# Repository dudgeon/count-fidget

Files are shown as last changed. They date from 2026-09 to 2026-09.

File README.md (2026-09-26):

# Count Fidget

A lightweight, rechargeable two-key fidget that counts clicks, resets with a second key, and remembers its count while asleep or unpowered. Designed for a home-printed enclosure and professionally assembled electronics.

**Q5 is the active engineering candidate:** the Q4 STM32L072CBT6 / USB-C home programming / SPI OLED / SPI FRAM design, plus:
- a soft power key (COUNT turns it on; it switches itself off after 30 s, drawing ~8 µA);
- a vendor-soldered LIR2032 coin-cell holder in place of a custom battery pack;
- a battery gauge with LO warning and storage cut-off, and charge status;
- a reset pinhole;
- hold-to-reset key logic;
- a smaller 47.2 × 59.2 × 16.8 mm printed enclosure with printed keycaps;
- solder-free keys (clicky switches pressed into vendor-placed hot-swap sockets).

JLC performs all SMT from standard inventory parts. Two JLCPCB variants are prepared:
- **A:** the user solders the display header (14 joints);
- **B:** JLC also fits the display.

Q1–Q4 remain historical, unchanged packages.

**The design is locked. JLCPCB quoting only is authorized** (see [JLC-QUOTE-Q5](procurement/q5/JLC-QUOTE-Q5.md)): no order, payment or manufacture. The design files, firmware, emulation and CAD checks pass. Nothing has been built or measured. The first units follow the [first-article test plan](docs/q5-first-article-test-plan.md).

Start with [the Q5 engineering review](docs/REVIEW-Q5-2026-09-25.md), [PROJECT.md](PROJECT.md) for status, and [HANDOFF.md](HANDOFF.md) for continuation.

| Area | Current Q5 files |
|---|---|
| PCB | [KiCad project](electronics/q5/click-counter-Q5.kicad_pro), [board](electronics/q5/click-counter-Q5.kicad_pcb), [schematic PDF](electronics/q5/schematic-Q5.pdf), [power design](docs/q5-power-design.md) |
| Firmware and programming | [Q5 source/build](firmware/q5-stm32/README.md), [keys, power and USB procedure](docs/q5-firmware.md), [macOS flashing tool](tools/clicker-flash/README.md) (Claude skill `flash-clickers`) |
| Inventory, assembly and quote | [Stock evidence](procurement/q5/stock.json), [exports](procurement/q5/REVIEW-EXPORTS-Q5.md), [JLCPCB quote and estimate](procurement/q5/JLC-QUOTE-Q5.md) |
| Enclosure | [Assembly and parts](mechanical/q5/README.md), [rendering](mechanical/q5/assembled-Q5.png), [STEP assembly](mechanical/q5/enclosure-Q5.step) |
| Verification | [Build workflow](docs/build-and-verify.md), Q5 reports in `verification/`, [firmware emulation](simulation/q5-firmware-emulation/README.md), [bounded power checks](simulation/q5-power/result.json) |
| Product history | [Specification](docs/product-spec.md), [user context](docs/user-research.md), [decisions](docs/decisions.md), [Q4 review](docs/REVIEW-Q4-2026-09-24.md), [Q4 simulation review](docs/REVIEW-Q4-simulation-2026-09-25.md) |
| Vendor history | [Vendor status](procurement/vendor-status.md); retained RFQ packages in `dist/` do not authorize new submissions |

Quick checks, with Python 3 and a C compiler:

```sh
python3 scripts/verify_project.py
python3 scripts/run_host_tests.py
```

These verify files, package consistency and portable firmware logic, not physical electronics. Toolchains, credentials, private mailbox content and customer account sessions are not stored in this public repository.

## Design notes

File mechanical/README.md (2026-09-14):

# Rev0 fit study — not final Q1 print files

**These STEP/STLs do not match Q1.** Preserve them as editable CAD and form-factor work, not a finished electronics assembly. Purchased parts in renders are simplified envelopes; pins/wiring/small parts are missing.

`enclosure.py` generates the STEP, base/lid STLs, CAD renders and geometry report using CadQuery. Recorded checks show one solid per shell part, zero base/lid intersection and solid-PLA masses 7.221 g + 2.680 g. They do not establish component clearance.

## Q1 revision requirements

- Use actual 42 × 40 × 1.0 mm board with 2 mm outline corner radii. Two rear M2 holes are **(2.5, 37.5), (39.5, 37.5) mm**; old model assumes four corner holes/supports.
- J1 opens right at **y=13.3 mm**. Use exact GCT drawing, stakes and real USB cable clearance.
- Switch stem centers: **(11.475, 28.000), (30.525, 28.000) mm**. Footprint placement origin is contact pin 1, not stem. Check clips, travel, plate height and click-load support.
- LCD center: **(21, 8.75) mm**; glass rear 4 mm above PCB top. Model actual glass/pins/standoff, compliant support, MCU/connectors beneath and viewing angle.
- Include bottom components, solder, ≤1 mm LCD lead tails, battery tab/NTC exit, 40 ±5 mm flexible leads, pack diameter ≤21 mm excluding lead exit and ≤0.8 mm added face thickness.
- Keep cell behind screws with strain relief and clearance from conductors. Final screws/retention/drop behavior need validation.

All quoted coordinates are board top view, top-left origin, Y down. Use Q1 files for truth. Render final visuals from corrected CAD after reviewing geometry.

Old body: 46 × 44 mm, 1.2 mm wall/floor, 18 mm with bezel, 28.8 mm keycap height. Old base prints flat; lid puts bezel on bed and needs support under surrounding face. Notes considered two 0.6 mm extrusion lines and transparent PETG, subject to slicer/fit/thermal checks.

CAD dependencies: CadQuery, NumPy, Pillow. Historical renderer uses Linux DejaVu font paths; select available local fonts on macOS. Run changes in a branch; all geometry is mm. Final print files remain owed.

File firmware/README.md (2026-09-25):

# Firmware: frozen Q1 and Q2 LCD verification candidate

`main_msp430.c` now contains the **unreleased Q2 LCD verification candidate** for MSP430FR4133IG48R, 48-pin package. The existing Q1 ELF/HEX/map, `SHA256.json`, factory HEX and submitted RFQ ZIP remain unchanged. The ZIP retains its matching Q1 source. All boards remain on hardware hold: Q1 lacks three required LCD bias reservoir capacitors.

The allegation that Q1 source omitted segment enable is **refuted**. TI support 1.212 defines `LCD4MUX` to include `LCDSON`. Rebuilding the original source with TI GCC 9.3.1.11 produces the exact archived Q1 application HEX; no loaded-byte source/binary drift was found. Complete ELF metadata differs across builds. See `../docs/review-lcd-firmware-Q2.md` for evidence and the inferred build recipe.

Q2 changes the divider from 4 to 8 for **32 Hz nominal**, giving margin for REFO tolerance. Explicit `LCDSON` is added for readability and makes no additional binary change. Outputs and source/header/toolchain provenance are separate in `q2-lcd-check/`; build them with `../scripts/build_firmware.py` as described in `../docs/build-and-verify.md`. This image has not been flashed or qualified and is not authorized for manufacture.

Behavior: 8 ms stable-state debounce; one count per press; single-press reset with priority; eight digits with saturation at 99,999,999; first wake click counts; display blanks after 30 seconds; LPM4 wake on either edge; 16-bit aligned, CRC-protected dual-record journal at information FRAM 0x1800–0x181F. An interrupted newest commit can lose that newest click; the previous committed record remains the recovery target. Display updates follow successful commits.

LCD commons use L0–3; segment lines use L8–19 and L24–27. Mode 2 uses the 3.0 V rail, 1/3 bias and 1/4 mux: Q1 is nominally 64 Hz, Q2 is 32 Hz. The pump capacitor and three R13/R23/R33 reservoir capacitors are required; firmware cannot replace missing hardware. All common and segment pins are held at the same GPIO low level during sleep. REFO clocks the debounce timer and LCD; no crystal is fitted. The watchdog is disabled and additional firmware robustness review remains a production gate.

factory-display-info.hex is a factory-only information-FRAM record that starts at 88,888,888 for display inspection. Load it once during factory test, then reset to zero and execute the RFQ tests. Do not use it for field firmware updates: application-only HEX intentionally preserves the saved count.

No target hardware validation has occurred. Host tests validate counter behavior and interruption boundaries between complete journal words, not analog brownout behavior, MCU pin multiplexing or LCD contrast. Programming and test procedure: procurement/RFQ-Q1.md. USB is charging only; use MSP-FET Spy-Bi-Wire and the ten labeled pogo lands.

Compiler: https://www.ti.com/tool/download/MSP430-GCC-OPENSOURCE

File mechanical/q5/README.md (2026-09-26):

# Q5 enclosure and home completion

The Q5 body is **47.2 × 59.2 mm with a 16.8 mm display-cover height** and a 26.7 mm keycap envelope height. Q4 was 50 × 60 × 19.6 mm with a 30.4 mm keycap envelope. It fits the unchanged 42 × 54 mm board outline, now 1.6 mm thick for the hot-swap sockets. The STEP assembly and PNGs use the native Q5 board positions and simplified component envelopes. They are not exact vendor assembly CAD.

Changes from Q4 and why:

| Change | Reason |
|---|---|
| **USB opening 13.4 × 7.2 mm**, centred on the receptacle axis and cut through to the receptacle face | Issue #4. The Q4 opening was 4.8 mm tall and 3.4 mm in front of the receptacle, so standard overmolded plugs could not seat. The fit check reserves a USB-IF maximum 12.35 × 6.5 mm overmold plus 0.1 mm per side, from the outer wall to the receptacle face. |
| **No pack bay, keeper or harness corridor** | Issue #13. The LIR2032 cell sits in the vendor-soldered BT1 holder under the PCB, and the NTC is on the board. The Q4 battery keeper and its two M2 × 5 screws are gone. |
| **PCB 3.4 mm lower, side clearance 1.0 mm** | The holder (5.52 mm) plus 0.58 mm floor gap sets the stack height. This saves 2.8 mm in width, 0.8 mm in depth and 3.4 mm in height. |
| **Printed MX keycaps** with a cross socket and engraved legends (+ on COUNT, ○ on RESET) | Issue #13. Keycaps are no longer an unsourced item. |
| **Solder-free keys:** vendor-placed CPG151101S11-16 hot-swap sockets (SW1 rotated 90°, SW2 270°, pads outward) | The clicky CPG151101D13 switches clip into the rear key plate and press into the sockets, so no key soldering is needed and variant B needs no home soldering at all. Keycaps are datumed on the switch stem (15.0 mm above the PCB, 3.5 mm socket, 4.4 mm travel checked). |
| **Pinhole tube** and a debossed "LIR2032 ONLY" warning in the base | Guides a paper clip to SW3 and warns against primary cells. |
| **Bottom reset pinhole** (2.4 mm) under SW3 | Provides the hardware reset (NRST) the user asked for. On battery it is a full power cycle; with USB it is the DFU entry reset. |
| **Two load supports** under the key area (board 5.5, 42.8 and 34.0, 44.0) | Carry key-press force past the holder into the floor. |

## Parts and hardware

| Item | Qty | Specification / status |
|---|---:|---|
| Base, front display cover, rear key plate, COUNT keycap, RESET keycap | 1 each | Five STL files, already in print orientation |
| Board/cover screws | 4 | M2 × 6 cross pan-head self-tapping (LCSC C357360). They pass through the lid-boss floor and PCB into 1.7 mm base pilots, 4.2 mm deep, with 3.4 mm thread engagement |
| Rear display supports | 2 | Compliant 2.5 mm annuli, as in Q4 |
| OLED module and header | 1 + 1 | HS96L01W4S03 + PZ254V-11-07P. Variant A: the user solders them (14 joints). Variant B: JLC fits them |
| Key switches | 2 | CPG151101D13 clicky (LCSC C49234235), pressed into the hot-swap sockets; no soldering |
| Cell | 1 | **User-supplied LIR2032 (rechargeable Li-ion, 4.2 V) only.** Never fit a CR2032 or ML2032 primary cell: the charger would try to charge it. |

## Assembly sequence

1. Print and inspect the five parts. Check the keycap cross sockets on one switch before fitting.
2. Print `tolerance-coupon-Q5.stl` first (`scripts/build_q5_coupon.py`: plate holes 13.95/14.05/14.15 mm, cross sockets −0.05/0/+0.05 mm; first-article test G0). Clip both switches into the **rear key plate**.
3. Variant A only: with the front cover off, solder the seven-pin header between the host PCB and the module (14 joints) and trim the pins to ≤ 1 mm. Variant B arrives with DS1 fitted.
4. Fit the two display supports.
5. **Insert the cell with USB connected** (BQ2970 first-connection behaviour and the retained cold-insertion counterexample; see [the Q5 power design](../../docs/q5-power-design.md)). Observe + up in the holder. The board powers up from USB, shows the count and the CHG label.
6. Lower the PCB assembly vertically into the base. Press the key plate, with its switches, straight down into SW1/SW2 until the housings sit flush, then fit the two rear screws. Program/verify firmware now if needed (see [Q5 firmware](../../docs/q5-firmware.md)).
7. Lower the front cover and fit its two screws. Press on the keycaps. Check travel, the USB plug (both orientations) and the reset pinhole.

To replace the cell, remove the four screws and lift the PCB assembly out. The holder is on the underside.

## What the geometry checks establish

`fit-report.json` and `build-manifest.json` bind the native Q5 board and model, the generator and the firmware pixel renderer. The final build found:
- five valid single solids with manifold STL meshes;
- zero static intersections;
- zero collisions in 162 sampled vertical assembly/removal poses (18,387 tests).

The minimum modelled distances are in the report:
- holder to bottom components: 0.05 mm, a bounding-box gap and not an overlap;
- pressed keycap to plate top: 0.6 mm; pressed keycap roof to switch housing: 0.65 mm;
- pressed keycap to rear screw: 3.0 mm;
- screw thread engagement: 3.4 mm;
- USB mouth to outer wall: 2.0 mm.

Not established: print tolerances, thread strength, cell retention and insertion force, keycap fit/travel, real USB plug fit, drops, or display support material. Inspect a physical first article.

Build: `python3 -B scripts/build_q5_enclosure.py --kicad-python "$(which python3)"` (CadQuery 2.8, NumPy, Pillow, KiCad Python bindings).

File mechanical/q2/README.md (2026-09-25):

# Q2 enclosure fit candidate

These are real, editable/exported Q2 CAD files for a **50 × 45 × 19.8 mm** enclosure around the current 42 × 40 × 1 mm PCB. Estimated overall height with the provisional keycaps is 29.8 mm. They replace the obsolete fit assumptions for this candidate only; all files in the parent `mechanical/` directory remain historical Rev0 evidence.

**Engineering fit candidate, not released print files.** The shell/keeper are generated solids. Purchased components, pins, screws and keycaps are simplified envelopes. No printed sample, finished battery pack, actual keycap or cable has been fitted. The current electronics retain their documented qualification gates.

## Files

| File | Contents |
|---|---|
| `enclosure-Q2.step` | Assembled base, lid, keeper and named component envelopes, in assembly coordinates |
| `base-Q2.stl` | Printable base, upright with floor at Z=0 |
| `lid-Q2.stl` | Lid inverted, bezel face at Z=0; supports needed under the surrounding face |
| `battery-keeper-Q2.stl` | Separate screw-retained keeper, flat at Z=0 |
| `assembled-Q2.png`, `exploded-Q2.png` | Rendered CAD views |
| `interior-Q2.png`, `battery-bay-Q2.png` | Internal layout and battery access views |
| `board-geometry.json` | Native KiCad footprint bounding boxes, pads/drills and board/model hashes used for this build |
| `fit-report.json` | Solid validity, intersection checks, model distances and explicit limitations |
| `build-manifest.json` | Generator, board/model and generated-output SHA-256 identities |

No enclosure printing charge is included in the vendor electronics quote: Geoff prints and fits the case. The STEP/STLs support quotation review and the later physical fit prototype; they do not authorize manufacture of the electronics.

## Geometry and design choices

Coordinates in the source are millimetres, with `CAD X = board X −21`, `CAD Y = board Y −20`; Y follows the board's top-view convention. Z starts at the base bottom. The script reads the native Q2 board without modifying it, compares all placed parts with `electronics/q2/netlist-Q2.json`, and rejects changed dimensions or component anchors.

| Feature | Candidate geometry |
|---|---|
| PCB | Bottom Z=10.5; top Z=11.5; nominal 2 mm outline corner radius |
| Base | 1.6 mm floor/walls; nominal board-side clearance 2.4 mm along X and 0.9 mm along Y |
| Mounts | Existing board holes at (2.5,37.5), (39.5,37.5); two base bosses and corresponding lid spacers/screws |
| Switches | Stem centers (11.475,28), (30.525,28); 16.4 mm square lid clearances; PCB-load support posts at (6,30.5), (36,30.5) |
| LCD | Center (21,8.75); rear glass 4.0 mm above PCB top; nominal 34.9 ×13 ×2.2 mm; 13.0 mm lead rows |
| LCD pocket | 36.2 ×14.8 mm; roof above pocket at Z=18.8; viewing aperture 32.7 ×7.2 mm; raised bezel top Z=19.8 |
| USB | Right-side opening centered at board Y=13.3, 13.2 mm wide ×5.0 mm high, bottom Z=11.1 |
| Pack | Finished insulated cylindrical body up to Ø21 ×4.2 mm; bottom Z=1.9 on a 0.3 mm seating layer; tray bore Ø21.8 mm |
| Keeper | Plate underside Z=6.4, 0.3 mm nominal above maximum pack; independent screws retain it before the PCB is fitted |
| Harness | 2.0 mm-wide side corridor around the left PCB edge, plus under-board and flexible tab/NTC exit reservations |

The width and PCB height increases provide a route around the intact PCB edge for the four-wire harness and room for the keeper below the switch tails. They are explicit enclosure choices, not changes to the electrical layout. The specified 40 ±5 mm, 30 AWG pack leads still require a finished-pack drawing and a trial route; the reservation boxes are not a qualified cable model. The mating JST plug and its insertion/bend sweep remain to be confirmed.

The LCD's manufacturer drawing includes a **2.85 mm maximum thickness** and ±0.2 mm body-length/general tolerances. The clearance check therefore uses 35.1 ×13.2 ×2.85 mm, not just the 2.2 mm nominal render. At the specified 4 mm standoff this leaves 0.45 mm nominal below the pocket roof. The enlarged pocket also allows space around the bent lead rows. It does not resolve hole/lead tolerances, solder exposure or LCD qualification. [Display Elektronik DE188 Rev4 drawing](https://display-elektronik.de/filter/DE188-RU-30_75_3V.pdf).

Two **nonconductive compliant pads**, nominal 4 mm assembled thickness, support the glass rear near board coordinates (5.5,8.5) and (36.5,5). Their material, final compressed thickness, adhesive and contact pressure require approval with the actual LCD. They are separate envelope parts in STEP; do not replace them with an unqualified hard clamp. The lid intentionally clears the glass.

The USB body envelope uses 7.35 ×8.94 ×3.31 mm and the native right-facing anchor. A 12 ×4.6 mm cable-entry reservation passes through the wall opening. This is an explicit candidate plug limit, not a claim that every USB-C cable overmold fits the recessed receptacle. [GCT USB4105 dimensions](https://gct.co/connector/usb4105).

The switch envelope distinguishes a 14 mm lower region through the first 5 mm above the board from the 15.6 mm upper envelope. Keycap bodies are provisional 18.2 mm square envelopes with a checked 4 mm downward travel. Actual clips, stem fit, keycap skirt, bottom-out height and board loading still need a sample. The lid clearance is not a qualified MX mounting plate. [Cherry MX series drawing](https://media.digikey.com/PDF/Data%20Sheets/Cherry%20PDFs/MX%20Series.pdf).

## Retention and assembly sequence

The following is a prototype assembly procedure for unpowered parts. It does not approve installing or charging an unqualified cell.

1. Print and deburr all three parts. Inspect the pilot/clearance holes and remove support material completely. Check the base/lid fit with an empty board before installing the battery assembly.
2. Fit the insulated approved pack on its 0.3 mm seating layer. Orient the flexible tab/NTC exit toward the left-front tray notch. Fit the keeper with **two M2 ×5 screws**. It limits upward travel while leaving 0.3 mm nominal pack clearance; do not tighten a changed geometry onto the cell or its sensor.
3. Route the insulated leads through the left-side corridor, protecting them from PCB edges and keeper screws. Complete connector engagement and strain relief using the approved pack drawing. The current reservation requires a routed bundle no thicker than 2.0 mm at the side passage.
4. Seat the PCB on its two mounting bosses and two load-support posts, without trapping wiring or touching solder tails. Programming and electrical tests occur before final enclosure closure; the keeper can obstruct access to underside fixture lands.
5. Confirm the installed LCD standoff and compliant supports. With keycaps removed, engage the two front lid hooks, lower the lid and fit **two M2 ×12 rear screws** through the real board holes into the base bosses. Fit the keycaps afterward and check their full travel.

Fastener models assume **head diameter ≤4.0 mm and head height ≤1.7 mm**. Rear screw heads seat at Z=16.5; nominal tips end at Z=4.5. Keeper screw heads seat at Z=7.6; nominal tips end at Z=2.6. These limits avoid the model's cell and base floor. Obtain actual screws meeting this envelope; a longer screw is not automatically acceptable.

Base pilot holes are provisionally Ø1.7 mm and lid/keeper clearance holes Ø2.4 mm. Qualify thread formation, material strength and torque on a spare printed boss before assembly; the pilot dimension is not a validated universal thread specification. The rear lid spacers are Ø3.6/2.4 mm and need careful print inspection. Front hooks provide nominal 0.3 mm engagement clearance. Screw and hook durability, pack capture and board bending remain physical tests.

## What was checked

`fit-report.json` records checks on the actual generated solids:

- Each printed part is one valid solid; base, lid and keeper have zero mutual overlap.
- Printed parts do not intersect the checked PCB/component envelopes or the specified wire/USB reservation volumes.
- The pack/keeper and fastener envelopes do not intersect the modeled bottom components or switch/LCD tails.
- Quantified nominal distances include pack-to-board, pack-to-switch-tails, keeper screws to bottom components, and maximum LCD glass to MCU/USB/JST.

Bottom-component X/Y envelopes come from native KiCad footprint bounding boxes, including courtyard/pad graphics. Height allowances are 1.1 mm for resistors/0603 parts and 1.6 mm for other bottom parts, including mounting/solder allowance; they are conservative family assumptions, not independently approved maximum drawings for every line item. Pin/post solids primarily preserve position and protrusion assumptions, and do not qualify the actual molded-post/hole diameters. The entire solder fillet and flexible-harness geometry is not modeled.

The intersection list is intentionally narrow and reproducible. It does not represent complete component-to-component mechanical DRC, toleranced motion simulation, strength analysis, electrical insulation approval or a physical fit test. In particular, nominal zero overlap does not establish tolerance clearance.

## Printing and remaining gates

For a first fit prototype, use a dimensionally calibrated printer and inspect walls/bosses before use. The base prints upright; the keeper prints flat; the lid's exported STL rests on its bezel face and needs support under the surrounding lid face, with the underside spacers/hooks facing upward. The nominal wall is 1.6 mm. Material, layer settings, shrink compensation and thread method remain to be qualified; these files do not prescribe an untested heat-resistant or child-ready assembly.

Before final print release, measure: finished pack and wire bends; USB plug reach and strain; real switch/keycap travel; mounting and click-load deflection; LCD glass/lead/support fit; all screw clearances/engagement; and retention after handling/drop tests. Keep the existing battery, charger, thermal, protection, programming and display electrical release gates. No purchasing or electronics manufacturing release follows from these CAD outputs.

## Rebuild and provenance

Run from the repository with a Python environment containing CadQuery 2.8.0, NumPy and Pillow. Pass the installed KiCad Python interpreter explicitly:

```sh
python scripts/build_q2_enclosure.py --kicad-python /path/to/KiCad/Python.framework/Versions/3.9/bin/python3
```

The local build used the temporary `/private/tmp/count-fidget-cadquery` environment and the mounted KiCad 10.0.6 runtime. No global Python environment, Rev0 file or electronics source is modified. Input changes during generation cause failure; rebuild after the final native board/model are stable. The manifest identifies geometry inputs and outputs; STEP headers may contain export timestamps, so byte-identical STEP reproduction is not claimed across runs or runtime versions.

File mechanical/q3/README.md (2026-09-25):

# Q3 enclosure engineering candidate

Four print parts: base-Q3.stl, lid-front-Q3.stl, lid-rear-Q3.stl and battery-keeper-Q3.stl. The STEP assembly and renderings are assembled views; the STLs use proposed print orientations. No enclosure has been printed or physically qualified.

## Customer assembly sequence

1. Inspect the completed vendor PCBA, with OLED and both switches already soldered. Leave the battery disconnected and the keycaps off.
2. Slide the front cover toward the lower switch bodies from the display end, then slide the rear cover from the opposite end. Engage the three cover-joint tongues; do not push a cover over the upper switch housings. Printed tolerances and clip engagement need a sample check.
3. Install the insulated, finished battery pack in the base and fit its keeper with two proposed M2×5 screws. Do not trap or puncture the pack or leads. The harness path and actual screw heads require a fit check.
4. Mate the keyed battery connector and lower the PCBA/cover assembly onto the base supports. Engage the front retention features, route the harness in its reserved corridor and fit the two proposed M2×12 rear screws. Do not tighten against the OLED glass or crush the board/pack.
5. Install the loose keycaps. Verify both keys return freely through full travel and the USB cable fits without loading the display or switches.

## Dimensions and evidence

Body50×45mm; switch plate top17.1mm; provisional keycap envelope30.4mm. PCB42×40×1mm, bottomZ11.1mm. Plate1.5mm thick with14.05mm openings and top5mm above the PCB. OLED roof15.6mm and proposed support0.2mm.

The build manifest binds the native board/model, generator and exact current STEP/STL/render outputs. The fit report requires four valid single solids, manifold STLs and zero reported modeled intersections. Independent review found and corrected initial shell collisions, the one-piece cover assembly trap and inadequate battery-keeper screw clearance. The reviewed split-cover approach was sampled at0.25mm increments without collisions; this is not a real assembly or tolerance test.

Simplified body/screw/keycap envelopes are not vendor 3D models. OLED FPC solder-face height/bend/support, clip/lap strength, print tolerances, actual keycaps, harness/JST insertion, fasteners, USB overmold/strain, battery retention, drop behavior and mass remain open. Preserve all engineering gates in the RFQ. Customer enclosure assembly requires no soldering.

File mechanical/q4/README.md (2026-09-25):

# Q4 enclosure and home completion

The enclosure is a **50 × 60 mm** body with a **19.6 mm display-cover height** and a provisional **30.4 mm keycap envelope height**. It fits the separate 42 × 54 × 1 mm Q4 PCB. The STEP assembly and PNGs use the actual board positions and simplified component envelopes; they are not exact vendor assembly CAD.

## Parts and hardware

| Item | Quantity | Specification / status |
|---|---:|---|
| Printed base, front display cover, rear key plate, battery keeper | 1 each | Four supplied STL files; print orientation is already applied |
| Board/cover screws | 4 | M2 × 12, nominal 4 mm head diameter / 1.7 mm height envelope |
| Battery-keeper screws | 2 | M2 × 5, same head envelope |
| Rear display supports | 2 | Compliant 2.5 mm-high annuli, 3.8 mm outside / 2.5 mm inside diameter; sample-fit material and component-free contact lands before use |
| OLED module | 1 | HS96L01W4S03 / C5139758, separately sourced loose |
| Header | 1 | PZ254V-11-07P / C492406; 2.5 mm body separates host and module PCBs |
| Key switches | 2 | CPG151101D13 / C49234235, separately sourced loose |
| Keycaps | 2 | Provisional MX-compatible 18.2 mm square envelopes; exact sourcing and travel fit unqualified |
| Prepared cell and NTC harness | 1 | Unqualified four-wire pack, maximum modeled 21 mm diameter × 4.2 mm height; see power/pack release gates |

The printed screw pilots are 1.7 mm. Thread formation, fastener head fit and repeated service strength must be established on a print sample; the model does not establish a reliable printed thread. Supports, screws and the prepared pack are separate from the PCB assembly BOM. Do not infer that JLC includes them or that public stock has been allocated.

## Assembly sequence

1. Print and inspect the four parts. Fit the keeper and screws around an inert pack-sized gauge first. Confirm screw engagement without protruding into the cell space. Qualify the actual pack and sensor before connecting it.
2. Seat both key switches in the **rear key plate before soldering** their four electrical leads to the host PCB. The plate is intentionally captured by the fitted switches. Check full switch travel and plate clips on the print sample.
3. With the front cover removed, solder the seven-pin header between the host PCB and display module. This is fourteen solder joints. Keep the 2.5 mm header body between the PCBs; trim exposed pin ends to **at most 1 mm** on both sides. Check all joints and orientation before power.
4. Fit the two compliant supports under the module's rear mounting lands after confirming those lands are free of components. Do not press on the glass or force the module into a warped position. The manufacturer's drawing, not its contradictory summary dimensions, controls the CAD.
5. Lower the PCB/key-plate assembly vertically into the base, route the qualified harness through the reserved side corridor, and secure the rear mounts. Leave the front cover off for inspection and USB programming. Use the **USB-first commissioning sequence** in the power document; cold battery insertion is not a validated workflow.
6. Lower the front display cover vertically and fit its two screws. Fit the keycaps and check full travel, USB cable access, the bottom reset pinhole and display visibility.

Home soldering totals **18 joints per device**. The two SMT-side USB shell joints are part of factory assembly; their stake projection and wetting still need first-article inspection.

## What the geometry checks establish

`fit-report.json` and `build-manifest.json` bind the actual native PCB/model, generator and firmware pixel renderer to the outputs. Checks require four valid single solids, manifold STL edges, bed-aligned print orientation, zero modeled static intersections and zero intersections in sampled straight vertical insertion/removal paths. The displayed sample count is generated by the actual production OLED pixel routine.

These checks do not establish print tolerances, screw/thread strength, display support material, solder quality, cable strain, battery retention, drops, keycap fit or wiring flexibility. The actual mating battery plug and flexible harness are represented by reserved corridors; their full insertion/bend behavior is not simulated. Component heights are conservative family envelopes. Inspect a physical first article before approving a production order.

Build with CadQuery 2.8, NumPy, Pillow and the KiCad Python bindings through `scripts/build_q4_enclosure.py`. A failed build removes its success manifest. Snapshot arguments are for private experiments; final review artifacts must use the repository's actual final routed board/model.

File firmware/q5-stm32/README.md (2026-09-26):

# Q5 STM32 target

Separate STM32L072CBT6 firmware for the Q5 hardware candidate. It adds the COUNT-key soft power latch (PB2), the SYS_LOAD/2 battery gauge (PA4), charger status (PA5/PA6), hold-to-reset keys, option-byte self-provisioning and the boot, latency and display-power fixes described in [the Q5 firmware guide](../../docs/q5-firmware.md). It targets the FM25V02A-GTR FRAM and HS96L01W4S03 SPI OLED module like Q4, and reads Q4 journals unchanged. Q4 files are unchanged.

Build using the pinned Arm GNU 14.3.Rel1 compiler:

```sh
python3 -B scripts/build_firmware_q5.py --toolchain /path/to/arm-gnu-toolchain-14.3.rel1-<host>-arm-none-eabi
python3 -B scripts/build_firmware_q5.py --verify-only
python3 -B scripts/test_firmware_q5.py
python3 -B scripts/test_firmware_q5.py --sanitize   # add --cc gcc where clang lacks the UBSan runtime
python3 -B scripts/test_firmware_q5.py --image-only
```

`source-records.json` pins the upstream ST and Arm header sources and licenses. The build manifest binds sources, compiler binaries, included headers, libgcc, commands and every output. ELF, HEX and BIN are equivalent program images restricted to Flash Bank1. None of them initialises internal EEPROM, option bytes or external FRAM. The application may program the option-byte USER half-word once at run time (BOR_LEV only; never RDP); see the guide.

The first use of new or unrecognised FRAM shows `0 ERR`; hold RESET COUNT for 2 s and release it to establish a verified zero. A queue overflow or storage failure shows ERR and freezes increments until such a reset has been committed and read back. Option bytes the firmware cannot safely provision show OPT with the digits hidden, and the FRAM is never accessed.

These binaries have not executed on a physical MCU. Host tests, instruction-level emulation and ELF inspection are not hardware qualification or manufacturing release.

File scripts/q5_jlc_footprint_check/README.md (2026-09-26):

# Q5 footprint check against JLC's own (EasyEDA/LCSC) footprints

This check was added on 26 Sep 2026 to de-risk the first order. It works in four steps:
1. It fits each vendor-assembled KiCad footprint against the footprint JLC uses for that LCSC part. The fit is by pad number, over rotations 0/90/180/270, with and without a mirror.
2. It checks pin 1 and polarity through the LCSC pin names.
3. It predicts the rotation and offset corrections JLC's placement preview will need for our raw KiCad CPL.

The last run matched all 42 unique parts, with no pad-order or mirror error. The full report is `REPORT.md`.

The bottom-side convention used, rotation = 180 − KiCad θ with a mirrored X, is **community-documented, not JLC-documented**: KiKit, the Bouni kicad-jlcpcb-tools plugin and KiBot use it. Always confirm BT1 +, D4's cathode and U3's pin 1 in JLC's preview before accepting.

Run from this directory, with KiCad's Python for `kicad_dump.py`:

```sh
python3 fetch_easyeda.py      # downloads ./easyeda/ (gitignored)
python3 kicad_dump.py kicad.json   # our pads -> kicad.json, kicad_lib.json
python3 analyze.py            # fit -> results.json/csv
python3 corrections.py        # predicted JLC preview corrections -> corrections.json/csv
```

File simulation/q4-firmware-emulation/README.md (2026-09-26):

# Q4 firmware emulation (instruction-level)

Runs the **actual Q4 firmware image** (`firmware/q4-stm32/build/count-fidget-Q4-stm32.elf`) on an emulated Cortex-M0+ with models of the board it drives. It exists to catch behaviour that the portable host tests cannot see: vector/startup/linker effects, pin and peripheral configuration, SPI framing to the real device protocols, interrupt timing against the foreground loop, Stop entry/exit and multi-second product scenarios.

**This is a model, not hardware.** Results are "reproduced in emulation". They do not replace the physical gates in `docs/REVIEW-Q4-2026-09-24.md`.

## What is modelled

| Block | Model |
|---|---|
| CPU | Unicorn 2 (QEMU Thumb, Cortex-M0 model). Exceptions, NVIC priority/pending/masking, PRIMASK, WFI and SLEEPDEEP are handled by the harness. Instruction time uses Cortex-M0+ TRM cycle costs per executed instruction plus a flash wait-state penalty (`flash_ws_penalty`, default +0.5 cycle per flash-resident instruction for `LATENCY=1` without prefetch; `0.0` gives the optimistic zero-wait bound). |
| MCU peripherals | RCC (clock enables, peripheral resets, HSI/SWS), PWR (PVD level vs. modelled VLOGIC, Stop/Standby selection), FLASH (`ACR`, `RUN_PD` with the RM0376 §3.6.4 `PDKEYR` lock, `OPTR`), GPIO A/B/C (modes, open-drain, AF numbers, BSRR/BRR, IDR from board nets), EXTI lines 0/1, SYSCFG EXTICR, SysTick, SCB (ICSR, SCR, AIRCR), SPI1/SPI2 (TXE/RXNE/BSY/OVR, BIDIMODE, prescaler timing), ADC (ADVREGEN, ADCAL, ADEN/ADRDY, conversion time from SMPR, VREFINT from `VREFINT_CAL`). |
| Board | SW1/SW2 with configurable bounce; NRST pulse or hold; BOOT0 sampling on reset release (enters "ROM bootloader" and stops); VLOGIC value; FRAM and OLED nets exactly as in `electronics/q4/netlist-Q4.json` (pull-ups/downs R17, R18, R24, R25, R29, R33). |
| FM25V02A | Opcodes WREN/WRDI/RDSR/WRSR/READ/FSTRD/WRITE/SLEEP/RDID, 2-byte addressing, WEL, device ID `7F×6 C2 22 08`, sleep with wake on CS fall and `tREC` 400 µs, `tPU` check. |
| HS96L01W4S03 / SSD1315 | TPS22917 switch (typical tON 84 ms at 22 nF CT), RES#, D/C, command decoder with parameters, page-mode GDDRAM, charge pump/display state, power-off order check (AEh, 8Dh 10h, ≥100 ms before supply removal), back-power check on the five signal lines, pixel decode of the rendered digits and ERR/MAX label. |

Not modelled: analog rails and droop, currents (the energy model multiplies emulated state durations by datasheet currents), charger/protector state machines, oscillator tolerance, silicon errata beyond the Stop sequence check, USB.

## Running

Requires Python 3.10+ with `unicorn==2.1.4`, `capstone==5.0.7` and `pyelftools`.

```sh
python3 simulation/q4-firmware-emulation/scenarios.py --output simulation/q4-firmware-emulation/results/committed-firmware-scenarios.json
python3 simulation/q4-firmware-emulation/scenarios.py --elf /path/to/new/count-fidget-Q4-stm32.elf --check
python3 simulation/q4-firmware-emulation/energy.py --output simulation/q4-firmware-emulation/results/energy-model.json
python3 simulation/q4-firmware-emulation/q4emu.py firmware/q4-stm32/build/count-fidget-Q4-stm32.elf --seconds 1.5
```

`--check` asserts the documented product behaviour (first-use ERR, counting, sleep/wake, NRST restore, fast presses, low rail, held key, key priority, no input-queue overflow at boot). Scenarios marked informational (DFU-entry variants, unprovisioned option bytes) are reported but do not fail the run. A full suite takes about 2–3 minutes.

## Results for the committed image (SHA-256 `9a982e43…`)

`results/committed-firmware-scenarios.json` — 9 expectation failures, all caused by one defect: the boot-time FRAM journal scan keeps the foreground loop from draining the 255-sample button queue for 245–409 ms, so the queue overflows and the application latches ERR and persists `fault=1` after a reset. A candidate patch (capture enabled only after `oled_init()`) passes every expectation. The report is `docs/REVIEW-Q4-simulation-2026-09-25.md`.

`results/energy-model.json` — per-session charge from emulated state timelines and the daily-use battery model.

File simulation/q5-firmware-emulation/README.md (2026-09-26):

# Q5 firmware emulation (instruction-level)

Runs the **actual Q5 firmware image** (`firmware/q5-stm32/build/count-fidget-Q5-stm32.elf`) on an emulated Cortex-M0+ with models of the Q5 board. `q5emu.py` is derived from the [Q4 emulator](../q4-firmware-emulation/README.md) and adds the board changes below. **This is a model, not hardware**: results are "reproduced in emulation" and do not replace the physical gates in `docs/REVIEW-Q5-2026-09-25.md`.

## Added to the Q4 model

| Block | Model |
|---|---|
| U7 soft power latch | U7 ON = USB (D4) OR COUNT key (D3 A1) OR PB2 driven high (D3 A2). From off, a COUNT press or USB starts the board after tON 17.9 ms (4.7 nF CT) plus 2 ms. A release with no source collapses the supply after 5 ms while running, or 80 ms in Stop. A source returning before that cancels the collapse. Power loss clears SRAM, resets the OLED and wakes FRAM from sleep. A violation is recorded if the display or pump is on, or an FRAM transaction is open, at collapse. |
| USB and charger | USB presence sets SYS to 4.5 V (BQ25185 VSYS_REG). STAT1/STAT2 are open-drain outputs for charging/done/fault (Table 6-2). A read without pull-up is noted. |
| Battery divider | ADC_IN4 = SYS/2 against the modelled VLOGIC, with ±1.5 LSB noise. A violation is recorded if PA4 is not analog. |
| RCC reset flags | POR+PIN on power-up, PIN on NRST, SFTRST, OBLRST; RMVF clears them. |
| FLASH option bytes | PECR locks, PEKEYR/OPTKEYR sequences, the USER word at 0x1FF80004 with its complement check, BSY for 3.2 ms, and OBL_LAUNCH reload and reset. |
| OLED switch | tON 17.9 ms (C28 4.7 nF). QOD is unconnected: supply released by an MCU reset while RES# is low is noted, not flagged as a sequencing violation. |
| Timing | Default flash wait-state penalty 0 (Q5 sets LATENCY = 0); pass 0.5 for the pessimistic Q4 assumption. |

Not modelled:
- analog rail droop and the real U7/LDO/FRAM ramps;
- contact bounce on the ON node;
- currents (the energy model multiplies emulated state durations by datasheet currents);
- charger or protector state machines;
- oscillator tolerance;
- USB enumeration.

## Running

Requires Python 3.10+ with `unicorn==2.1.4`, `capstone==5.0.7` and `pyelftools`.

```sh
python3 simulation/q5-firmware-emulation/scenarios.py --check --output simulation/q5-firmware-emulation/results/scenarios.json
python3 simulation/q5-firmware-emulation/energy.py --output simulation/q5-firmware-emulation/results/energy-model.json
python3 simulation/q5-firmware-emulation/q5emu.py firmware/q5-stm32/build/count-fidget-Q5-stm32.elf --seconds 1.5
```

`--check` asserts every expectation (a full run takes about six minutes):

- first use shows `0 ERR`; a short reset tap does nothing; a hold-and-release zeroes; the RST prompt appears at 2.0–2.1 s;
- COUNT during a reset hold, and both keys together, increment; an 11 s hold is abandoned;
- press-to-display is under 100 ms;
- on USB: sleep with PB2 released; wake-to-lit under 400 ms; NRST keeps the count without ERR;
- USB removal keeps the latch; the battery timeout powers the board off;
- a wrapped-journal boot drops no samples under both timing models; the power-on press counts once; off-to-lit is under 500 ms;
- a 10 ms tap is too short to power on; a key held 45 s counts once and still powers off; NRST on an off board does nothing;
- three DFU entry orders keep the count; NRST on battery powers off and keeps the count;
- factory option bytes are self-provisioned, then the device counts; an unexpected option set shows OPT with no FRAM access;
- 100 bouncy presses at 12 Hz;
- LO at 3.52 V; cut-off at 3.30 V after LO, with the count saved; USB during the LO notice cancels the cut-off;
- CHG, the full gauge and BAT;
- unplugging USB in Stop powers off;
- a held key on USB counts once.

Every scenario must also record zero contract violations.

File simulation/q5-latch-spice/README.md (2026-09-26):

# Q5 soft-power latch — behavioural ngspice transient

`python3 simulation/q5-latch-spice/latch.py` (ngspice 42) writes `result.json`.

The circuit is the real Q5 latch netlist: cell/protector path, a bouncing SW1 contact, BAT54C D3, C40/R35, and the D4/R38 VBUS path. U7 (TPS22917), the TLV767 and the STM32's reset and PB2 hold are modelled behaviourally. The corners are:
- cell voltage: 3.4, 3.7 and 4.2 V;
- U7 ON threshold: 0.4, 0.7 and 1.0 V;
- slew: ±25 %;
- reset temporisation: 1.0 and 3.3 ms.

Results (see `result.json` for every case):
- **Clean press:** the minimum press that latches ranges from 4.4 ms at the best corner to **20.0 ms at the worst corner**, against a ~50 ms deliberate press.
- **Bouncing contact:** 3–8 make chatters and 2–6 break chatters latched **60/60** at 50 ms and **60/60** at the worst minimum + 5 ms.
- **Very short taps:** 2–15 ms taps either latch or abort. Three aborted after the MCU was briefly powered (a "start abort"). The firmware writes nothing during boot, and the emulator covers this case.
- **USB alone:** 4.40–5.25 V turns the board on at every threshold corner.

Limits: this is a behavioural simulation, not a measurement. TI's TPS22917 model is an encrypted PSpice model that ngspice cannot run, so the switch's timing comes from typical datasheet figures widened by the corners. First-article test B2 measures the real minimum press.

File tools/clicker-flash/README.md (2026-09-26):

# clicker-flash — program Count Fidget Q5 clickers from a Mac

`clicker_flash.py` programs the Q5 firmware over the clicker's own USB-C port. It uses the STM32's built-in ROM bootloader (USB DFU), so there is no programmer hardware, driver, or application bootloader to install. It needs only Python 3 (built into macOS) and `dfu-util`.

> Status: tested against a simulated DfuSe device, and the real `dfu-util` 0.11 accepts its exact arguments. **It has not yet programmed a physical clicker.** The first real flash is part of the first-article test plan.

## One-time setup (macOS)

```sh
xcode-select --install          # if python3 is missing
brew install dfu-util           # https://brew.sh
cd count-fidget                 # this repository
python3 tools/clicker-flash/clicker_flash.py doctor
```

`doctor` checks the dfu-util version (≥ 0.9), verifies the firmware image against `firmware/q5-stm32/build/build-manifest.json`, and lists connected DFU devices.

Use a **USB-C data cable**; charge-only cables never enumerate. Connect directly or through a powered hub.

## Put a clicker into DFU mode

1. Connect the clicker to the Mac by USB. USB powers it; a cell may or may not be fitted.
2. **Hold RESET** (the ○ key).
3. Press and release the **pinhole** in the base with a paper clip.
4. **Release RESET.** The display stays dark, because the ROM bootloader is running.

This never changes the saved count: a count reset needs a 2 s hold *and* a release while the application is running. `dfu-util -l` (or `clicker_flash.py list`) should now show `[0483:df11] … name="@Internal Flash …"`.

## Flash

```sh
python3 tools/clicker-flash/clicker_flash.py flash                   # one unit
python3 tools/clicker-flash/clicker_flash.py flash --batch --check   # production: unit after unit
```

For each unit the tool:
1. writes the image to 0x08000000;
2. reads the same range back and compares every byte;
3. starts the application;
4. appends a line to `~/count-fidget-flash-log.csv`: UTC time, the chip's unique DFU serial, result, image and read-back SHA-256, and dfu-util version.

`--check` then asks four on-device questions and records the answers. These double as the functional commissioning test:

| Step | Expected |
|---|---|
| After flashing | `0` with **ERR** (new FRAM) or the previous count |
| Hold RESET 2 s, release | **RST** appears, then `0` without ERR |
| Press COUNT three times | `3`; battery bars or **CHG** visible |
| Hold RESET 2 s, release | `0` |

In `--batch` mode, unplug the finished unit, connect the next one in DFU mode, and the tool continues. Ctrl-C stops.

## What it refuses to do

- Flash an image whose size or SHA-256 differs from the build manifest, whose vector table is invalid, or that exceeds Flash Bank 1.
- Flash when more than one STM32 DFU device is connected.
- Flash a device without an `@Internal Flash` DfuSe interface at 0x08000000, or whose flash pages are not writable (e.g. read protection).
- Report success unless the read-back matches. After a verified read-back, a dfu-util error on the final *leave* request is logged as a note, because the ROM may drop off USB before answering.

It never writes option bytes, never mass-erases and never touches the external FRAM, so the count survives every update. The firmware provisions its own brown-out option byte on first boot (see `docs/q5-firmware.md`). A flash that the tool reports as **PASS** proves the bytes are in flash. It does not prove the board works: that is what the `--check` questions and the first-article test plan are for.

## Troubleshooting

| Symptom | Cause / fix |
|---|---|
| `No STM32 DFU device found` | Data cable? RESET must be held while the pinhole is released. Try another port/hub. |
| `More than one STM32 DFU device` | Connect one clicker at a time. |
| `VERIFY FAILED` | Re-run `flash` on the same unit. A repeat failure means a hardware fault: set the unit aside. |
| `WARNING: device reports … KiB flash` | Not an STM32L072CB. Check it is a Count Fidget Q5 board. |
| A flash FAILED or you stopped mid-flash | The clicker is still in DFU mode. **Press the pinhole before unplugging it.** A clicker unplugged while in DFU stays powered (its USB pull-up back-feeds the power latch) and drains its cell until the pinhole is pressed. |
| Display blank after PASS | Press the pinhole once (normal restart). If still blank, record it as a commissioning failure. |

## Tests

```sh
python3 tools/clicker-flash/test_clicker_flash.py --output verification/q5-flasher-tests.json
```

The tests run the tool end to end against `mock_dfu_util.py`, which emulates dfu-util 0.11's command line and an STM32 DfuSe device (O_EXCL uploads, `:leave`, page erase). They cover:
- corrupted writes, download and leave errors;
- multiple devices, read-protected and non-ROM layouts;
- tampered or unrecorded images and bad vector tables;
- commissioning logging and batch operation.

If a real `dfu-util` is installed, the tests also confirm it accepts the tool's exact arguments.

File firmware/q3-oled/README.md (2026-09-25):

# Q3 OLED firmware candidate

**For the separate Q3 hardware only. Do not flash onto Q1 or Q2.** Exact intended display: Wisevision **X087-2832TSWIG02-H14**, JLC/LCSC **C18723015**, SSD1312, 128 × 32 pixels. No physical board or display has been tested; this is neither a manufacturing release nor a current/runtime guarantee.

## Hardware contract

| Signal | MSP430FR4133IG48R | Meaning |
|---|---|---|
| Increment / reset button | P1.0 / P1.1 | Existing active-low inputs and external pullups |
| OLED_ENABLE | **P1.2, pin 24** | High enables the regulated **4.0 V** pump supply and its VBAT isolation switch; external pulldown holds it disabled during reset |
| OLED_RESET_N | **P1.3, pin 23** | Low asserts display reset; external pulldown |
| OLED_SDA / OLED_SCL | **P5.2, pin 28 / P5.3, pin 27** | eUSCI_B0 I²C, external pullups to the permanently supplied 3.0 V logic rail |

OLED VDD stays at 3.0 V during sleep. OLED VBAT must float when disconnected; do not add active discharge to that pin. The 4.0 V pump rail replaces the initially considered 3.7 V: the controller's 9 V pump guarantee requires VBAT ≥3.8 V, while this module limits VBAT to 4.2 V. The hardware review must cover regulation tolerance/transients. The intended external IREF resistor is **750 kΩ, 1%**. The firmware uses external IREF (`AD 40`), 9 V pump selection (`8D 72`) and initial contrast `10h`. Contrast is not a hardware current limiter.

The source assumes the bonded module's address is **0x3C** (7-bit, SA0 low). The controller supports 0x3C/0x3D; the module has no exposed SA0 pin. Verify its actual bond/address, acknowledged writes, segment remap, 16-row offset and orientation on hardware. A wrong address causes bounded retry while count saving continues.

## Behavior and scheduling

- Eight right-aligned digits, 0–99,999,999, no leading zeroes. `MAX` remains visible at the limit, including after restoring that count. No wraparound. Existing reset priority, held-key behavior and 30-second inactivity rule are unchanged.
- `counter.c`, `counter.h` and their existing host test are byte-for-byte copies of the shared Q2 counter/journal implementation. Information FRAM at **0x1800–0x181F** keeps the same two-slot version-1 journal. The application image excludes the entire **0x1800–0x19FF** information region. Factory initialization is separate; normal firmware updates must preserve it.
- Timer and port-edge interrupts capture raw button levels with timestamps into a 64-slot ring (63 usable samples). Foreground consumes up to eight samples per iteration using their original timestamps, then retries journal saving before display work. This preserves a complete press that occurs during a slow journal/render step. Interrupts never write FRAM or run display rendering. Queue reads and the final empty/overflow check before sleep are atomic.
- If captured history overflows, the device displays `ERR` with the retained count and suppresses further increments. A fully debounced reset commits zero before clearing the error. Actual held-button debounce state continues through recovery, so releasing reset while holding increment does not create a new press. The gap marker at **0x1820–0x1821** is written and read back in the foreground; any value other than `FFFF` restores the error after reboot. Failed marker writes retain the in-memory error and retry; failed clears retain the error. Abrupt power loss before a new gap marker can be written remains a physical persistence limitation.
- Only successfully committed counts enter the display. The existing two-slot journal layout/format remains unchanged; its new adjacent error marker is separate. Journal failures do not freeze interrupt sampling or display power management.
- I²C runs through interrupt-driven transfers, nominal **65.536 kHz**, at most **27 bytes** for initialization or **16 display bytes + control byte** per data packet. There is no framebuffer or 512-byte busy wait. A frame has a stable count snapshot; changes arriving mid-frame are coalesced into the next frame. One decimal digit conversion occurs per state-machine step. Unchanged counts send no repeated frame.
- No startup/transfer/retry/shutdown wait blocks the foreground. A bus failure or stuck SCL/SDA uses a nominal **20 ms** timeout threshold checked by foreground polling, holds reset, observes a **105 nominal ms** guard, switches off VBAT, and retries after one second while awake. Polling latency can extend the timeout; the input queue continues to capture samples. No open-ended oscillator-lock loop is used.
- Startup holds reset through a **23 nominal ms** stabilization interval plus 2 ms, releases reset and waits another 2 ms, initializes the controller, clears all eight controller RAM pages, enables the internal 9 V pump, then issues display-on. The visible-start guard is **105 nominal ms after acknowledged completion**; actual visibility/startup latency remains to be measured.
- Normal sleep sends `AE`, then `8D 10`, then waits **105 nominal ms from observing acknowledged completion** before cutting VBAT. Guard timestamps use a fresh HAL clock read after the action/completion, so a delayed foreground poll cannot shorten the interval. At the specified +3.5% fast REFO corner, allowing 1.01 nominal ms for tick phase, `(105−1.01)/1.035 > 100 ms`; the 23 ms startup guard likewise exceeds 20 real ms. These timing margins assume the specified clock behavior and do not replace rail measurements. VDD remains powered. Reset is held low after shutdown. A new press during shutdown is counted immediately and restarts the display after shutdown finishes.
- The MCU enters LPM0 during I²C transfers, LPM3 between foreground steps, and LPM4 only after the display is fully off, debounce is settled and the journal is clean. Port edges wake it on both press and release, including a held-key release.

The portable tests establish logic behavior, not target scheduling latency. The ring can retain 63 timer samples, fewer elapsed milliseconds during repeated edge interrupts; sustained overload is explicitly reported rather than silently accepted. ISR execution time, minimum accepted physical pulse width, I²C rise/hold timing, DCO/FLL behavior and worst-case journal/render execution must be measured on the target. The panel may show a partially transferred frame; FR synchronization is not exposed by this module and tear-free updates are not claimed.

## Sources and unresolved display details

- [Wisevision module listing and manufacturer datasheet](https://www.lcsc.com/product-detail/C18723015.html): Ver A drawing dated 2022-09-13; pages 6, 8–15 provide pins, module limits, application circuits and scan settings.
- [Solomon SSD1312 Rev 1.2, March 2021, hosted by Osptek](https://admin.osptek.com/uploads/SSD_1312_1_2_6a7ea26d1f.pdf): §6.1.5 I²C framing/address; §6.9.2 printed p25 reset/power sequencing; DC table printed p28; command table and §2.1.22 pump settings. The complete manufacturer-hosted PDF was downloaded and inspected; its hash and the exact module PDF's hash are in `source-records.json`.
- [TI MSP430FR4133 datasheet](https://www.ti.com/lit/ds/symlink/msp430fr4133.pdf) and [family guide](https://www.ti.com/lit/ug/slau445i/slau445i.pdf): GPIO multiplexing, eUSCI byte-counter automatic STOP, FRAM protection and clock/timer architecture. Build uses exact TI GCC **9.3.1.11**, support **1.212** headers/linker files.

The module's sample labeled “external” nevertheless uses `8D 12`, which the controller explicitly defines as **7.5 V internal pump**. Its example also has a 1/28 comment beside `A8 1F` (32 multiplex). Q3 follows the exact controller command meaning and the module's actual 128 × 32 geometry, not those contradictory comments. The controller command table has an inconsistent enable-bit label; its explicit supported byte sequences and shutdown `8D 10` are used. Obtain vendor clarification and qualify actual panel voltage/current, startup, brightness, orientation, waveform and sleep leakage before release. The separate cell/protection, charger/thermal, assembly/fit, brownout and other engineering gates remain open.

## Build and verification

Run `python3 scripts/run_host_tests_q3.py` for portable tests. Run `python3 scripts/build_firmware_q3.py --toolchain <TI-GCC-root> --support <TI-support-root>` for target compilation. Output lives only in `firmware/q3-oled/build/`. `--verify-only` checks the stored input/output hashes, ELF/HEX byte equality, actual interrupt/reset vector targets, program memory range, information-FRAM exclusion and preservation of Q1/Q2 images.

The build manifest binds source/header/test/build-recipe bytes, compiler/toolchain/support identities, transitive compiler dependencies, generated image/listing/map bytes and test output. Compiler stack-usage output is included; it is not a measured maximum runtime stack. The host suite covers existing debounce/journal/power-cut cases plus startup/clear/pump command ordering, dirty/coalesced rendering, saturation/error labels, 150 committed presses during repeated simulated bus timeouts, the missed-reset regression during a nine-millisecond foreground stall, 1,000 queued press batches across ring wraps, overflow, marker-write/clear failures and reset recovery, held increment through recovery, time wrap and early-startup sleep.

### Factory initialization versus ordinary updates

`build/factory-blank-info-Q3.hex` is a **factory-only** initializer: it writes `FF` to exactly **0x1800–0x1821**, clearing both the 32-byte journal and the new two-byte error marker. It intentionally resets the saved count. For a fresh Q3 device, load and verify this initializer separately, then load the Q3 application. Do not use an older 32-byte initializer alone, and do not flash this initializer during an ordinary firmware update. Ordinary updates load only the application HEX and preserve all information FRAM, including the error marker. The build verifies the initializer's exact range/bytes and hashes it independently of the application. Programming/test release remains subject to the coordinated Q3 hardware qualification and approved order.

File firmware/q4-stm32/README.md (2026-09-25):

# Q4 STM32 target

Separate STM32L072CBT6 firmware for the Q4 hardware candidate. The product target uses FM25V02A-GTR SPI FRAM and the HS96L01W4S03 SPI OLED module. Q3 files are unchanged.

Build using the pinned Arm GNU 14.3.Rel1 compiler:

```sh
python3 -B scripts/build_firmware_q4.py --toolchain /path/to/arm-gnu-toolchain-14.3.rel1-darwin-arm64-arm-none-eabi
python3 -B scripts/build_firmware_q4.py --verify-only
python3 -B scripts/test_firmware_q4.py
python3 -B scripts/test_firmware_q4.py --sanitize
```

The compiler is a free, unpacked toolchain; installation into system directories is unnecessary. `source-records.json` pins the upstream ST and Arm header sources and their licenses. The build manifest binds sources, compiler binaries, included headers, libgcc, commands and every output. ELF, HEX and BIN are equivalent program images, restricted to Flash Bank1. None initializes internal EEPROM, option bytes or external FRAM.

The first successful use of a new/unrecognized FRAM requires a normal count-reset press to establish zero. A queue overflow or storage failure shows ERR and freezes increments until an explicit reset has been committed and read back. A missing/unresponsive FRAM or invalid MCU option bytes requires recovery; no count is claimed saved. After inactivity a quiescent storage fault still permits MCU Stop, with ERR retained. The next increment wakes ERR; a new reset press grants one bounded recovery attempt. Failed FRAM sleep releases CS and isolates SPI; its standby current may remain. The Stop workaround runs entirely from startup-copied SRAM and is checked in the actual ELF for every silicon revision.

An optional `--eeprom-alternate --output /private/tmp/q4-eeprom-alternate` build exercises the same journal using internal EEPROM Bank2. It is an engineering alternative, not an interchangeable update for the product FRAM image. The two storage domains do not migrate counts automatically.

See [the firmware and home-programming guide](../../docs/q4-firmware.md) for pin contracts, timing, power monitoring, exact limitations and USB recovery. These binaries have not executed on a physical MCU. Host tests and ELF inspection are not hardware qualification or manufacturing release.

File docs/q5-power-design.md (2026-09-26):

# Q5 power design — soft power latch, coin-cell holder, battery gauge

Status: implemented engineering candidate, 25 September 2026. Every number below comes from a stated datasheet value, a bounded calculation in [`simulation/q5-power/check.py`](../simulation/q5-power/result.json), or the instruction-level emulator. **None of it is a measurement.** Q4's [power design](q4-power-design.md) remains the reference for the unchanged charger, protector, regulator, FRAM and OLED-rail circuits.

## What changed from Q4 and why

| Change | Parts | Issue | Reason |
|---|---|---|---|
| **Soft power latch** on the existing U7 load switch | U7 ON now on SYS_ON; D3 BAT54C, D4 1N4148WS, Q5 2N7002, R34 100k, R35 1M, TP13 | #12, #5 | Q4 slept at ~80 µA, most of it the TLV767 IQ plus its feedback divider, giving 2–3 weeks of battery. Switching everything below SYS off removes that drain without replacing the reviewed regulator. |
| **Faster U7 slew** | C28, C29 22 nF → 4.7 nF (C0G) | #12 | A short, deliberate press must be able to latch power. |
| **ON-node protection and hold** (design lock) | R38 100k in series from D4, C40 **10 nF** on SYS_ON (4.7 nF at the 25 Sep lock, raised 26 Sep) | review | VBUS hot-plug ringing is filtered below U7 ON's 6 V absolute maximum (τ 0.9 ms). C40 bridges contact bounce up to about 9.9 ms and turns U7 off about 21 ms after the last source releases. |
| **Basic-part values** (26 Sep) | R4 18k (charge 16.7 mA), temperature window 56k/82k/18k/12k (7.3–35.8 °C nominal), R32 75 Ω, Q1/Q2 AO3400A, 50 V 0805 capacitors | cost review | See the REVIEW-Q5 Basic-part review. Each Extended type was a $3.07 feeder fee per order. |
| **U5 supply filter** (26 Sep) | R39 1k from VBUS to U5_VCC, with C9 100 nF | first-order review | The TLV7012 has a 6 V absolute maximum and sat on raw VBUS, where cable hot-plug ringing can overshoot. The 0.1 ms RC filter removes it; U5's ~1.3 µA supply current drops about 1 mV. |
| **Cell holder and onboard NTC** replace the J2 pack harness | BT1 CR2032-BS-6-1 (C70377), TH1 NCP18XH103F03RB; J2 removed | #13 | The Q4 pack/NTC harness was not a JLC inventory part and was unqualified. The holder is vendor-soldered SMT. The cell is a user-supplied LIR2032. |
| **Battery sense** | R36/R37 150k 0.1 %, C37 100 nF, PA4 | #9.4, #12 | Low-battery warning, a gauge and a storage cut-off. |
| **Charger status** | BQ25185 STAT1 → PA5, STAT2 → PA6 | new | CHG, done and fault indication. It also detects USB independently of the ADC. |
| **OLED supply not grounded on hard reset** | U6 QOD pin now NC | #8 | Q4 discharged the module supply through QOD on every NRST. That is outside SSD1315 §6.9.2 power-down sequencing. |
| **Comparator package** | U5 TLV7012DGKR → TLV7012DDFR (same die and pinout, SOT-23-8) | #13 | The DGKR had 21 units of JLC stock, below the ten-board screen with spares. The DDFR had 881. |

The regulator (TLV767), its divider and the rail monitor are unchanged. They now run only while the board is on, so issue #5's recommended nano-IQ LDO swap is unnecessary. Keeping the reviewed rail avoids re-opening the USB-PHY and OLED-logic rail corners (E26).

## Soft power latch

```
SYS ──SW1(COUNT)──► PWR_KEY ──D3.A1─┐
                     │  R34 100k    ├─► SYS_ON ──► U7 ON   (R35 1M to GND)
PB2 PWR_HOLD ──────────────D3.A2────┤   C40 10n to GND
VBUS ──────D4──R38 100k─────────────┘
PWR_KEY ──► Q5 gate: Q5 pulls COUNT_N (PA0) low while COUNT is pressed
```

- **Off:** U7 is off, and the TLV767, MCU, FRAM, OLED, dividers and pull-ups are unpowered. Off current is the BQ29700 (4 µA) plus the BQ25185 battery quiescent current (4 µA): **8.0 µA typical, 11.1 µA maximum**.
- **Power-on by COUNT:** the key puts SYS on U7 ON through D3. tON is 17.9 ms typical. `Reset_Handler` drives PB2 before RAM initialisation, and C40 keeps ON high for about 9.9 ms after the key opens. The press must last about **10.5 ms typical, 16.3 ms with a 25 % slew allowance**; a deliberate press is ≥ 50 ms. The behavioural ngspice transient ([q5-latch-spice](../simulation/q5-latch-spice/README.md)) gives a worst-corner minimum of 14.5 ms and latched 120/120 bouncing presses. A shorter tap simply does not latch. The ON node stays ≥ 2.7 V on a 3.0 V cell, above VIH 1.0 V. The power-on press is counted once (firmware sees the POR flag and COUNT still low).
- **USB:** VBUS through D4 and R38 always holds U7 on, so the ROM DFU and charging work with the application unloaded. The ON node sits at 3.36–4.41 V (R38/R35 divider), above VIH and inside the check's 5.5 V limit.
- **Power-off:** firmware releases PB2 after 30 s of inactivity on battery, following display power-down and FRAM sleep. If the board is still powered after 200 ms (USB present, or the COUNT key held), firmware falls back to Q4-style Stop with PB2 low. Then unplugging USB or releasing the key turns the board off.
- **Inrush at switch-on:** 25.3 µF downstream (with +10 %) over the 7.5 ms tR gives **12.6 mA** (23.7 mA if the slew were twice as fast).
  - The BQ29700 overcurrent threshold over temperature is at least **24.8 mA**: VOCD 100 ±15 mV into R9 3.3 Ω +1 % plus two AO3400A RDS(on) (≤ 48 mΩ at VGS 2.5 V). This corrects the review's finding that the earlier 27.3 mA figure was optimistic.
  - More importantly, OCD cannot trip on inrush at all: the pulse (7.5 ms) is shorter than the minimum OCD delay tOCDD (20 ms −20 % = 16 ms), and the short-circuit threshold needs ≥ 117 mA.
  - DC-bias derating lowers the real value. Measure it on a first article.
- **NRST pinhole on battery** releases PB2, so it acts as a full power cycle. The count is safe because a reset commits only on a completed hold-and-release (issue #3).

## Display supply (issue #8)

- **QOD policy:** U6 QOD (pin 5) is unconnected. On any hard reset (NRST, BOR, DFU entry), PB1 goes Hi-Z, R24 turns U6 off, and the module supply now floats and decays through the module's own load. SSD1315 Rev 1.1 §6.9.2 forbids pulling VBAT to ground. The firmware's normal shutdown order is unchanged (AEh, 8Dh 10h, 120 ms guard, then off), and the emulator checks it on every power-off.
- **Supply voltage:** the module still runs from VLOGIC through U6, 3.151–3.259 V regulated. The module drawing gives an external supply range of 3–5 V (§2). The 3.5–4.2 V figure (§3.2) is the SSD1315 internal DC/DC VBAT specification. Which one governs depends on the module's undocumented internal power tree.
  - Q5 improves the margin: the 3.35 V storage cut-off shuts the board down before the TLV767 leaves regulation. The display therefore no longer runs down to the Q4 3.01 V corner.
  - The firmware's 3.07 V display-off threshold is kept as a fault guard.
  - Feeding the module from SYS_LOAD instead was rejected for now. Its 4.5 V USB level is inside the module's VCC range but above the SSD1315's recommended VBAT maximum of 4.5 V if there is no internal regulator; the absolute maximum is 6 V. That cannot be decided without a sample.
- **First-article gates** (added to the Q5 review):
  - identify the module power tree;
  - measure VBAT/VDD, pump regulation, readability and current at 3.15 and 3.26 V input;
  - 200 NRST pulses with the display on: no latch-up, and the display recovers each time.

## Cell, holder and temperature

- BT1 accepts a 20 mm coin cell. **Use a LIR2032 only** (4.2 V Li-ion, 40–45 mAh). The BQ25185 is set to its existing 4.2 V/ISET values; see the Q4 power document for the current setting. Never fit a primary CR2032/ML2032.
- TH1 is on the board next to BT1, not on the cell. It follows board and ambient temperature, not cell core temperature. For a 40 mAh cell at ≤ 1C that is a reasonable proxy, but it is a qualification item.
- **Insert the cell with USB connected.** The BQ2970 family may not enable discharge on first connection until a charger is present (SLUSBU9I §8.4.1). The upstream C2 + C3 cold-insertion counterexample from Q4 remains: 198.7 µs above 0.4 V against the 125 µs minimum SCC delay. USB-first insertion loads only C3: 35.8 µs. The latch helps because U7 is off at insertion, so SYS_LOAD capacitance never loads the cell.

## Battery gauge, low warning and storage cut-off

The firmware reads SYS_LOAD/2 at PA4 with VDDA derived from factory VREFINT. The divider is downstream of U7, so it draws 12.3 µA only while on and nothing while off.

| Condition (4-sample average, on battery) | Display |
|---|---|
| ≥ 3.95 V | 4 bars |
| ≥ 3.80 / 3.70 / 3.55 V | 3 / 2 / 1 bars (30 mV hysteresis on the way down) |
| < 3.55 V | empty gauge + **LO** |
| 6 consecutive raw samples < 3.35 V | LO for 2 s, count saved, power-off |

- The worst-case estimate error is 2.062 % (the Q4 VREFINT budget plus the 0.1 % divider). The 3.35 V cut-off therefore acts somewhere between 3.28 and 3.42 V. PA4 leakage into the 75 kΩ source adds ≤ 3.75 mV.
- The 3.35 V cut-off keeps the TLV767 out of dropout and the display off a collapsing rail. From cut-off, a few percent of capacity remains before the BQ25185 disconnects the battery from SYS at its ~3.0 V battery UVLO. That happens before the BQ29700's 2.8 V disconnect, so the time to disconnect at the 8 µA off current is shorter than the earlier 9.5-day figure. After a protector disconnect, the cell recovers by charging from USB.
- **USB detection** does not depend on the ADC alone. The BQ25185 regulates SYS to 4.5 V ±2 % with USB. A full cell (≤ 4.221 V) reads at most 4.308 V, and USB SYS reads at least 4.319 V. So ≥ 4.313 V means USB, and STAT1 or STAT2 low independently proves USB. With USB: no LO and no cut-off; CHG while charging; a full gauge when done or disabled (including the temperature window); BAT on a charger fault.

## Battery life (emulated firmware + datasheet currents)

From `simulation/q5-firmware-emulation/results/energy-model.json`, for 40 mAh minimum / 45 mAh nominal capacity at 90 % usable:

| Use | mAh/day | Days |
|---|---:|---:|
| On a shelf (off) | 0.194 | 150 – 169 |
| Light: 10 sessions × 10 presses | 0.398 | 81 – 91 |
| Moderate: 30 × 10 | 0.805 | 42 – 48 |
| Heavy: 20 × 30 + 1 h continuous | 2.479 | 14 – 16 |

Q4 with the same pack model lasted 2–3 weeks regardless of use. Self-discharge (~3 %/month) is included in the shelf figure. **Storage advice:** charge to about 50–60 %, and top up every three months.

## Physical gates specific to Q5 power

1. Latch timing with a real bouncing MX contact at the minimum press. Measure how short a tap turns the board on. The 2N7002 threshold spread at the COUNT_N mirror.
2. Rail behaviour on PB2 release: that U7 falls cleanly without MCU brown-out chatter, and that USB unplug during Stop turns the board off.
3. ADC accuracy through the 75 kΩ source and 100 nF C37 at the firmware's sampling time. Gauge thresholds against a real LIR2032 discharge curve under display load.
4. STAT1/STAT2 timing and levels across charge, done, temperature-hold and fault.
5. Holder contact resistance and retention, cell insertion with USB present, and the NTC's thermal coupling to the cell.
6. Off current (expected ~8 µA) and the protector's recovery after deep discharge.

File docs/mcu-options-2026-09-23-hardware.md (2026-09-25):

# MCU options: hardware and simulation review — 23 September 2026

**Recommended migration candidate: STM32L072CBT6, with a separate 3.3V MCU rail and the existing 3.0V OLED rail retained.** Retaining MSP430 remains the lowest engineering-risk option. ESP32-C3 does not fit the present battery/protection budget well. No processor is a pin-compatible replacement, and none removes the OLED, startup or pack qualification gaps. This document proposes a future revision; frozen Q3 is unchanged. Quotes, vendor contact, purchases and manufacture remain paused.

## Processor comparison

Figures below are chip-level data-sheet conditions, not measured whole-device battery current. They exclude OLED, pull-ups, regulator losses, memory writes and boot transients.

| Option | Electrical/power consequence | Hardware/system tradeoff |
| --- | --- | --- |
| **Existing MSP430FR4133IG48R** | 1.8–3.6V operation;126µA/MHz advertised active consumption, under1µA standby with RTC/LCD. Current3.0V rail remains appropriate. | Existing tested software and FRAM journal; SBW fixture needed. USB remains charge-only. No migration cost or extra memory chip. [TI product/data sheet](https://www.ti.com/product/MSP430FR4133) |
| **STM32L072CBT6 / CZT6, LQFP48** | VDD can operate below3V, but USB domain needs3.0–3.6V. Flash execution at4MHz is650µA typical/670µA characterized maximum under the table conditions;32MHz is6.65/7.2mA. Stop mode at≤25°C is0.43µA typical/1µA maximum, excluding added clocks/peripherals. | CB128KB versus CZ192KB Flash; larger CZ memory alone offers no present functional advantage. Native USB can avoid a routine external programmer; retain SWD recovery pads. Both expose separate VDD_USB. [ST DS10689, Tables2/26/30/37](https://www.st.com/resource/en/datasheet/stm32l072cb.pdf) |
| **STM32L072KZ, 32-pin** | Same family; USB power is internally tied to VDD because the separate pin is absent. | Common3.3V MCU rail below works, but smaller pin budget and a distinct pin map. LQFP32 is still7×7mm body; do not infer a large area saving from pin count alone. Exact package suffix and routing matter. [ST package/power definitions](https://www.st.com/resource/en/datasheet/stm32l072cb.pdf) |
| **ESP32-C3** | 3.0–3.6V supply. Radio-off80MHz running is17mA typical before OLED; Wi-Fi RX84mA and TX up to335mA listed peaks. Deep sleep5µA is not the active or boot current. | Radio-off MCU plus nominal10mA OLED-converter input already approaches/exceeds the lower corner of the existing roughly30mA protection threshold. Radio operation is incompatible without a substantially different energy source/power design. [Espressif v2.4 electrical/current tables](https://documentation.espressif.com/esp32-c3_datasheet_en.html) |
| **ATtiny3226 with UPDI** | 1.8–5.5V, limited to10MHz at3V;5MHz active1.6mA typical, power-down0.1µA typical/1.5µA maximum at25°C with peripherals off. | A credible inexpensive MCU/programming alternative, but no native USB and no retained FRAM journal. Requires a software port and EEPROM wear/power-loss design. It does not deliver the plug-in USB experience motivating STM32. [Operating limits](https://onlinedocs.microchip.com/oxy/GUID-ACE76F82-8072-410B-AFA7-16B2BF7B4CBA-en-US-8/GUID-7F86BCC6-B62F-49BA-B774-3C93C9197DDE.html), [current table](https://onlinedocs.microchip.com/oxy/GUID-ACE76F82-8072-410B-AFA7-16B2BF7B4CBA-en-US-8/GUID-6BF6C784-3E2F-4690-ABC2-73A384F3711F.html) |

ESP32-C3's vendor recommends a≥500mA source and a40MHz crystal for the bare chip. A module incorporates RF/clock/flash circuitry but adds area, keepout and expense; native Serial/JTAG is not a general-purpose user-configurable USB device controller. Underclocking and short awake bursts could improve average consumption, but do not supply a guaranteed boot/flash-current envelope under the present protector. A battery/radio redesign would exceed the scope of a cheaper programming interface. [Espressif hardware checklist](https://docs.espressif.com/projects/esp-hardware-design-guidelines/en/latest/esp32c3/schematic-checklist.html).

## Concrete STM32L072CBT6 power architecture

Keep every return on protected **GND**, not raw cell negative. Continue using charger **SYS**, not the4.2V cell directly, as regulator input. The proposed distribution is:

```text
protected charger SYS ── existing TPS7A0230P ── OLED_VDD3V / I²C pull-ups
                     └─ new TPS7A0233P      ── MCU_VDD3V3 / VDDA / VDD_USB
                     └─ existing TPS63900   ── switched OLED pump input
```

**Added regulator candidate:** TPS7A0233PDBVR, SOT23-5, a real ordering-table variant of the existing family. Candidate pin schedule:1IN=SYS,2GND,3EN=SYS,4NC as explicitly permitted by TI,5OUT=MCU_VDD3V3. It needs local input/output capacitance and the MCU decoupling below. Typical no-load ground current is25nA; it is not a fixed25nA at every load. The family has ±1.5% temperature accuracy under its specified conditions, additional line/load effects, and active output discharge. [TI electrical/pin/ordering data](https://www.ti.com/lit/gpn/TPS7A02). JLC's [C2887324 listing](https://jlcpcb.com/partdetail/TexasInstruments-TPS7A0233PDBVR/C2887324) establishes catalog identity only here; the separate procurement review controls current stock.

For the exact48-pin part, VDD pins1/24/48, VDDA9 and VDD_USB36 join the same MCU rail; grounds8/23/35/47 join GND. USB uses PA11/32 and PA12/33. These are a proposed connection schedule requiring native symbol/pad and alternate-function review, not a generated design. The32-pin version needs its own schedule. [ST package definitions](https://www.st.com/resource/en/datasheet/stm32l072cb.pdf).

**Why not simply reuse3.0V?** Its negative tolerance and dropout fail USB's3.0V minimum. **Why retain OLED3.0V?** X087's DC table permits3.5V, but its AC table/application states1.65–3.3V and requests matching interface voltage. A shared3.3V nominal rail exceeds the stricter3.3V limit at positive tolerance. A precision shared≈3.15V supply could reduce parts, but requires an exact regulator/tolerance/transient design rather than silently changing the limit. [Exact X087 specification](https://atta.szlcsc.com/upload/public/pdf/source/20231103/222F0746A2795BBD5263EDDBD3E1B824.pdf).

**Battery versus USB:** when valid USB supplies the charger, SYS has useful headroom for3.3V regulation; programming must wait for that supply to settle. On battery, the new LDO may enter dropout as SYS falls. Lower MCU voltage is allowed with USB detached and a suitable clock/BOR policy; it is not proof of a particular low-battery runtime. Dropout recovery can overshoot, and added capacitance/load changes the unresolved insertion transient. Test cold battery, USB attach/detach and brownout. Do not promise3.3V regulation down to the charger's≈3V battery cutoff.

**Separate USB-only supply rejected as the default:** although the48-pin device allows an independent USB domain, ST constrains its relationship to VDD during below-minimum startup/shutdown. A bareVBUS-to3.3V LDO could violate that order. The common MCU rail avoids needing an extra sequencer for this purpose. It still needs USB presence detection so battery power does not advertise an attached device to an unpowered port. [ST power constraints, Table26 note2](https://www.st.com/resource/en/datasheet/stm32l072cb.pdf).

### Interface and boot details that must accompany the rail split

- Use I²C pins as open drain with the pull-ups remaining on OLED3.0V. Review exact pin thresholds and off-state injection in both power orders. The lower OLED ACK rating remains a problem with4.7k; a different MCU does not strengthen the OLED sink.
- Drive OLED RESET_N open drain and provide a pull-up to OLED3.0V. **Existing Q3 R25 is a pulldown: changing only firmware would leave reset stuck low.** Replace/review that resistor connection/value in the future design. With a pull-up, reset's initial state changes; retain the ENABLE pulldown, assert reset before powering the pump, and execute the full VDD/reset sequence. ROM bootloader mode must keep the pump disabled.
- OLED_ENABLE can drive the existing converter/Q6 controls at3.3V subject to their pin/gate ratings. All unpowered-interface and discharge paths still need checking.
- Connect both USB-C orientation pairs correctly, retain the two CC resistors, route D+/D− as a differential pair, add a suitable low-capacitance ESD device and provide reviewed VBUS sensing. Reserve series-resistor footprints only where the exact USB PHY/reference design calls for them; do not blindly copy another STM32 family.
- Provide BOOT0 selection, NRST access and SWDIO/SWCLK/GND/Vref pads. USB bootloader availability is not a reason to remove recovery access. Use the separate firmware analysis for exact boot option bytes, DFU behavior and nonvolatile-storage design.

The mixed-rail interface is an engineering proposal, not blanket compliance with the panel's matching-voltage wording. Its open-drain levels must be checked against both devices and supplier clarification or physical characterization before release.

## BOM consequences to include in cost comparison

The migration replaces the MCU footprint and its power network; it does not save the charger, protector, thermal window, OLED converter or specialized FPC work. Allow for:

1. One added3.3V regulator and local input/output capacitors; all effective-capacitance and reverse-current requirements remain.
2. Three100nF VDD decouplers, a100nF USB-domain decoupler, VDDA decoupling and a package bulk capacitor; some existing Q3 capacitance can be reassigned only after layout review. ST's reference uses local decoupling plus bulk and analog capacitors. [AN4467 supply/decoupling guidance](https://www.st.com/resource/en/application_note/an4467-getting-started-with-stm32l0xx-hardware-development-stmicroelectronics.pdf).
3. USB ESD, VBUS-sense components and boot/reset access; SWD pads add no fitted connector if a pogo fixture is used. Crystal-less USB can avoid a USB crystal, subject to the exact ROM/application clock setup.
4. A validated persistence solution. Internal EEPROM may avoid an external chip, but per-click durability, torn writes, write time and data preservation across DFU differ from FRAM. External FRAM, if selected, adds its device, bypass and bus connections. Do not price that decision as already resolved.

Do not convert typical MCU current into45mAh runtime: OLED demand and awake duty cycle dominate uncertainty, and new boot/current/decoupling transients must remain below the actual protection envelope. A cheap USB-capable chip whose supply needs redesign can cost more than retaining the SBW fixture.

## Manufacturer model coverage

[The model inventory](../simulation/mcu-review-2026-09-23/vendor-models.json) records official URLs, downloaded ZIP hashes and scope. Vendor files remain temporary; no proprietary model was copied into the repository.

| Device | Verified model situation | What it cannot establish here |
| --- | --- | --- |
| BQ25185 | No public SPICE model found in the current [TI catalog](https://www.ti.com/product/BQ25185) or bounded search. Its EVM is physical hardware. | Actual SYS/BATFET slew, startup state machine, charging/thermal interactions require measurement or a later verified model. |
| BQ29700 | No current public model located; a [historical TI answer](https://e2e.ti.com/support/tools/simulation-hardware-system-design-tools-group/sim-hw-system-design/f/simulation-hardware-system-design-tools-forum/828079/webench-to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) explicitly reported none. This is not a claim that no private model exists. | Threshold/delay/state-machine behavior must be modeled from documented corners and labeled behavioral, then validated. |
| TPS7A02 | Official [SBVM950](https://www.ti.com/lit/zip/sbvm950) generic plain-text PSpice core downloaded and inspected. | Header excludes input/quiescent current, temperature and noise. ExactP-variant discharge/reverse behavior was not established; generic dropout is not the exact low-load curve. No vendor-model execution claimed. |
| TPS63900 | Official [SLVMDC0A](https://www.ti.com/lit/zip/slvmdc0a) encrypted PSpice transient model inspected. Models soft start/input limit/DVS via parameters. | Physical CFG resistor decoding and temperature are explicitly excluded. Encryption prevents direct use in available ngspice; no decryption attempted. Nominal simulation does not create absent min/max guarantees. |
| Candidate MCU I/O | ST lists [STM32L0 IBIS3.0](https://www.st.com/en/microcontrollers-microprocessors/stm32l072cb.html); this study did not validate its internal package/pin coverage. No executable I/O model obtained for the other candidates or exact OLED FPC. | IBIS concerns electrical buffers and interconnect, not CPU execution, USB protocol, boot current, EEPROM or OLED pump behavior. The missing OLED sink/capacitance data remains missing. |

### Executed bounded ngspice study

The official temporary KiCad installation includes **ngspice45.2** as a shared library. [Original deck](../simulation/mcu-review-2026-09-23/interface-and-inrush.cir), [runner](../simulation/mcu-review-2026-09-23/run.py) and [result](../simulation/mcu-review-2026-09-23/result.json) reproduce three separate idealized circuits:

| Hypothesis, not a fitted device model | ngspice result |
| --- | ---: |
|3V/4.7k pull-up against hypothetical6k OLED sink | ACK1.682243V |
|Ideal released4.7k/100pF bus |30–70% rise398.217ns |
|4.2V insertion,3.3Ω shunt+**hypothetical1Ω** extra resistance, empty20µF |179.454712µs above0.4V |

They independently reproduce the earlier [analytical concerns](review-Q3-2026-09-22-hardware.md). The RC example excludes the charger's turn-on slew and protector state machine; the1Ω is not an approved cell impedance. All semiconductor behavior is absent. The report binds deck/runner/engine hashes, reruns byte-identically and matches independent equations; deliberately changing each of sink resistance, bus capacitance and SYS capacitance makes its analytical check fail.

Run `python3 simulation/mcu-review-2026-09-23/run.py --library /absolute/path/to/libngspice.dylib`. The engine reported a missing optional `spinit`; the deck uses only built-in linear elements and explicitly sets its numeric tolerances. The report retains that warning. No whole-board simulation or hardware PASS is asserted.

**Next simulation work:** (1) bounded, explicitly behavioral charger/protector state machines with documented corner sweeps; (2) exact cell impedance/MLCC bias and measured gate-slew inputs; (3) compatible manufacturer regulator runs cross-checked against their examples; (4) MCU/OLED I/O electrical models plus extracted bus capacitance; and (5) hardware USB/rail/persistence tests. Every reported result must state which of those layers it actually includes. This comparison supports choosing a feasible candidate, not manufacturing it.

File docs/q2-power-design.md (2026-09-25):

# Q2 power correction proposal

Engineering candidate, 2026-09-15. This document specifies changes for a separate Q2 design. It does not alter the submitted Q1 package, approve a cell, establish measured performance, or release manufacture.

## Decisions

1. Select **TPS7A0230PDBVR** for U3. Its active output discharge is an intentional functional choice, not a spelling correction to the unmatched Q1 ordering code.
2. Replace U5 with **TLV7032DGKR**, split its two push-pull outputs, and require both outputs HIGH through two series MOSFETs before CE_N can be pulled LOW. Each gate has its own ground pulldown. This removes the external powered pullup that created the E18 monitor-supply-loss mechanism.
3. Retain the real, battery-contact NTC and the narrower external temperature monitor. Keep R5 = 10 kΩ on the charger's TS input and R6 = 100 kΩ from VBUS to CE_N. Reduce sensor excitation and recalculate the window using the parts below.
4. Retain the intended charger settings: **4.2 V**, **100 mA input-limit option**, and **18.18 mA nominal charging current**. The earlier pin/resistor allegation was refuted in [the charger audit](review-charger-Q2.md). Cell approval, protection, low-current charging, thermal contact and power-loss tests remain open.

The existing circuit and physical pin assignments are recorded in `electronics/build_pcb.py:77`–90 and 96–124. The implementation should live in the separate Q2 model/board/BOM; do not run the Q1 builder over its routed historical output.

## Exact candidate components and connections

All resistor changes below use 0603, 1%, 0.1 W parts with ±100 ppm/°C temperature coefficient. Manufacturer one-page specifications are linked individually.

| Ref | Q2 value / exact MPN | Terminal 1 | Terminal 2 |
|---|---|---|---|
| R10 | 57.6 kΩ / [RC0603FR-0757K6L](https://www.yageogroup.com/component-documentation/download/specsheet/RC0603FR-0757K6L) | VBUS | TEMP_SENSE |
| R11 | 115 kΩ / [RC0603FR-07115KL](https://www.yageogroup.com/component-documentation/download/specsheet/RC0603FR-07115KL) | VBUS | TEMP_COLD |
| R12 | 24.3 kΩ / [RC0603FR-0724K3L](https://yageogroup.com/component-documentation/download/specsheet/RC0603FR-0724K3L) | TEMP_COLD | TEMP_HOT |
| R13 | 16.2 kΩ / [RC0603FR-0716K2L](https://yageogroup.com/component-documentation/download/specsheet/RC0603FR-0716K2L) | TEMP_HOT | GND |
| R14 | 100 kΩ / RC0603FR-07100KL, existing value repurposed | TEMP_COLD_OK | GND |
| R15 | 100 kΩ / RC0603FR-07100KL, replaces 1 MΩ | TEMP_HOT_OK | GND |
| R6 | 100 kΩ / RC0603FR-07100KL, retained | VBUS | CE_N |
| R5 | 10 kΩ / RC0603FR-0710KL, retained | TS_FIXED | GND |

Retain C9 = 100 nF directly between U5 supply and ground. Retain R3 = 24 kΩ, R4 = 16.5 kΩ, and the R19 = 2 kΩ / C13 = 4.7 nF compensation branch. Retain the four-wire harness: J2.1 CELL_P, J2.2 CELL_N_RAW, J2.3 TEMP_SENSE, J2.4 GND. The NTC spans J2.3–J2.4 and remains insulated from both cell terminals. Its physical contact with the cell is essential.

### U5 comparator polarity

Use **TLV7032DGKR**, DGK VSSOP-8. Physical pin functions follow [TI Table 4-2](https://www.ti.com/lit/gpn/TLV7042).

| Pin | Function | Q2 net |
|---|---|---|
| 1 | OUTA | TEMP_COLD_OK |
| 2 | INA− | TEMP_SENSE |
| 3 | INA+ | TEMP_COLD |
| 4 | VEE | GND |
| 5 | INB+ | TEMP_SENSE |
| 6 | INB− | TEMP_HOT |
| 7 | OUTB | TEMP_HOT_OK |
| 8 | VCC | VBUS |

Channel A is HIGH when the sensor voltage is below the cold threshold: the cell is warm enough. Channel B is HIGH when it is above the hot threshold: the cell is cool enough. Both must be HIGH. **Do not join pins 1 and 7.** Remove the old TEMP_OK net and its VBUS pullup relationship; repurposed R14 goes to ground.

With an intact passive divider, each input stays between GND and VBUS, including the open/short-sensor endpoints. This fits the powered common-mode range. A monitor-supply disconnection leaves inputs potentially above U5 VCC, so its explicitly fault-tolerant input behavior matters; do not assume the same behavior for a replacement comparator.

### Q3/Q4 series charge-enable path

Use **Nexperia 2N7002,215** for both devices, SOT-23. This is the Nexperia 2N7002 type with the identified ordering/packing suffix; do not substitute the importer's similarly named part from another manufacturer. The [Nexperia datasheet](https://assets.nexperia.com/documents/data-sheet/2N7002.pdf) assigns pin 1 gate, pin 2 source, pin 3 drain.

| Device | Pin 1: gate | Pin 2: source | Pin 3: drain |
|---|---|---|---|
| Q3, upper FET | TEMP_COLD_OK | CE_MID | CE_N |
| Q4, lower FET, new | TEMP_HOT_OK | GND | CE_MID |

```text
VBUS -- R6 100k -- CE_N -- D Q3 S -- CE_MID -- D Q4 S -- GND
                           G                   G
                      TEMP_COLD_OK         TEMP_HOT_OK
                           |                   |
                       R14 100k            R15 100k
                           |                   |
                          GND                 GND
```

The body diodes point from source toward drain. With the orientation above, an OFF device blocks the positive CE_N voltage. Reversing either source/drain connection defeats the intended isolation. In normal operation both FETs conduct and their source voltages are near ground; either LOW output interrupts the sink path.

## Temperature setting and excitation calculations

The retained sensor is **Murata NCP18XH103F03RB**: 10 kΩ at 25°C, resistance tolerance ±1%, B25/50 = 3380 K ±1%. Murata's current list marks it NRND and specifies 0.1 mA maximum operating current at 25°C. NRND sourcing and the complete installed resistance/temperature curve remain open, as already documented under E12. [Murata component list, NCP18 table](https://www.murata.com/-/media/webrenewal/tool/library/common-pdf/static-model/component-list-ntc-2508.ashx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).

For the proposed ladder, define:

```text
S = R11 + R12 + R13 = 155.5 kΩ
a_cold = (R12 + R13) / S = 0.260450161
a_hot  = R13 / S = 0.104180064
Vsense / VBUS = Rntc / (R10 + Rntc)
Rtrip = R10 × a / (1 − a)
T(°C) = 1 / [1/298.15 + ln(Rtrip/R25)/B] − 273.15
```

Calculated nominal cold/hot resistances are **20.2852 kΩ / 6.69864 kΩ**. The constant-beta model gives **7.49°C / 35.92°C**, preserving the earlier conservative nominal window. At 25°C and 5 V, excitation is 73.96 µA and NTC dissipation is 0.0547 mW; Q1's 10 kΩ excitation produced 250 µA and 0.625 mW. With intact R10, 5.5 V maximum and R10 at −2.01%, even a nonnegative arbitrarily small NTC resistance cannot draw more than **97.45 µA**. Installed self-heating and thermal lag still need measurement.

### Conditional corner envelope

The following is an engineering model, not a guaranteed cell-temperature limit. Independently vary all four divider resistors, R25 and beta; evaluate both signs of comparator threshold error and the VBUS endpoints. Use `a_effective = a + error/VBUS` in the resistance equation.

| Assumptions | Cold trip model | Hot trip model |
|---|---:|---:|
| Nominal components, zero comparator error | 7.49°C | 35.92°C |
| R10–R13 ±1%; R25 and B each ±1%; VBUS 2.95–5.5 V; threshold error ±21.5 mV | 5.52–9.48°C | 32.64–39.56°C |
| Same, with each divider resistor widened to ±2.01% | 4.83–10.20°C | 31.85–40.50°C |

The ±2.01% model conservatively covers 1% initial tolerance combined with 100 ppm/°C over a 100°C excursion. The error allocation is 8 mV offset + 12.5 mV half-hysteresis + 1 mV allowance for common-mode/supply effects. TI's dual-device electrical table specifies offset ±8 mV and hysteresis up to 25 mV at stated test conditions; the 1 mV addition is our allowance, not a new TI guarantee. [TI section 5.9 and hysteresis diagram 6-1](https://www.ti.com/lit/gpn/TLV7042).

The widened resistance limits are 18.3645–22.3497 kΩ cold and 5.8010–7.65625 kΩ hot. The constant-beta fit extrapolates B25/50 below 25°C; the manufacturer specifies different reference beta values across other intervals. A complete guaranteed R/T tolerance table and cell-contact measurements must replace this model before claiming an actual 0–45°C envelope. The apparent minimum margins of 4.83°C cold and 4.50°C hot are model margins only. Comparator bias/leakage, board contamination and the full voltage/temperature range also require qualification.

The 0–45°C target is retained from `procurement/RFQ-Q1.md:62`. Obtain the cell manufacturer's current approved charging envelope for the custom pack. The [currently linked EEMB specification](https://eemb.oss-accelerate.aliyuncs.com//uploads/20230323/ba65f4e593715c5dedf377f550c58f6b.pdf) documents its 25°C charging characterization; that alone does not approve this complete circuit across temperature.

### Why the existing NTC is not moved directly to TS

The BQ25185's typical 38 µA TS excitation and 0.115/1.0075 V hot/cold thresholds correspond to about 3.026/26.513 kΩ. A nominal 10 kΩ, B3435 sensor reaches those values near 59.5/1.7°C. Direct connection therefore permits charging substantially above the retained 45°C target. [TI BQ25185 electrical table and section 6.3.9](https://www.ti.com/lit/ds/symlink/bq25185.pdf).

The native resistance-threshold ratio is about 8.76; the retained B3380 model changes by only a factor of 5.76 between 0°C and 45°C. Ordinary positive series/shunt resistance compresses that sensor ratio further. This bounded revision therefore retains the external window instead of treating a simple TS rewiring as an adequate correction. R5 is deliberately fixed; it supplies no independent backup temperature protection.

## Supply loss, gate margin and fault reasoning

TI section 6.4 specifies TLV703x POR output LOW while supply is below its minimum on either rising or falling ramps; its operating range starts at 1.6 V. Section 6.4.1 permits inputs driven while VCC is zero without feeding VCC. However, it provides no zero-supply output-sink resistance or maximum power-down response time. Treat a fully unpowered output as potentially floating for passive-bias design. [TI functional modes](https://www.ti.com/lit/gpn/TLV7042).

R14/R15 discharge the gates without any externally powered gate pullup. Thus loss of U5's supply no longer leaves a resistor divider actively commanding charge. This corrects the identified E18 connectivity mechanism, subject to the transient and leakage tests below. It does not establish that every possible component failure disables charging.

- At 5 V, TI specifies output HIGH ≥4.65 V and LOW ≤0.35 V at 3 mA. Our 100 kΩ gate pulldown loads each output by about 50 µA. Nexperia specifies RDS(on) ≤5.3 Ω at VGS = 4.5 V, 25°C. The illustrative two-FET drop at 50 µA is about **0.53 mV**; CE_N is expected comfortably below the charger's 0.4 V LOW limit. Full gate-drive margins near a USB brownout require measurement because the cited output-voltage guarantee is at 5 V.
- The FET threshold range is not an ON-resistance guarantee or a guarantee of zero subthreshold current. In particular, its VGS = 0 leakage rating does not certify leakage at the comparator's maximum 0.35 V LOW bound. At a 2.95 V input and R6 = 102.01 kΩ, combined off-state leakage must stay below **16.17 µA** to keep CE_N above 1.3 V. Measure this with each gate commanded LOW, each monitor-power fault, temperature extremes and board leakage included.
- Nexperia's 25°C gate-leakage maximum of 100 nA corresponds to only 10.2 mV across a 102.01 kΩ pulldown. It does not include unspecified unpowered U5 output leakage. The 50 pF input-capacitance maximum suggests a roughly 5 µs RC scale; capacitance is nonlinear and parasitics add to it, so this is not a guaranteed disable time. [Nexperia electrical characteristics](https://assets.nexperia.com/documents/data-sheet/2N7002.pdf).

| Applied condition | Inferred candidate response / limitation |
|---|---|
| Normal 10 kΩ sensor, monitor powered | A and B HIGH; both FETs ON; charge permitted. |
| Cold or NTC open | TEMP_SENSE rises above TEMP_COLD; A LOW; Q3 interrupts charge enable. |
| Hot or NTC short | TEMP_SENSE falls below TEMP_HOT; B LOW; Q4 interrupts charge enable. |
| U5 VCC connection open with VBUS and ground intact | POR/passive gate pulldowns request both FETs OFF; R6 requests charge disable. Verify the complete ramp/floating-supply response. |
| Comparator output/interconnect open upstream of an intact gate-to-ground pulldown | That gate's pulldown requests OFF. Place the pulldown close to the MOSFET gate. |
| R10 open or short | Sense goes toward GND or VBUS respectively; one channel requests disable. |
| R11 open or R13 open | Reference tends toward GND or VBUS respectively; one channel requests disable. |
| R12 open | Thresholds spread toward opposite rails; the temperature window can fail enabled. Not covered. |
| Comparator stuck HIGH, FET short, gate/pulldown connection open, monitor ground open, CE_N short, harness cross-wiring | Not established safe by this change; include in remaining fault analysis. An open between the gate and its pulldown can leave the gate floating. |
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

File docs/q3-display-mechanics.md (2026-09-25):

# Q3 X087 display footprint and mechanical proposal

15 September 2026. Engineering candidate only. This file and the new Q3 footprint do not modify Q1/Q2 or establish vendor process acceptance, a complete quote, physical qualification, or manufacturing release.

## Decision and evidence

Use a nominal **unfolded, viewing-face-up** arrangement of exact **Wisevision X087-2832TSWIG02-H14**, with the glass to the left and the 14-contact FPC tail to the right. The proposed footprint is `electronics/q3/CountFidgetQ3.pretty/X087-2832TSWIG02-H14.kicad_mod`. Its origin is the nominal glass center; this is not the solder-row center or full-module center. Rotation zero uses KiCad +X right, +Y down when viewed from the PCB front.

Controlling dimensional evidence is the [Wisevision preliminary specification, revision A](https://atta.szlcsc.com/upload/public/pdf/source/20231103/222F0746A2795BBD5263EDDBD3E1B824.pdf), PDF pages 4–6, especially the dimensioned drawing on page 5, dated 2022-09-13. The locally inspected PDF SHA-256 is `bf88a9e033ddb6656bc9ddc5f20d3de9188983bb2cdd4278199555ee6e7989ce`. Page 10 supplies the application circuit, not a PCB land pattern or solder profile. Pages 22–24 warn against pressure on the glass/driver, excessive flex bending, and ESD. The manufacturer drawing is preliminary and needs confirmation against the supplied lot.

The [manufacturer product page](https://www.jx-wisevision.com/0-87-micro-128x32-dots-oled-display-module-screen-product/) contains conflicting outline and unrelated table entries. Its 28.54 × 8.58 mm outline must not silently replace the PDF's 29 × 8.8 mm drawing. The [JLCPCB exact-part catalog](https://jlcpcb.com/partdetail/Newvisio-OEL/C18723015) labels this part Wave Soldering / High assembly difficulty. That catalog label does **not** approve exposing this glass to a wave or reflow, our land geometry, its final height, or an assembly fixture. Root is obtaining exact process confirmation from both vendors.
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

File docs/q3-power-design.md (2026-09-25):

# Q3 OLED power circuit — implementation candidate

2026-09-15. This defines the new circuit for **X087-2832TSWIG02-H14 / C18723015**, with the existing protected battery path, charger, MCU and 3.0 V logic regulator retained. It does not change or qualify Q1/Q2. The initial pin/net schedule is [power-candidates.json](../procurement/q3/power-candidates.json). Final selected identities are controlled by the explicit overrides in [build_q3_model.py](../scripts/build_q3_model.py), including the stocked replacements below; the frozen initial schedule is not the final procurement BOM.
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

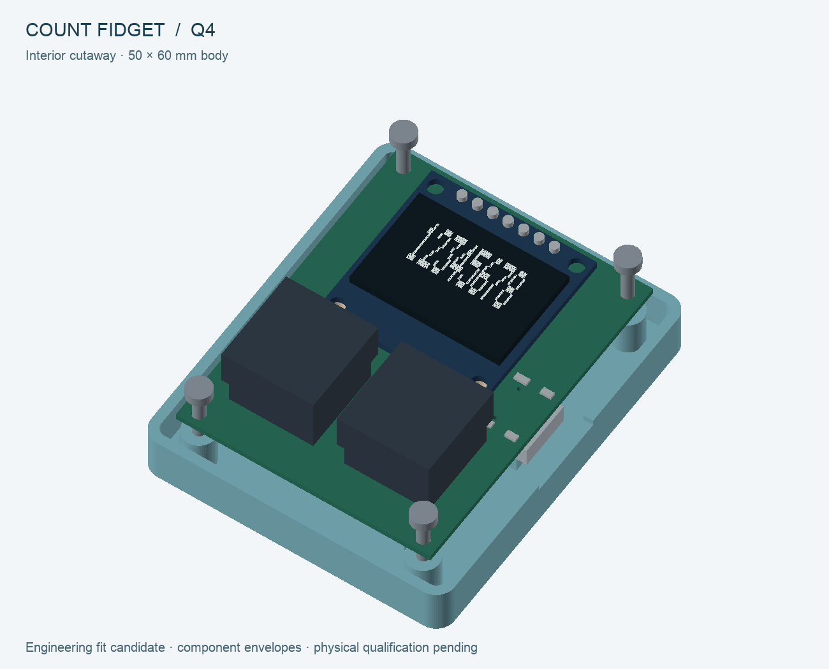
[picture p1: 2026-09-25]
mechanical/q4/interior-Q4.png

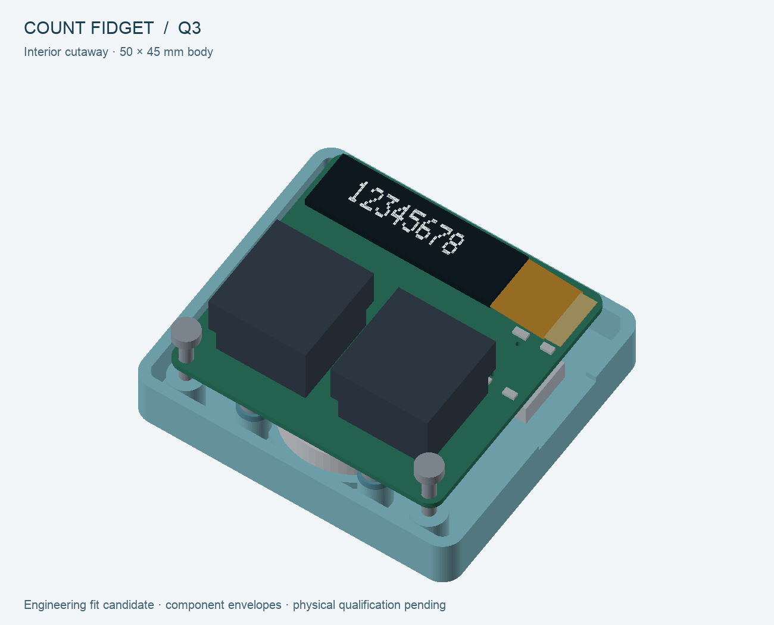
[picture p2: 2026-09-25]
mechanical/q3/interior-Q3.png

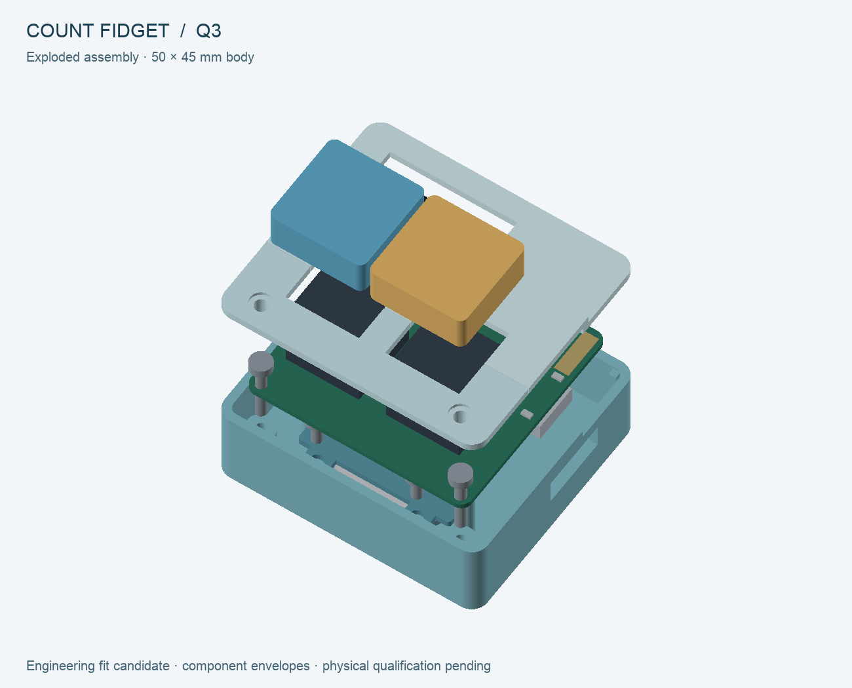
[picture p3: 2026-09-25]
mechanical/q3/exploded-Q3.png

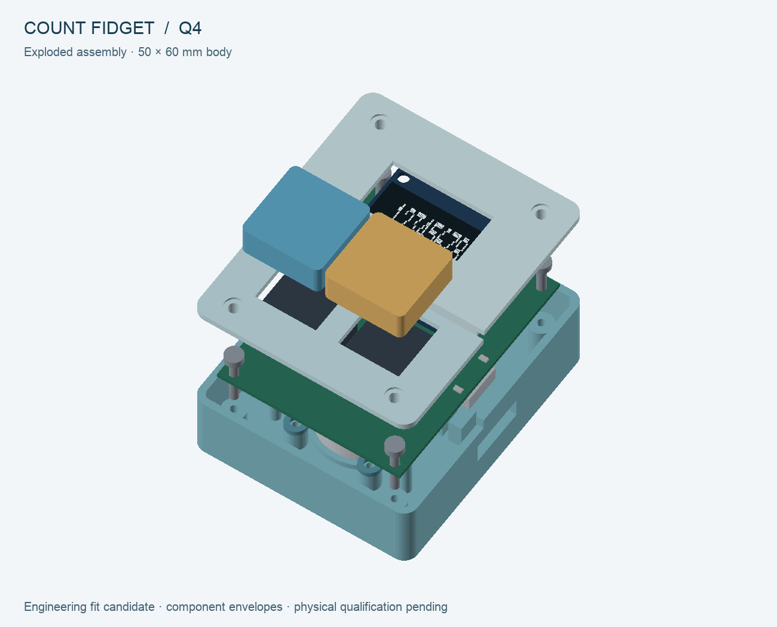
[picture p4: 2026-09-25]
mechanical/q4/exploded-Q4.png

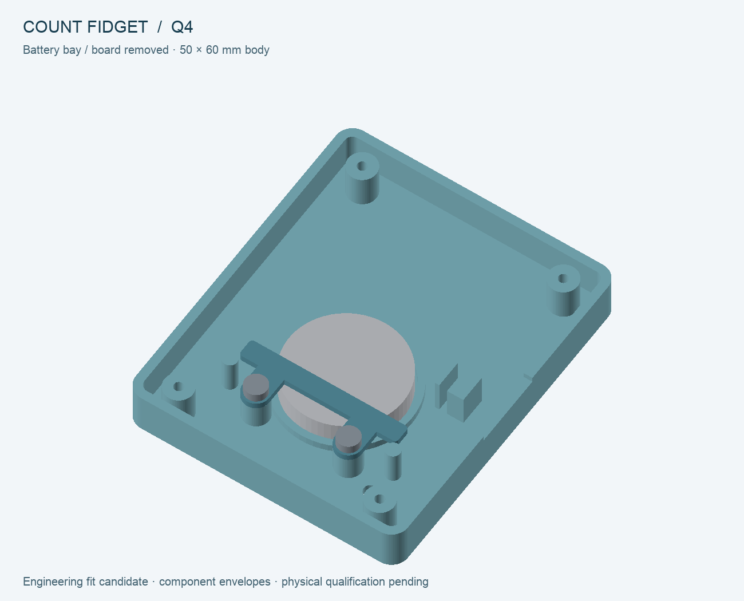
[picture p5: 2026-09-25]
mechanical/q4/battery-bay-Q4.png

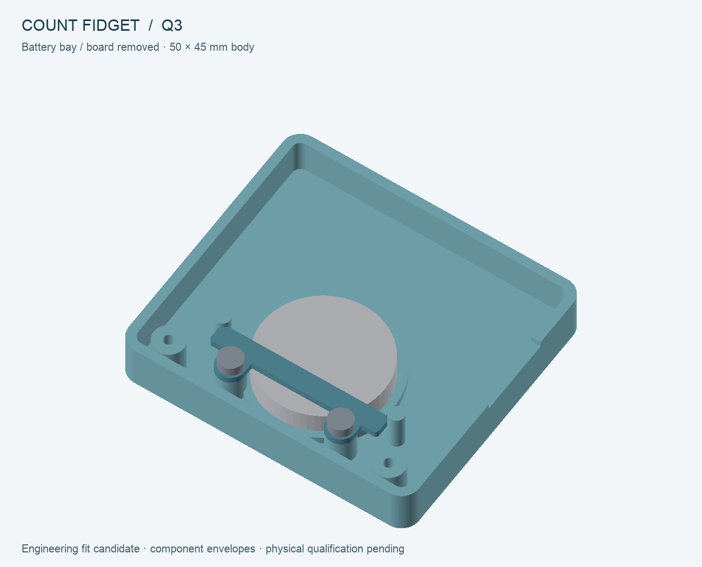
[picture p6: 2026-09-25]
mechanical/q3/battery-bay-Q3.png

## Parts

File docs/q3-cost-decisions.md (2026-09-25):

# Q3 cost and design-intent review

The user asks to expose avoidable cost, starting with the unexplained four-layer PCB. This is a small low-speed counter, not a high-speed data board. Four layers were a compact-layout choice, not a functional requirement. The OLED replaces twenty LCD signal connections with I²C and control signals, making two layers practical. The Q3 native board is now routed on **two copper layers**, with all SMT on the bottom. Fresh checks and independent power-layout review control the final package; routing success does not qualify analog behavior.

| Choice | Why it exists | Q3 action / cost decision |
|---|---|---|
| Four layers | Q1 compact routing and internal ground planes | Two-layer routing implemented. Quote this construction. Do not compare different assembly scopes as a layer saving. |
| Mixed-side SMT | Q1 fit beneath the raised glass and keys | MCU and connectors moved to the bottom, so all SMT can use one reflow pass. OLED/key manual soldering remains vendor scope. Portal assembly-side labels may not map directly to reflow passes; obtain actual pricing. |
| Custom passive LCD sourcing | Arbitrary original display selection, low-power aim | Replace with exact stocked JLC OLED. Compare the complete display circuit and FPC assembly cost, not just the cheaper display price. Runtime must be re-budgeted. |
| External temperature window | Limits charging to the cell's temperature range | Retain. Directly connecting the existing 10k/B3380 sensor to the charger gives about 1.4–60.1°C nominal and may permit charging to about 65°C with tolerances. That does not meet the intended cell range. See the Q3 power review. |
| 48-pin LCD-capable MCU | FRAM persistence plus direct passive-LCD drive | OLED no longer uses the LCD peripheral. A smaller FRAM MCU could reduce area/part cost but needs exact stock, pin mapping and firmware review. Do not silently substitute based on package price alone. |
| ENIG finish and high-Tg FR4 | Fine-pitch assembly assumptions | Ask whether standard material/lead-free HASL are accepted for the actual fine-pitch parts; show any cheaper quote as an explicit process alternative. Do not assume an unqualified finish is interchangeable. |
| Clicky MX switches | Familiar clicky behavior and standard removable caps | Select HanElectricity CPG151101D13 at live JLC $0.107 each (1+), with 14,501 in stock. The old Cherry part is unavailable. Exact lands/plate retention and 220k pull-ups are revised with it. This is a manufacturer change; physical feel and fit remain first-article checks. |
| 1 mm PCB | Low mass | Retain a mechanically supported board; thicker standard stock might cost less but adds mass and changes clip fit. Price only if material to the quote. |
| Custom cell/NTC harness | Rechargeable coin cell, insulation and temperature sensing with no customer soldering | Pack preparation, genuine cell, sensor attachment and keyed plug remain full assembly scope. Compare an existing approved pack only with chemistry, fit and thermal evidence. |
| First-article test/fixture charges | Verify power, charging, protection, retention and assembly | Separate one-time engineering/fixture costs from recurring unit tests. At five/ten units these can dominate the bare-board price. Preserve essential safety/functional tests. |

## Cost consequence of the display replacement

The supported-stock OLED simplifies signal routing, but it **adds power-circuit parts**. Q2 had50fitted PCB references; Q3 has70. The OLED needs its own regulated4V input, power isolation and pump capacitors. Its low module price therefore does not prove a cheaper complete device. Compare the actual component and assembly totals against the layer/reflow savings. A future smaller MCU or display with integrated power support is a separate cost reduction, requiring confirmed supply, electrical review and firmware changes; neither is claimed here.

## Pricing evidence already available

Historical **Q2** portal estimates were incomplete: PCBWay PCB-only $55.93/5 and $81.36/10, plus assembly $88/$102.95 before components and advanced services. JLCPCB PCB-only $32.41/5 and $39.81/10, assembly/components unquoted; its ten-board subtotal included $17.60 ENIG. These are not Q3 prices or a reliable layer-saving comparison.

The concrete Q3 quote must itemize PCB, components, FPC and key soldering, one/two SMT passes, tooling, firmware, test setup versus per-unit work, battery/harness, packaging and delivered costs. Cost options are design decisions to examine, not new user requirements or permission to weaken qualification.

## Implemented stock-driven choices

All 43 distinct fitted PCB MPNs have positive native JLC stock evidence in [the live record](../procurement/q3/live-stock-2026-09-15.json). Several resistors now use equivalent stocked UNI-ROYAL parts; the 2.2 µF capacitors share one stocked Murata identity. The 22 µF OLED power capacitors use Samsung's current CL21A226MAYNNNE, avoiding its NRND predecessor and the original 43-piece minimum. Selected parts still require final PCBA matching and attrition checks. These observations are not stock reservations or complete quotes.

C13 changes from KEMET X7R to Murata GRM1885C1H472JA01D / C85980, retaining 4.7 nF, 50 V, ±5%, 0603 and improving temperature/bias stability with C0G. Live stock was 7,690, available3,183, MOQ1. The [Murata manufacturer list](https://www.murata.com/-/media/webrenewal/tool/library/common-pdf/static-model/component-list-s-mlcc-2506.ashx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) confirms the family specification. The nominal charger compensation is unchanged; low-current charge-loop stability still needs measurement.

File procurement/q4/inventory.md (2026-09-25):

# Q4 inventory research — 24 September 2026

**All 70 fitted positions / 38 exact types in the bound Q4 model pass the ten-board inventory screen.** The machine-readable [stock record](stock.json) contains 64 JLC exact-code observations from fresh, read-only Chrome views of JLCPCB's public catalog, between 24 September 23:36 and 25 September 00:17 UTC, plus a separate fresh LCSC retail check at 00:20 UTC. These are displayed orderable quantities, not reserved stock or vendor acceptance of a board, footprint or assembly process.

The user has paused all vendor contact and quotation activity. No quote form, cart, private parts library, paid sourcing, order or vendor message was changed during this research. No money or manufacture is authorized. Previous Q1–Q3 records remain historical.

## Main candidates and retained critical parts

Parts-only USD prices exclude board fabrication, assembly, feeder charges, attrition, shipping, tax, testing and programming. “At 10” reports the applicable displayed price tier; it does not override the available quantity. Each timestamp and source is in the JSON.

| Exact MPN / catalog source | Available / minimum | USD each at 1 / 10 | Engineering and sourcing status |
|---|---:|---:|---|
| [STM32L072CBT6 / C465977](https://jlcpcb.com/partdetail/C465977) | 2,160 / 1 | 3.3218 / 2.7874 | Selected MCU; LQFP-48, factory USB bootloader facts are separately reviewed. |
| [HS96L01W4S03 / C5139758](https://jlcpcb.com/partdetail/C5139758) | 524 / 1 | 2.2968 / 1.8274 | Selected seven-pin SPI OLED module, currently home-fitted. Catalog says Wave Soldering and High Assembly Difficulty. |
| [TLV76701DRVR / C2863998](https://jlcpcb.com/partdetail/C2863998) | 12,740 / 1 | 0.2676 / 0.2676 | Selected precision adjustable LDO with 150k/49.9k divider; board transient qualification remains open. |
| [TPS7A2401DBVR / C2693328](https://jlcpcb.com/partdetail/C2693328) | 4,915 / 1 | 0.2687 / 0.2687 | Earlier 3.15 V candidate, superseded by TLV76701DRVR after the rail corner review. |
| [TPS7A0331PDBVR / C3748940](https://jlcpcb.com/partdetail/C3748940) | 159 / 1 | 0.4614 / 0.3688 | Exact TI part is 3.1 V despite JLC's incorrect 3.3 V attribute. Fixed-rail USB margin and module capacitance make this a reviewed alternative, not an automatic selection. |
| [TPS22917DBVR / C2681320](https://jlcpcb.com/partdetail/C2681320) | 15,133 / 1 | 0.3538 / 0.3538 | Selected controlled-slew load switch. Its reverse blocking specification is not an ideal-diode guarantee. |
| [FM25CL64B-GTR / C9830](https://jlcpcb.com/partdetail/C9830) | 2,888 / 1 | 3.6174 / 3.2308 | Unselected 8 KiB SPI FRAM alternative. Power rise/fall conditions still require an engineering solution. |
| [FM25V02A-GTR / C66029](https://jlcpcb.com/partdetail/C66029) | 19,137 / 1 | 3.8773 / 3.4907 | Selected 32 KiB SPI FRAM with controlled power ramps and sleep mode; physical ramp limits remain open. |
| [USB4105-GF-A-120 / C5184243](https://jlcpcb.com/partdetail/C5184243) | 4,360 / 1 | 0.9129 / 0.7180 | Selected 1.20 mm stake option. Planar drawing comparison passed; actual board thickness, protrusion, fillets and retention remain first-article checks. High Assembly Difficulty. |
| [DMN2056U-13 / C5208862](https://jlcpcb.com/partdetail/C5208862) | 189 / 1 | 0.1487 / 0.1487 | Selected alternate reel ordering of the same Diodes transistor family; circuit qualification remains governed by the hardware review. |
| [0603WAF1622T5E / C22885](https://jlcpcb.com/partdetail/C22885) | 89,774 / 1 | 0.0014 / 0.0014 | 16.2 kΩ, 1%, 0603, 100 mW, ±100 ppm/°C selected for R13. Preserve thermal error budget. |
| [TLV7012DGKR / C2859969](https://jlcpcb.com/partdetail/C2859969) | 21 / 1 | 1.1712 / 0.9730 | Retained comparator has the narrowest stock cushion. Ten plus two screening spares fits; allocation is unreserved. |
| [BQ25185DLHR / C19725033](https://jlcpcb.com/partdetail/C19725033) | 4,043 / 1 | 1.7283 / 1.4652 | Retained charger. |
| [BQ29700DSER / C183096](https://jlcpcb.com/partdetail/C183096) | 2,499 / 1 | 0.6595 / 0.5166 | Retained protector. |
| [CPG151101D13 / C49234235](https://jlcpcb.com/partdetail/C49234235) | 13,808 / 1 | 0.1068 / 0.1068 | Retained exact key switch; two per board. |

Every fitted identity, reference group and assembly role is bound by the canonical `fitted_identity_sha256` in the JSON. The removed R34/R35/C37 are excluded; H3/H4 are non-purchased PCB features. The full-model binding was refreshed after final placement/routing freeze; its current SHA is recorded in `screening_plan.final_model_sha256`. Refresh it after any model change. These are the same saved catalog observations, not a new live stock check. Researched alternatives remain separately marked and are not silently included in the selected BOM. The separate display header is screened as stacked hardware, not a second native component footprint.

## Source details and qualification boundaries

- **OLED:** The [manufacturer document linked by LCSC](https://datasheet.lcsc.com/datasheet/pdf/c5dd235441558974950f13e140069537.pdf?productCode=C5139758) is internally inconsistent: prose says 26 × 26 × 2.62 mm and SSD1306, but its page-6 HS96L01xxx03 mechanical drawing (revision A1, 6 July 2019) says **27.30 × 27.80 mm PCB and SSD1315**. Use the drawing for the engineering envelope and retain the source conflict as a qualification gate. It gives 23.30 × 23.80 mm mounting-hole spacing, Ø2.50 mm holes, PCB thickness 1.20 mm, approximately 1.40 mm above and 1.00 mm below (approximately 3.60 mm total), and a 7 × 2.54 mm terminal row 1.50 mm from the top edge (the 1.32 mm dimension is a horizontal LCD inset). Horizontal centering of this row is a nominal inference, not an explicitly dimensioned first-pin offset. The 128 × 64 active area is 21.74 × 10.86 mm, with its lower edge 10.57 mm above the module PCB bottom: its center is 2.10 mm above the module center. These dimensions were corrected after reviewing the drawing upright. Its seven terminals are GND, VCC, SCL, SDA, RES, DC, CS. The freshly viewed JLC rear photograph is explicitly labelled HS96L01W4S03 and shows seven bare plated holes and four corner mounts, consistent with the broad drawing layout. The photograph cannot establish exact dimensions or whether a loose header is included; no fitted header is shown. SCL/SDA are the module's SPI clock/data naming here. Page 8 provides connection/strap information rather than a complete internal schematic. The document's module supply, panel supply and logic tables must be reconciled by the circuit review; do not infer that a catalog “3–5 V” entry proves low-end supply operation or that the maximum all-on current predicts sparse-counter consumption.
- **LDO and switch:** Primary TI datasheets are [TPS7A24](https://www.ti.com/lit/ds/symlink/tps7a24.pdf), [TPS7A03](https://www.ti.com/lit/ds/symlink/tps7a03.pdf), and [TPS22917](https://www.ti.com/lit/ds/symlink/tps22917.pdf). The [exact TPS7A0331 ordering page](https://www.ti.com/product/TPS7A03/part-details/TPS7A0331PDBVR) controls the output identity, not the catalog's inconsistent parameter. No exact stocked TPS7A0332 or TPS7A03315 variant was established.
- **FRAM:** [FM25CL64B primary datasheet](https://www.infineon.com/assets/row/public/documents/10/49/infineon-fm25cl64b-64-kbit-8-k-8-serial-spi-f-ram-datasheet-en.pdf) requires at least 30 µs/V rise and fall time at any point. [FM25V02A primary datasheet](https://www.infineon.com/assets/row/public/documents/10/49/infineon-fm25v02a-256-kbit-32k-8-serial-spi-f-ram-datasheet-en.pdf) requires 50 µs/V rise and 100 µs/V fall. These conditions, brownout write inhibition, startup access guards and board-level faults matter more than headline endurance. Catalog inventory alone does not qualify either memory.
- **USB:** [GCT's USB4105 drawing](https://gct.co/files/drawings/usb4105.pdf) and [family page](https://gct.co/connector/usb4105) control pin/stake geometry. The stocked [USB4105-GF-A-060 / C3025063](https://jlcpcb.com/partdetail/C3025063) alternative has 716 orderable, but its shorter stake is not an automatically equivalent assembly choice.
- **FET:** [Diodes' DMN2056U datasheet](https://www.diodes.com/assets/Datasheets/DMN2056U.pdf) controls SOT-23 pin 1 gate / 2 source / 3 drain, low-gate-voltage on-resistance and reel ordering. Preserve the opposing protection body diodes and battery/protection gates when implementing an exact ordering suffix change.

## Negative and insufficient candidates

- NCP170BXV310T2G / C894979: zero stock; preorder minimum 67. Not a current-stock solution.
- FM25CL64B-GTR / C2061806: zero stock / consignment option. This is a separate catalog entry from stocked **C9830**; neither entry's state should be generalized to the other.
- CY15B064Q-SXET / C22442778: one orderable. Its advertised ten-piece price does not make ten available.

## Final screening method

The bound screen groups fitted positions by exact MPN and compares ten boards' requirement plus **max(2, ceiling(10% of fitted quantity))** extra against the catalog's available quantity and minimum order. This is a conservative research allowance, not a vendor-confirmed attrition quantity or a purchase request. All 38 exact fitted types pass this allowance. Refresh shortages, changed identities or quantities and the model hash; all assembly, electrical, battery, USB and mechanical qualification gates remain open as documented by the engineering review.

## Separate header and recovery switch

The exact **XFCN PZ254V-11-07P / C492406** header has 51,053 orderable, minimum one, USD 0.0455 at one or ten. The [manufacturer drawing](https://datasheet.lcsc.com/datasheet/pdf/3b85a1cdf6ed945f2e278f00c1e42442.pdf?productCode=C492406) specifies seven 0.64 mm square pins, 2.54 ±0.05 mm pitch, 15.24 mm terminal span, 17.78 ×2.50 ×2.50 mm insulator, 6.1 ±0.2 mm long ends and 3.0 ±0.2 mm solder ends. It recommends Ø1.02 mm PCB holes. Its function is the physical interposer for DS1's terminal row; account for its height, clipping/fillet process and offboard assembly exactly once. A loose header supplied with the OLED has not been established. Catalog assembly is Wave Soldering; the specific stacked assembly remains unaccepted by either vendor while contact is paused.

The selected **XUNPU TS-1088-AR02016 / C720477** recovery switch has 902,842 orderable, minimum one, USD 0.0537 at one or ten. The [manufacturer drawing](https://datasheet.lcsc.com/datasheet/pdf/0475ac02febf455ca9ddcfb380b0df0d.pdf?productCode=C720477) gives a 3.90 ×3.00 mm body, 5.00 mm lead span, Ø1.80 mm actuator, 2.00 mm height for the 020 suffix, and 0.20 ±0.10 mm travel. It is a two-terminal normally-open SPST: pin 1 left, pin 2 right in top view. Recommended lands are 1.05 ×2.00 mm centered at x=±2.225 mm, y=0. The pinhole and switch actuation fit still need a first-article check.

## Additional regulator screen, 25 September UTC

The bound model now selects [TLV76701DRVR / C2863998](https://jlcpcb.com/partdetail/C2863998), which has **12,740 available**, minimum one, USD 0.2676 at one or ten (fresh 00:12:08 UTC). The [TI datasheet](https://www.ti.com/lit/ds/symlink/tlv767.pdf) controls its adjustable output, accuracy, output capacitance and startup requirements. The selected 150k/49.9k divider and calculated voltage corners are controlled by the power review. Physical transients and sleep consumption remain to be measured. Refresh the fitted-BOM binding after any further selection changes.

[LP5907MFX-3.2/NOPB / C2832238](https://jlcpcb.com/partdetail/C2832238) has 58 available, minimum one, USD 0.5020/one and 0.3996/ten. Its [TI specification](https://www.ti.com/lit/ds/symlink/lp5907.pdf) gives ±2% DC tolerance at the stated input/load conditions; this is not an automatic startup-overshoot guarantee below the OLED logic maximum. [XC6220B321MR-G / C7393027](https://jlcpcb.com/partdetail/C7393027) has 50 available, minimum one, USD 0.9227/one and 0.9015/ten, but the [Torex table](https://product.torexsemi.com/system/files/series/xc6220.pdf) gives its accuracy at 25°C, wider power-save accuracy and only a typical temperature coefficient. Neither was accepted as a fully bounded replacement. Exact TPS7A2032PDBVR / C2877862 has only one available, despite quantity price breaks; it fails the ten-board stock screen.

The selected precision divider also has sufficient fresh stock: [RT0603BRD07150KL / C326734](https://jlcpcb.com/partdetail/C326734) has 14,908 available, minimum one, USD 0.0433 at one or ten; [RT0603BRD0749K9L / C705780](https://jlcpcb.com/partdetail/C705780) has 102,599 available, minimum one, USD 0.0381 at one or ten. Exact [150k Yageo specification](https://yageogroup.com/component-documentation/download/specsheet/RT0603BRD07150KL) and [49.9k Yageo specification](https://yageogroup.com/component-documentation/download/specsheet/RT0603BRD0749K9L) confirm 0603, 0.1%, ±25ppm/°C and 0.1W at 70°C. Their circuit selection is controlled by the Q4 model and power review, not stock alone.

## Current bound assembly split

The updated model contains **86 references: 70 fitted positions and 16 PCB features**, using 38 exact fitted MPNs. Every fitted MPN passes the ten-board plus screening-spares comparison. The model classifies 67 positions for JLC assembly and DS1/SW1/SW2 as three home-fitted through-hole parts. The separate seven-pin interposer is additional hardware. **JLC parts-library inventory is reserved for PCBA and cannot be shipped as loose components**; the separate LCSC retail check below establishes an available loose-parts sourcing path. Availability remains unreserved and shipping/tax totals are unquoted. No paid sourcing, vendor contact, quote update or order has occurred.

The final selected changes in this binding are TLV76701DRVR / C2863998, 150k RT0603BRD07150KL / C326734, 49.9k RT0603BRD0749K9L / C705780, and USB4105-GF-A-120 / C5184243. The USB-120's earlier fresh detail observation gives 4,360 orderable. The -060 alternative remains historical research, rather than the selected assembly. See `docs/review-native-footprints-Q4.md` for its distinct stake-height implication.

## Loose home-assembly parts — fresh LCSC retail check

Read-only public retail pages checked 25 September 2026, 00:20:25–00:20:59 UTC. All three exact identities display **“In stock, ships now”**. No cart, quotation, account, vendor-contact or purchase action was taken. This is separate evidence from JLC's PCBA-only library.

| Exact part | Retail stock | Minimum / multiple | Displayed promotional unit price at 10 | Ten-board screening quantity including spares, rounded to pack |
|---|---:|---:|---:|---:|
| [HS96L01W4S03 / C5139758](https://www.lcsc.com/product-detail/C5139758.html), one display each |526|1 /1|USD 1.6962|12|
| [CPG151101D13 / C49234235](https://www.lcsc.com/product-detail/C49234235.html), two key switches each |13,620|5 /5|USD 0.1021|25 (20 fitted plus five spares after rounding)|
| [PZ254V-11-07P / C492406](https://www.lcsc.com/product-detail/C492406.html), one interposer each |50,550|10 /10|USD 0.0438|20 (10 fitted plus ten after pack rounding)|

The display one-piece promotional price is USD 2.1320. Switches cannot be ordered singly at this listing (minimum five); headers require a ten-pack. The displayed original, pre-discount ten-piece prices are respectively USD 1.8437, 0.1074 and 0.0461. Promotions may change; these are parts-only observations, not fixed totals. The site also displays a 25 September–7 October holiday service-adjustment notice, so “ships now” stock is not a verified dispatch or arrival date.

This resolves the previously unverified **retail availability** of these three home-assembly identities. It does not resolve module source inconsistencies, header/plate fit, solder sequence, user workmanship, battery/harness sourcing or complete delivered-order cost. If a later authorized assembler instead fits DS1 and its header, the same hardware must be counted once and that process must be explicitly agreed; no such change or outreach occurred here.

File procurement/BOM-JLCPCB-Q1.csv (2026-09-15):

Comment | Designator | Footprint | Quantity | Manufacturer | Manufacturer Part Number | Assembly | Notes | Source Label | LCSC Part #
DE188-RU-30/7,5/V(3V) | DS1 | ClickCounter:DE188_20P_34.9x13mm | 1 | Display Elektronik | DE188-RU-30/7,5/V(3V) | top | THT hand solder; glass rear 4.0 mm above PCB top; 260 C / 5 s maximum; quote-only display, sample qualification required | DE188-RU-30/7,5/V(3V)
MX1A-E1NW | SW1 | Button_Switch_Keyboard:SW_Cherry_MX_1.00u_PCB | 1 | Cherry | MX1A-E1NW | top | Clicky blue; PCB-mount 5-pin solder version; full hand solder | COUNT | C5120587
MX1A-E1NW | SW2 | Button_Switch_Keyboard:SW_Cherry_MX_1.00u_PCB | 1 | Cherry | MX1A-E1NW | top | Same switch as SW1 | RESET | C5120587
USB4105-GF-A | J1 | Connector_USB:USB_C_Receptacle_GCT_USB4105-xx-A_16P_TopMnt_Horizontal | 1 | GCT | USB4105-GF-A | top | 0.95 mm standard stakes; D+/D-/SBU unconnected; shell grounded | USB-C charge | C3020560
SM04B-SRSS-TB(LF)(SN) | J2 | Connector_JST:JST_SH_SM04B-SRSS-TB_1x04-1MP_P1.00mm_Horizontal | 1 | JST | SM04B-SRSS-TB(LF)(SN) | top | Mating keyed custom pack CC-BAT-001; no bare coin-cell holder | Battery + NTC | C160404
MSP430FR4133IG48R | U1 | Package_SO:TSSOP-48_6.1x12.5mm_P0.5mm | 1 | Texas Instruments | MSP430FR4133IG48R | top | 48-pin TSSOP, not the earlier 64-pin draft; SBW program and verify | MSP430FR4133 | C2053877
BQ25185DLHR | U2 | Package_DFN_QFN:Texas_DLH0010A_WSON-10-1EP_2.2x2mm_P0.4mm_EP0.9x1.5mm | 1 | Texas Instruments | BQ25185DLHR | bottom | 4.2 V; 100 mA input limit; 18.2 mA nominal battery charge | Li-ion charger | C19725033
TPS7A0230DBVR | U3 | Package_TO_SOT_SMD:SOT-23-5 | 1 | Texas Instruments | TPS7A0230DBVR | bottom |  | 3.0 V LDO
BQ29700DSER | U4 | Package_SON:WSON-6_1.5x1.5mm_P0.5mm | 1 | Texas Instruments | BQ29700DSER | bottom |  | Cell protector | C183096
DMN2056U-7 | Q1 | Package_TO_SOT_SMD:SOT-23 | 1 | Diodes Incorporated | DMN2056U-7 | bottom |  | Discharge FET | C332302
DMN2056U-7 | Q2 | Package_TO_SOT_SMD:SOT-23 | 1 | Diodes Incorporated | DMN2056U-7 | bottom |  | Charge FET | C332302
TLV7042DGKR | U5 | Package_SO:VSSOP-8_3x3mm_P0.65mm | 1 | Texas Instruments | TLV7042DGKR | bottom | USB-powered independent conservative charge-temperature window | Charge temperature window | C2760466
2N7002 | Q3 | Package_TO_SOT_SMD:SOT-23 | 1 | Nexperia | 2N7002 | bottom |  | Charge enable
USBLC6-2SC6 | D1 | Package_TO_SOT_SMD:SOT-23-6 | 1 | STMicroelectronics | USBLC6-2SC6 | bottom |  | USB ESD | C7519
RC0603FR-075K1L | R1 | Resistor_SMD:R_0603_1608Metric | 1 | Yageo | RC0603FR-075K1L | bottom | 1%, 0603, 0.1 W | 5.1k
RC0603FR-075K1L | R2 | Resistor_SMD:R_0603_1608Metric | 1 | Yageo | RC0603FR-075K1L | bottom | 1%, 0603, 0.1 W | 5.1k
RC0603FR-0724KL | R3 | Resistor_SMD:R_0603_1608Metric | 1 | Yageo | RC0603FR-0724KL | bottom | 1%, 0603, 0.1 W | 24k
RC0603FR-0716K5L | R4 | Resistor_SMD:R_0603_1608Metric | 1 | Yageo | RC0603FR-0716K5L | bottom | 1%, 0603, 0.1 W | 16.5k
RC0603FR-0710KL | R5 | Resistor_SMD:R_0603_1608Metric | 1 | Yageo | RC0603FR-0710KL | bottom | 1%, 0603, 0.1 W | 10k
RC0603FR-07100KL | R6 | Resistor_SMD:R_0603_1608Metric | 1 | Yageo | RC0603FR-07100KL | bottom | 1%, 0603, 0.1 W | 100k
RC0603FR-07330RL | R7 | Resistor_SMD:R_0603_1608Metric | 1 | Yageo | RC0603FR-07330RL | bottom | 1%, 0603, 0.1 W | 330
RC0603FR-072K2L | R8 | Resistor_SMD:R_0603_1608Metric | 1 | Yageo | RC0603FR-072K2L | bottom | 1%, 0603, 0.1 W | 2.2k
RC0603FR-073R3L | R9 | Resistor_SMD:R_0603_1608Metric | 1 | Yageo | RC0603FR-073R3L | bottom | 1%, 0603, 0.1 W | 3.3
RC0603FR-0710KL | R10 | Resistor_SMD:R_0603_1608Metric | 1 | Yageo | RC0603FR-0710KL | bottom | 1%, 0603, 0.1 W | 10k
RC0603FR-0749K9L | R11 | Resistor_SMD:R_0603_1608Metric | 1 | Yageo | RC0603FR-0749K9L | bottom | 1%, 0603, 0.1 W | 49.9k
RC0603FR-0740K2L | R12 | Resistor_SMD:R_0603_1608Metric | 1 | Yageo | RC0603FR-0740K2L | bottom | 1%, 0603, 0.1 W | 40.2k
RC0603FR-0760K4L | R13 | Resistor_SMD:R_0603_1608Metric | 1 | Yageo | RC0603FR-0760K4L | bottom | 1%, 0603, 0.1 W | 60.4k
RC0603FR-07100KL | R14 | Resistor_SMD:R_0603_1608Metric | 1 | Yageo | RC0603FR-07100KL | bottom | 1%, 0603, 0.1 W | 100k
RC0603FR-071ML | R15 | Resistor_SMD:R_0603_1608Metric | 1 | Yageo | RC0603FR-071ML | bottom | 1%, 0603, 0.1 W | 1M
RC0603FR-0747KL | R16 | Resistor_SMD:R_0603_1608Metric | 1 | Yageo | RC0603FR-0747KL | bottom | 1%, 0603, 0.1 W | 47k
RC0603FR-07470KL | R17 | Resistor_SMD:R_0603_1608Metric | 1 | Yageo | RC0603FR-07470KL | bottom | 1%, 0603, 0.1 W | 470k
RC0603FR-07470KL | R18 | Resistor_SMD:R_0603_1608Metric | 1 | Yageo | RC0603FR-07470KL | bottom | 1%, 0603, 0.1 W | 470k
RC0603FR-072KL | R19 | Resistor_SMD:R_0603_1608Metric | 1 | Yageo | RC0603FR-072KL | bottom | 1%, 0603, 0.1 W | 2k
GRM188R71H104KA93D | C4 | Capacitor_SMD:C_0603_1608Metric | 1 | Murata | GRM188R71H104KA93D | bottom | 100 nF, 50 V, X7R | 100n
GRM188R71H104KA93D | C7 | Capacitor_SMD:C_0603_1608Metric | 1 | Murata | GRM188R71H104KA93D | bottom | 100 nF, 50 V, X7R | 100n
GRM188R71H104KA93D | C8 | Capacitor_SMD:C_0603_1608Metric | 1 | Murata | GRM188R71H104KA93D | bottom | 100 nF, 50 V, X7R | 100n
GRM188R71H104KA93D | C9 | Capacitor_SMD:C_0603_1608Metric | 1 | Murata | GRM188R71H104KA93D | bottom | 100 nF, 50 V, X7R | 100n
GRM21BR71E225KA73L | C1 | Capacitor_SMD:C_0805_2012Metric | 1 | Murata | GRM21BR71E225KA73L | bottom | 2.2 uF, 25 V, X7R; effective >=1 uF at 5 V | 2.2u
GRM21BR61E106KA73L | C2 | Capacitor_SMD:C_0805_2012Metric | 1 | Murata | GRM21BR61E106KA73L | bottom | 10 uF, 25 V, X5R; effective >=1 uF at 4.5 V | 10u
GRM21BR71E225KA73L | C3 | Capacitor_SMD:C_0805_2012Metric | 1 | Murata | GRM21BR71E225KA73L | bottom | 2.2 uF, 25 V, X7R | 2.2u
GRM21BR71E225KA73L | C5 | Capacitor_SMD:C_0805_2012Metric | 1 | Murata | GRM21BR71E225KA73L | bottom |  | 2.2u
GRM21BR71E225KA73L | C6 | Capacitor_SMD:C_0805_2012Metric | 1 | Murata | GRM21BR71E225KA73L | bottom |  | 2.2u
GRM1885C1H102JA01D | C10 | Capacitor_SMD:C_0603_1608Metric | 1 | Murata | GRM1885C1H102JA01D | bottom | 1 nF, 50 V, C0G | 1n
GRM1885C1H102JA01D | C11 | Capacitor_SMD:C_0603_1608Metric | 1 | Murata | GRM1885C1H102JA01D | bottom | 1 nF, 50 V, C0G | 1n
GRM1885C1H102JA01D | C12 | Capacitor_SMD:C_0603_1608Metric | 1 | Murata | GRM1885C1H102JA01D | bottom | 1 nF, 50 V, C0G | 1n
C0603C472J5RACTU | C13 | Capacitor_SMD:C_0603_1608Metric | 1 | KEMET | C0603C472J5RACTU | bottom | TI EVM low-current series compensation: ISET -> 2k -> 4.7n -> GND | 4.7n

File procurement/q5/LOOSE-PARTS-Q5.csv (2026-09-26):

Comment | Designator | Footprint | Quantity | Manufacturer | Manufacturer Part Number | LCSC Part # | Assembly Role | Side | Qualification | Notes
Clicky MX switch, plate mount (COUNT / POWER) | K1 | LOOSE_PART | 1 | HanElectricity | CPG151101D13 | C49234235 | user_presses_into_plate_and_SW1_socket | top | Catalog screened; retention in the printed plate/socket unqualified | Clip into the rear key plate, then press the plate and switches into the hot-swap sockets. No soldering.
Clicky MX switch, plate mount (RESET COUNT) | K2 | LOOSE_PART | 1 | HanElectricity | CPG151101D13 | C49234235 | user_presses_into_plate_and_SW2_socket | top | Catalog screened; retention in the printed plate/socket unqualified | Clip into the rear key plate, then press the plate and switches into the hot-swap sockets. No soldering.
M2 x 6 cross pan-head self-tapping screw (nickel) | SCREW1-SCREW4 | LOOSE_PART | 4 | Shuntian | PA2X6nie | C357360 | user_fits_enclosure |  | Catalog screened; thread strength in printed bosses unqualified | Through the lid-boss floor and PCB mounting holes into 1.7 mm base pilots. LCSC retail (not a JLC placement).

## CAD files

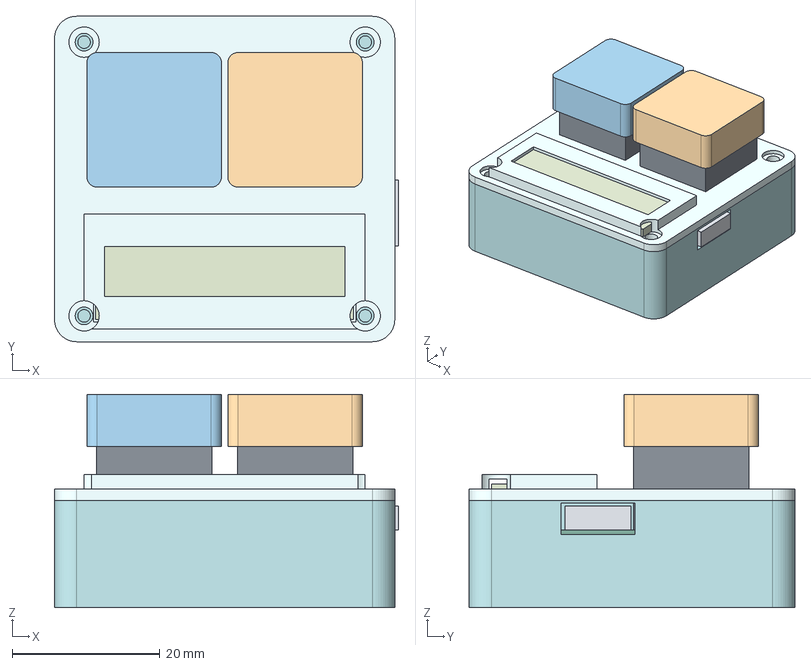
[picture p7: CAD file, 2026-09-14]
mechanical/fit-study.step
46.5 x 44.0 x 28.8 mm
base
lid
PCB-envelope
battery-envelope
LCD-envelope
USB-envelope
MCU-envelope
switch-1-envelope
switch-2-envelope
keycap-1-envelope
keycap-2-envelope

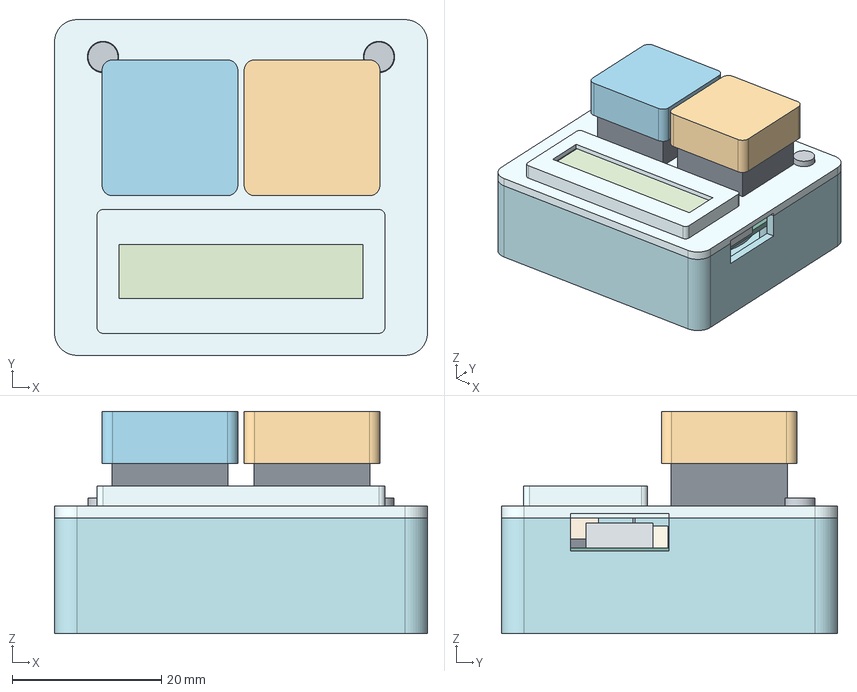
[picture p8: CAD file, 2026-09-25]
mechanical/q2/enclosure-Q2.step
50.0 x 45.0 x 29.8 mm
base
lid
battery-keeper
PCB
pack-envelope
LCD-glass
USB
MCU
JST
SW1-post-0
SW1-post-1
SW1-post-2
SW1-post-3
SW1-post-4
LCD-lead-1
LCD-lead-2
LCD-lead-3
LCD-lead-4
LCD-lead-5
LCD-lead-6
LCD-lead-7
LCD-lead-8
LCD-lead-9
LCD-lead-10
LCD-lead-11
LCD-lead-12
LCD-lead-13
LCD-lead-14
LCD-lead-15
LCD-lead-16
LCD-lead-17
LCD-lead-18
LCD-lead-19
LCD-lead-20
SW2-post-25
SW2-post-26
SW2-post-27
SW2-post-28
SW2-post-29
U3-envelope
C8-envelope
U4-envelope
U5-envelope
R7-envelope
C7-envelope
C11-envelope
R17-envelope
C14-envelope
Q4-envelope
C10-envelope
R13-envelope
R1-envelope
D1-envelope
C15-envelope
Q2-envelope
R3-envelope
C9-envelope
Q3-envelope
R15-envelope
C5-envelope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

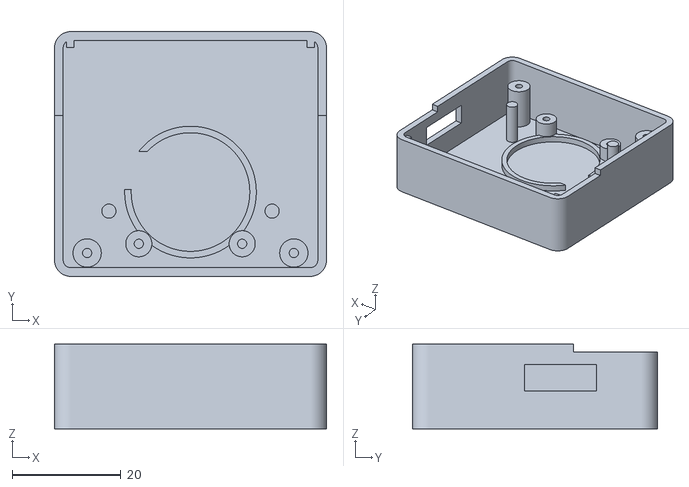
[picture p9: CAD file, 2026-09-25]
mechanical/q3/base-Q3.stl
50.0 x 45.0 x 15.6

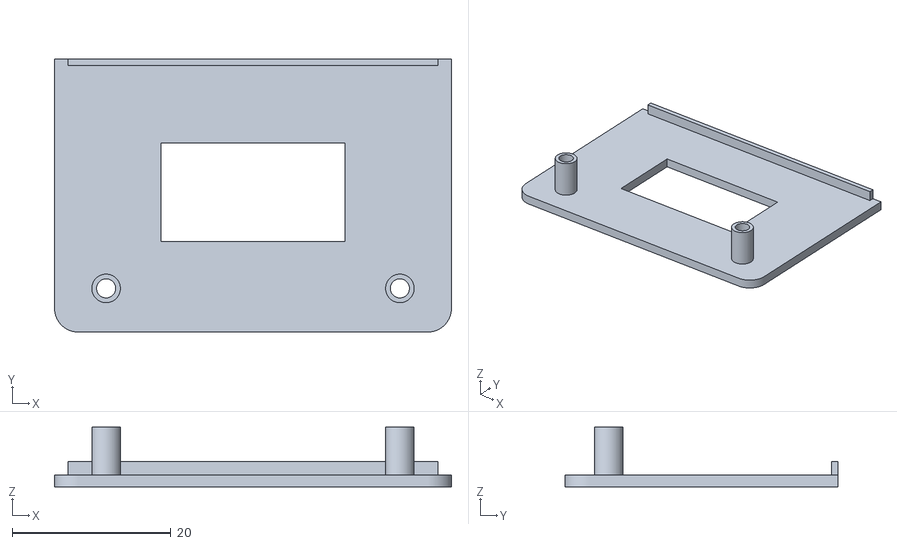
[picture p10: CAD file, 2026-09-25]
mechanical/q4/lid-front-Q4.stl
50.0 x 34.4 x 7.50

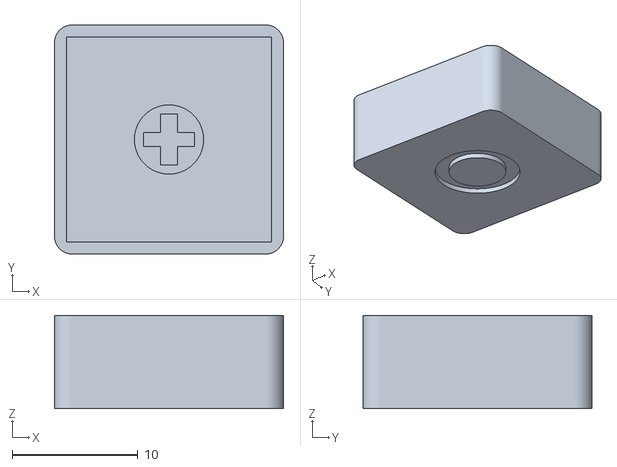
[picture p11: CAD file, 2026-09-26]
mechanical/q5/keycap-reset-Q5.stl
18.2 x 18.2 x 7.40

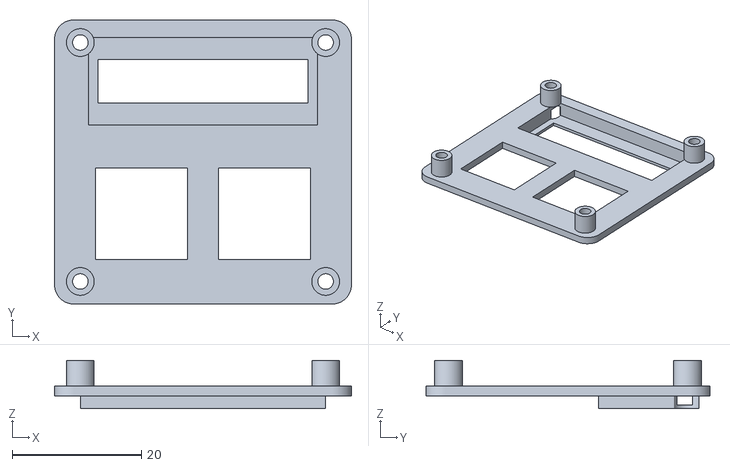
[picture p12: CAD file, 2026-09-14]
mechanical/lid-fit-study.stl
46.0 x 44.0 x 7.50

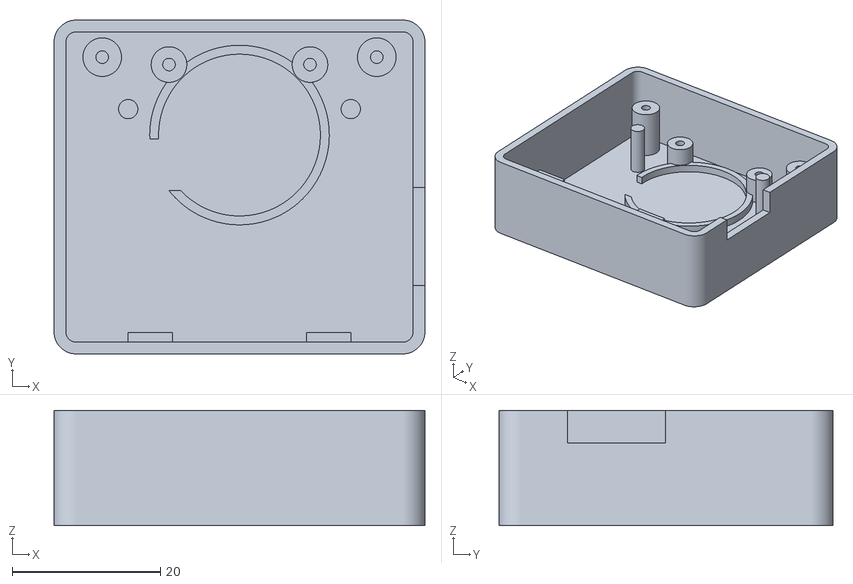
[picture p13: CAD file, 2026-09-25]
mechanical/q2/base-Q2.stl
50.0 x 45.0 x 15.5

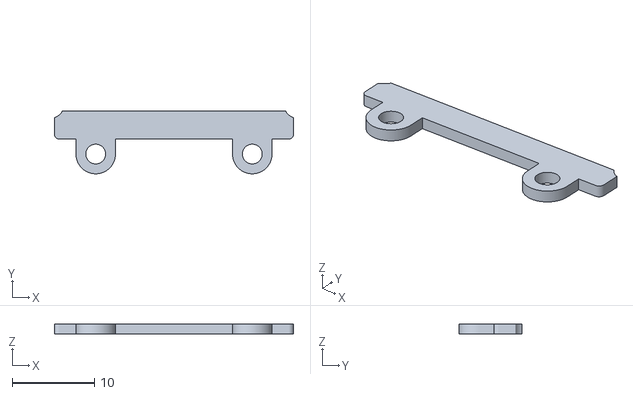
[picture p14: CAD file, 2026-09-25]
mechanical/q3/battery-keeper-Q3.stl
29.0 x 7.60 x 1.20

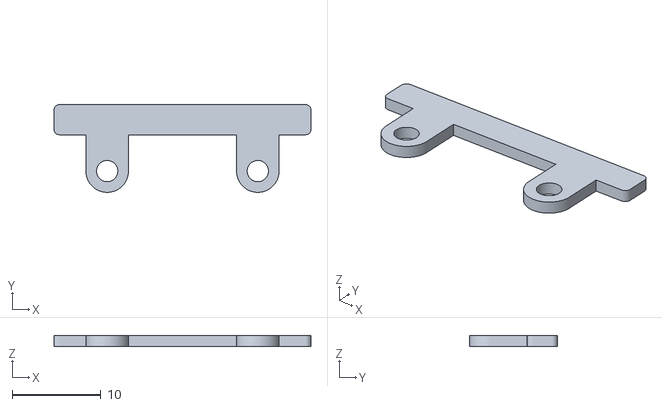
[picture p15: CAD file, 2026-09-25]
mechanical/q4/battery-keeper-Q4.stl
29.0 x 9.90 x 1.20

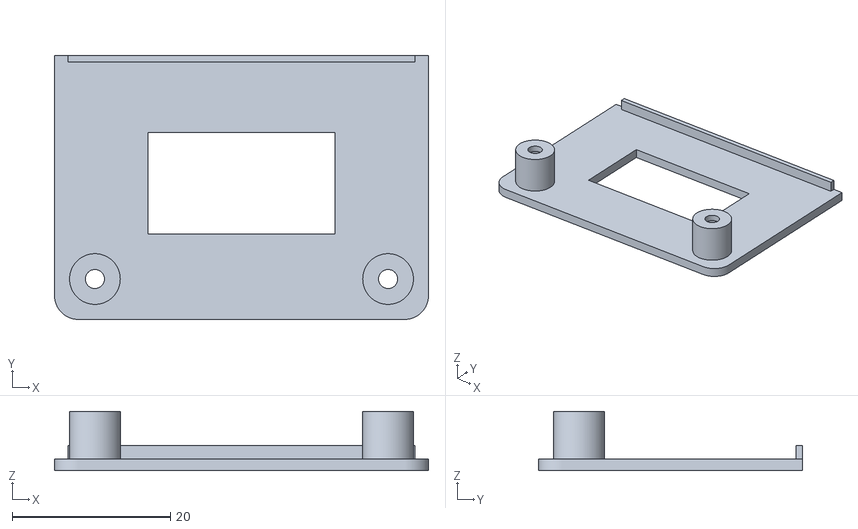
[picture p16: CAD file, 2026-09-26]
mechanical/q5/lid-front-Q5.stl
47.2 x 33.3 x 7.50

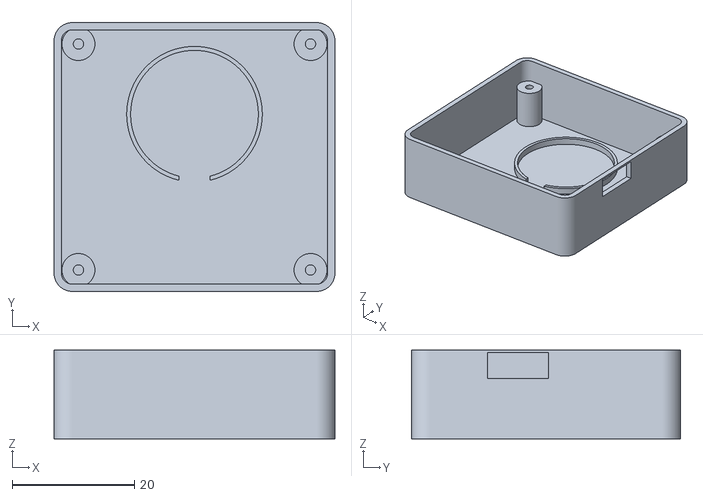
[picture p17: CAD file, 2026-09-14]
mechanical/base-fit-study.stl
46.0 x 44.0 x 14.5

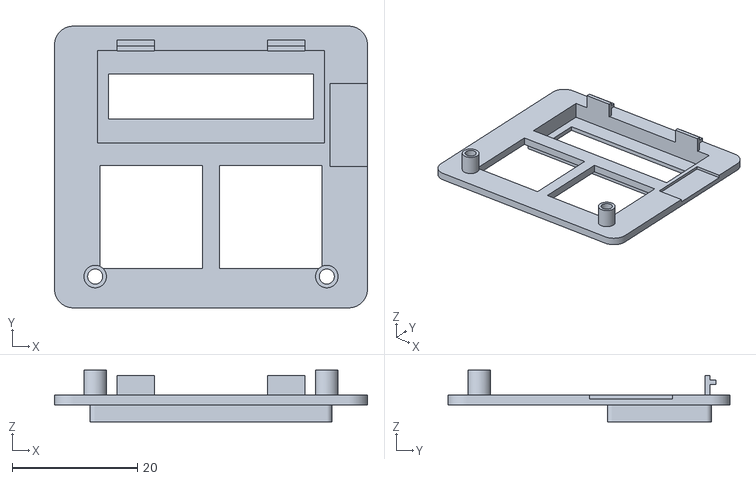
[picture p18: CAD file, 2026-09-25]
mechanical/q2/lid-Q2.stl
50.0 x 45.0 x 8.30

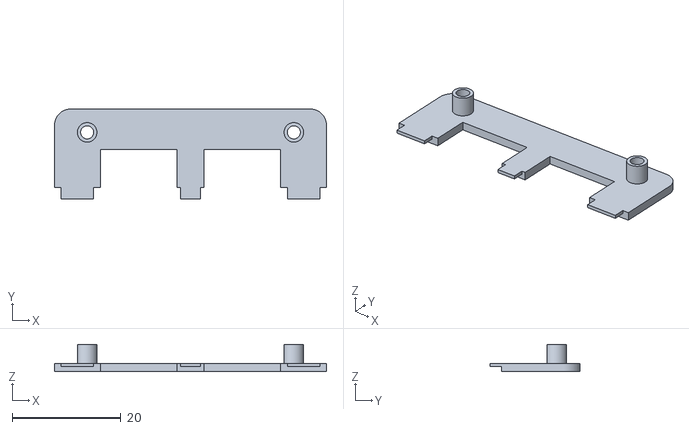
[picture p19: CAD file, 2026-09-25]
mechanical/q3/lid-rear-Q3.stl
50.0 x 16.6 x 5.00

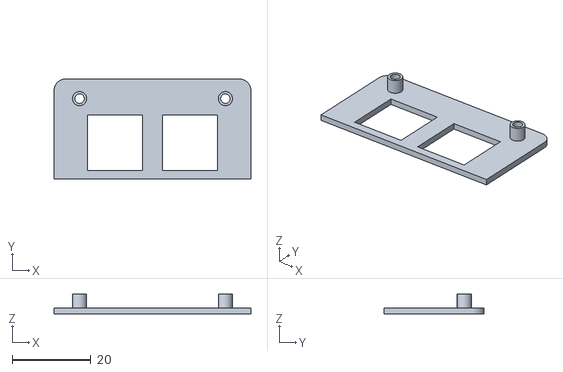
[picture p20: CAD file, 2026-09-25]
mechanical/q4/lid-rear-Q4.stl
50.0 x 25.4 x 5.00

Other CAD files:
mechanical/q5/base-Q5.stl
mechanical/q2/battery-keeper-Q2.stl
mechanical/q3/lid-front-Q3.stl
mechanical/q4/base-Q4.stl
mechanical/q3/enclosure-Q3.step
mechanical/q5/keycap-count-Q5.stl
mechanical/q5/lid-rear-Q5.stl
mechanical/q5/tolerance-coupon-Q5.stl

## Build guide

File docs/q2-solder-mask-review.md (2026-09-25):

# PCBWay solder-mask question: Q1 evidence and Q2 correction

Reviewed **2026-09-15**. PCBWay's incoming DFM question reports that green solder mask requires **at least 0.19 mm IC-pad spacing** to retain a mask bridge; its stated threshold for black/white, including matte variants, is **0.22 mm**. It asks whether the bridges can be omitted with a combined opening, or the spacing increased. **No permission, modified drawing acceptance or manufacturing release was sent during this review.**

The attached PNG was read through the authenticated email's raw MIME content, without browser access. It highlights the two middle pads on U5's right-hand row; its ruler reports **DX=0, DY=0.15, D=0.15 mm**. Component position and pad geometry identify these as bottom-side **U5 pins 6 (TEMP_HOT) and 7 (TEMP_OK)**. The image is one measured example; neither the image nor prose enumerates all affected components or bounds a proposed combined opening. It does not establish that PCBWay has already changed the files.

## Submitted Q1 geometry

In `electronics/click-counter-Q1.kicad_pcb`, U5 is the VSSOP-8 at **(17,7)**. Its pad row centers are **±2.1125 mm**, with **1.625 ×0.500 mm** lands at **0.650 mm pitch**. Pads 6 and 7 centers are respectively **(19.1125,6.675)** and **(19.1125,7.325)**. The nominal copper-edge gap is therefore **0.150 mm**, agreeing with the vendor image. Other adjacent lands in the same U5 row have the same gap.

The emitted `electronics/gerbers/click-counter-Q1-B_Mask.gbs` defines aperture **D20** at line 42, then uses it for U5 at lines 143–151. Its rounded-rectangle corner Y values ±0.125 and radius 0.125 produce a **0.500 mm** aperture height. At 0.650 mm pitch, the actual exported mask also retains **0.150 mm nominal webs**, using eight separate openings. Thus the vendor's proposal would change retained mask features, not merely acknowledge an existing combined opening. Actual fabricated registration/tolerances are not established by this nominal calculation.

## Manufacturer-supported Q2 option

The [TI TLV7032/42 RevJ datasheet](https://www.ti.com/lit/ds/symlink/tlv7032.pdf), **PDF page 63**, DGK0008A drawing **4214862/A (04/2023)**, gives an example of **eight 1.4 ×0.45 mm lands**, **0.65 mm pitch**, **4.4 mm row-center span** and **R0.05** corners. That yields **0.20 mm copper spacing**, above PCBWay's stated green-mask threshold. The matching stencil example is on PDF page 64. TI's preferred non-solder-mask-defined detail calls for **0.05 mm minimum mask clearance around a land** and notes that mask tolerances vary with fabrication site.

A Q2 footprint following that complete TI example would be better grounded than an arbitrary pad shrink. A width-only change to 0.45 mm would improve the nominal gap but retain Q1's different land length/row positions. **0.40 mm width is not the cited TI example.** Review routing, fillets, courtyard, mask and paste after any footprint change.

With 0.45 mm lands and 0.05 mm opening clearance on each side, nominal mask web is **0.10 mm**, not 0.20 mm. Obtain PCBWay's acceptance of the precise copper/mask/stencil geometry and its fabrication tolerance. If it instead proposes combined openings, require their exact scope and assembly review. This report does not approve blanket removal of IC mask bridges.

Q1 Gerbers and board remain unchanged and on engineering hold. The same DGK geometry review applies if the Q2 thermal circuit changes from TLV7042DGKR to TLV7032DGKR. All other electrical, thermal, cell, fit and first-article release gates remain open.

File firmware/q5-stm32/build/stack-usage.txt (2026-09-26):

app.c:9:6:app_input	8	static
app.c:18:6:app_fault	0	static
app.c:14:6:app_wake_press	16	static
app.c:19:6:app_settled	0	static
app.c:24:6:app_can_idle	8	static
app.c:27:6:app_storage_error	0	static
app.c:3:6:app_init	32	static
app.c:33:6:app_service	24	static
battery.c:3:6:battery_reset	8	static
battery.c:15:6:battery_sample	16	static
counter.c:12:6:counter_init	32	static
counter.c:27:10:counter_wake_press	0	static
counter.c:31:10:counter_sample	16	static
fram.c:3:13:exchange	16	static
fram.c:4:13:status	24	static
fram.c:14:13:read_word	104	static
fram.c:26:13:start_word	56	static
fram.c:34:17:complete	16	static
fram.c:5:6:fram_init	56	static
fram.c:35:7:fram_storage	0	static
fram.c:37:6:fram_available	0	static
fram.c:38:6:fram_sleep	32	static
fram.c:45:6:fram_wake	32	static
input.c:2:6:input_push	16	static
input.c:11:13:input_take	16	static
input.c:20:6:input_apply	32	static
journal.c:9:10:journal_crc	20	static
journal.c:18:6:journal_record_valid	16	static
journal.c:22:6:journal_load	80	static
journal.c:42:6:journal_begin	16	static
journal.c:51:6:journal_service	40	static
main_stm32.c:48:17:now	0	static
main_stm32.c:49:16:raw_buttons	0	static
main_stm32.c:54:13:power	0	static
main_stm32.c:58:13:reset	0	static
main_stm32.c:70:13:power_good	0	static
main_stm32.c:71:13:spi1_wait	16	static
main_stm32.c:185:13:bus_abort	0	static
main_stm32.c:215:22:bus_poll	8	static
main_stm32.c:78:13:fram_exchange	32	static
main_stm32.c:191:13:bus_start	24	static
main_stm32.c:100:13:storage_init	48	static
main_stm32.c:114:13:charger_inputs	8	static
main_stm32.c:59:6:panic	16	static
main_stm32.c:208:6:SPI2_IRQHandler	0	static
main_stm32.c:223:6:SysTick_Handler	16	static
main_stm32.c:231:6:EXTI0_1_IRQHandler	8	static
main_stm32.c:312:6:stop_from_ram	0	static
main_stm32.c:328:5:main	96	static
oled.c:68:13:glyphs_for	24	static
oled.c:89:13:fail	16	static
oled.c:96:13:send	24	static
oled.c:49:16:glyph_byte	40	static
oled.c:106:13:next_region	8	static
oled.c:72:9:oled_frame_byte	32	static
oled.c:76:9:oled_pixel_byte	16	static
oled.c:101:6:oled_init	16	static
oled.c:105:6:oled_is_off	0	static
oled.c:132:6:oled_service	80	static
rail.c:2:6:rail_invalid	0	static
rail.c:3:6:rail_sample	16	static
rail.c:14:6:rail_display_allowed	0	static
runtime.c:2:7:memset	0	static
runtime.c:3:7:memcpy	8	static
runtime.c:4:7:memmove	8	static
runtime.c:5:6:__aeabi_memcpy	8	static
runtime.c:6:6:__aeabi_memcpy4	8	static
runtime.c:7:6:__aeabi_memclr	8	static
runtime.c:8:6:__aeabi_memclr4	8	static
startup.c:12:12:rom_leftovers	0	static
startup.c:15:6:Reset_Handler	8	static
startup.c:35:6:Default_Handler	8	static

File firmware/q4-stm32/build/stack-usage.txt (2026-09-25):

app.c:9:6:app_input	8	static
app.c:14:6:app_fault	0	static
app.c:15:6:app_settled	0	static
app.c:20:6:app_can_idle	8	static
app.c:23:6:app_storage_error	0	static
app.c:3:6:app_init	16	static
app.c:29:6:app_service	24	static
counter.c:11:6:counter_init	16	static
counter.c:17:6:counter_sample	8	static
fram.c:3:13:exchange	16	static
fram.c:4:13:status	24	static
fram.c:14:13:read_word	104	static
fram.c:26:13:start_word	56	static
fram.c:34:17:complete	16	static
fram.c:5:6:fram_init	56	static
fram.c:35:7:fram_storage	0	static
fram.c:37:6:fram_available	0	static
fram.c:38:6:fram_sleep	32	static
fram.c:45:6:fram_wake	32	static
input.c:2:6:input_push	16	static
input.c:11:13:input_take	16	static
input.c:20:6:input_apply	40	static
journal.c:4:10:journal_crc	32	static
journal.c:12:6:journal_record_valid	16	static
journal.c:16:6:journal_load	80	static
journal.c:36:6:journal_begin	16	static
journal.c:45:6:journal_service	40	static
main_stm32.c:31:17:now	0	static
main_stm32.c:35:13:power	0	static
main_stm32.c:39:13:reset	0	static
main_stm32.c:50:13:power_good	0	static
main_stm32.c:85:13:spi1_wait	16	static
main_stm32.c:169:13:bus_abort	0	static
main_stm32.c:218:22:bus_poll	8	static
main_stm32.c:92:13:fram_exchange	32	static
main_stm32.c:175:13:bus_start	24	static
main_stm32.c:114:13:storage_init	48	static
main_stm32.c:40:6:panic	24	static
main_stm32.c:200:6:I2C1_IRQHandler	0	static
main_stm32.c:211:6:SPI2_IRQHandler	0	static
main_stm32.c:228:6:SysTick_Handler	8	static
main_stm32.c:229:6:EXTI0_1_IRQHandler	8	static
main_stm32.c:272:6:stop_from_ram	0	static
main_stm32.c:279:5:main	72	static
oled.c:56:13:fail	16	static
oled.c:26:16:glyph_byte	48	static
oled.c:63:13:send.isra	24	static
oled.c:45:9:oled_status_byte	56	static
oled.c:50:9:oled_pixel_byte	8	static
oled.c:68:6:oled_init	16	static
oled.c:72:6:oled_is_off	0	static
oled.c:73:6:oled_service	80	static
rail.c:2:6:rail_invalid	0	static
rail.c:3:6:rail_sample	16	static
rail.c:14:6:rail_display_allowed	0	static
runtime.c:2:7:memset	0	static
runtime.c:3:7:memcpy	8	static
runtime.c:4:7:memmove	8	static
runtime.c:5:6:__aeabi_memcpy	8	static
runtime.c:6:6:__aeabi_memcpy4	8	static
runtime.c:7:6:__aeabi_memclr	8	static
runtime.c:8:6:__aeabi_memclr4	8	static
startup.c:9:6:Reset_Handler	8	static
startup.c:15:6:Default_Handler	8	static

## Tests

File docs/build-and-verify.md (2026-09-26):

# Build and verify Count Fidget

## Active Q5 engineering workflow

Q5 is derived from the frozen Q4 sources and changes only what the [Q5 review](REVIEW-Q5-2026-09-25.md) lists. Q1–Q4 remain frozen; never run a Q4 builder against Q5. **JLCPCB quoting of the locked design is authorized; purchases and manufacture are not.** Tools used for the recorded evidence: KiCad 10.0.6, Freerouting 2.4.1 (same jar SHA-256 as Q4) on a Temurin JRE with telemetry off, Arm GNU 14.3.Rel1 (x86_64 Linux build), CadQuery 2.8.

1. `build_q5_model.py` derives the Q5 model from `electronics/q4/netlist-Q4.json` plus the recorded Q5 deltas and `electronics/q5/placement.json`. `build_q5_schematic.py --kicad-cli ...` regenerates the sheets and deletes stale sheets. It must report ERC zero.
2. `build_q5_board.py` **discards routing**. After it: `sync_q5_board.py`, `preroute_q5.py` (locked SYS seed), `prepare_q5_route.py`, Freerouting on the DSN, `finish_q5_board.py --import-route` (SES import, collision-checked via nudge, the recorded `gnd-stitch.json` vias from `plan_q5_stitching.py`, two GND pours). DSN/SES are local exchange files and gitignored.
3. `verify_q5.py --kicad-cli ...` runs fresh native XML/ERC/DRC with parity and binds the reports to every input and builder script. `test_verify_q5.py --output verification/q5-negative-tests.json` requires that clean baseline, then checks 42 corruptions are rejected.
4. `build_firmware_q5.py --toolchain ...`, then `--verify-only`. `test_firmware_q5.py` runs the portable suites (`--sanitize` for UBSan; `--cc gcc` where clang's UBSan runtime is missing; `--image-only` for 13 image corruptions).
5. `simulation/q5-firmware-emulation/scenarios.py --check` runs the actual ELF on the instruction-level board model; `energy.py` produces the battery-life table. `simulation/q5-power/check.py` records the bounded latch/inrush/ADC/insertion/storage calculations.
6. `build_q5_enclosure.py --kicad-python ...` requires five valid solids, manifold STLs, zero static intersections and zero sampled assembly-path collisions.
7. `screen_stock_q5.py` (read-only public JLC/LCSC catalogue lookups) binds the final model hash. Then `export_q5.py --kicad-cli ...` writes the variant A (SMT) and variant B (`-FULL-ASSEMBLY`) BOM/CPL, loose-part, home and offboard lists and Gerbers to `procurement/q5/`. No Q5 exporter negative test exists yet. The exporter checks its inputs itself.
8. `estimate_q5_jlc_cost.py` (KiCad Python) prices both variants from JLC's published fee schedule, `stock.json` and the observed PCB quote, and writes `procurement/q5/jlc-cost-estimate.json`. `build_q5_coupon.py` writes the print-tolerance coupon STL.
9. `tools/clicker-flash/test_clicker_flash.py --output verification/q5-flasher-tests.json` tests the macOS flasher against the dfu-util emulator.

Routing notes from the design lock:
- `preroute_q5.py --no-seed` routes without the locked SYS seed, which the re-placed board no longer uses.
- Freerouting 2.4.1 is deterministic. A knot that stays unrouted is fixed by nudging placement (for example R10 at 270°, C39 at x −0.3), not by editing the SES.
- After any re-placement, re-plan `gnd-stitch.json` with `plan_q5_stitching.py` before `finish_q5_board.py`.

## Historical Q4 engineering workflow

Q4 uses STM32L072CBT6, a complete SPI OLED module and external SPI FRAM. Q1/Q2/Q3 remain frozen. **All vendor quote activity, purchases and manufacture are paused.** These are local engineering operations.

1. Read `Q4-implementation.md`, `q4-power-design.md`, `q4-firmware.md` and the current review entry point before editing.
2. `build_q4_model.py` combines exact circuit identities with `electronics/q4/placement.json`. `build_q4_schematic.py` generates the native sheets, symbols, XML, PDF and local provenance using KiCad10. `build_q4_board.py` **discards existing routing**; use it only for an intentional new layout. `sync_q4_board.py` synchronizes native fields, paths and explicit NCs.
3. The routing pipeline is `preroute_q4.py`, `prepare_q4_route.py`, local Freerouting2.4.1 with analytics disabled, then `finish_q4_board.py`. Preserve the USB and supply seed routes. DSN/SES are private exchange files and excluded from Git; a saved session must match its exact source DSN. Review footprint geometry and mechanical solder envelopes as well as electrical clearances.
4. Run `python3 scripts/verify_q4.py --kicad-cli /path/to/kicad-cli` against stable final sources. It runs fresh native XML export, ERC and DRC with schematic parity and binds reports to the inputs. No electrical or courtyard exception is accepted. Running without `--kicad-cli` validates a saved binding; it is **not a fresh native check**. Some macOS hosts require permission for KiCad's local GUI-service initialization even for command-line DRC.
5. Run `python3 scripts/test_verify_q4.py --output verification/q4-negative-tests.json`. It first requires a clean real baseline, then corrupts temporary copies to test rejection. `test_export_q4.py` separately checks the exporter; synthetic exporter tests do not validate the routed board.
6. Firmware uses official Arm GNU14.3 and pinned ST/CMSIS headers. `build_firmware_q4.py --toolchain /path/to/toolchain` builds the default FRAM product. `--verify-only` checks committed source, compiler provenance and actual loaded image bytes. `test_firmware_q4.py` runs bounded portable behavior/fault cases; `--image-only` checks image corruption. The optional EEPROM backend is a separate test build. Follow `q4-firmware.md` for home USB programming and preservation rules.
7. Run `python3 simulation/q4-power/check.py` and the documented `run_spice.py --library /path/to/libngspice` command. They bind conditional equations and ideal subcircuit results, including the retained cold-insertion counterexample. They do not simulate every semiconductor or prove physical operation.
8. Run `build_q4_enclosure.py` with CadQuery2.8 and `--kicad-python /path/to/KiCad/Python`. Final outputs must use the actual final board/model, exit successfully, have four valid single solids and manifold bed-aligned STL meshes, and pass modeled static and sampled assembly-path intersections. Private snapshot overrides are for experiments, not final evidence. Inspect the rendered images and complete the separate physical fit checks.
9. Refresh the final stock/model binding, then run `export_q4.py --kicad-cli /path/to/kicad-cli`. It requires current native evidence and exports the factory SMT split separately from home completion and unqualified offboard items. This generates local engineering files and does not submit anything to a vendor.
10. Preserve historical package hashes with `verify_project.py`; commit a coherent final Q4 review candidate to the existing branch/draft PR. Hardware validation, actual battery/harness qualification and explicit order approval remain separate.

## Historical Q1/Q2 workflow

The following records the older revisions. It does not authorize quoting or rebuilding their frozen packages.

## Quick integrity and portable firmware checks

```sh
python3 scripts/verify_project.py
python3 scripts/run_host_tests.py
```

The first checks stored Q1 firmware hashes, Intel HEX integrity/journal separation, exact 46-ref BOM/CPL match, Gerber ZIP versus loose files, recorded DRC status and every frozen RFQ member against its manifest. It also validates Q2 source/header/build inputs and actual compiled outputs against the separate build manifest, compiled LCD register values, and application information-FRAM exclusion. Only the explicitly recorded `firmware/main_msp430.c` Q1/Q2 divergence is allowed; every other RFQ member must still match the working tree. The second compiles/runs the existing counter/journal and LCD host tests using `CC` or an available `cc`, in a temporary directory. It requires a C compiler; it does not flash hardware.

Host tests exercise bounce, no repeat, wake click, reset priority, saturation, timer wrap, blank memory, CRC fallback, ten interrupted-journal word boundaries and 100,000 commits, plus LCD digit mapping. They do not cover analog brownout, pin mux, LCD optical/bias behavior, charging, protection or enclosure fit.

## RFQ packaging

**Do not run `scripts/package_rfq.py` while shared source is the Q2 candidate.** The submitted Q1 ZIP and its manifest are frozen; this branch intentionally has newer source. That legacy packager copies working sources and could combine Q2 source with Q1 HEX. A future coordinated Q2 engineering release needs its own package revision after hardware/firmware qualification. The current archive still includes its matching Q1 source, PCB-only/full/offboard BOMs, import notes, HEX/checksums and drawings. Contact details come from the authenticated vendor account.

## Target firmware

Retained image target: MSP430FR4133IG48R. Original build used TI MSP430 GCC **9.3.1.11**, support files **1.212**, warnings as errors; size is 2238 text / 98 data / 68 BSS bytes. The original command history was not retained, but the controlled recipe documented in `review-lcd-firmware-Q2.md` reproduced the complete Q1 application HEX byte-for-byte on macOS. The full ELF file differs in non-load metadata. `LCD4MUX` includes `LCDSON` in the actual header: the alleged missing segment-enable/source drift was refuted.

The current shared source is a **Q2 LCD verification candidate**, changing only the LCD clock divider to 8 (32 Hz nominal) and making the already implied `LCDSON` explicit. Q1 hardware is missing R13/R23/R33 reservoir capacitors; no software build clears that hold. Existing charger/protection, schematic/ERC, fit and first-article gates also remain open.

Obtain the [official TI compiler](https://www.ti.com/tool/download/MSP430-GCC-OPENSOURCE), host-compatible **9.3.1.11**, and support **1.212**. Set paths to their installation roots, not their `bin`/`include` subdirectories:

```sh
python3 scripts/build_firmware.py --toolchain /path/to/msp430-gcc-9.3.1.11_macos --support /path/to/msp430-gcc-support-files
python3 scripts/verify_project.py
python3 scripts/run_host_tests.py
```

Default output is the separate `firmware/q2-lcd-check/` directory; use `--output /path/to/separate-directory` for a comparison build. The script compiles fixed source order with explicit `-mmcu=msp430fr4133 -std=c11 -Os -Wall -Wextra -Werror -ffunction-sections -fdata-sections` and links with `--gc-sections`. It records command argument arrays, hashes all source/header/build/verification inputs, resolved compiler dependencies, compiler tools and full toolchain/support trees. Temporary paths are normalized in the map/listing and recorded commands. The manifest records actual output hashes and the exact historical/new source hashes; no timestamps enter the build products.

Validation is intentionally restricted to this exact candidate: it binds the frozen Q1 application HEX hash, requires the same loaded addresses and exactly `0xc53d: 0x18 -> 0x38`, and checks the compiled `lcd_start` instructions for `LCDCTL0=0x385d` and `LCDVCTL=0xf0a0`. It checks ELF/HEX load-byte equality using ELF program-header load addresses, and excludes information FRAM `0x1800–0x19FF`. A disassembly listing is retained for review. A later register override or any other loaded-byte change is rejected; future firmware changes require a separately reviewed recipe. Repeating this recipe produced identical Q2 ELF/HEX/map/listing/manifest files locally. That does not establish byte reproducibility across hosts, different toolchain builds or uncontrolled environments. These are build checks, not MCU execution, waveform, current or brownout tests. Do not flash or promote this candidate without a controlled hardware validation plan; never overwrite Q1 outputs or the factory initializer to perform a rebuild.

`factory-display-info.hex` initializes a valid 88,888,888 journal only for factory display inspection. It is not a field update image. Program via an MSP-FET-compatible Spy-Bi-Wire fixture per the RFQ; leave security unlocked for prototype debugging and never backfeed target V3. Reset count to zero after factory tests. USB is charge-only.

## KiCad and routing

Open `electronics/click-counter-Q1.kicad_pro` / `.kicad_pcb` in KiCad 10. Existing board geometry is embedded; the project-local LCD footprint library is in `ClickCounter.pretty` with `${KIPRJMOD}` mapping. Use matching standard libraries to avoid accidental substitutions.

`electronics/build_pcb.py` needs KiCad 10's `pcbnew` Python binding and `KICAD_FP_ROOT` pointing to the standard footprint directory. Its fallback path references the old cloud tool folder; set the environment variable explicitly on another machine. **It overwrites the board and generates an unrouted DSN.** Do not run it merely to view/upload Q1. The original router log identifies Freerouting 2.4.1; DSN/SES are retained. Regenerated DSN identifiers can invalidate old SES correspondence, so route the new DSN rather than blindly reusing an old session. `finish_pcb.py` imports a matching session if needed, normalizes tracks, fills copper and stores the custom footprint. It does not replace all export/validation steps.

The retained DRC identifies KiCad **10.0.6** and includes errors/warnings under the saved configuration. It ignores `missing_courtyard`, `track_not_centered_on_via`, `tuning_profile_track_geometries`, `footprint_filters_mismatch`, and `footprint_type_mismatch`. Its schematic parity list is empty because no matching native schematic/ERC exists. The zero-result claim is limited to that configuration; review excluded checks and physical courtyards as part of engineering qualification.

For an intentional electronics change: first preserve a branch/checkpoint, make the schematic/netlist/generator changes consistently, regenerate/route, run fresh DRC, export all Gerbers/drills and both placement conventions, update BOM/importer splits and assembly drawings, then revalidate/refreeze the package. A native schematic/ERC still must be created. Do not treat packaging assertions as fresh KiCad validation.

## CAD

See `mechanical/README.md`. CadQuery source, STEP/STLs and rendered PNGs are supplied. Need CadQuery, NumPy and Pillow for the historical renderer; font paths are Linux-specific and must be adapted. Q1 mount/USB/component changes must be modeled before final printing. Solid-validity checks alone are insufficient.

## Separate Q3 OLED candidate

Q1/Q2 artifacts remain frozen. Q3 sources, board, schematic, mechanics, procurement exports and firmware live in their own q3 directories.

1. The controlled model generator selects exact MPNs from the recorded live-stock evidence. Any position/circuit change requires regenerating the Q3 schematic provenance and synchronizing native fields/NC nets without discarding routes.
2. Run verify_q3.py --prepare-native with the local KiCad CLI. Execute its exact native DRC (including schematic parity), ERC and netlist-export commands; use --bind-native only after all three finish and the sources remain unchanged. One exact disclosed J1/SW2 courtyard projection is permitted; no electrical violation or unconnected item is permitted.
3. Run test_verify_q3.py --full --bound for deliberate corruption rejection against final evidence. It works on temporary copies.
4. build_q3_enclosure.py requires CadQuery and --kicad-python. Its default input is the final native Q3 board/model. Require exit0 and a matching manifest, four valid/manifold print parts and zero modeled intersections; a file's existence is insufficient. Private snapshot arguments support experiments, but are not final package evidence.
5. export_q3.py requires the current native validation and explicit local KiCad tools. package_q3.py then verifies historical integrity, Q3 evidence, firmware, mechanical and export hashes before producing dist/q3/click-counter-Q3-RFQ.zip.
6. Q3 target firmware uses TI GCC9.3.1.11/support1.212. build_firmware_q3.py --verify-only checks sources, outputs and information-FRAM separation. Factory initialization now covers34bytes,0x1800–0x1821; ordinary updates preserve the entire information region.

These checks establish file consistency and bounded software/geometry review. They do not establish physical power, protection, OLED process, runtime, battery or fit qualification, and do not authorize manufacture or payment.

## Additional September22 adversarial review

Run `python3 scripts/test_q3_behavior_model.py` to compile the unchanged production counter, input and OLED modules against a separate bounded deterministic harness. The saved result is `verification/q3-behavior-model-2026-09-22.json`. It checks arbitrary destination-word tears, recovery cuts, scheduling and display faults; it does not emulate analog rails or the MSP430 peripherals.

Run `python3 scripts/analyze_q3_hardware_corners_20260922.py` for the separate conditional electrical analysis. Read its explicit assumptions and the dated hardware review; a reproduced counterexample is not a hardware pass. The native September15 artifacts remain unchanged. Rechecking their source bindings on September22 does not constitute fresh native DRC.

The negative-check script currently uses the macOS scratch directory `/private/tmp`; ensure it exists when reproducing on another platform. Do not modify a hash-bound validation input and then reuse the previous native binding as though it still applied. The September15 RFQ is an immutable snapshot and does not contain these new reviews or later status documents.

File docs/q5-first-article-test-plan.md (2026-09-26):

# Q5 first-article test plan

This plan closes the Q5 physical gates listed in [REVIEW-Q5](REVIEW-Q5-2026-09-25.md) and the Q4 gates that still apply. Run it on the first assembled boards **before** any volume order. Every result goes in a dated file under `verification/first-article/` (measurement, instrument, unit serial from the flash log, pass/fail). A board that fails a **stop** test is not shipped, and the design issue goes back to engineering.

## Equipment (about US$250 if bought new)

| Item | Use |
|---|---|
| Nordic PPK2 power profiler (or Joulescope / µCurrent + DMM) | µA-to-mA supply current, as a source standing in for the cell |
| Coin-cell dummy adapter (CR2032-size insulated shim with leads) | Feed the BT1 holder from the PPK2 or a bench supply without a cell |
| 2-channel oscilloscope (≥ 20 MHz) | Latch, rail and SPI timing |
| Adjustable bench supply 0–5 V with current limit | Cell-voltage sweeps |
| USB-C power meter + 3 data cables of different brands | Charge current; USB fit |
| Thermocouple thermometer; hair dryer and freezer pack | Charge temperature window |
| 5 × LIR2032 from two sources, 1 × CR2032 (for the do-not-charge check only), calipers | Cells; fit |

Test points: TP1 GND, TP2 VLOGIC, TP5 VBUS, TP6 SYS, TP9 COUNT_N, TP11 NRST, TP12 BOOT/RESET key, TP13 SYS_ON (U7 ON).

## A. Bring-up and programming (every unit)

| # | Test | Pass |
|---|---|---|
| A1 | Visual/X-ray from JLC: BT1, J1 stakes, QFN/WSON joints | No bridges; J1 stakes wetted |
| A2 | Unpowered: resistance VBUS–GND, SYS–GND, VLOGIC–GND | > 1 kΩ each (no shorts) |
| A2b | **BT1 polarity before any cell:** meter from the holder's spring contact that meets the cell's + (can) face to TP pad CELL_P (BT1 pad 1, marked +) | < 1 Ω to CELL_P. **Stop** if the + contact reads to CELL_N_RAW (the holder is placed 180° wrong; a cell would be reverse-connected) |
| A3 | USB only, no cell, current limit 100 mA | Board powers (VBUS via D4). VLOGIC 3.15–3.26 V. Current < 30 mA |
| A4 | DFU entry and `clicker_flash.py flash --check` | PASS, and all four commissioning answers pass. **Stop** if DFU never enumerates on two cables |
| A5 | Unplug/replug, pinhole restart | Count returns without ERR |
| A6 | After the flasher's automatic DFU leave, the display comes up without pressing the pinhole | Digits appear within 1 s. The firmware's ROM-leftover reset path has worked |
| A7 | With a cell fitted: enter DFU, then unplug USB **without** leaving DFU. Watch TP13 and the current | Expected: the board stays on (D+ pull-up back-feed through D2 holds the latch), drawing several mA. Record the current. The pinhole must turn it off. This confirms the "pinhole before unplugging" rule |

## B. Power latch (5 units)

| # | Test | Pass |
|---|---|---|
| B1 | Dummy cell 3.7 V from the PPK2, board off: off current | ≤ 11 µA (expect ~8). **Stop** if > 20 µA |
| B2 | Scope TP13 + TP2; single COUNT presses of decreasing length (a finger tap, then a fast flick) | Every press ≥ 50 ms latches; count +1 per power-on; no double count. Record the shortest tap that latches |
| B3 | Wait 30 s | Display off, then VLOGIC falls to 0 with no re-latch or oscillation on TP13. Current returns to B1 |
| B4 | Hold COUNT 60 s from off | One count; turns off within 1 s of releasing after the timeout |
| B5 | On: plug USB; wait 30 s; unplug USB during Stop | Board off after the unplug; no half-powered state (VLOGIC 0 V, not floating mid-rail) |
| B6 | Inrush: PPK2 at 3.0 V, capture power-on | Peak < 25 mA, and the protector does not trip over 20 power-ons |
| B7 | Pinhole on battery | Board turns off; next COUNT press restores the count |
| B8 | Fallback check (1 unit): bridge TP13 SYS_ON to TP6 SYS with a wire | Board powers and counts without the latch (the recovery route if latch control fails); remove the bridge afterwards |

## C. Battery sense, gauge and charger status (3 units)

| # | Test | Pass |
|---|---|---|
| C1 | Dummy cell stepped 4.20 → 3.30 V in 10 mV steps (wait 2 s each), display on | Bars change within ±40 mV of 3.95/3.80/3.70/3.55 V. LO below 3.55 ± 0.04 V. Save-and-off between 3.28 and 3.42 V |
| C2 | Repeat rising | Hysteresis ≈ 30 mV; no flicker between bar states |
| C3 | Real LIR2032 discharged at typical use (log with PPK2) | Record days and gauge behaviour; LO appears before the display dims or resets |
| C4 | USB on a half-charged cell | **CHG** shown. Charge current per BQ25185 ISET (record). Ends in full gauge with no label |
| C5 | USB with the NTC below 0 °C (freezer pack) and above 45 °C (hair dryer) | Charging inhibited (no CHG, or CHG stops), and resumes in range. Record trip temperatures |
| C6 | USB with a full cell (4.20 V) | Never shows LO; never powers off on the USB threshold |
| C7 | **CR2032 primary inserted** (do-not-charge check, 1 unit, supervised, < 1 min) | Record what happens. Labelling must forbid primary cells, since the charger will attempt to charge |

## D. Cell and holder (5 units, 2 cell brands)

| # | Test | Pass |
|---|---|---|
| D1 | Insert the cell with USB connected (documented procedure), 20 cycles | Always powers normally; no protector lock-out |
| D2 | Cold insertion without USB, 20 cycles | Record: works / needs USB to wake. If it needs USB, keep the USB-first instruction (datasheet-expected). **Stop** only if the unit stays dead after USB is applied |
| D3 | Holder retention: shake and 1 m drop onto carpet with the enclosure closed | No reset; count kept |
| D4 | Holder contact resistance (4-wire, dummy shim) | < 0.2 Ω |
| D5 | Protector recovery: discharge a cell below 2.8 V (bench), then USB | Charges and recovers; count intact |

## E. Display (3 units)

| # | Test | Pass |
|---|---|---|
| E1 | Module power tree: photograph the module; measure VBAT/VDD on the module at VLOGIC 3.15 and 3.26 V | Record. Pump output about 7.5 V; digits readable in room light |
| E2 | Display current, all digits 8, contrast as shipped | Record. The energy model assumes 1.0 mA module current at contrast 0x10 with ~20 % of pixels lit (estimate 0.6–2.0 mA): update battery-life figures with the measured value |
| E3 | 200 × NRST pulses with the display on (script with USB + a relay, or by hand) | No latch-up; display recovers every time |
| E4 | Response: high-speed phone video of 20 presses | New digits visible ≤ 100 ms after the click |
| E5 | Display-on droop: scope SYS_LOAD and VLOGIC at a 3.40 V dummy cell while the display turns on | VLOGIC stays ≥ 3.15 V; no brown-out or gauge step |

## F. Count integrity (3 units)

| # | Test | Pass |
|---|---|---|
| F1 | Remove the cell at random points during 200 counting bursts (USB unplugged) | After reinsertion the count equals the last shown value or that value + 1. Never ERR, never lower. **Stop** on any lower or corrupted count |
| F2 | 10,000 presses (a press jig or fidgeting sessions) | Count exact; no ERR |
| F3 | Firmware re-flash on a unit with count 1234 | Count still 1234 after the update |
| F4 | Reset-key abuse: quick taps, 1 s holds, 11 s hold, COUNT during hold, both keys together | Only a ≥ 2 s hold-and-release before 10 s resets; increment always wins |

## G. Enclosure and assembly (all units in the first batch)

| # | Test | Pass |
|---|---|---|
| G1 | Home assembly per `mechanical/q5/README.md`; record time and any rework | ≤ 30 min per unit after the first; no lifted pads |
| G2 | USB-C plug fit: 3 cable brands, both orientations | Fully mates and charges with the enclosure closed |
| G0 | Print the tolerance coupon first (plate holes 13.95/14.05/14.15 mm; cross sockets ±0.05 mm) | Choose the hole and socket that give a firm switch clip and a snug keycap; update the generator |
| G2b | Hot-swap: clip both switches into the plate, press plate + switches into SW1/SW2 | Both switches seat fully (housing flush on the PCB) and click; 20 remove/insert cycles with no loose socket |
| G3 | Keycaps: travel, wobble, return; 1,000 presses each | Full travel, no binding or cracking; the pressed keycap clears the plate and screw bores |
| G4 | Pinhole reaches SW3 with a standard paper clip | Clean click; no need to open the case |
| G5 | Self-tapping M2 × 6 screws (C357360): 5 open/close cycles | Threads hold in the 1.7 mm pilots (or specify heat-set inserts in the next print) |
| G6 | Cell replacement by a non-technical person following the README | Succeeds without tools other than a screwdriver |

## Exit criteria for a production quote

All **stop** tests pass on every tested unit. Each recorded value is inside its pass band, or has an accepted design change. Then update `docs/REVIEW-Q5-2026-09-25.md` and `docs/open-issues.md` (E28–E32), and only then request production quotes for more than the first-article quantity.

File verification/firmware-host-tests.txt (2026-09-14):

PASS: bounce, held-key no-repeat/sleep, wake click, reset priority, overflow, timer wrap
PASS: blank memory, all 10 power-cut boundaries, CRC fallback, 100000 journal commits
Host simulation only: target electrical, LCD, interrupt and brownout tests remain.

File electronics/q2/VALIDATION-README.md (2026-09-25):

# Q2 independent native validation

Q2 is an **unreleased engineering candidate**. This verifier checks design-file consistency and native KiCad rules. It does not qualify battery protection, analog thresholds, power sequencing, effective capacitance, LCD waveforms, firmware on hardware, physical fit or manufacturing safety.

## Recheck the saved evidence

From the repository root, using Python 3.9 or later:

```sh
python3 scripts/verify_q2.py
```

This requires no KiCad or `pcbnew` installation. It compares the current model with the exported native schematic and native board, and requires matching hashes for the exact inputs and native reports from the last successful check. A changed board, schematic, model, local library, relevant generator, project/rule configuration or verifier invalidates the evidence. The schematic export manifest and its PDF/SVG drawings are also checked against current source and artifact hashes; a stale drawing is not accepted alongside a newer native design. Added schematic/library files also invalidate the recorded inventory. A missing or stale report is a failure, not an assumed pass.

## Generate fresh native evidence

After finalizing the model, regenerating the schematic and completing the routed PCB:

```sh
python3 scripts/verify_q2.py --kicad-cli /path/to/kicad-cli
```

The validated native workflow uses KiCad 10. It sequentially exports a new XML netlist, runs schematic ERC, then runs PCB DRC with **schematic parity, all track errors and all severities including exclusions**. No board-save or zone-refill option is used. Finish the layout and fill zones first. Runtime configuration can be isolated through `KICAD_CONFIG_HOME`; on this macOS session the official mounted CLI required an approved execution outside the process sandbox for PCB DRC. That is a runtime requirement, not an altered rule configuration.

Successful execution writes:

- `verification/q2-native-netlist.xml`: fresh native schematic export, with only the absolute source-path metadata normalized to a repository-relative path.
- `verification/q2-native-erc.json`: native electrical-rule report.
- `verification/q2-native-drc.json`: native layout, connectivity and schematic-parity report.
- `verification/q2-validation.json`: input/report SHA256 hashes, exact command arguments, executable hash/version, native check configuration and independent check results.

The new XML must agree with the public `schematic-netlist-Q2.xml`. Inputs must remain byte-identical throughout the native runs. All native violation, unconnected and parity arrays must be empty. An empty parity array alone is insufficient: the verifier also requires the recorded command to contain the parity option.

## Independent checks

The verifier uses Python's standard library and the repository's read-only S-expression parser; it does not import `pcbnew` or rely on board-generator success messages. It checks:

- Exact 62-reference sets: 50 fitted parts, ten fixture lands and two mounting holes.
- Exact MPN, Value, local footprint identity and full schematic instance path for every board footprint.
- All 195 connected physical pin assignments and 28 individually isolated no-connect pin nets, including every repeated native pad with the same logical pin number. It rejects copper assigned to those no-connect nets. J2's independent anchors use distinct `MP1`/`MP2` no-connect identities. KiCad's native `{slash}` escape in generated pin/net names is decoded to `/` for comparison with its XML export; this does not alter connectivity or source files.
- Every footprint position, rotation and side against the current model; unique native PCB UUIDs; four copper layers, 1.0 mm thickness and the exact 42 × 40 mm outline with four 2 mm corner arcs (including arc midpoints, so endpoint-only bounds cannot hide a bulging edge).
- U5's TI DGK land dimensions (1.40 × 0.45 mm), 0.65 mm pitch, 4.40 mm row centers, 0.05 mm round corners and 0.05 mm solder-mask expansion. These are file geometry checks; vendor process acceptance remains open.
- DE188's two ten-pad rows at nominal 13.0 mm spacing, 2.54 mm lead pitch and the retained 1.7 mm drill assumption.
- The five isolated LCD reservoir/pump nets retain only locked segments and exactly one locked through via each; total copper trace length is below 5 mm per net. This catches fixed-route loss or long detour replacement during general routing. V3/GND are multi-endpoint rails and are not given a misleading whole-net length limit.
- C14–C16 reservoir connections at MCU pins 7/8/9, the separate C8 charge-pump connection, C6's nominal 10 µF correction and the explicit TPS7A0230PDBVR output-discharge variant.
- Separate TLV7032 push-pull outputs, two series enable FETs with the intended gate/source/drain nets, 100 kΩ gate pulldowns and CE_N pull-up. Each pulldown's signal-pad center must be less than 3 mm from its FET gate-pad center. This measures straight-line placement proximity, not route length or parasitics.

The default ignored-rule allowlists are explicit in the verifier and repeated from the actual native reports in the validation manifest. Any additional ignored rule fails validation. Existing defaults such as missing courtyard or single-use global-label checks do not imply that those properties have been qualified.

For an intermediate consistency check while routing is still in progress:

```sh
python3 scripts/verify_q2.py --semantic-only
```

This mode prints a deliberately limited result. It does **not** check native report freshness, generate a final validation manifest or establish DRC/ERC/parity success.

## Separate release gates

Run `python3 scripts/verify_project.py` separately for the frozen Q1 package. Q2 verification never rebuilds or updates that archive. Existing engineering issues and first-article measurements remain controlling even when every file-level check passes. No validation result authorizes payment or manufacture.

## Recorded final candidate check

The saved native reports for board SHA256 `c80cf17a1d36d74e4c7c8f7cc4e14f5f42169fe0c3224811856b8bff0e5d0867` passed with KiCad 10.0.6: **0 DRC violations, 0 unconnected items, 0 schematic-parity findings and 0 ERC violations**. The default read-only verifier then accepted the saved input/report bindings.

Measured locked copper lengths are 2.981003 mm (LCD_R13), 3.171061 mm (LCD_R23), 3.912805 mm (LCD_R33), 3.079962 mm (LCDCAP0) and 3.287069 mm (LCDCAP1), each with one locked through via. Gate-pulldown pad-center distances are 1.737500 mm for R14/Q3 and 1.743963 mm for R15/Q4.

Temporary copied-file and in-memory negative checks rejected **21 deliberate corruptions**: 13 changes to part/net identity, NC isolation, placement, display/outline/mask geometry, UUID uniqueness or critical route integrity; and eight changes to source/report hash bindings, required native parity invocation, ignored rules, included severities or nonzero native findings. The untouched baseline passed before and after. These checks did not alter repository design artifacts. The result remains a design-file check, with the physical and purchasing holds above unchanged.

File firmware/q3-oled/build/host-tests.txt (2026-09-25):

PASS: bounce, held-key no-repeat/sleep, wake click, reset priority, overflow, timer wrap
PASS: blank memory, all 10 power-cut boundaries, CRC fallback, 100000 journal commits
Host simulation only: target electrical, LCD, interrupt and brownout tests remain.
PASS: SSD1312 startup/clear/9V commands, bounded chunks, dirty/coalesced frames, MAX, shutdown guard
PASS: injected mid-frame NACK discards display state and recovers the latest committed count
PASS: 150 sampled/committed presses through absent-display timeouts, bounded retries and recovery
PASS: deadline wrap and sleep during every early startup tick
Host model only; target ISR timing, rail sequencing, pixels and current require hardware tests.
PASS: timestamped ISR samples preserve an entire reset pulse during a9ms foreground stall
PASS:1000 delayed foreground batches across ring wraps, release and simultaneous reset priority
PASS: explicit overflow, frozen increments, durable fault ordering, failed write/clear retry and reset recovery
PASS: timestamp wrap, first/held/released wake input and saturating overflow diagnostics
PASS: holding increment through fault-reset recovery produces no synthetic new press

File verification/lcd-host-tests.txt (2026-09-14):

PASS: DE188 zero, one, eight/all-digit segment mapping and digit order (host only)

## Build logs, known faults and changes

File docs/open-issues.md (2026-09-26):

# Open issues

## Q5 status — 25 September 2026

GitHub issues #2–#9, #12 and #13 from the Q4 simulation review are resolved in the Q5 design files. See the per-issue table in [REVIEW-Q5](REVIEW-Q5-2026-09-25.md). The following remain open as physical gates. They are not closed by any file in this repository:

| ID | Q5 open item | Required closure |
|---|---|---|
| E28 | Soft power latch: minimum press to latch, U7 release, USB unplug during Stop | Scope SYS_ON/SYS_LOAD with a real MX contact; confirm the board never half-powers |
| E29 | Battery sense and gauge | Calibrate PA4 through the 75 kΩ source; check the 3.95/3.80/3.70/3.55/3.35 V thresholds against a real LIR2032 under display load; measure ~8 µA off current |
| E30 | Cell holder and first connection | Holder contact resistance and retention; cell insertion with USB present; the retained cold-insertion counterexample (E25) on real cells; TH1 coupling to the cell |
| E31 | Display module supply (#8) | Module power tree; VBAT/pump/current at 3.15–3.26 V; 200 × NRST with the display on |
| E32 | Enclosure | USB-C plugs in both orientations; printed keycap fit/travel; pinhole reach to SW3; load supports |
| P06 | Binding JLC PCBA quote for variants A and B | Owner signs in and uploads the prepared BOM/CPL per [JLC-QUOTE-Q5](../procurement/q5/JLC-QUOTE-Q5.md); record parts matching, rotation corrections and totals. Confirm that variant B's stacked THT display is accepted (Economic or Standard) |
| E33 | Hot-swap sockets and printed tolerances | Socket solder/seating (G2b), tolerance coupon (G0), M2 × 6 self-tapping thread life (G5) |

Q4 design choices addressed E26 (the common regulated rail) and E27 (superseded by external FRAM); their physical verification remains among the Q4 gates in `REVIEW-Q4-2026-09-24.md`, which still apply to Q5 wherever the circuit is unchanged.

## MCU follow-up — 23 September 2026

[The options study](mcu-options-2026-09-23.md) recommends STM32L072CBT6 for the next candidate. It does not alter Q3 or close any issue below. New ngspice subcircuits reproduce E21/E25 under explicitly hypothetical parameters; a whole-board simulation has not been performed.

| ID | Candidate issue | Required closure |
|---|---|---|
| E26 | Native USB needs a supply above the current nominal 3.0 V rail's tolerance floor; separate VDD_USB has sequencing constraints, while OLED logic limits prevent an unreviewed common 3.3 V substitution | Coordinate all STM32 supply domains, mixed-rail I²C/reset, boot/reset access, VBUS detection, USB protection/routing, regulator dropout and power-up/down behavior; implement and verify the revised native design |
| E27 | STM32 EEPROM has different endurance, write latency, bank-execution and ECC behavior from MSP430 FRAM | Design a wear-distributed journal, preserve input handling during writes, validate interrupted-write recovery and factory/update separation, then test on the real target |

The complete revised board still needs an inventory/assembly check; a stocked MCU and regulator do not establish both-vendor support. Quote activity remains paused until explicitly authorized.

## Active Q3 status

**22 September 2026: engineering review only; vendor quotations are paused.** The DE188 replacement is implemented as X087-2832TSWIG02-H14/C18723015 on a two-layer board. Fresh inventory checking found40 of43 exact PCB MPNs with positive JLC available quantity; J1, Q1/Q2/Q6 and R13 have ordering restrictions there, but all three exact MPNs have independent DigiKey stock. That provides a source path, not JLC/PCBWay allocation or accepted sourcing. See the [dated review](REVIEW-Q3-2026-09-22.md) and its stock evidence.

The new deterministic software harness found no additional confirmed production-code defect in its bounded scenarios. Conditional hardware analysis does not close OLED acknowledgement/rise-time, current budget, startup or the retained qualification gaps below. Historical Q1/Q2 issues remain evidence for those revisions, not a claim that the removed LCD circuit is present in Q3.

| ID | Q3 finding / state | Required closure |
|---|---|---|
| E20 | OLED power/process changes:4V TPS63900 supply, internal9V pump, gatedVBAT, exact14-pin FPC | Vendor-approved lot/land/mask/heat/support section; physical rail/start-stop/current/optics and low-cell/USB handover tests |
| E21 |4.7k I²C pull-ups draw more than the controller's stated100µA VOL test current; increasing to33k would leave only10.6pF for the300ns rise-time limit | Obtain sink/capacitance evidence or measure actual ACK low level and rise time. Do not infer margin from100kHz operation alone |
| E22 | Original Q3 foreground work could miss short presses; independent ISR tests exposed and fixed it with a timestamped63-entry input queue and visible persisted ERR state | Physical bounce/timing, queue-overflow and power-loss tests. Abrupt power loss before the foreground error marker write remains a gap |
| E23 | Independent Q3 mechanics found initial shell collisions, one-piece cover assembly trap and0.1mm keeper-head clearance | Corrected split cover and raised PCB model; final source-bound CAD checks plus actual print/assembly/clip/lap/harness/USB/pack qualification required |
| E24 | One exact J1 shell-pad/SW2 courtyard projection exception; rotated-pad nominal separation0.905mm, flange5mm high, checked top fillet≤0.5mm | Vendor3D/tolerance and solder-height confirmation; no electrical-clearance waiver |
| P05 | September22: OLED available1,052;40/43 exact MPNs have positive JLC available quantity. Exact J1, DMN2056U-7 and R13 have verified DigiKey stock but JLC ordering restrictions | Choose accepted exact-part sourcing/allocation when vendor activity is explicitly reauthorized. No preorder, DNP or new quote now |
| E25 | Deterministic battery-insertion sensitivity model can hold protector sense above0.4V for179.45µs, exceeding the125µs minimum short-circuit delay; assumes4.2V,20µF effective SYS capacitance and1Ω other series resistance | Establish actual cell impedance/BATFET slew and instrument insertion/recovery, or design bounded precharge. Converter input limiting does not bound input-capacitor charging; this is a conditional counterexample, not a measured failure |

Q3 retains E01/E03–E05/E07–E09/E11/E12/E14/E18/E19 where applicable. E02/E15/E17 concern the removed DE188/LCD drive and remain historical; Q3 needs its own OLED qualification. E06 consistency requires fresh Q3 native evidence. E10 now has visible MAX/ERR behavior and adversarial tests; the watchdog strategy and hardware recovery remain review gates. No board is physically qualified.

## Historical Q1/Q2 findings

Q1 is on engineering hold after the 15 September independent review. Separate Q2 circuitry, schematic, layout and enclosure corrections are recorded below; a correction in files does not establish measured behavior. A quotation, host test or re-read of a DRC file does not close these findings. See `adversarial-review-Q2.md` and its linked audits.

| ID | Issue / evidence | Closure |
|---|---|---|
| E01 | Protector nominal UV 2.8 V versus EEMB 2.75 V endpoint; the retrieved TI BQ2970 Rev. I table gives ±50 mV at 25°C, so the older blanket ±0.1 V assertion is not substantiated by that source | Establish full-temperature limits, recovery/depleted-cell charging behavior and cell-maker approval, or redesign/validate protection; the corrected citation does not close compatibility review |
| E02 | DE188 440 ms combined optical response | Current exact-part data and sample response/waveform/visibility tests; change display if needed |
| E03 | Custom cell/NTC pack unapproved; Q1 excitation gives 0.250 mA at 25°C. Q2 changes R10 to57.6 kΩ, bounding modeled current below97.45 µA at5.5 V with intact R10; installed heating/lag remains unmeasured | Vendor drawing, genuine cell/NTC data, welded-tab insulation, actual attached-sensor self-heating/thermal contact, strain relief and shipping approval |
| E04 | 18.2 mA low-current charging unqualified | CC/CV, tolerances, termination, stability and power-path measurements |
| E05 | Nominal thermal window not tested | Worst-case review; open/short/resistance-sweep tests; attached cell-temperature test |
| E06 | Q1 native schematic/ERC missing; Q2 six-sheet native schematic now exists with62 refs/features,195 connected pin assignments and28 explicit unused pins | Fresh native PCB checks now have zero violations, disconnected items and schematic mismatches; hash-bound final ERC/DRC evidence is under verification/q2-*. Schematic consistency does not qualify real component behavior |
| E07 | MCU/FRAM/LCD hardware tests missing | First-article programming, pin mux, LCD bias/DC, oscillator, brownout, retention and current tests |
| E08 | Confirmed enclosure study mismatches: rear mounts 1.118 mm off, front mounts absent, LCD pocket 1.25 mm off, USB opening 2.1 mm off, 20.9 mm tray below 21.0 mm allowed pack; wrong-side MCU envelope; see `review-mechanical-Q2.md` | Separate mechanical/q2 CAD now follows the controlled board and modeled envelopes; verify actual part/sample fit, travel, clips, solder tails, pack preparation, print retention and drop behavior |
| E09 | Mass/runtime unmeasured | Actual part masses, slicer output and assembled measurements; active/sleep current/endurance |
| E10 | Firmware robustness/overflow | Watchdog disabled; overflow flag not displayed |
| E11 | Placement/DFM/sample fit | Vendor pad-1 and rotation review; LCD flat-lead holes, standoff and 1 mm switch support checks |
| E12 | NTC legacy/NRND choice | Confirm stock/lifecycle; qualify replacement for repeat builds if needed |
| E13 | Q1 Gerber-job metadata differed from quote specification. Q2 native exports now state ENIG, 1.0 mm board and 0.0175 mm inner copper; graphic bounds remain 42.05 × 40.05 mm for the 42 × 40 mm centerline profile | Vendor acknowledgment of RFQ/native proposed stack and 42 × 40 mm finished profile centerline; confirm actual material, copper, mask, finished thickness and tolerances. Proposed copper/dielectric total is 1.0 mm; KiCad additionally records provisional 0.01 mm mask per side. These are quote assumptions, not accepted fabrication construction |
| E14 | Q1 U3 exact BOM TPS7A0230DBVR is unmatched. Q2 intentionally selects TPS7A0230PDBVR, whose P denotes active output discharge (functional feature, sections 7.3.2/9.1.1), not packaging; [TI TPS7A02 datasheet](https://www.ti.com/lit/gpn/TPS7A02), `procurement/JLCPCB-IMPORT-ADAPTER-Q1.md` | Q2 ordering identity and circuit consequences documented in q2-power-design.md; retain actual brownout/FRAM, output-capacitance, reverse-current and fixture tests. Selection is not sourcing allocation or qualification |
| E15 | Confirmed: selected LCD mode requires reservoir capacitors on U1 R13/R23/R33 pins 7/8/9, absent from Q1 | Q2 adds100 nF C14/C15/C16 on pins7/8/9 with checked short native routes; verify actual bias levels, DC balance, contrast and current. C8 remains100 nF per device specification |
| E16 | Q1 build provenance was incomplete, but alleged source/binary drift is refuted: TI's LCD4MUX includes LCDSON and unmodified source reproduces the shipped application bytes | Provenance improvement implemented for the separate Q2 candidate; preserve exact Q1 comparison and source/toolchain/flags/output manifest for future builds. This is not a remaining segment-enable defect |
| E17 | Q1 LCD frame rate is nominally 64 Hz at the MCU specification limit; positive REFO tolerance can exceed it | Separate Q2 candidate now uses verified nominal 32 Hz; physical bias/contrast/optical qualification remains. Firmware timing changes do not fix E15 |
| E18 | Thermal fault inference: loss of U5 supply while the TEMP_OK pull-up remains powered can leave charging enabled with the charger's TS pin fixed in its normal range | Q2 splits TLV7032 outputs, uses series Q3/Q4 and local100 kΩ gate pulldowns. The powered-pullup mechanism is removed by connectivity; test real startup/supply loss/leakage/disable timing and remaining single faults. See q2-power-design.md; no measured guarantee |
| E19 | Newly confirmed inherited MCU supply-capacitance gap: Q1 V3 has2.2 µF +100 nF; TI §8.3 recommends4.7 µF minimum/10 µF nominal at DVCC. Q2 C6 becomes10 µF GRM21BR61E106KA73L and C7 moves near U1 supply pins | Confirm at least4.7 µF effective at3 V after bias, temperature, aging and tolerance; inspect local return paths and measure rail transients/brownout with selected U3P regulator |
| P01 | Q2 four-file PCBWay submission verified 2026-09-15 11:51:09 UTC: PCB W914112AS1N6 / assembly T-1N7W914112A, five units, both Subject to audit. JLCPCB Q2 Gerbers/RFQ/BOM/CPL processed in a saved draft, current quantity ten and 50 refs, with no placement advancement or complete quote. Q1 entries remain historical and on hold | Obtain technical acceptance of the identified Q2 revision and complete separate 5/10 prices. File upload is not manufacturing release; keep all physical qualification gates |
| P02 | JLCPCB Q2 ten-unit draft: 39 confirmed/10 shortage/1 unmatched required DE188. Shortages affect C1/C3/C5, R3, R9, R11, R16, SW1/SW2 and U5. Corrected U3 TPS7A0230PDBVR and exact J1 are matched; no parts were omitted. Next requires unselected parts to be excluded | Resolve complete sourcing without DNP or silent substitutions. Manual matching requires a $10 payment before review under [JLCPCB terms](https://jlcpcb.com/help/article/terms-and-conditions-of-jlcpcb-parts-selection-service), so it was not activated. Use the existing Frank case for a full written quote or explicit fee waiver; retained DE188 alternatives have no verified stock advantage |
| P03 | JLCPCB battery and test-pricing exclusions | Written scope and priced completion plan; no payment merely to unlock quoting |
| P04 | Neither vendor has a complete landed quote. PCBWay Q2 automatic estimates are $143.93/5 and $184.31/10, excluding components and advanced services; ten is calculator-only. JLCPCB Q2 PCB-only estimates are $32.41/5 and $39.81/10, plus $27.63 estimated freight. PCBWay form has 1 oz inner copper versus requested 0.5 oz; JLCPCB forces Plugged versus requested tenting. These differences are recorded for review | Full 5/10-unit component/assembly/harness/programming/test/freight/tax comparison and explicit acceptance of stack/process. PCBWay's form says SMD Parts but saved detail says SMT Pads: 47 entered is placements, so vendor must calculate solder points from the BOM/board |

E10 requires a deliberate watchdog strategy and visible saturation behavior review. First-article acceptance and purchase approval are separate; do not build remaining units around a failed first article. Read the RFQ for the exact protocol and numeric targets.

An OLED alternative requires a new current budget: the present 3.3 Ω sense resistor and FETs imply a nominal discharge trip near 30 mA. A display in the 23–29 mA range could approach it. This does not establish the candidate's actual application current or authorize changing protection thresholds.

PCBWay's proposed combined mask openings are **not approved**. Q2 uses the TI U5 land pattern (0.20 mm copper gap,0.10 mm nominal mask web); vendor process acceptance is pending. Q2 sharing and the specific PCBWay quotation notice were approved. Both Q2 emails were verified in Sent and revised files were uploaded through both portals. Use portal workflows directly and existing email cases only for unresolved sourcing, DFM and service scope. No full quote, paid sourcing or manufacturing release is established.

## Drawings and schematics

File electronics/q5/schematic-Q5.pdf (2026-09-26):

1 | 2 | 3 | 4 | 5 | 6 | 7 | 8

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
Size: A3 | Rev: Q5 candidate | F Date:
KiCad E.D.A. 10.0.6 | Id: 1/19

## Title: Count Fidget - Q5 engineering candidate

File: click-counter-Q5.kicad_sch

Sheet: /

Count Fidget

ENGINEERING CANDIDATE - NOT RELEASED FOR MANUFACTURE

STM32, keys and USB boot controls / 5

File: mcu-5.kicad_sch USB, charging, soft power latch and common supply / 2

File: usb-power-2.kicad_sch

SPI OLED module and power control / 2

File: display-2.kicad_sch On-board LIR2032 holder and protection / 2

File: battery-2.kicad_sch | USB, charging, soft power latch and common supply / 5

File: usb-power-5.kicad_sch USB, charging, soft power latch and common supply / 4

File: usb-power-4.kicad_sch

STM32, keys and USB boot controls / 3

File: mcu-3.kicad_sch USB, charging, soft power latch and common supply / 1

File: usb-power-1.kicad_sch

SPI OLED module and power control / 1

File: display-1.kicad_sch

Independent charge-temperature window / 1

File: thermal-1.kicad_sch

Independent SPI retained-count memory / 1

File: memory-1.kicad_sch

STM32, keys and USB boot controls / 2

File: mcu-2.kicad_sch | USB, charging, soft power latch and common supply / 3

File: usb-power-3.kicad_sch

STM32, keys and USB boot controls / 4

File: mcu-4.kicad_sch

STM32, keys and USB boot controls File: mcu-1.kicad_sch

On-board LIR2032 holder and protection / 1

File: battery-1.kicad_sch Independent charge-temperature window / 2

File: thermal-2.kicad_sch

STM32, keys and USB boot controls / 6

File: mcu-6.kicad_sch C1 / C13 / C2 / C29 / C3 / C38 | C9 / Q3 / Q4 / R10 / R11 / R12 R5 / R6 / TP13 / U2 / U3 / U7 | D4 / J1 / R1 / R19 / R2 / R3 BT1 / C4 / Q1 / Q2 / R7 / R8 C39 / C40 / C5 / D1 / D2 / D3 R9 / U4 | R13 / R14 / R15 / R39 / TH1 / U5 R30 / R31 / R34 / R35 / R38 / R4
C20 / C28 / DS1 / R24 / R25 / R29 | U6

SW2 / SW3 / TP1 / TP11 / TP12 / TP2 C10 / C11 / C12 / C35 / C37 / C6 R16 / R17 / R18 / R36 / R37 / SW1 U1 / C31 / C32 / C33 / C34 Q5 schematic index - 82 fitted PCB parts plus non-fitted test lands and mounts. Global net labels connect the functional sheets. Crosses explicitly mark unused physical pins. Q1 submitted files remain frozen. This candidate still requires ERC, layout, first-article and safety qualification.

C30 / C36 / R32 / R33 / U8

TP3 / TP4 / TP5 / TP6 / TP9 C7 / H1 / H2 / H3 / H4 / Q5

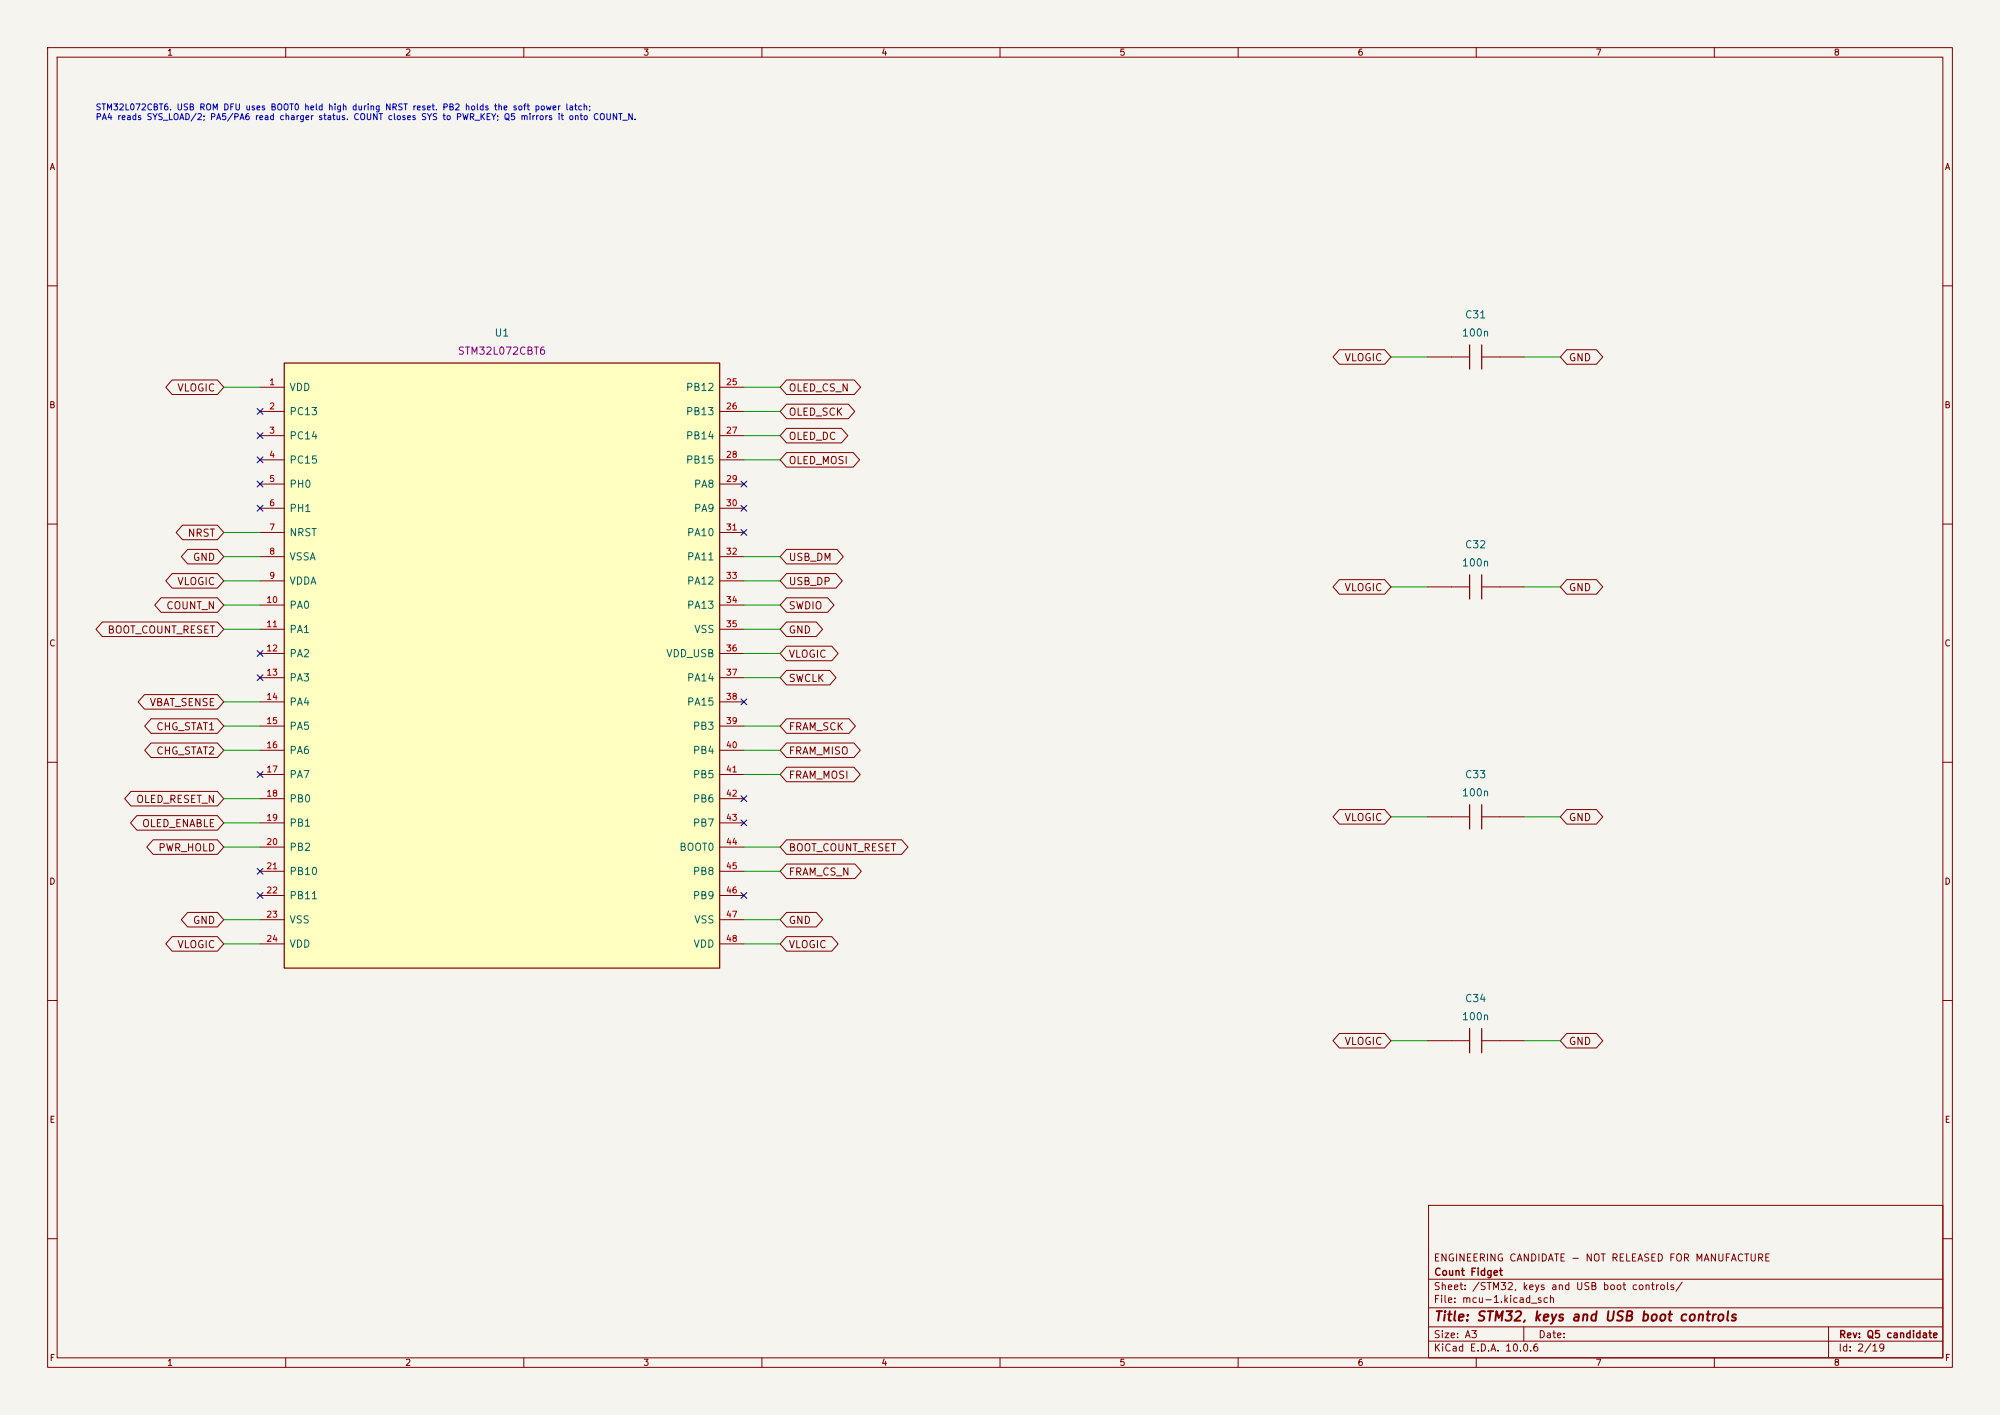
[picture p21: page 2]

STM32L072CBT6. USB ROM DFU uses BOOT0 held high during NRST reset. PB2 holds the soft power latch; PA4 reads SYS_LOAD/2; PA5/PA6 read charger status. COUNT closes SYS to PWR_KEY; Q5 mirrors it onto COUNT_N.

ENGINEERING CANDIDATE - NOT RELEASED FOR MANUFACTURE
Count Fidget
Sheet: /STM32, keys and USB boot controls/
File: mcu-1.kicad_sch
Title: STM32, keys and USB boot controls

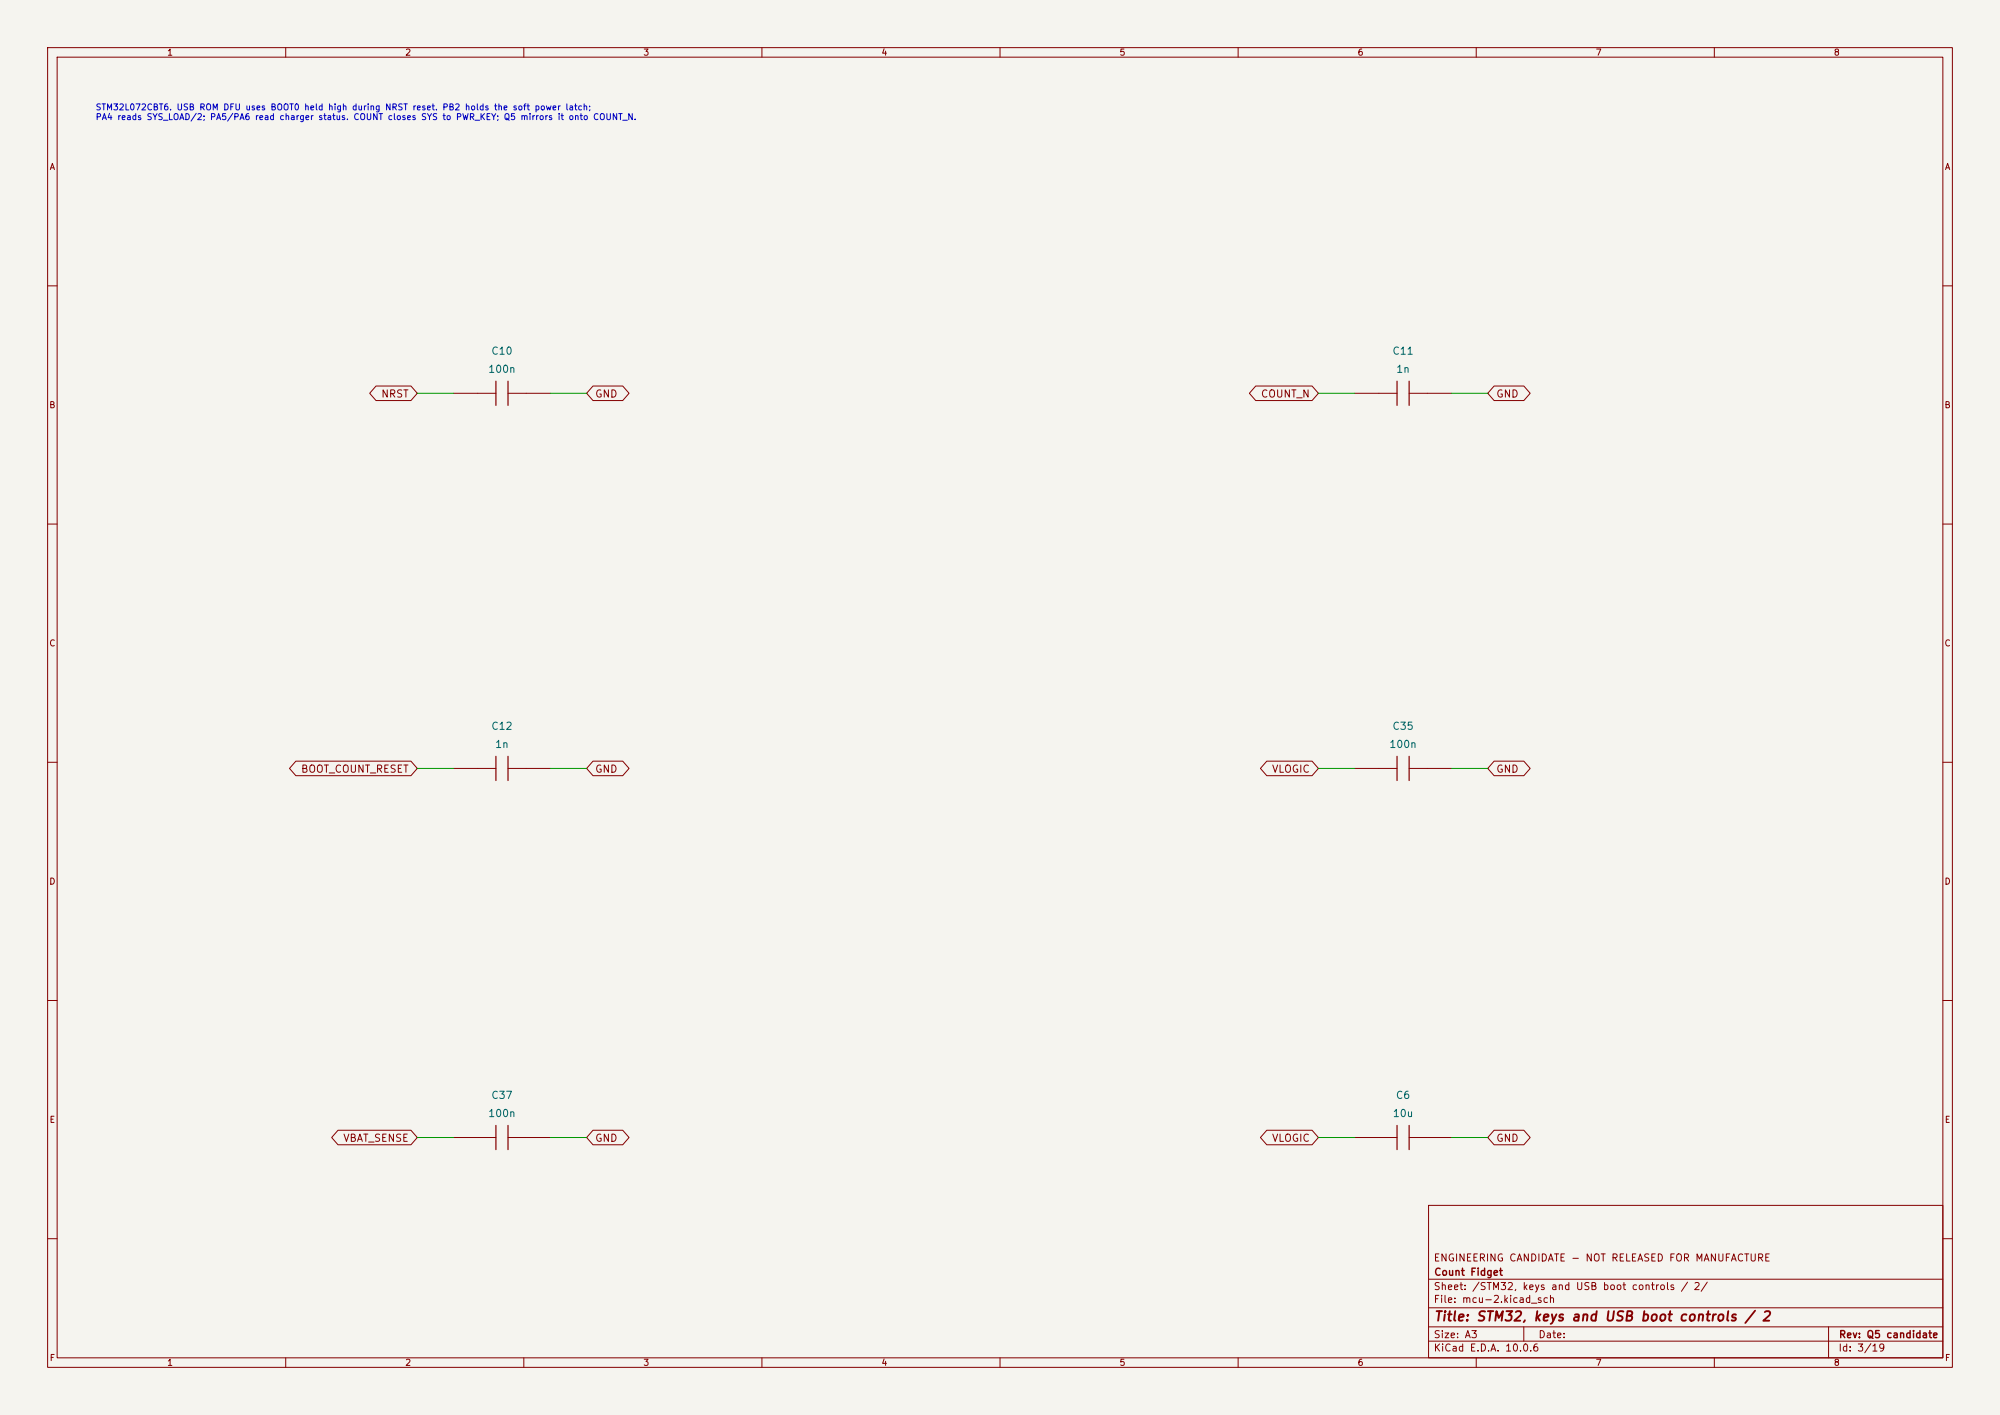
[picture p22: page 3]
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

ENGINEERING CANDIDATE - NOT RELEASED FOR MANUFACTURE
Count Fidget
Sheet: /STM32, keys and USB boot controls / 2/
File: mcu-2.kicad_sch
Title: STM32, keys and USB boot controls / 2

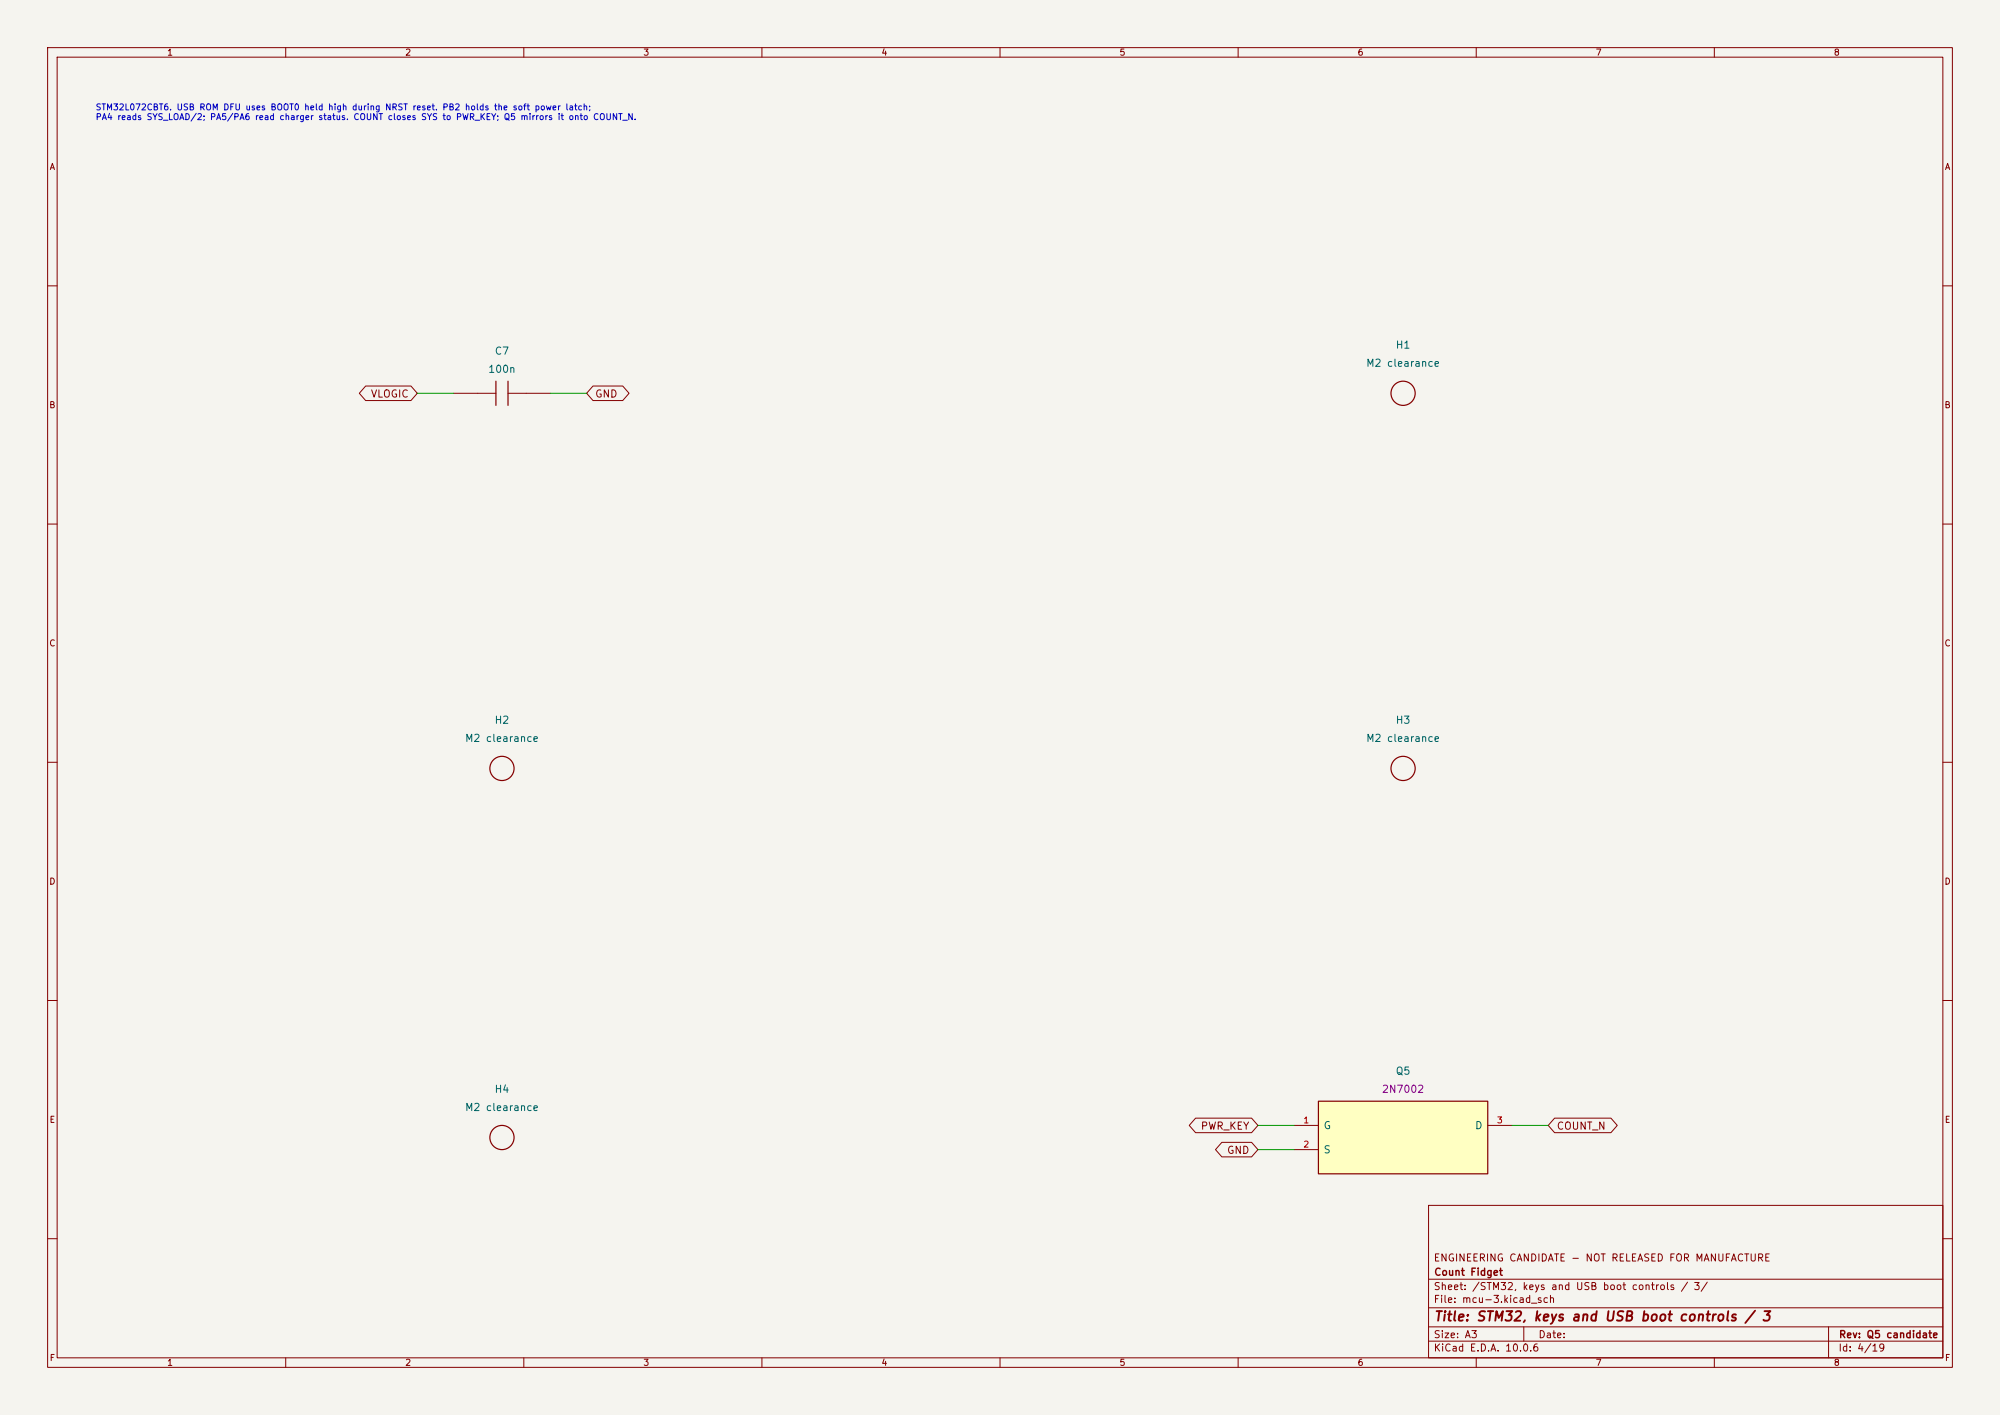
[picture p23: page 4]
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

ENGINEERING CANDIDATE - NOT RELEASED FOR MANUFACTURE
Count Fidget
Sheet: /STM32, keys and USB boot controls / 3/
File: mcu-3.kicad_sch
Title: STM32, keys and USB boot controls / 3

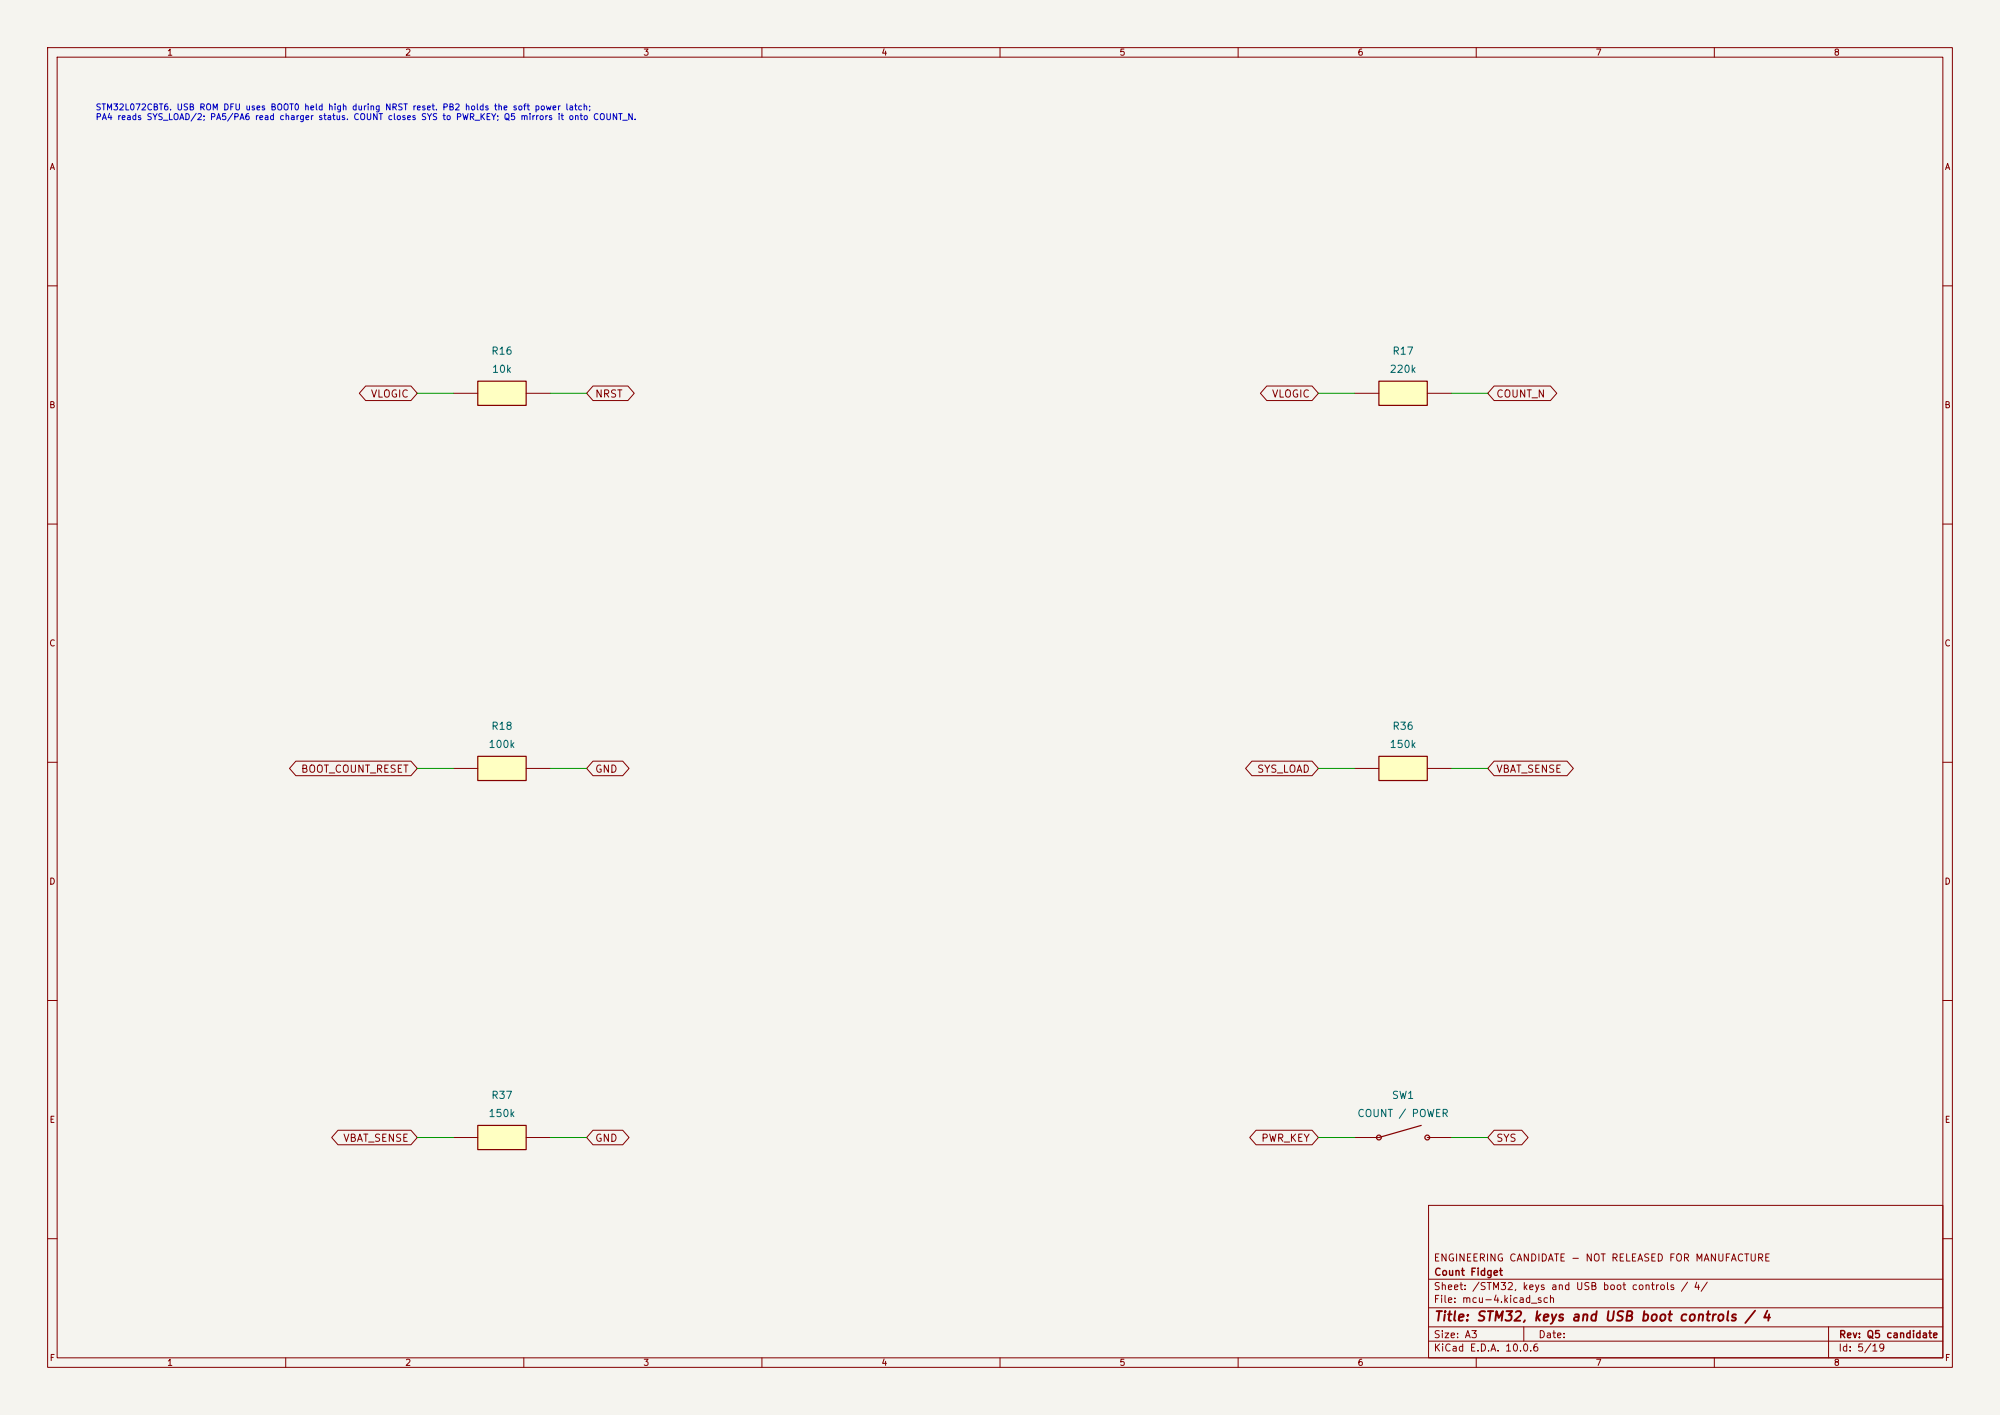
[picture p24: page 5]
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

ENGINEERING CANDIDATE - NOT RELEASED FOR MANUFACTURE
Count Fidget
Sheet: /STM32, keys and USB boot controls / 4/
File: mcu-4.kicad_sch
Title: STM32, keys and USB boot controls / 4

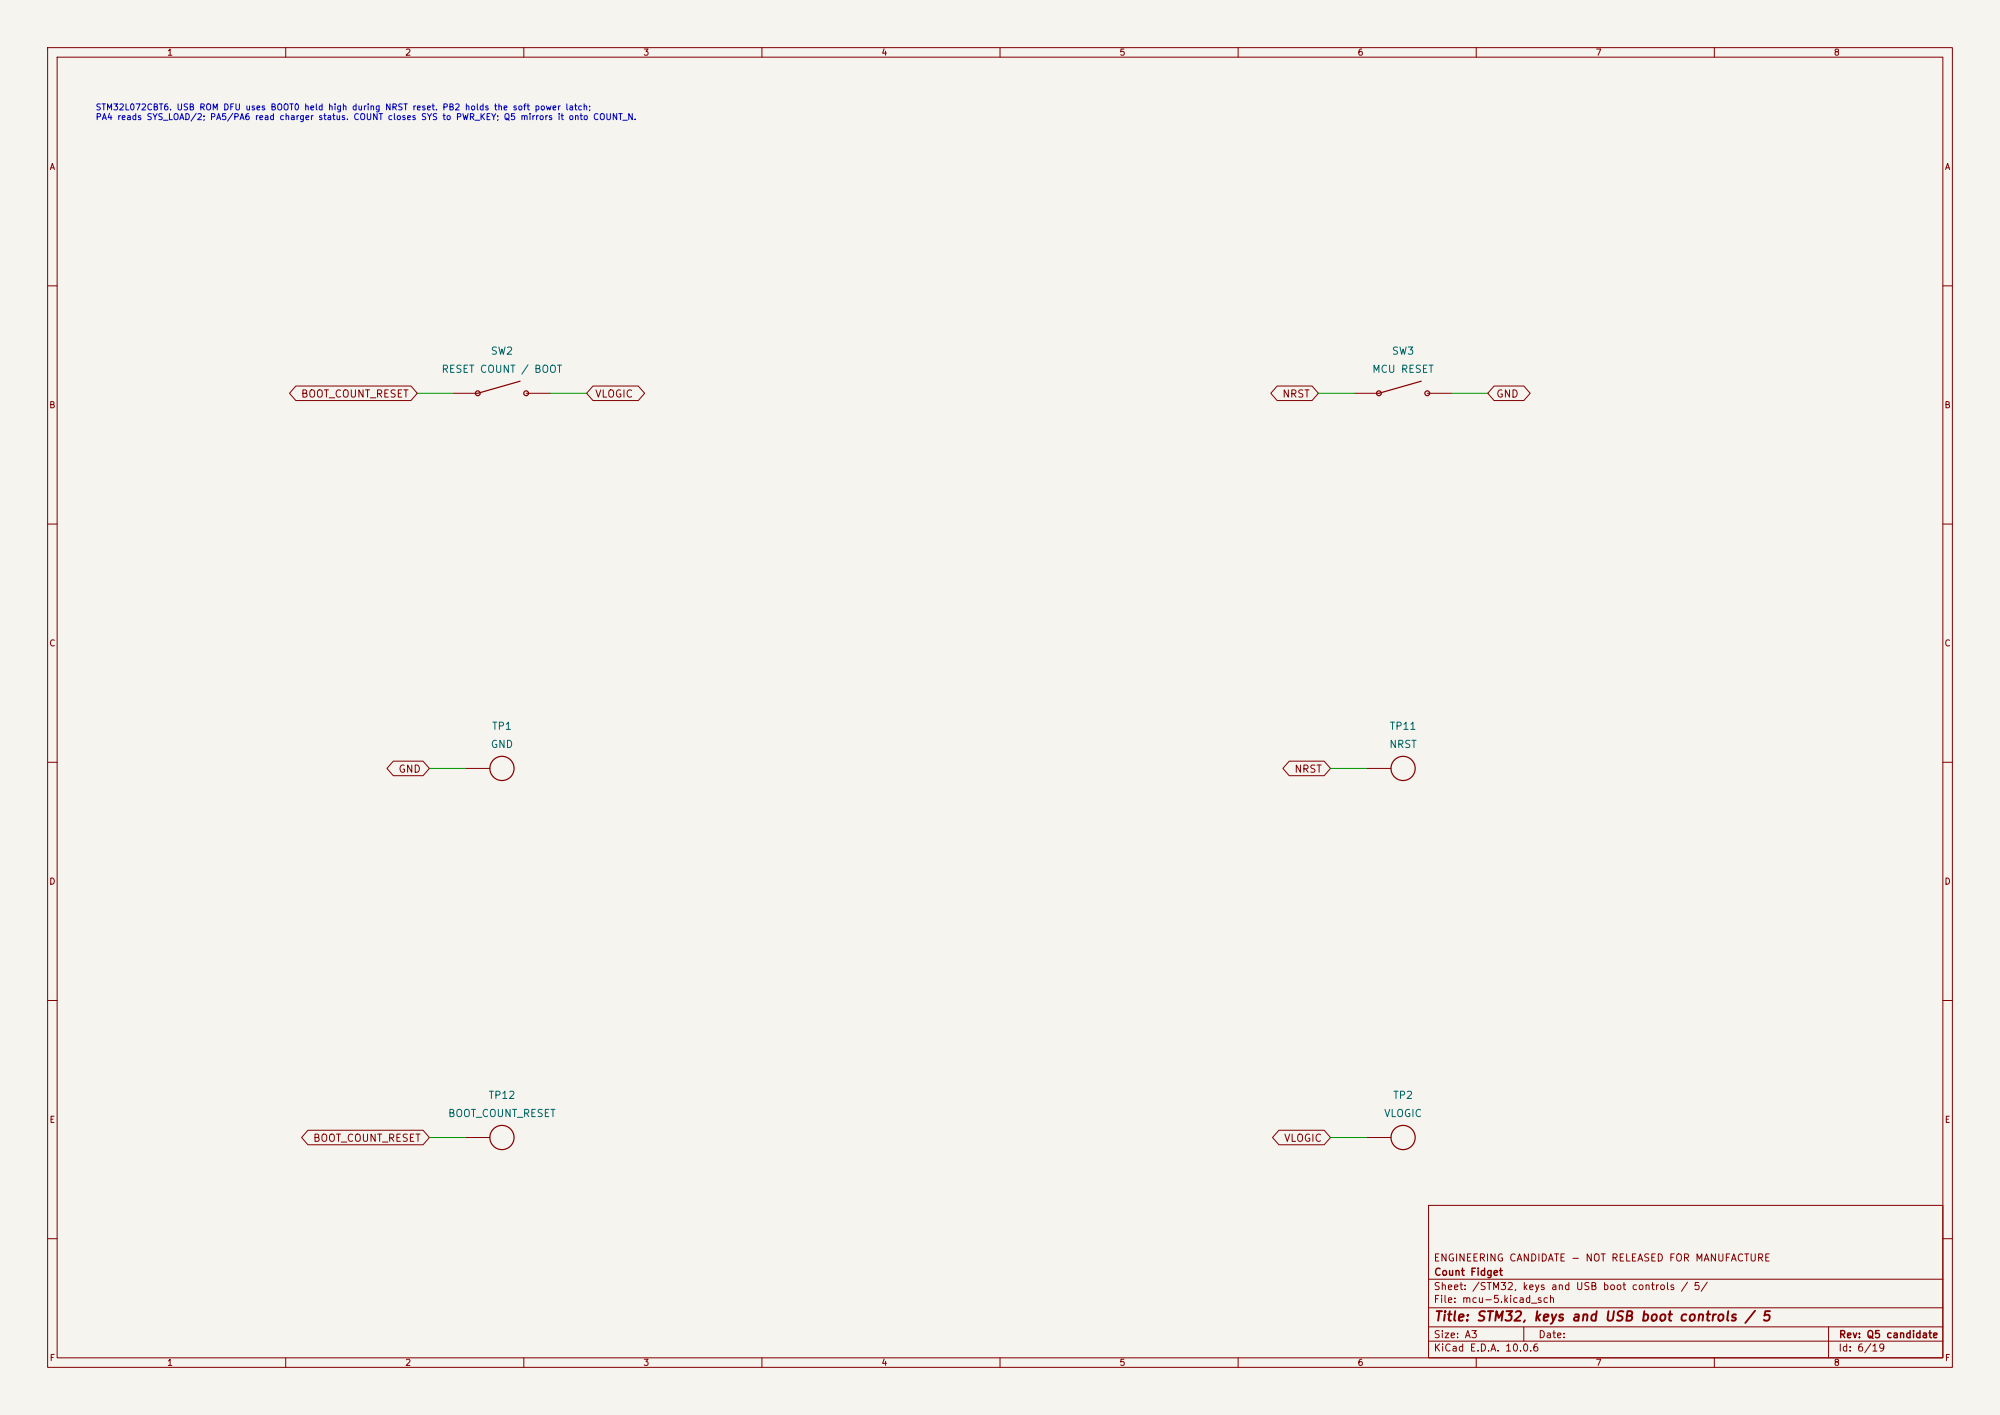
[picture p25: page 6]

ENGINEERING CANDIDATE - NOT RELEASED FOR MANUFACTURE
Count Fidget
Sheet: /STM32, keys and USB boot controls / 5/
File: mcu-5.kicad_sch
Title: STM32, keys and USB boot controls / 5

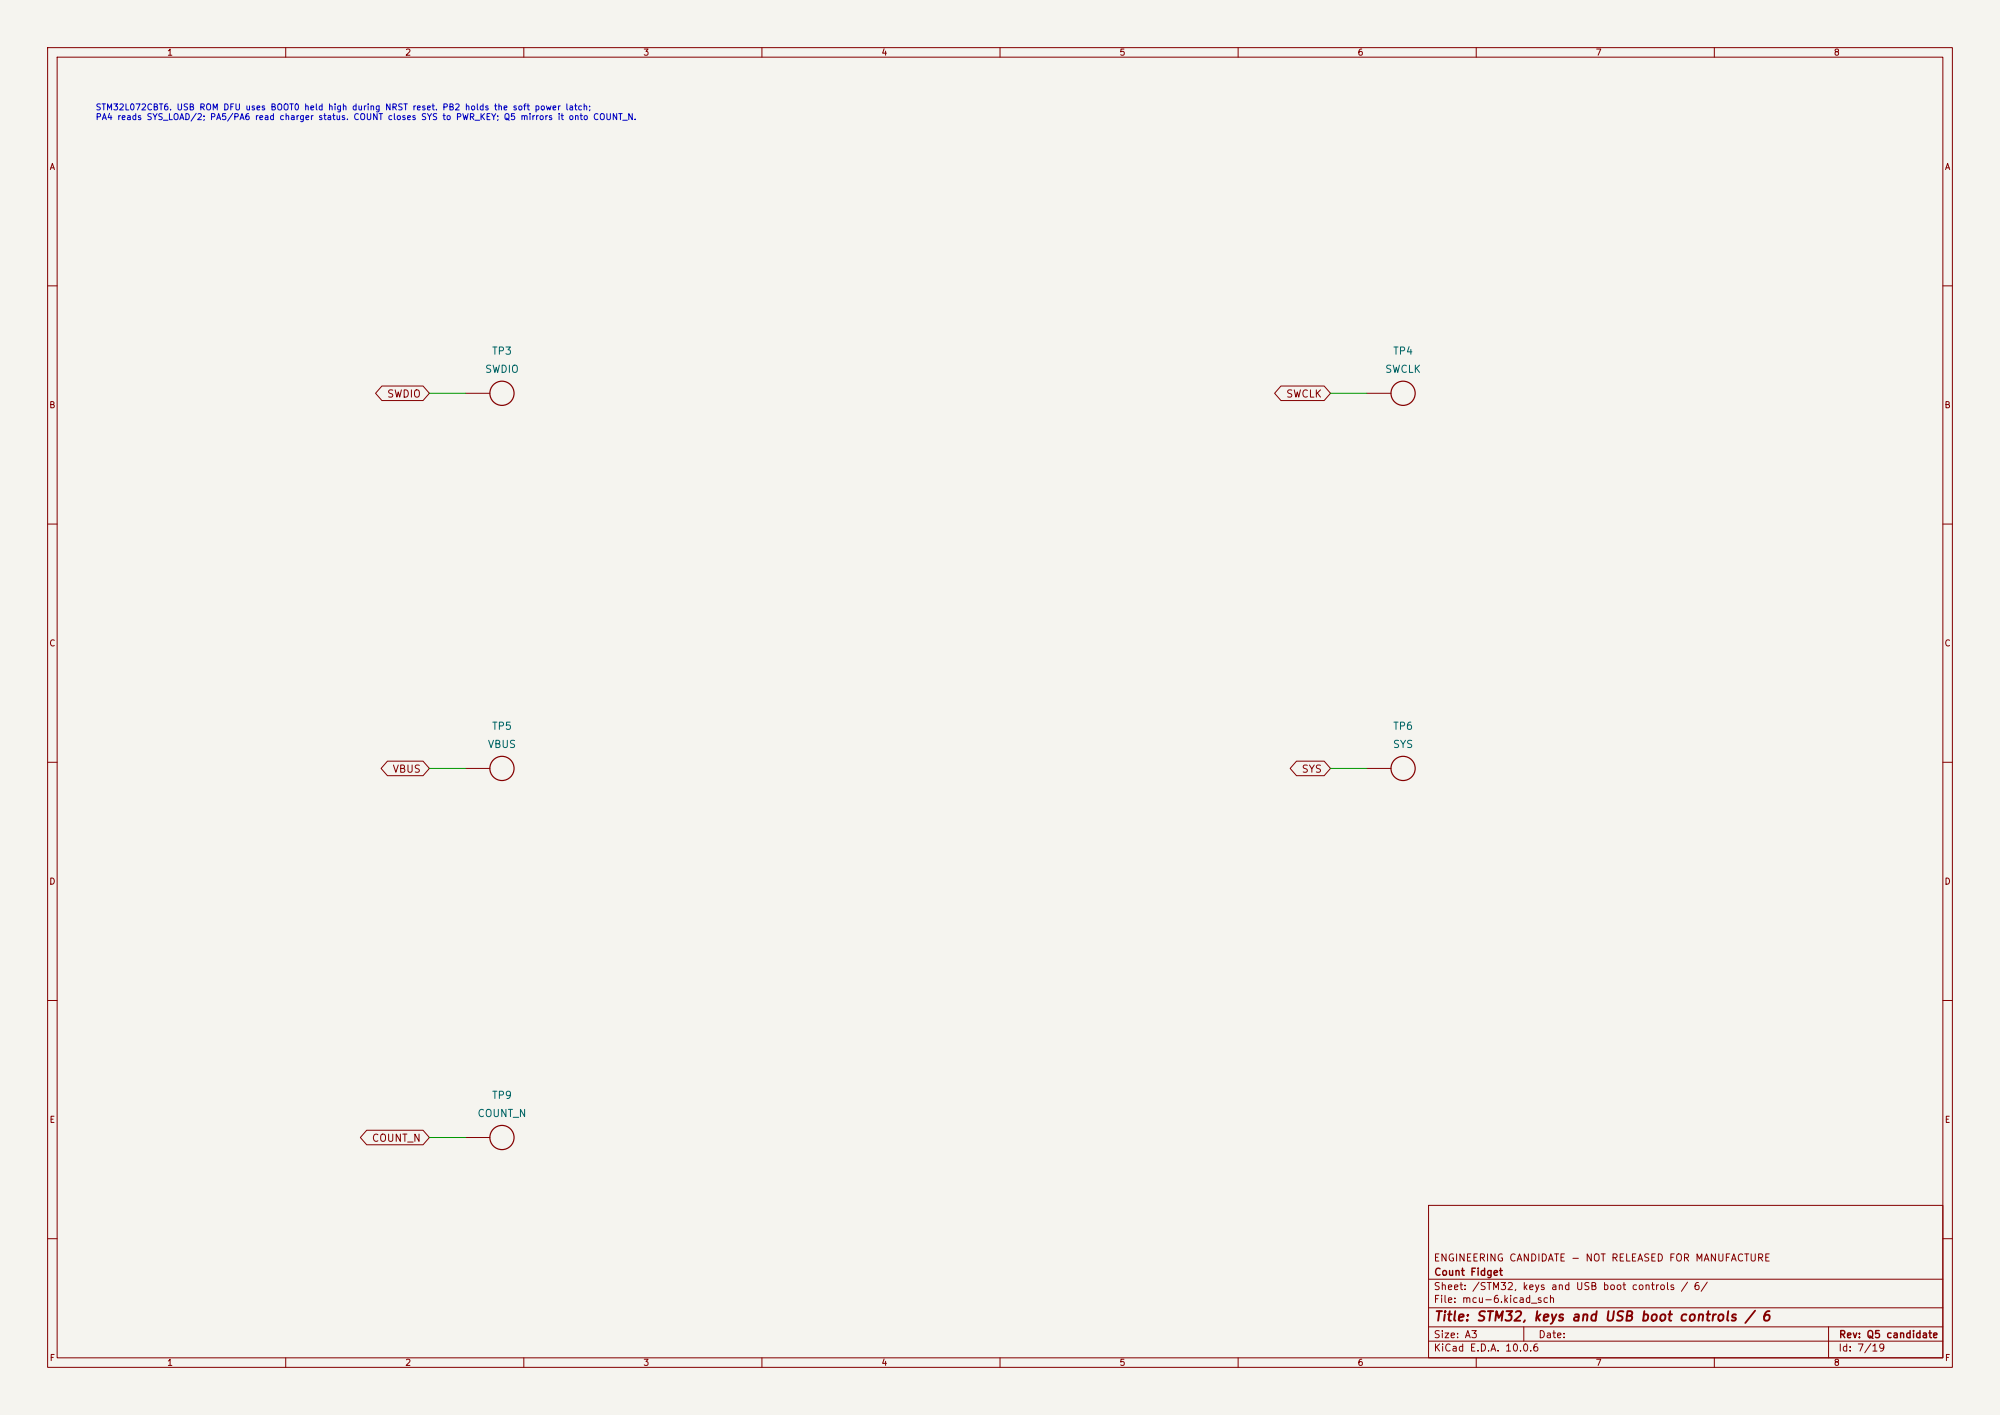
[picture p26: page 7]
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

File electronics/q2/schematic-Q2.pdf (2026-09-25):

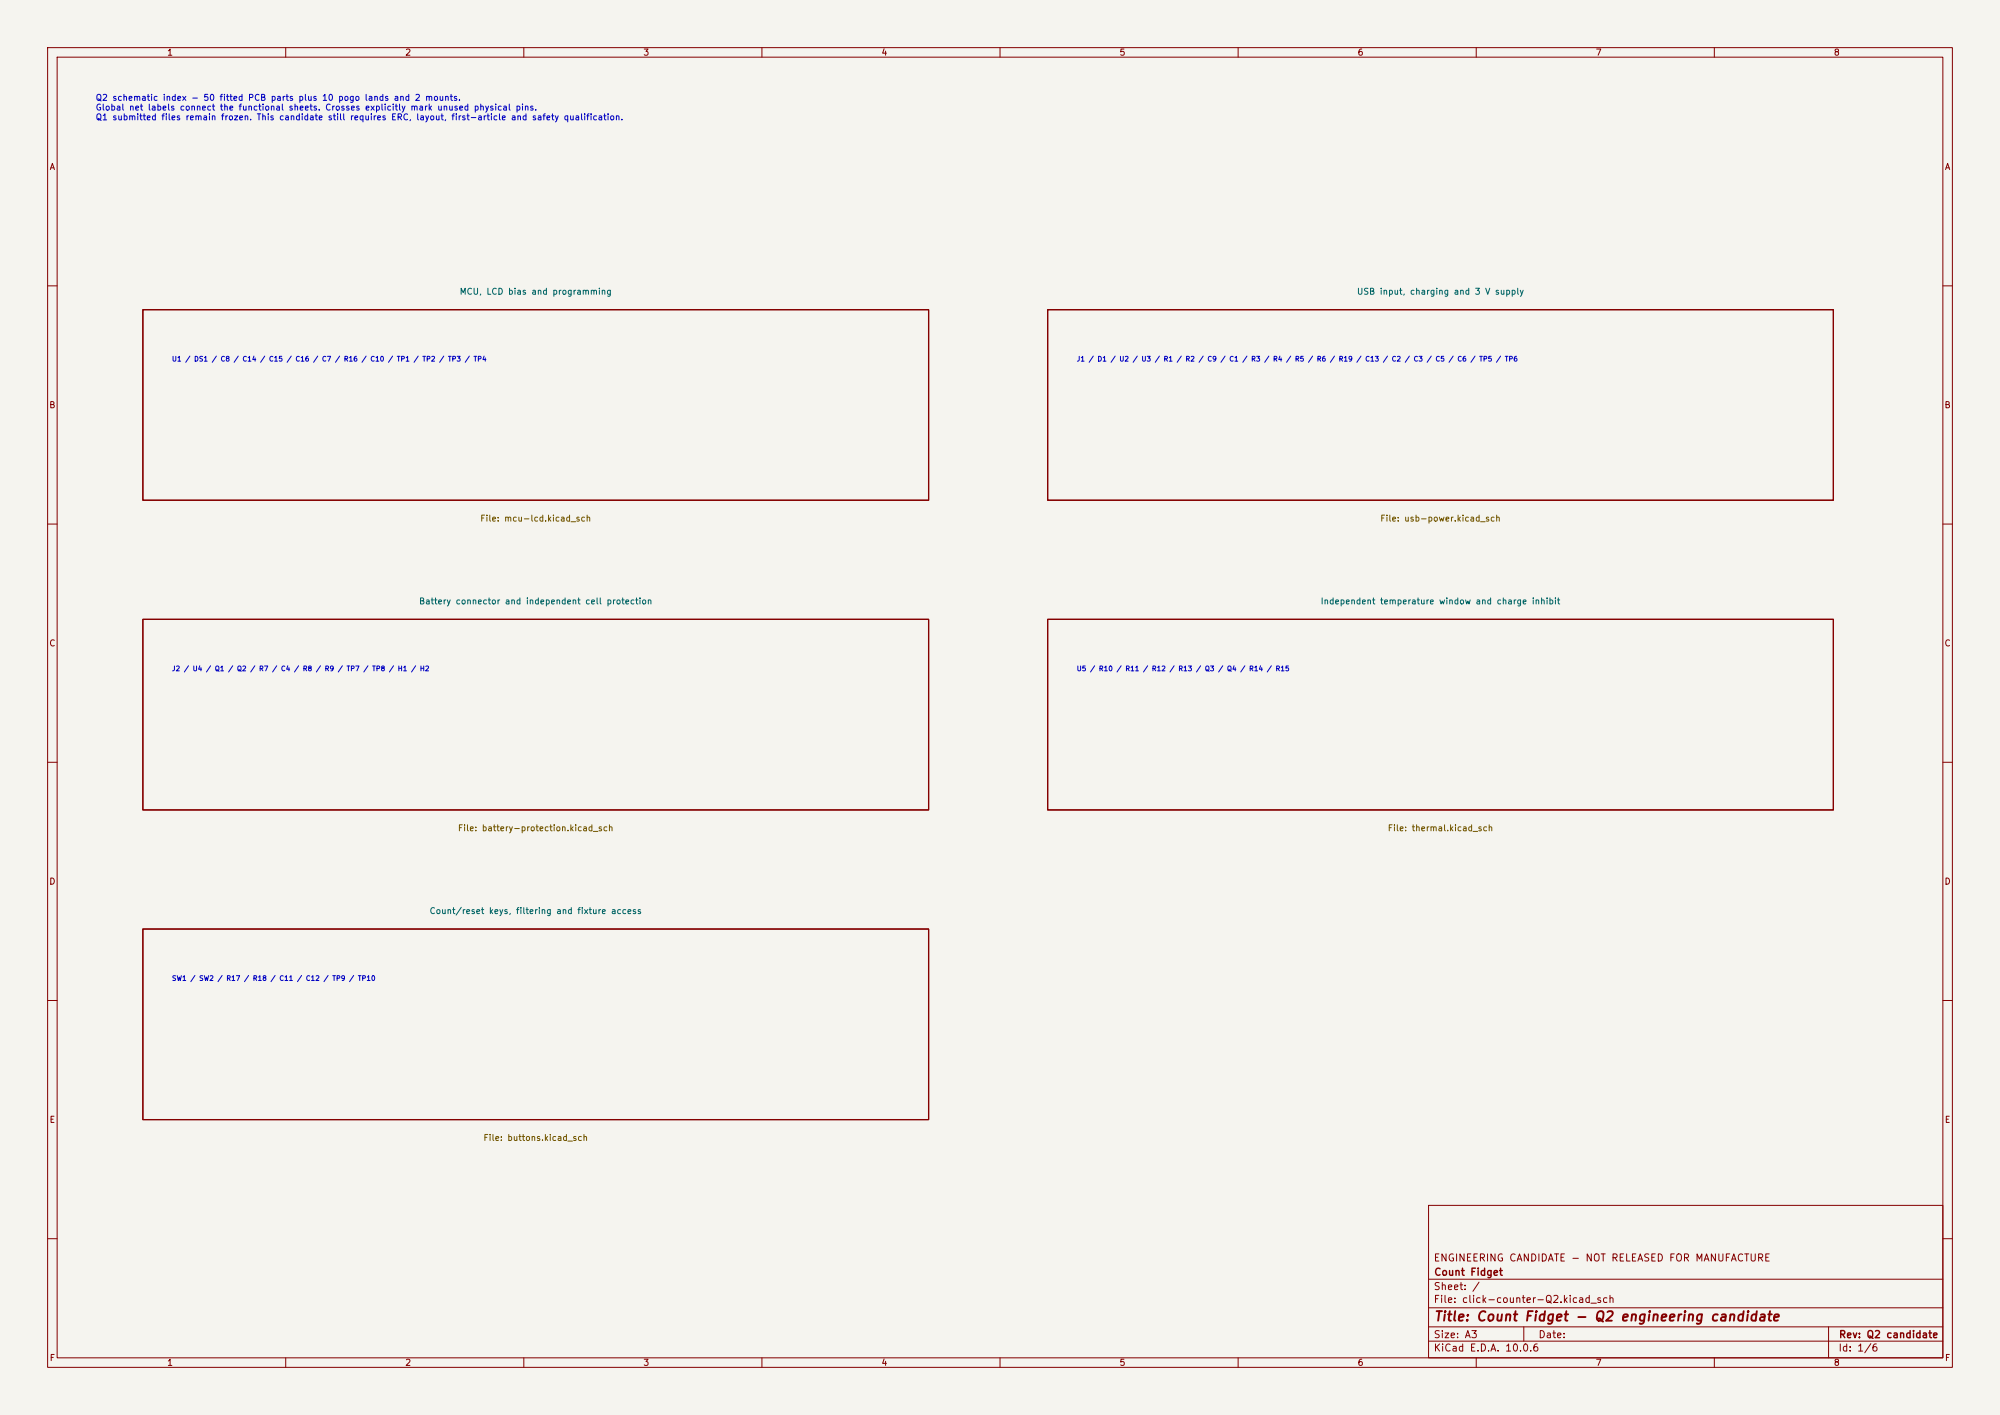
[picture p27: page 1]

Q2 schematic index - 50 fitted PCB parts plus 10 pogo lands and 2 mounts. Global net labels connect the functional sheets. Crosses explicitly mark unused physical pins. Q1 submitted files remain frozen. This candidate still requires ERC, layout, first-article and safety qualification. U1 / DS1 / C8 / C14 / C15 / C16 / C7 / R16 / C10 / TP1 / TP2 / TP3 / TP4

MCU, LCD bias and programming

USB input, charging and 3 V supply File: usb-power.kicad_sch

File: mcu-lcd.kicad_sch Battery connector and independent cell protection

Independent temperature window and charge inhibit File: thermal.kicad_sch

Count/reset keys, filtering and fixture access File: buttons.kicad_sch

ENGINEERING CANDIDATE - NOT RELEASED FOR MANUFACTURE
Count Fidget
Sheet: /
File: click-counter-Q2.kicad_sch
Title: Count Fidget - Q2 engineering candidate

Size: A3 | Rev: Q2 candidate | F Date:
KiCad E.D.A. 10.0.6 | Id: 1/6

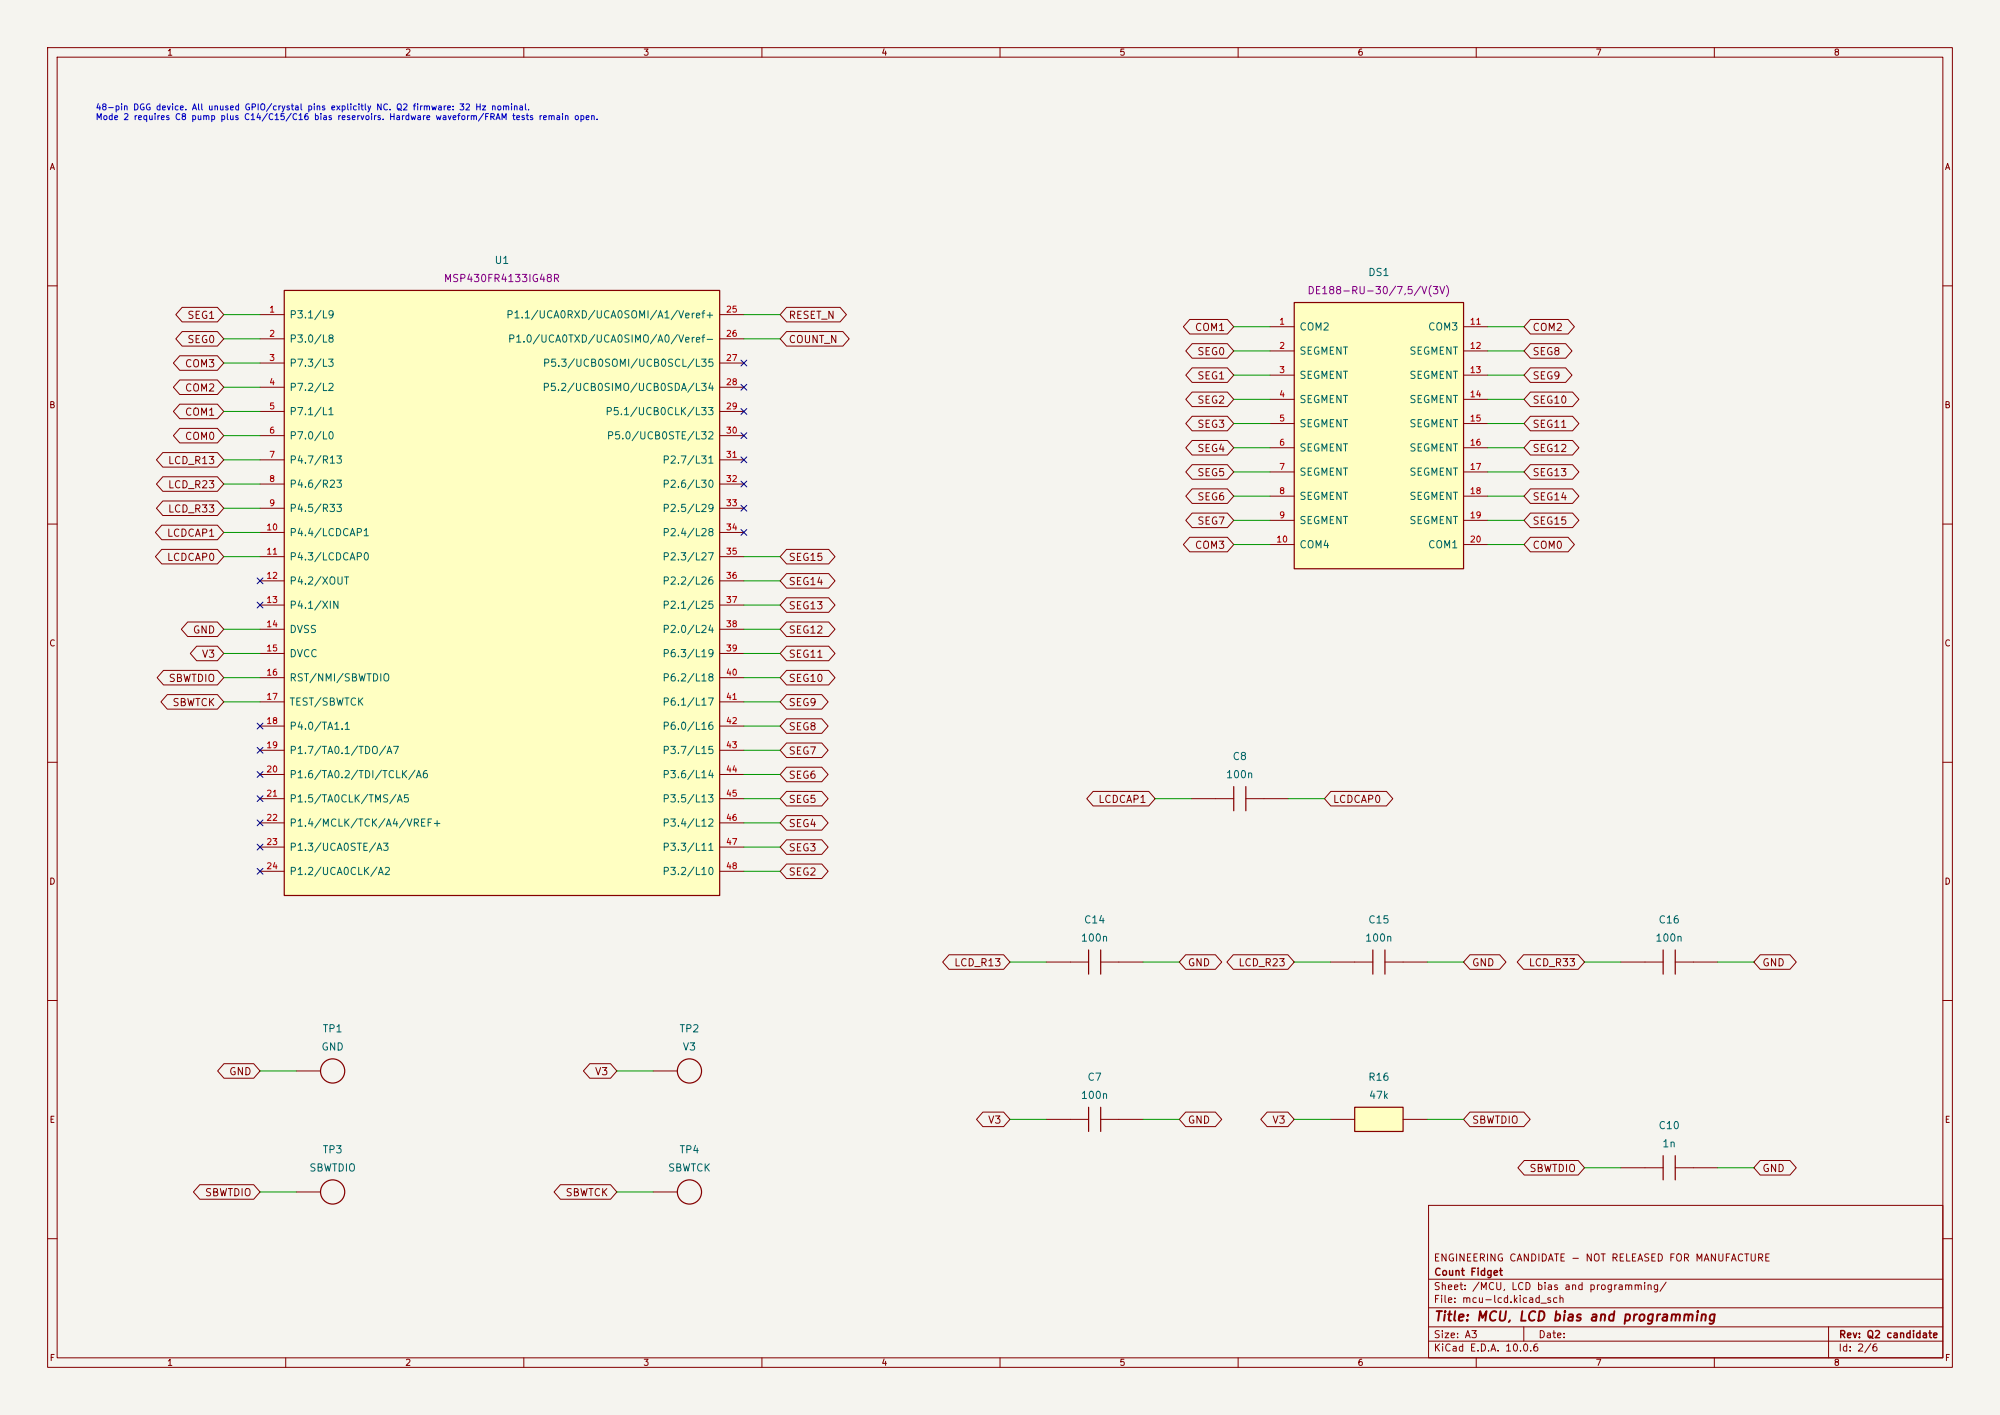
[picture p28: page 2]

48-pin DGG device. All unused GPIO/crystal pins explicitly NC. Q2 firmware: 32 Hz nominal. Mode 2 requires C8 pump plus C14/C15/C16 bias reservoirs. Hardware waveform/FRAM tests remain open.

ENGINEERING CANDIDATE - NOT RELEASED FOR MANUFACTURE
Count Fidget
Sheet: /MCU, LCD bias and programming/
File: mcu-lcd.kicad_sch
Title: MCU, LCD bias and programming

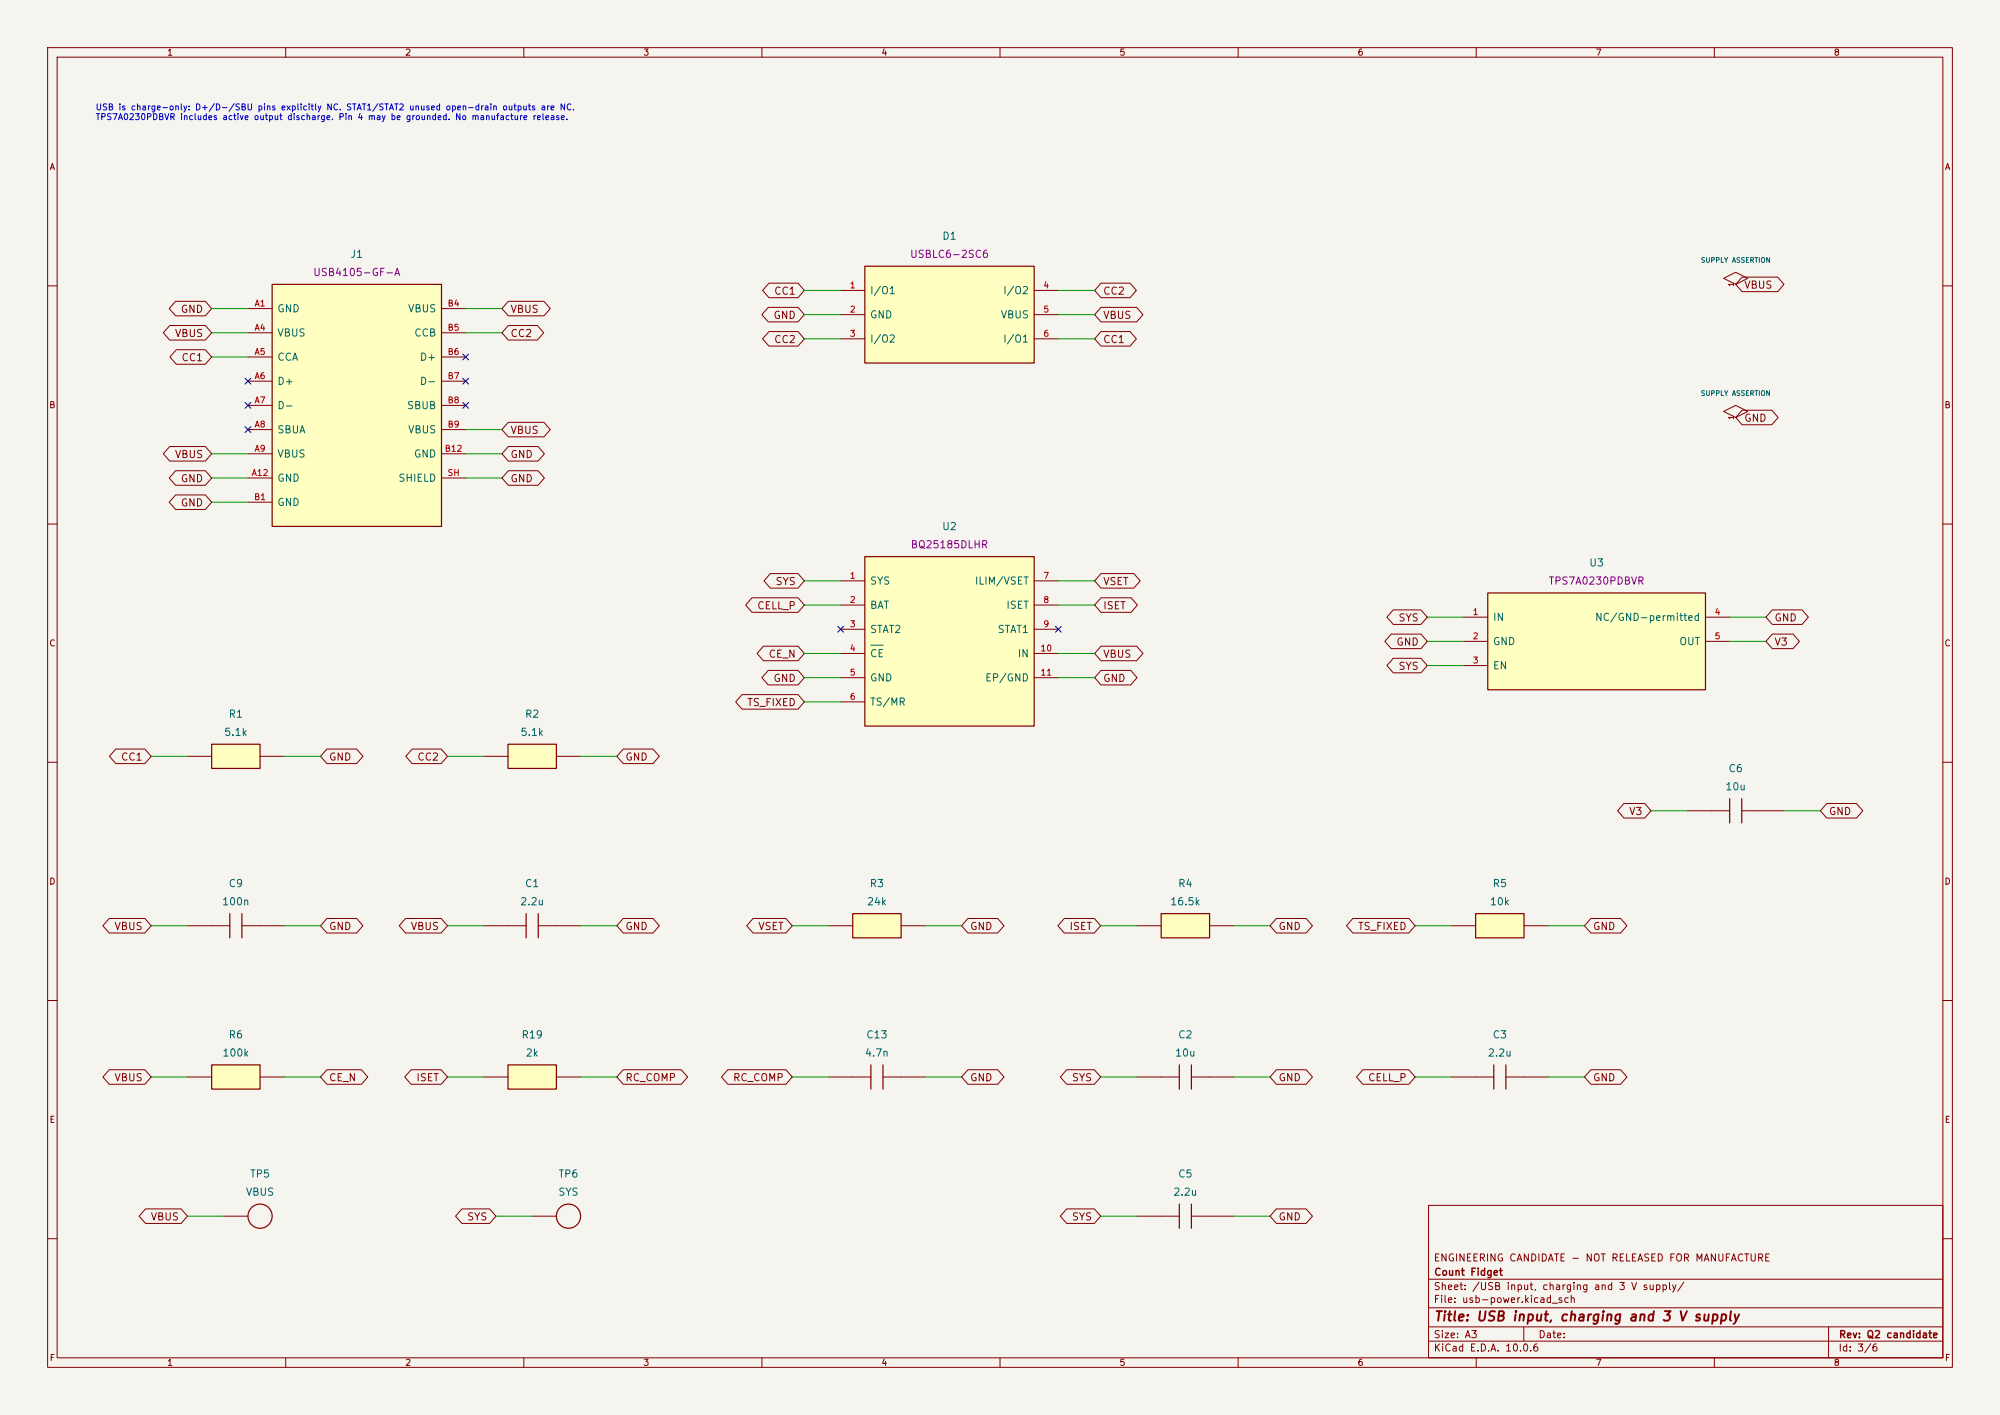
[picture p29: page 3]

USB is charge-only: D+/D-/SBU pins explicitly NC. STAT1/STAT2 unused open-drain outputs are NC. TPS7A0230PDBVR includes active output discharge. Pin 4 may be grounded. No manufacture release.

ENGINEERING CANDIDATE - NOT RELEASED FOR MANUFACTURE
Count Fidget
Sheet: /USB input, charging and 3 V supply/
File: usb-power.kicad_sch
Title: USB input, charging and 3 V supply

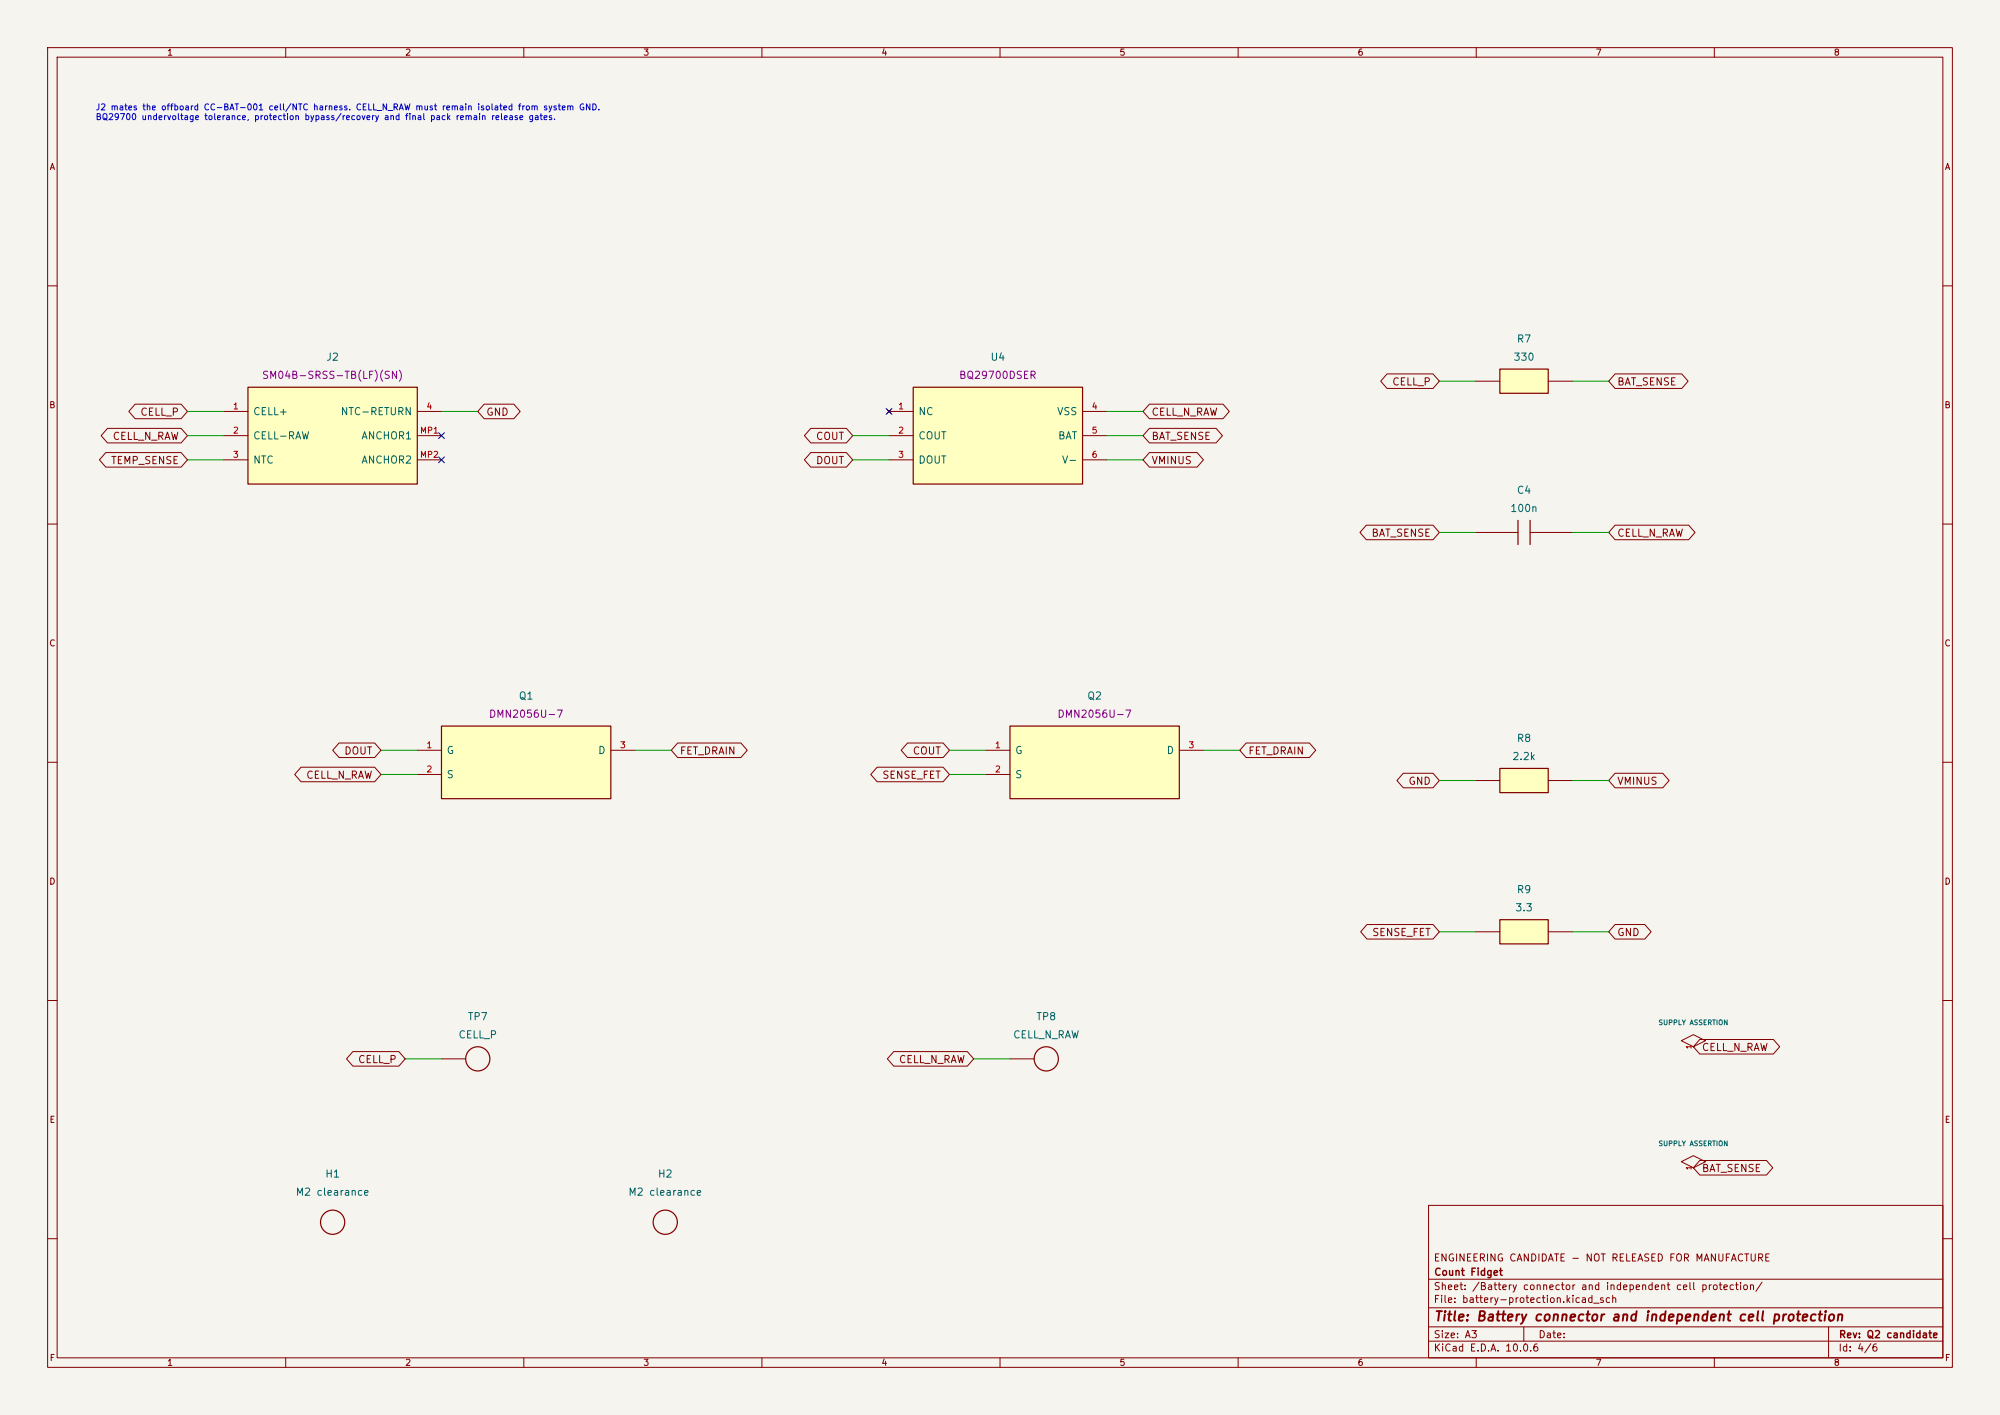
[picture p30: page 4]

J2 mates the offboard CC-BAT-001 cell/NTC harness. CELL_N_RAW must remain isolated from system GND. BQ29700 undervoltage tolerance, protection bypass/recovery and final pack remain release gates.

SM04B-SRSS-TB(LF)(SN)

ENGINEERING CANDIDATE - NOT RELEASED FOR MANUFACTURE
Count Fidget
Sheet: /Battery connector and independent cell protection/
File: battery-protection.kicad_sch
Title: Battery connector and independent cell protection

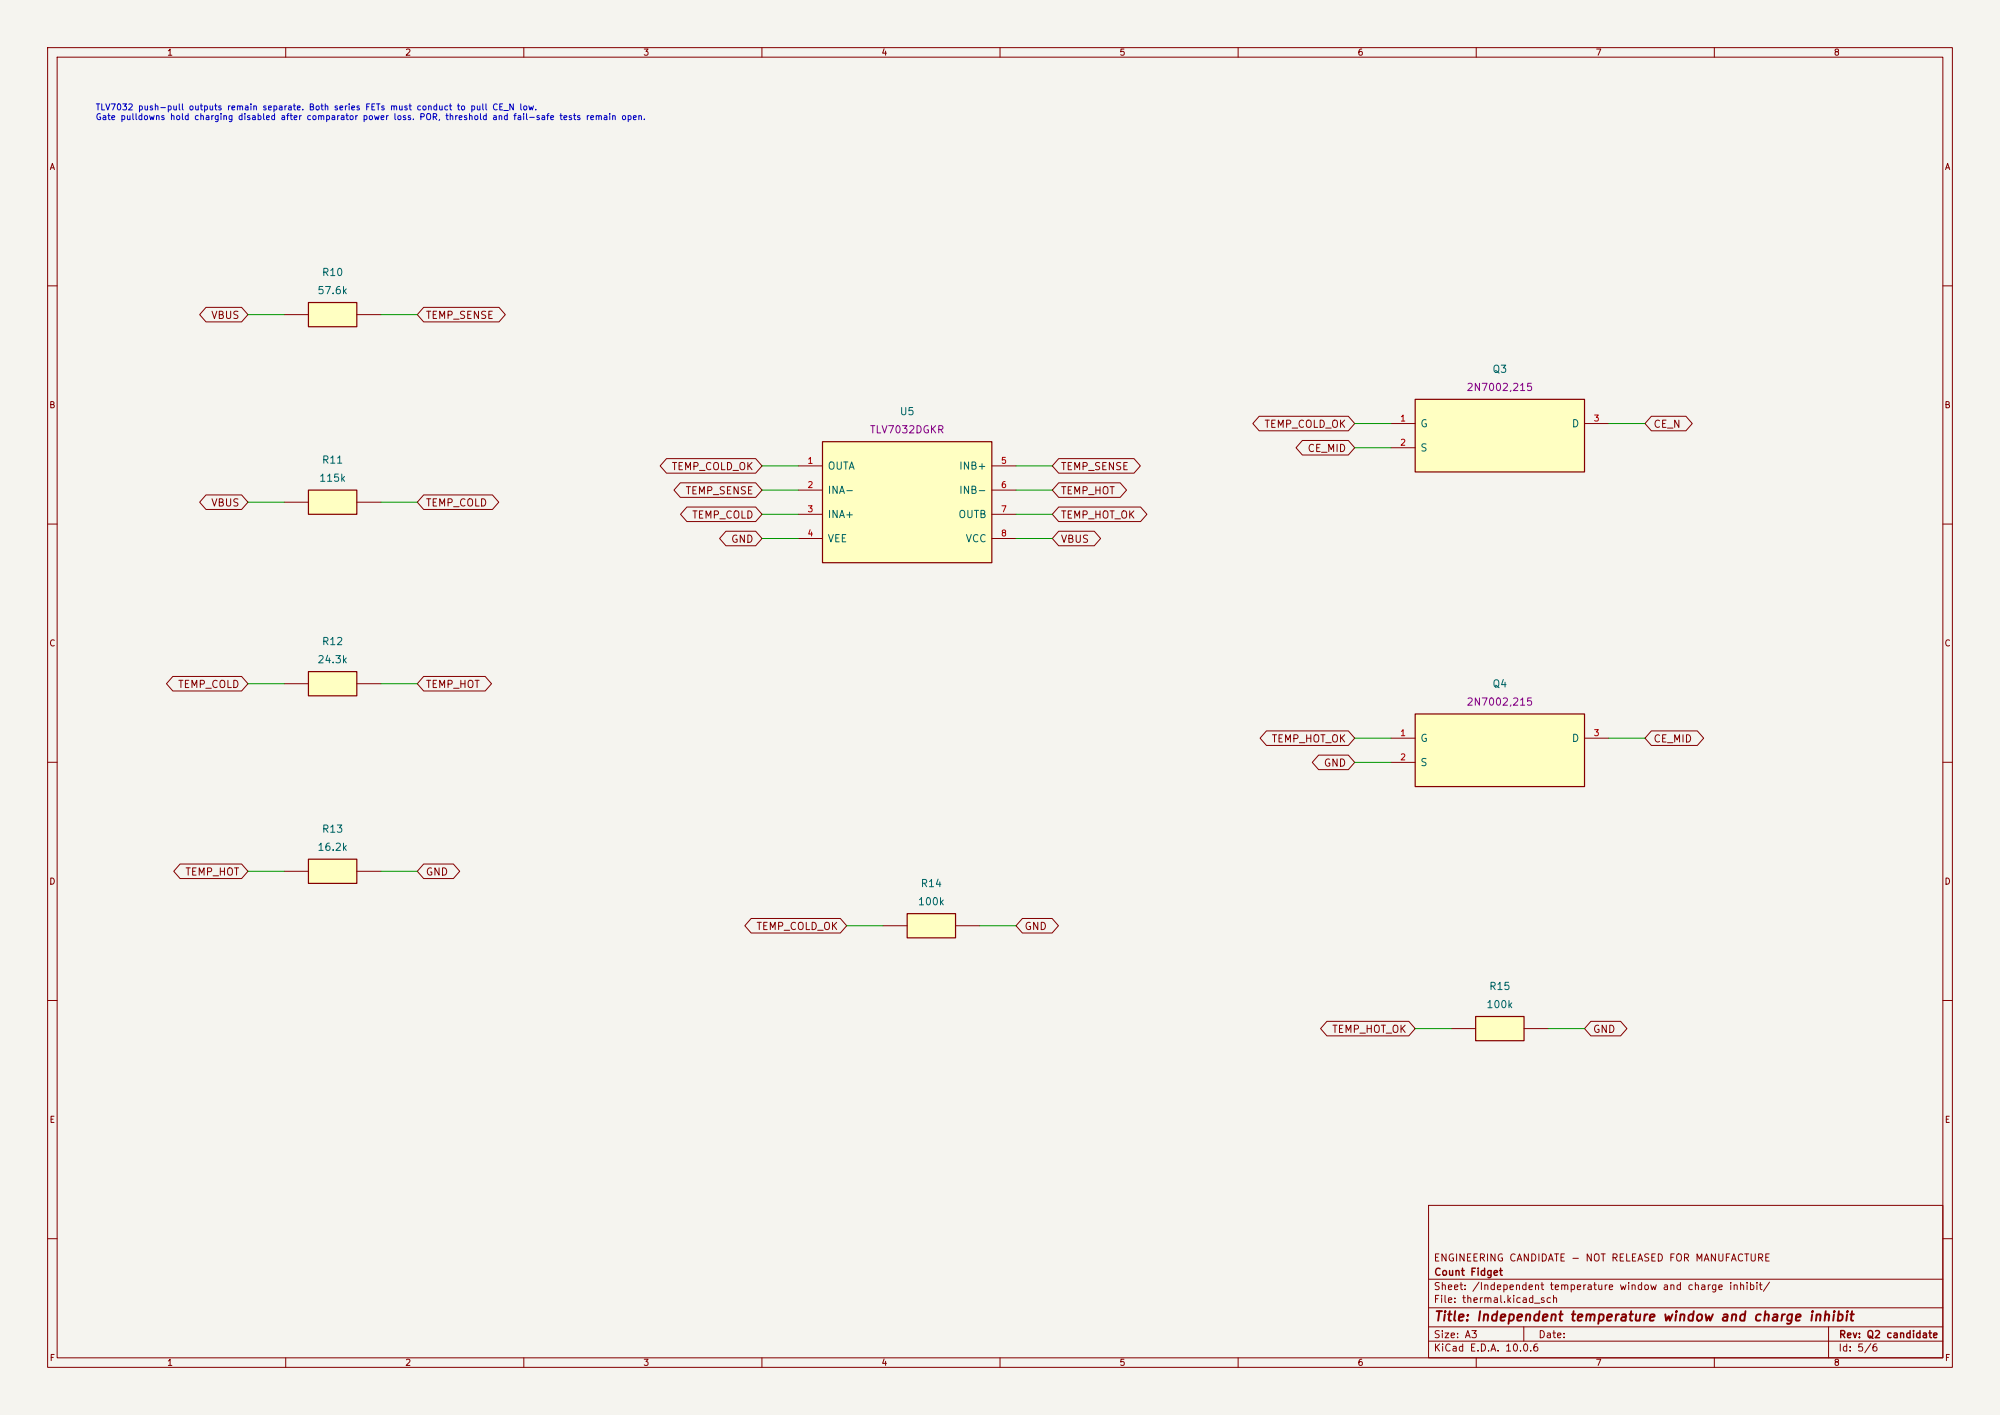
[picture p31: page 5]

TLV7032 push-pull outputs remain separate. Both series FETs must conduct to pull CE_N low. Gate pulldowns hold charging disabled after comparator power loss. POR, threshold and fail-safe tests remain open.

ENGINEERING CANDIDATE - NOT RELEASED FOR MANUFACTURE
Count Fidget
Sheet: /Independent temperature window and charge inhibit/
File: thermal.kicad_sch
Title: Independent temperature window and charge inhibit

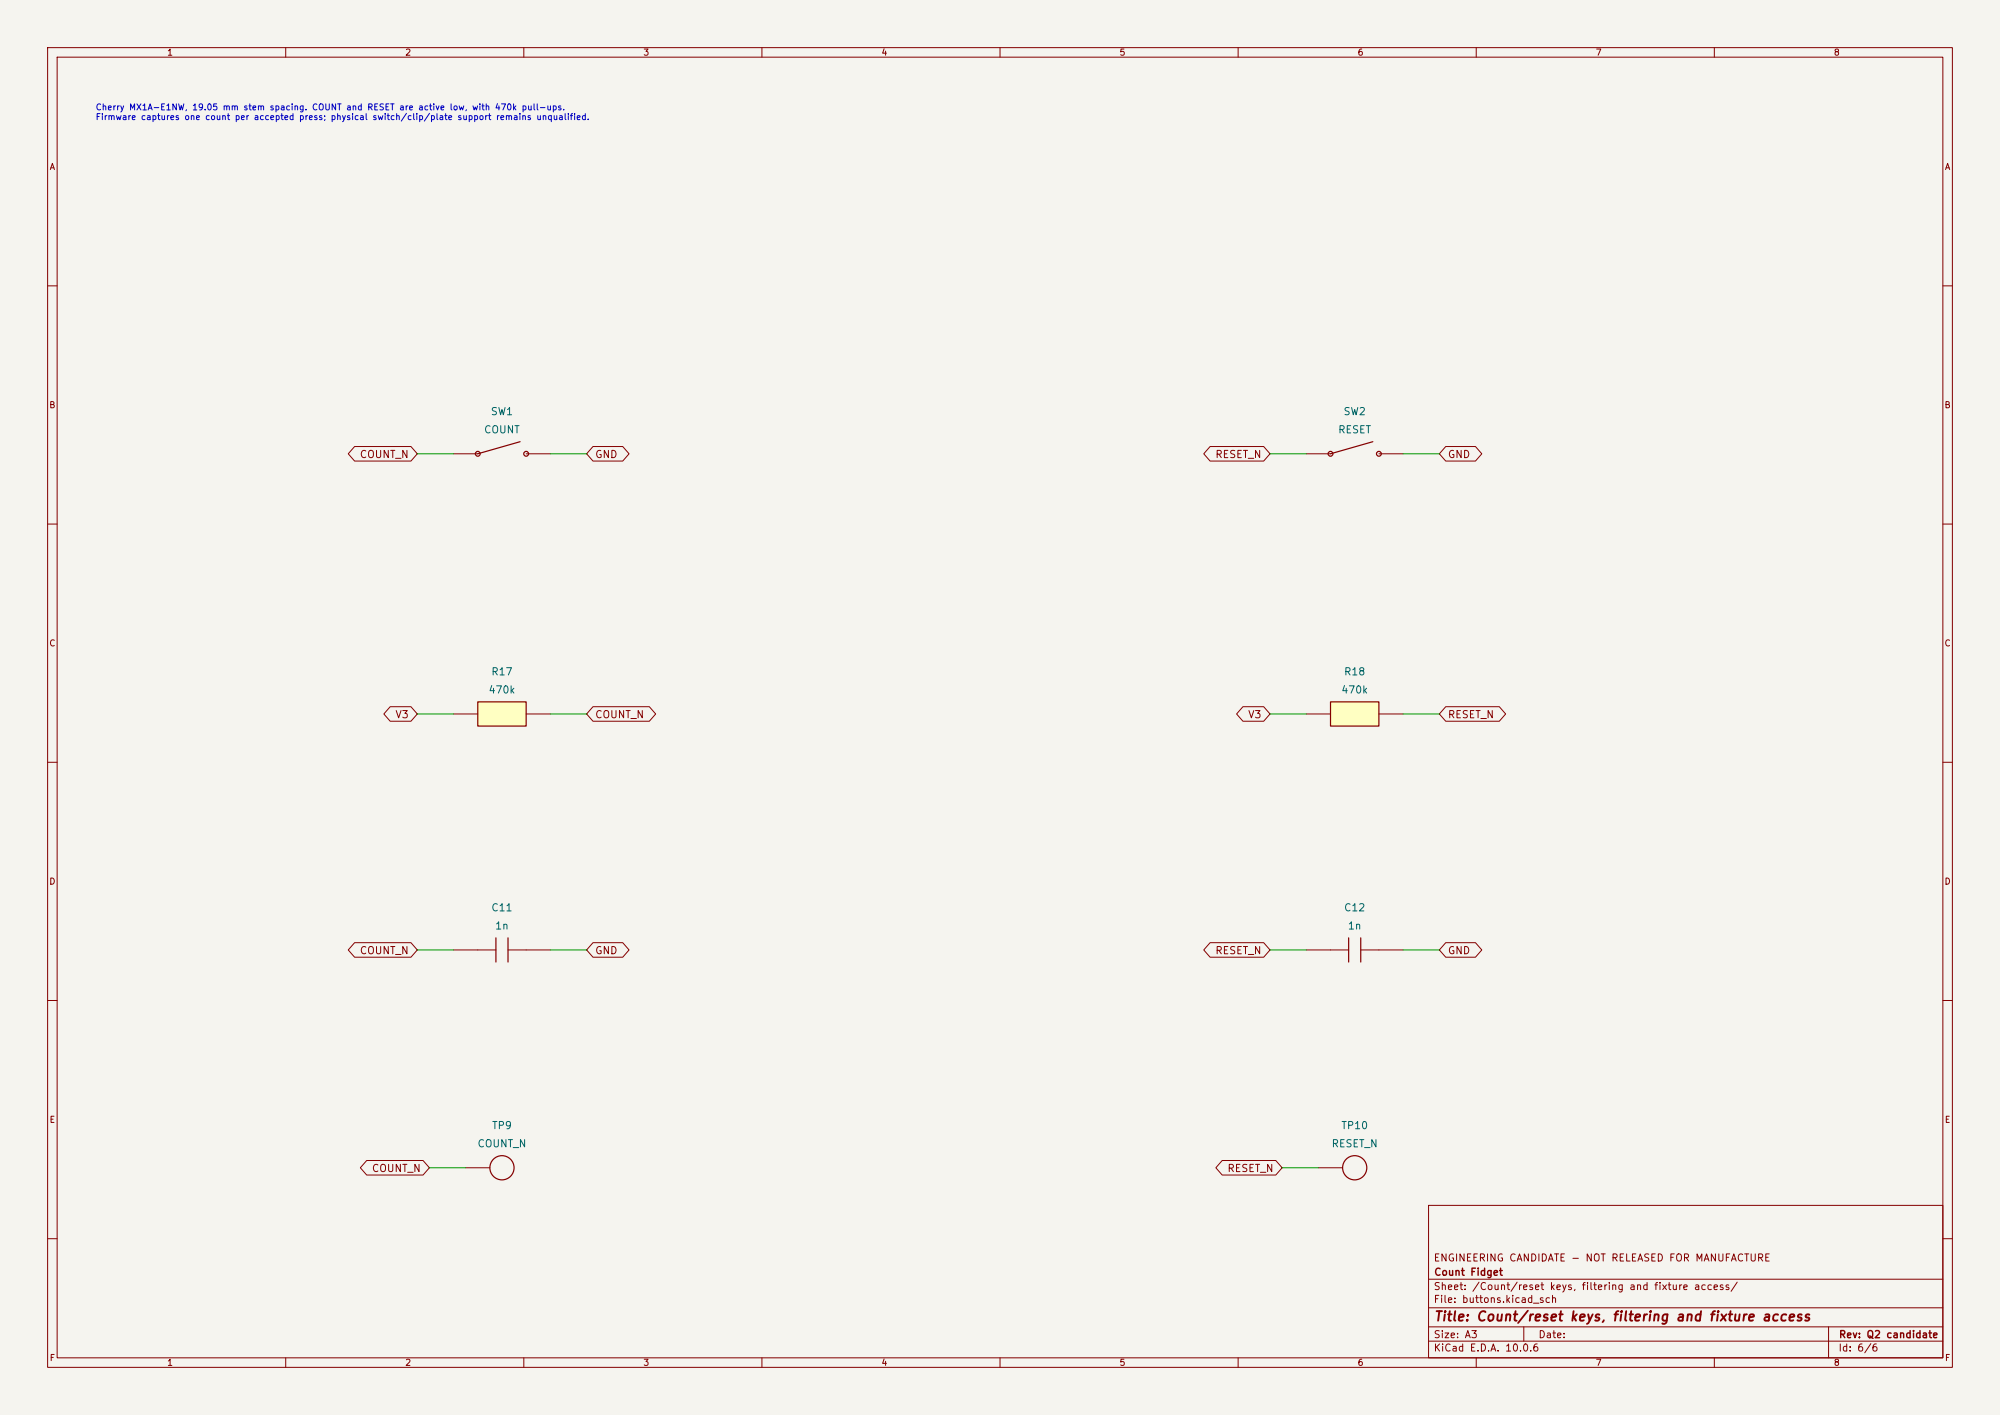
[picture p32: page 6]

Cherry MX1A-E1NW, 19.05 mm stem spacing. COUNT and RESET are active low, with 470k pull-ups. Firmware captures one count per accepted press; physical switch/clip/plate support remains unqualified.

ENGINEERING CANDIDATE - NOT RELEASED FOR MANUFACTURE
Count Fidget
Sheet: /Count/reset keys, filtering and fixture access/
File: buttons.kicad_sch
Title: Count/reset keys, filtering and fixture access

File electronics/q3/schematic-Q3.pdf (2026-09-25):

1 | 2 | 3 | 4 | 5 | 6 | 7 | 8

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
Size: A3 | Rev: Q3 candidate | F Date:
KiCad E.D.A. 10.0.6 | Id: 1/8

### Title: Count Fidget - Q3 engineering candidate

File: click-counter-Q3.kicad_sch

Sheet: /

Count Fidget

ENGINEERING CANDIDATE - NOT RELEASED FOR MANUFACTURE

FRAM MCU and programming

File: mcu.kicad_sch Battery connector and independent cell protection

File: battery-protection.kicad_sch

USB input, charging and 3 V supply File: usb-power.kicad_sch

Independent temperature window and charge inhibit File: thermal.kicad_sch OLED 4 V buck-boost and pump isolation

File: oled-power.kicad_sch

Count/reset keys, filtering and fixture access File: buttons.kicad_sch SSD1312 OLED and support parts File: oled-panel.kicad_sch

Q3 schematic index - 70 fitted PCB parts plus 10 pogo lands and 2 mounts. Global net labels connect the functional sheets. Crosses explicitly mark unused physical pins. Q1 submitted files remain frozen. This candidate still requires ERC, layout, first-article and safety qualification. U1 / C6 / C7 / R16 / C10 / TP1 / TP2 / TP3 / TP4

J2 / U4 / Q1 / Q2 / R7 / C4 / R8 / R9 / TP7 / TP8 / H1 / H2

J1 / D1 / U2 / U3 / R1 / R2 / C9 / C1 / R3 / R4 / R5 / R6 / R19 / C13 / C2 / C3 / C5 / TP5 / TP6 U5 / R10 / R11 / R12 / R13 / Q3 / Q4 / R14 / R15

SW1 / SW2 / R17 / R18 / C11 / C12 / TP9 / TP10 | U6 / L1 / C17 / C18 / C19 / R20 / R21 / R22 / Q5 / Q6 / R23 / R24 DS1 / C20 / C21 / C22 / C23 / C24 / C25 / C26 / C27 / R25 / R26 / R27 / R28


48-pin FRAM MCU retained; unused LCD/GPIO pins explicitly NC. OLED uses hardware I2C. P1.2 enables the 4V rail; P1.3 holds OLED reset. Count retention and physical power-fall tests remain open.

ENGINEERING CANDIDATE - NOT RELEASED FOR MANUFACTURE
Count Fidget
Sheet: /FRAM MCU and programming/
File: mcu.kicad_sch
Title: FRAM MCU and programming


USB is charge-only: D+/D-/SBU pins explicitly NC. STAT1/STAT2 unused open-drain outputs are NC. TPS7A0230PDBVR includes active output discharge. Pin 4 may be grounded. No manufacture release.

ENGINEERING CANDIDATE - NOT RELEASED FOR MANUFACTURE
Count Fidget
Sheet: /USB input, charging and 3 V supply/
File: usb-power.kicad_sch
Title: USB input, charging and 3 V supply


J2 mates the offboard CC-BAT-001 cell/NTC harness. CELL_N_RAW must remain isolated from system GND. BQ29700 undervoltage tolerance, protection bypass/recovery and final pack remain release gates.

SM04B-SRSS-TB(LF)(SN)

ENGINEERING CANDIDATE - NOT RELEASED FOR MANUFACTURE
Count Fidget
Sheet: /Battery connector and independent cell protection/
File: battery-protection.kicad_sch
Title: Battery connector and independent cell protection


TLV7012 push-pull outputs remain separate. Both series FETs must conduct to pull CE_N low. Gate pulldowns hold charging disabled after comparator power loss. POR, threshold and fail-safe tests remain open.

ENGINEERING CANDIDATE - NOT RELEASED FOR MANUFACTURE
Count Fidget
Sheet: /Independent temperature window and charge inhibit/
File: thermal.kicad_sch
Title: Independent temperature window and charge inhibit


HanElectricity CPG151101D13, 19.05 mm stem spacing; active-low keys with 220k pull-ups. Firmware captures one count per accepted press; physical switch/clip/plate support remains unqualified.

ENGINEERING CANDIDATE - NOT RELEASED FOR MANUFACTURE
Count Fidget
Sheet: /Count/reset keys, filtering and fixture access/
File: buttons.kicad_sch
Title: Count/reset keys, filtering and fixture access


TPS63900DSKR:4.0V,10mA AVERAGE input setting; not a guaranteed peak clamp.
Q5/Q6 disconnect pump input during sleep; GPIO defaults low. Existing battery protection unchanged.

ENGINEERING CANDIDATE - NOT RELEASED FOR MANUFACTURE
Count Fidget
Sheet: /OLED 4 V buck-boost and pump isolation/
File: oled-power.kicad_sch
Title: OLED 4 V buck-boost and pump isolation


Exact X087-2832TSWIG02-H14;1C2P,2C2N,3C1P,4C1N,5VBAT,6NC,7GND,8VDD. External750k IREF;9V internal pump. FPC process, sequencing, current and readability require qualification.

ENGINEERING CANDIDATE - NOT RELEASED FOR MANUFACTURE
Count Fidget
Sheet: /SSD1312 OLED and support parts/
File: oled-panel.kicad_sch
Title: SSD1312 OLED and support parts

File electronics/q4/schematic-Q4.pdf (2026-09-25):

1 | 2 | 3 | 4 | 5 | 6 | 7 | 8

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
Size: A3 | Rev: Q4 candidate | F Date:
KiCad E.D.A. 10.0.6 | Id: 1/18

## Title: Count Fidget - Q4 engineering candidate

File: click-counter-Q4.kicad_sch

Sheet: /

Count Fidget

ENGINEERING CANDIDATE - NOT RELEASED FOR MANUFACTURE

STM32 and USB boot controls / 3

File: mcu-3.kicad_sch STM32 and USB boot controls / 6

File: mcu-6.kicad_sch

STM32 and USB boot controls File: mcu-1.kicad_sch STM32 and USB boot controls / 4

File: mcu-4.kicad_sch

STM32 and USB boot controls / 2

File: mcu-2.kicad_sch STM32 and USB boot controls / 5

File: mcu-5.kicad_sch SPI OLED module and power control / 1

File: display-1.kicad_sch USB, charging and common supply / 1

File: usb-power-1.kicad_sch USB, charging and common supply / 4

File: usb-power-4.kicad_sch Independent charge-temperature window / 1

File: thermal-1.kicad_sch

Battery connection and protection / 2

# File: battery-2.kicad_sch USB, charging and common supply / 3

File: usb-power-3.kicad_sch

Independent SPI retained-count memory / 1

File: memory-1.kicad_sch

Independent charge-temperature window / 2

File: thermal-2.kicad_sch

Battery connection and protection / 1

# File: battery-1.kicad_sch USB, charging and common supply / 2

File: usb-power-2.kicad_sch

SPI OLED module and power control / 2

File: display-2.kicad_sch C28

TP9 / TP10 / H1 / H2 / SW3 / TP11 DS1 / U6 / R24 / R25 / C20 / R29

# J1 / U2 / U3 / D1 / R1 / R2 R31 / C29 / C38 / C39 / D2 U5 / Q3 / R10 / R11 / R12 / R13

SW1 / SW2 / R16 / R17 / R18 / C7

TP3 / TP4 / TP5 / TP6 / TP7 / TP8 | R3 / R4 / R5 / R6 / R19 / C1

U1 / C31 / C32 / C33 / C34

J2 / U4 / Q1 / Q2 / R7 / R8

Q4 schematic index - 70 fitted PCB parts plus non-fitted test lands and mounts. Global net labels connect the functional sheets. Crosses explicitly mark unused physical pins. Q1 submitted files remain frozen. This candidate still requires ERC, layout, first-article and safety qualification.

R14 / R15 / C9 / Q4

U8 / R32 / R33 / C30 / C36

# TP12 / C35 / H3 / H4 C2 / C3 / C5 / C13 / U7 / R30

C6 / C10 / C11 / C12 / TP1 / TP2

R9 / C4


STM32L072CBT6. USB ROM DFU uses BOOT0 held high during NRST reset. All supplies share VLOGIC; unused physical pins are explicitly NC. SWD is retained.

ENGINEERING CANDIDATE - NOT RELEASED FOR MANUFACTURE
Count Fidget
Sheet: /STM32 and USB boot controls/
File: mcu-1.kicad_sch
Title: STM32 and USB boot controls

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

ENGINEERING CANDIDATE - NOT RELEASED FOR MANUFACTURE
Count Fidget
Sheet: /STM32 and USB boot controls / 2/
File: mcu-2.kicad_sch
Title: STM32 and USB boot controls / 2

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

ENGINEERING CANDIDATE - NOT RELEASED FOR MANUFACTURE
Count Fidget
Sheet: /STM32 and USB boot controls / 3/
File: mcu-3.kicad_sch
Title: STM32 and USB boot controls / 3

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

ENGINEERING CANDIDATE - NOT RELEASED FOR MANUFACTURE
Count Fidget
Sheet: /STM32 and USB boot controls / 4/
File: mcu-4.kicad_sch
Title: STM32 and USB boot controls / 4


ENGINEERING CANDIDATE - NOT RELEASED FOR MANUFACTURE
Count Fidget
Sheet: /STM32 and USB boot controls / 5/
File: mcu-5.kicad_sch
Title: STM32 and USB boot controls / 5

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

ENGINEERING CANDIDATE - NOT RELEASED FOR MANUFACTURE
Count Fidget
Sheet: /STM32 and USB boot controls / 6/
File: mcu-6.kicad_sch
Title: STM32 and USB boot controls / 6


Complete HS96L01W4S03 module; seven-pin SPI interface. Signals must be high impedance before module power is disabled. Mechanical drawing controls the footprint.

ENGINEERING CANDIDATE - NOT RELEASED FOR MANUFACTURE
Count Fidget
Sheet: /SPI OLED module and power control / 1/
File: display-1.kicad_sch
Title: SPI OLED module and power control / 1

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

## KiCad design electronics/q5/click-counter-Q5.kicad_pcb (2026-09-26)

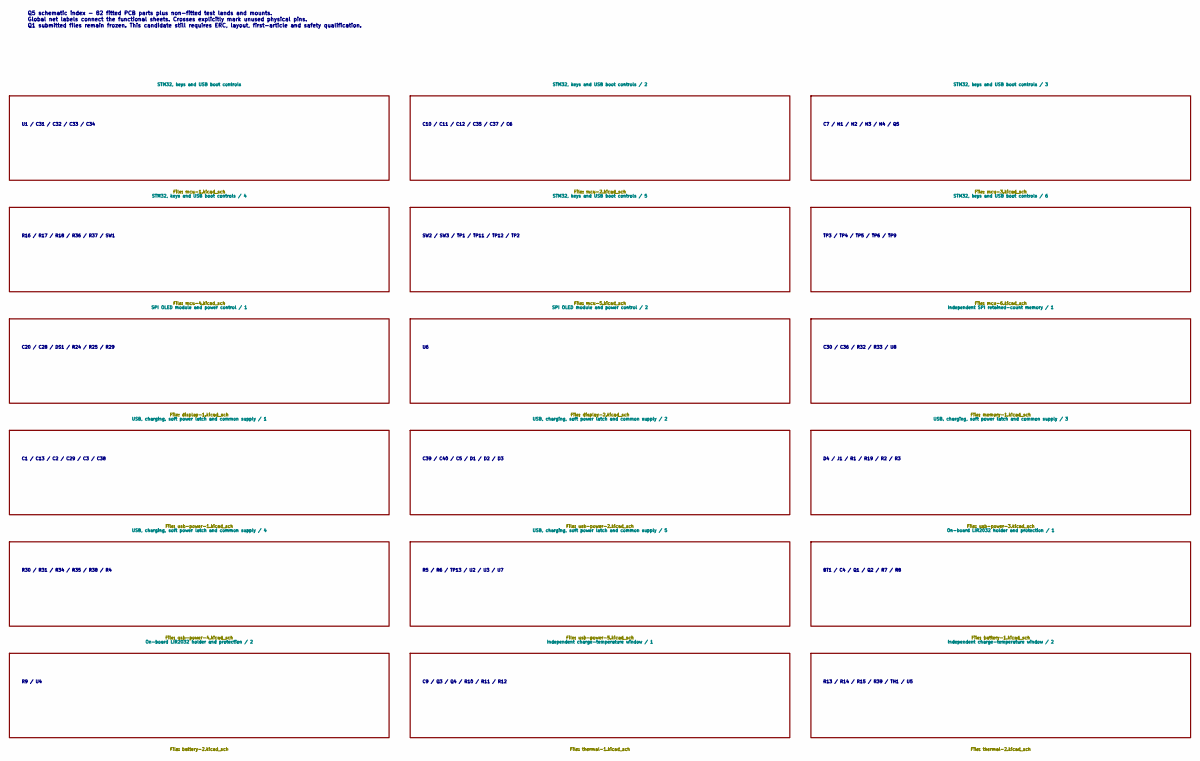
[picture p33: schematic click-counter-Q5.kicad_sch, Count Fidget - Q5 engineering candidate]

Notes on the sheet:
Q5 schematic index - 82 fitted PCB parts plus non-fitted test lands and mounts. Global net labels connect the functional sheets. Crosses explicitly mark unused physical pins. Q1 submitted files remain frozen. This candidate still requires ERC, layout, first-article and safety qualification.
U1 / C31 / C32 / C33 / C34
C10 / C11 / C12 / C35 / C37 / C6
C7 / H1 / H2 / H3 / H4 / Q5
R16 / R17 / R18 / R36 / R37 / SW1
SW2 / SW3 / TP1 / TP11 / TP12 / TP2
TP3 / TP4 / TP5 / TP6 / TP9
C20 / C28 / DS1 / R24 / R25 / R29
C30 / C36 / R32 / R33 / U8
C1 / C13 / C2 / C29 / C3 / C38
C39 / C40 / C5 / D1 / D2 / D3
D4 / J1 / R1 / R19 / R2 / R3
R30 / R31 / R34 / R35 / R38 / R4
R5 / R6 / TP13 / U2 / U3 / U7
BT1 / C4 / Q1 / Q2 / R7 / R8
R9 / U4
C9 / Q3 / Q4 / R10 / R11 / R12
R13 / R14 / R15 / R39 / TH1 / U5

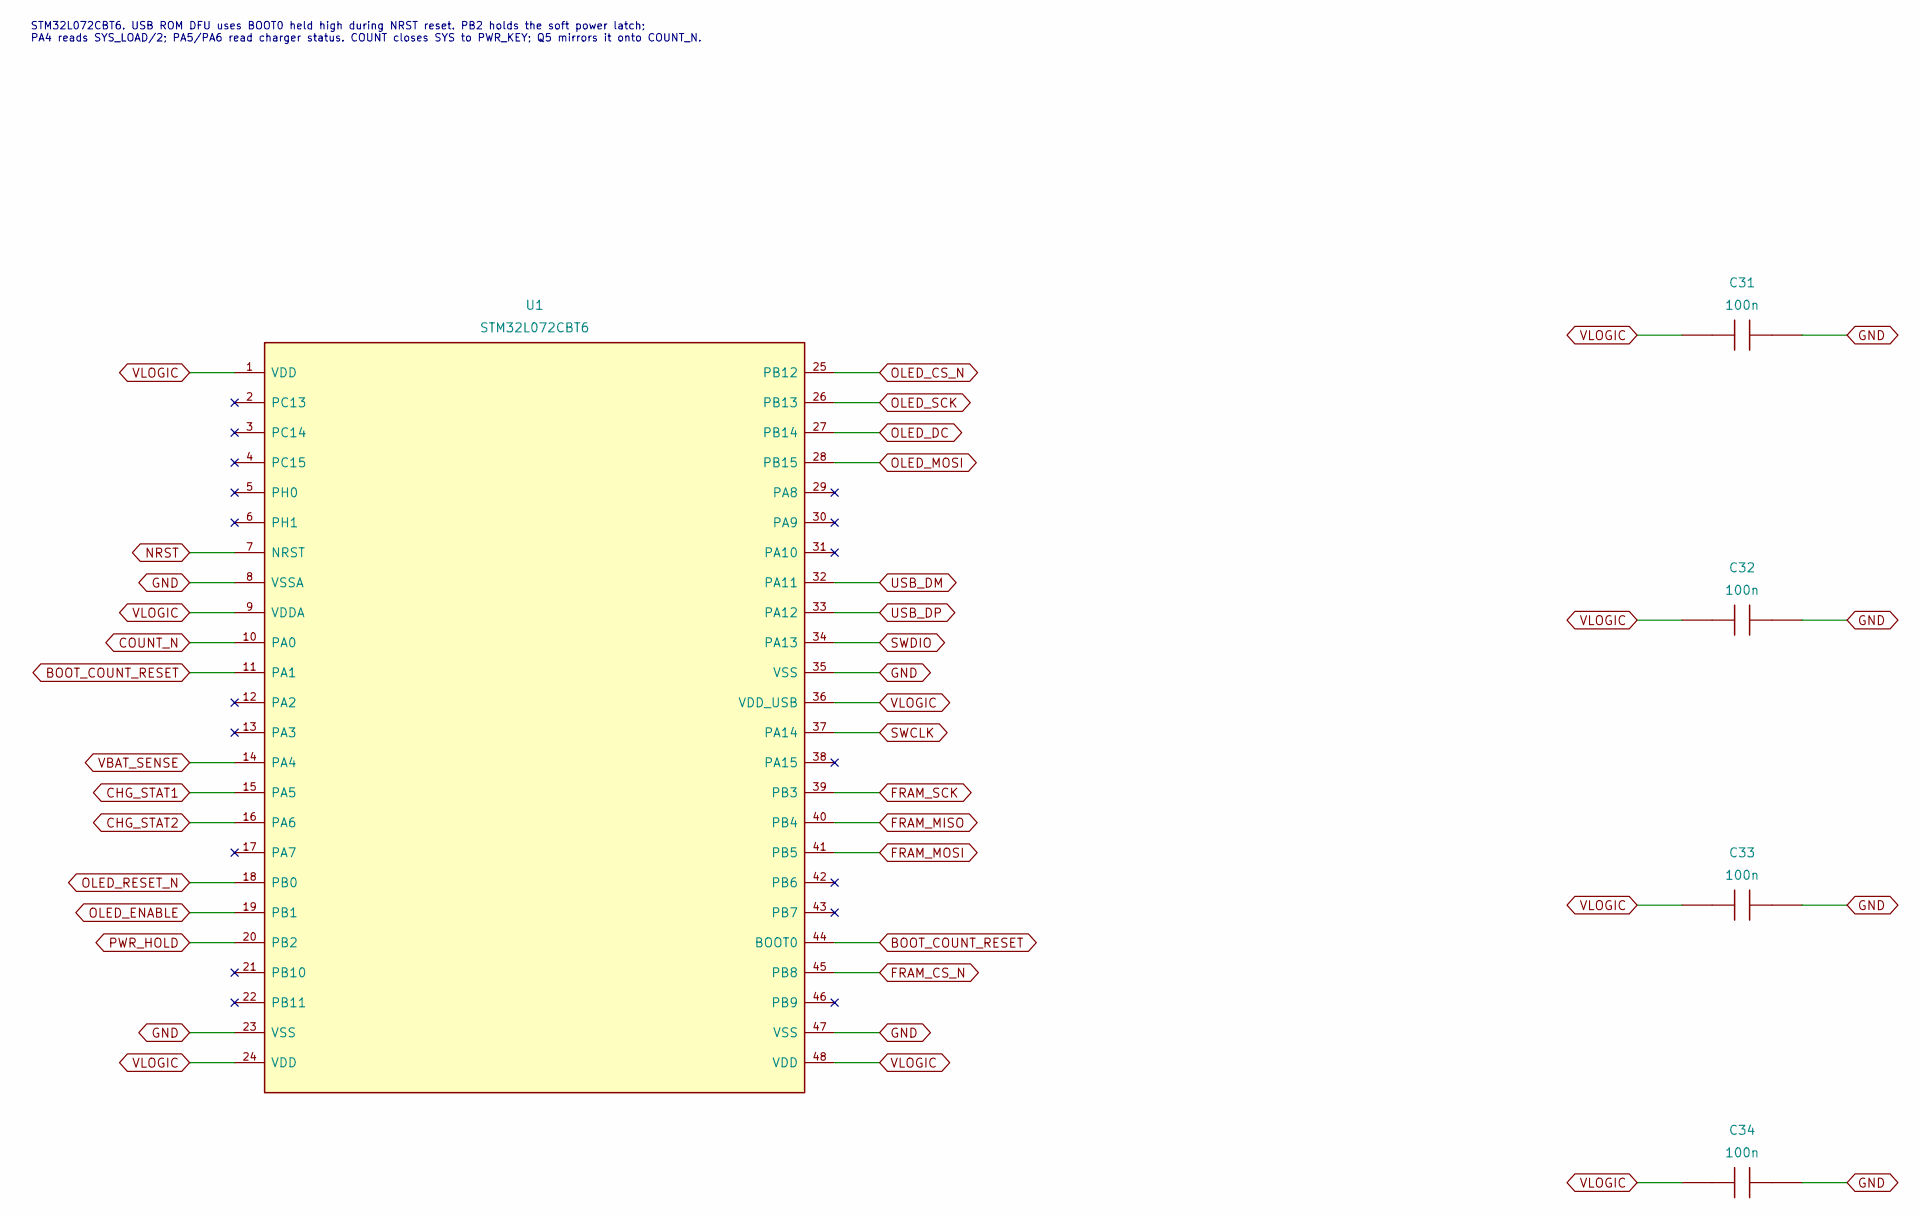
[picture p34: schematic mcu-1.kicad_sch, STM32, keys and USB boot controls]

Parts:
C31, C32, C33, C34: 100n; Capacitor_SMD_C_0603_1608Metric; MPN CC0603KRX7R9BB104
U1: STM32L072CBT6; Package_QFP_LQFP-48_7x7mm_P0.5mm; MPN STM32L072CBT6

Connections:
BOOT_COUNT_RESET: U1.11 (PA1), U1.44 (BOOT0); also elsewhere on the board
CHG_STAT1: U1.15 (PA5); also elsewhere on the board
CHG_STAT2: U1.16 (PA6); also elsewhere on the board
COUNT_N: U1.10 (PA0); also elsewhere on the board
FRAM_CS_N: U1.45 (PB8); also elsewhere on the board
FRAM_MISO: U1.40 (PB4); also elsewhere on the board
FRAM_MOSI: U1.41 (PB5); also elsewhere on the board
FRAM_SCK: U1.39 (PB3); also elsewhere on the board
GND: C31.2, C32.2, C33.2, C34.2, U1.8 (VSSA), U1.23 (VSS), U1.35 (VSS), U1.47 (VSS); also elsewhere on the board
NRST: U1.7 (NRST); also elsewhere on the board
OLED_CS_N: U1.25 (PB12); also elsewhere on the board
OLED_DC: U1.27 (PB14); also elsewhere on the board
OLED_ENABLE: U1.19 (PB1); also elsewhere on the board
OLED_MOSI: U1.28 (PB15); also elsewhere on the board
OLED_RESET_N: U1.18 (PB0); also elsewhere on the board
OLED_SCK: U1.26 (PB13); also elsewhere on the board
PWR_HOLD: U1.20 (PB2); also elsewhere on the board
SWCLK: U1.37 (PA14); also elsewhere on the board
SWDIO: U1.34 (PA13); also elsewhere on the board
USB_DM: U1.32 (PA11); also elsewhere on the board
USB_DP: U1.33 (PA12); also elsewhere on the board
VBAT_SENSE: U1.14 (PA4); also elsewhere on the board
VLOGIC: C31.1, C32.1, C33.1, C34.1, U1.1 (VDD), U1.9 (VDDA), U1.24 (VDD), U1.36 (VDD_USB), U1.48 (VDD); also elsewhere on the board

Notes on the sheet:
STM32L072CBT6. USB ROM DFU uses BOOT0 held high during NRST reset. PB2 holds the soft power latch; PA4 reads SYS_LOAD/2; PA5/PA6 read charger status. COUNT closes SYS to PWR_KEY; Q5 mirrors it onto COUNT_N.

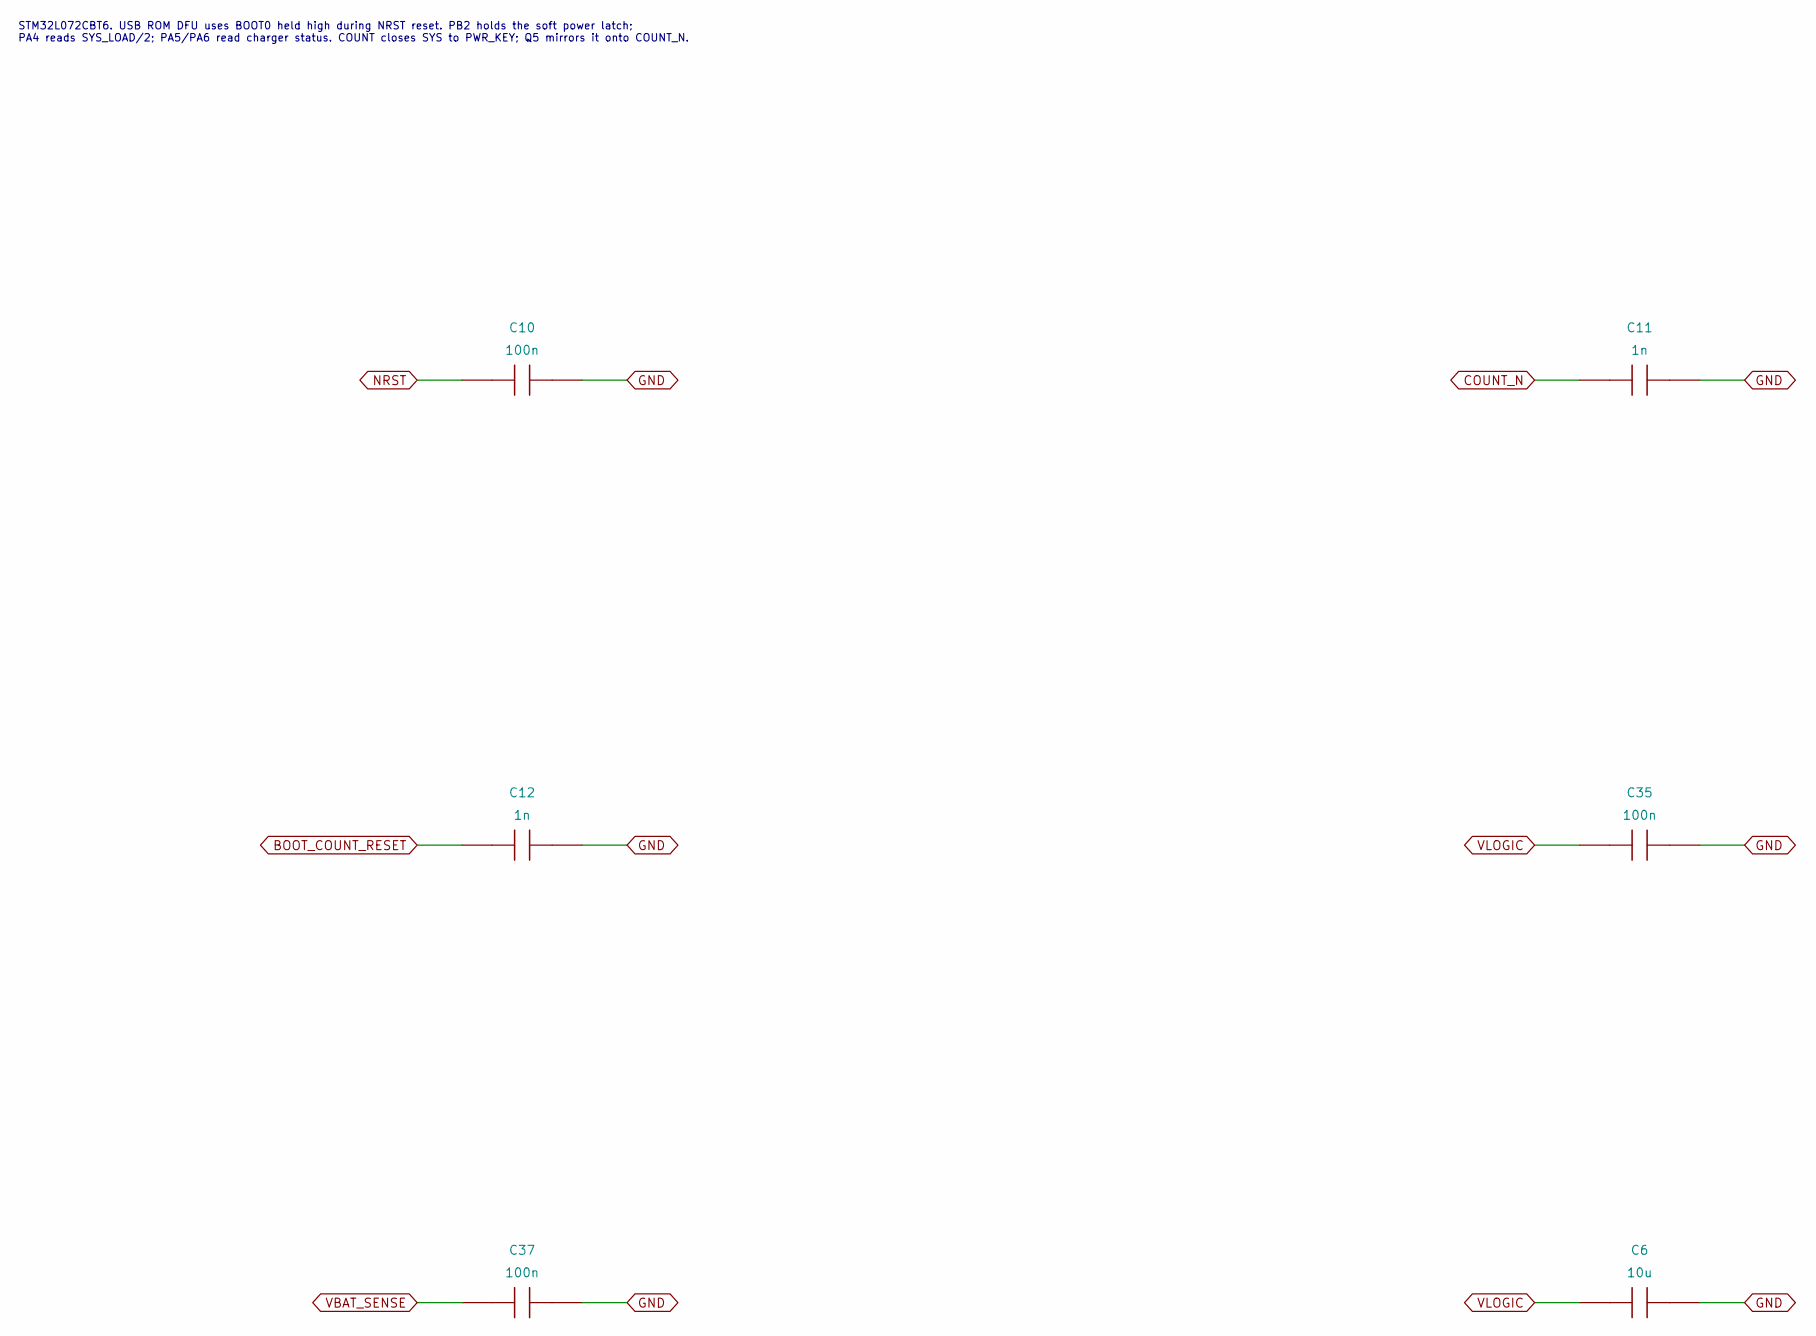
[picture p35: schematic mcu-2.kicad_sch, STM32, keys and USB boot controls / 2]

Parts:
C6: 10u; Capacitor_SMD_C_0805_2012Metric; MPN GRM21BR61H106KE43L
C10, C35, C37: 100n; Capacitor_SMD_C_0603_1608Metric; MPN CC0603KRX7R9BB104
C11, C12: 1n; Capacitor_SMD_C_0603_1608Metric; MPN CL10B102KB8NNNC

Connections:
BOOT_COUNT_RESET: C12.1; also elsewhere on the board
COUNT_N: C11.1; also elsewhere on the board
GND: C6.2, C10.2, C11.2, C12.2, C35.2, C37.2; also elsewhere on the board
NRST: C10.1; also elsewhere on the board
VBAT_SENSE: C37.1; also elsewhere on the board
VLOGIC: C6.1, C35.1; also elsewhere on the board

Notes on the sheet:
STM32L072CBT6. USB ROM DFU uses BOOT0 held high during NRST reset. PB2 holds the soft power latch; PA4 reads SYS_LOAD/2; PA5/PA6 read charger status. COUNT closes SYS to PWR_KEY; Q5 mirrors it onto COUNT_N.

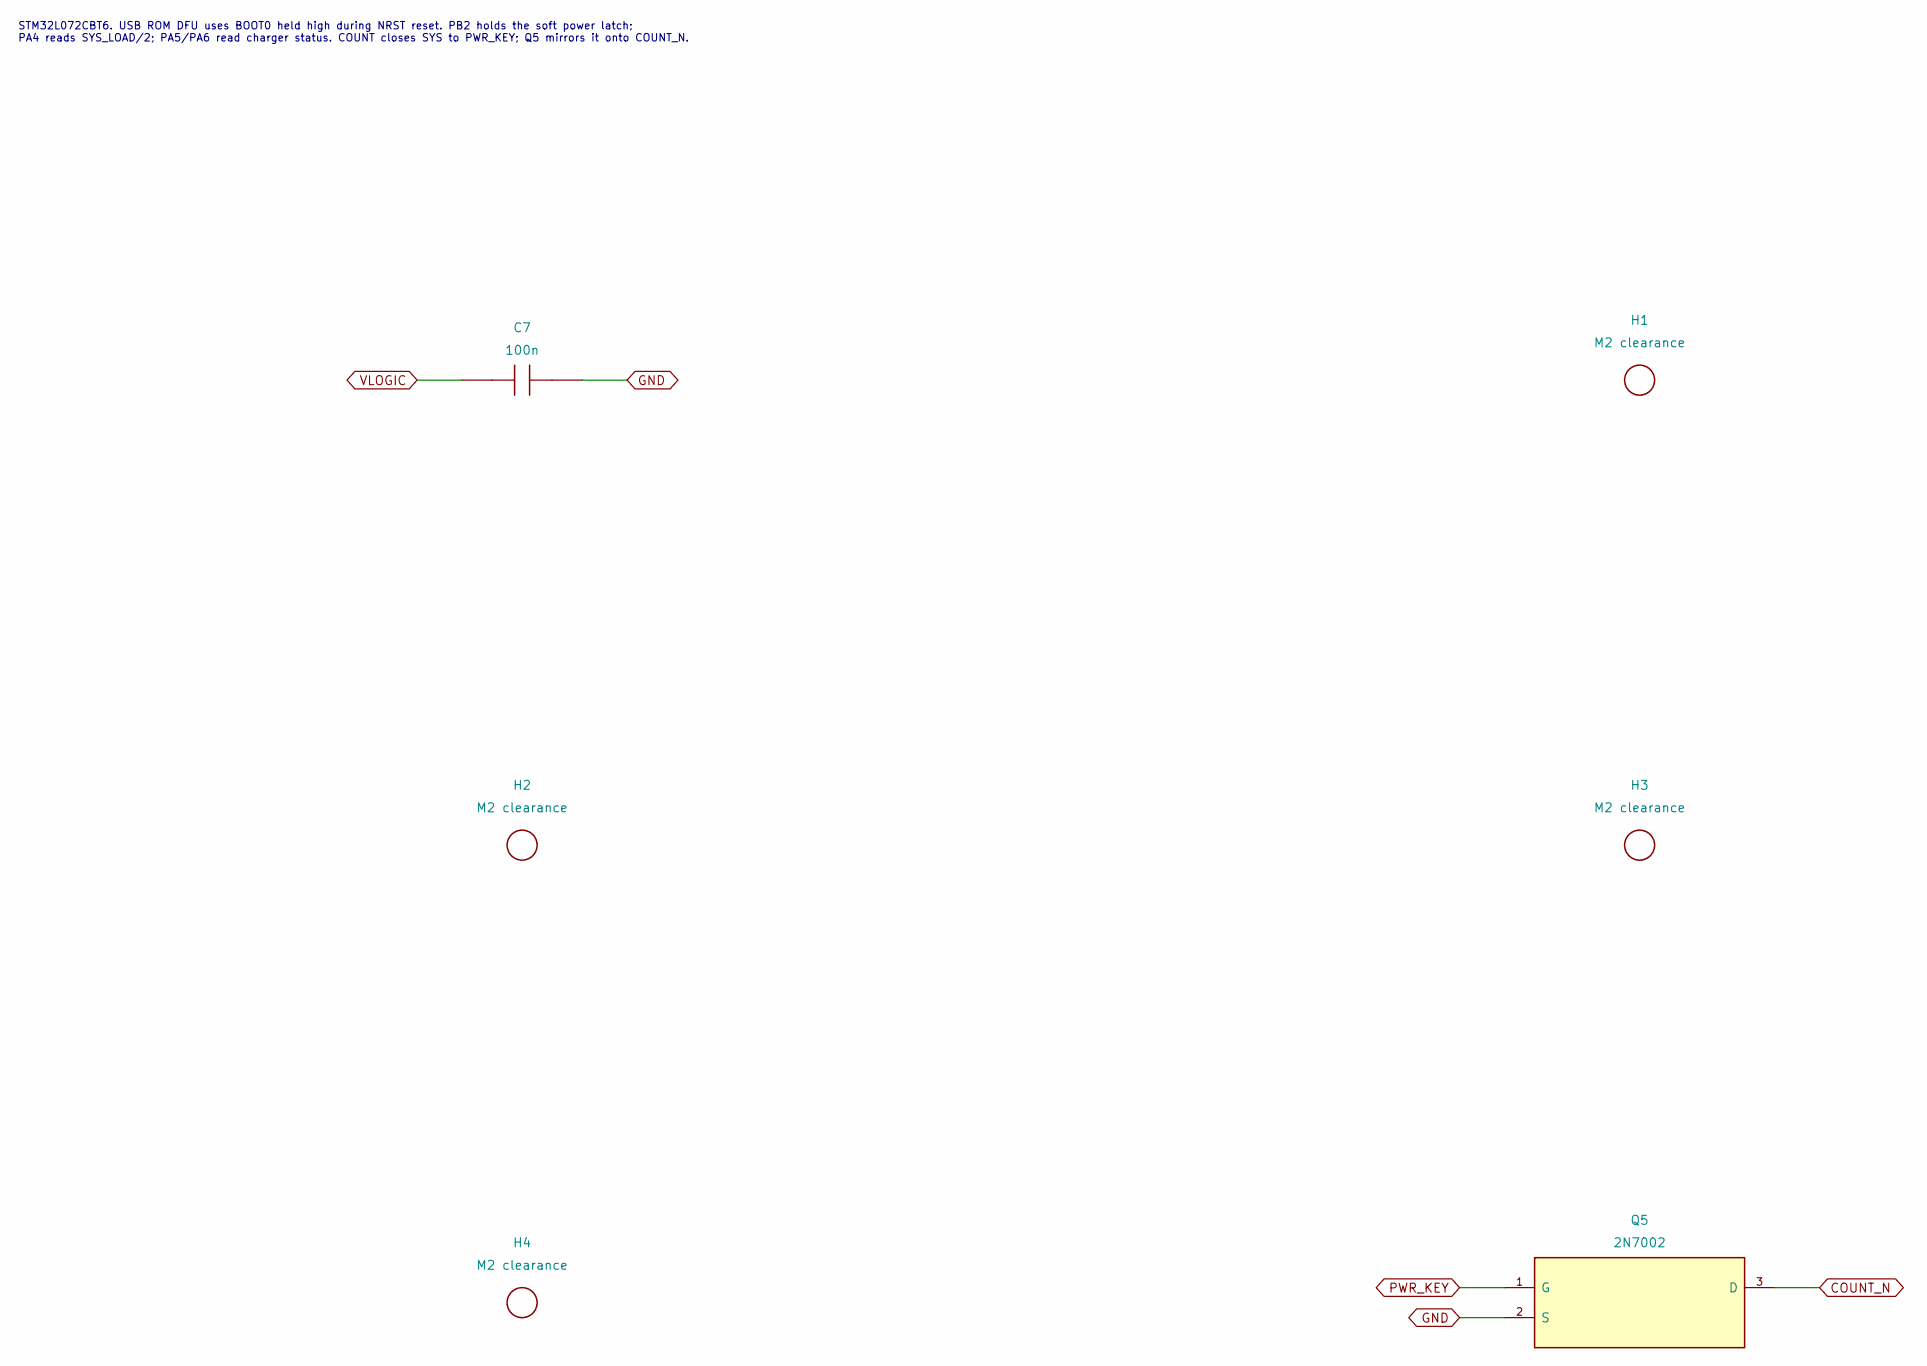
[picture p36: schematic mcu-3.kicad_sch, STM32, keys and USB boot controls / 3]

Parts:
C7: 100n; Capacitor_SMD_C_0603_1608Metric; MPN CC0603KRX7R9BB104
H1, H2, H3, H4: M2 clearance; MountingHole_MountingHole_2.2mm_M2; MPN NPTH
Q5: COUNT key level shift; Package_TO_SOT_SMD_SOT-23; MPN 2N7002

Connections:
COUNT_N: Q5.3 (D); also elsewhere on the board
GND: C7.2, Q5.2 (S); also elsewhere on the board
PWR_KEY: Q5.1 (G); also elsewhere on the board
VLOGIC: C7.1; also elsewhere on the board

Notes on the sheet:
STM32L072CBT6. USB ROM DFU uses BOOT0 held high during NRST reset. PB2 holds the soft power latch; PA4 reads SYS_LOAD/2; PA5/PA6 read charger status. COUNT closes SYS to PWR_KEY; Q5 mirrors it onto COUNT_N.

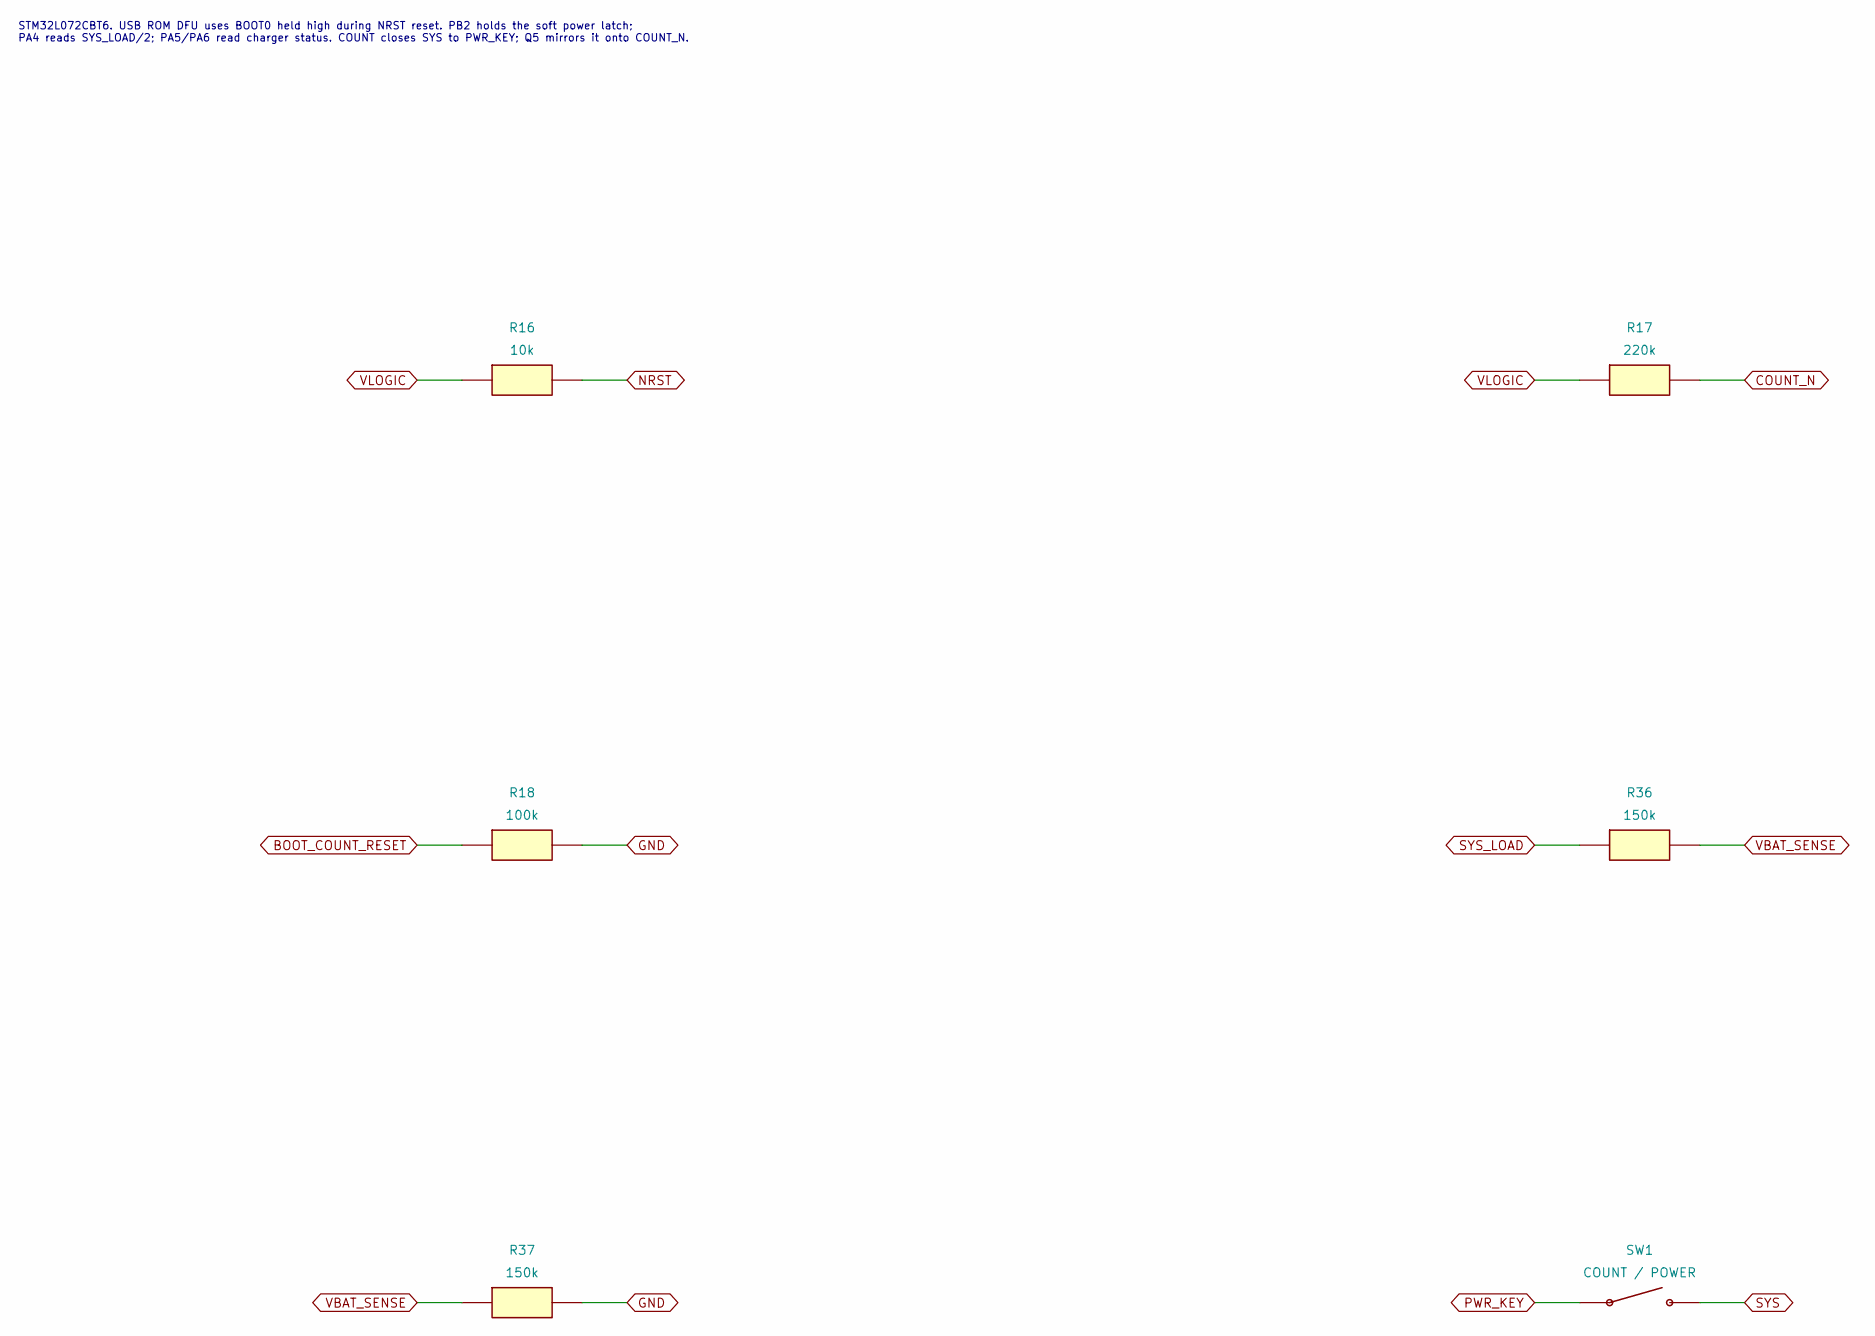
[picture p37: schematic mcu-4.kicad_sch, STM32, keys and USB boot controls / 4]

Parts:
R16: 10k; Resistor_SMD_R_0603_1608Metric; MPN 0603WAF1002T5E
R17: 220k; Resistor_SMD_R_0603_1608Metric; MPN 0603WAF2203T5E
R18: 100k; Resistor_SMD_R_0603_1608Metric; MPN 0603WAF1003T5E
R36, R37: 150k; Resistor_SMD_R_0603_1608Metric; MPN RT0603BRD07150KL
SW1: COUNT / POWER; SW_Hotswap_Kailh_MX_CPG151101S11; MPN CPG151101S11-16

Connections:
BOOT_COUNT_RESET: R18.1; also elsewhere on the board
COUNT_N: R17.2; also elsewhere on the board
GND: R18.2, R37.2; also elsewhere on the board
NRST: R16.2; also elsewhere on the board
PWR_KEY: SW1.1; also elsewhere on the board
SYS: SW1.2; also elsewhere on the board
SYS_LOAD: R36.1; also elsewhere on the board
VBAT_SENSE: R36.2, R37.1; also elsewhere on the board
VLOGIC: R16.1, R17.1; also elsewhere on the board

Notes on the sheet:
STM32L072CBT6. USB ROM DFU uses BOOT0 held high during NRST reset. PB2 holds the soft power latch; PA4 reads SYS_LOAD/2; PA5/PA6 read charger status. COUNT closes SYS to PWR_KEY; Q5 mirrors it onto COUNT_N.

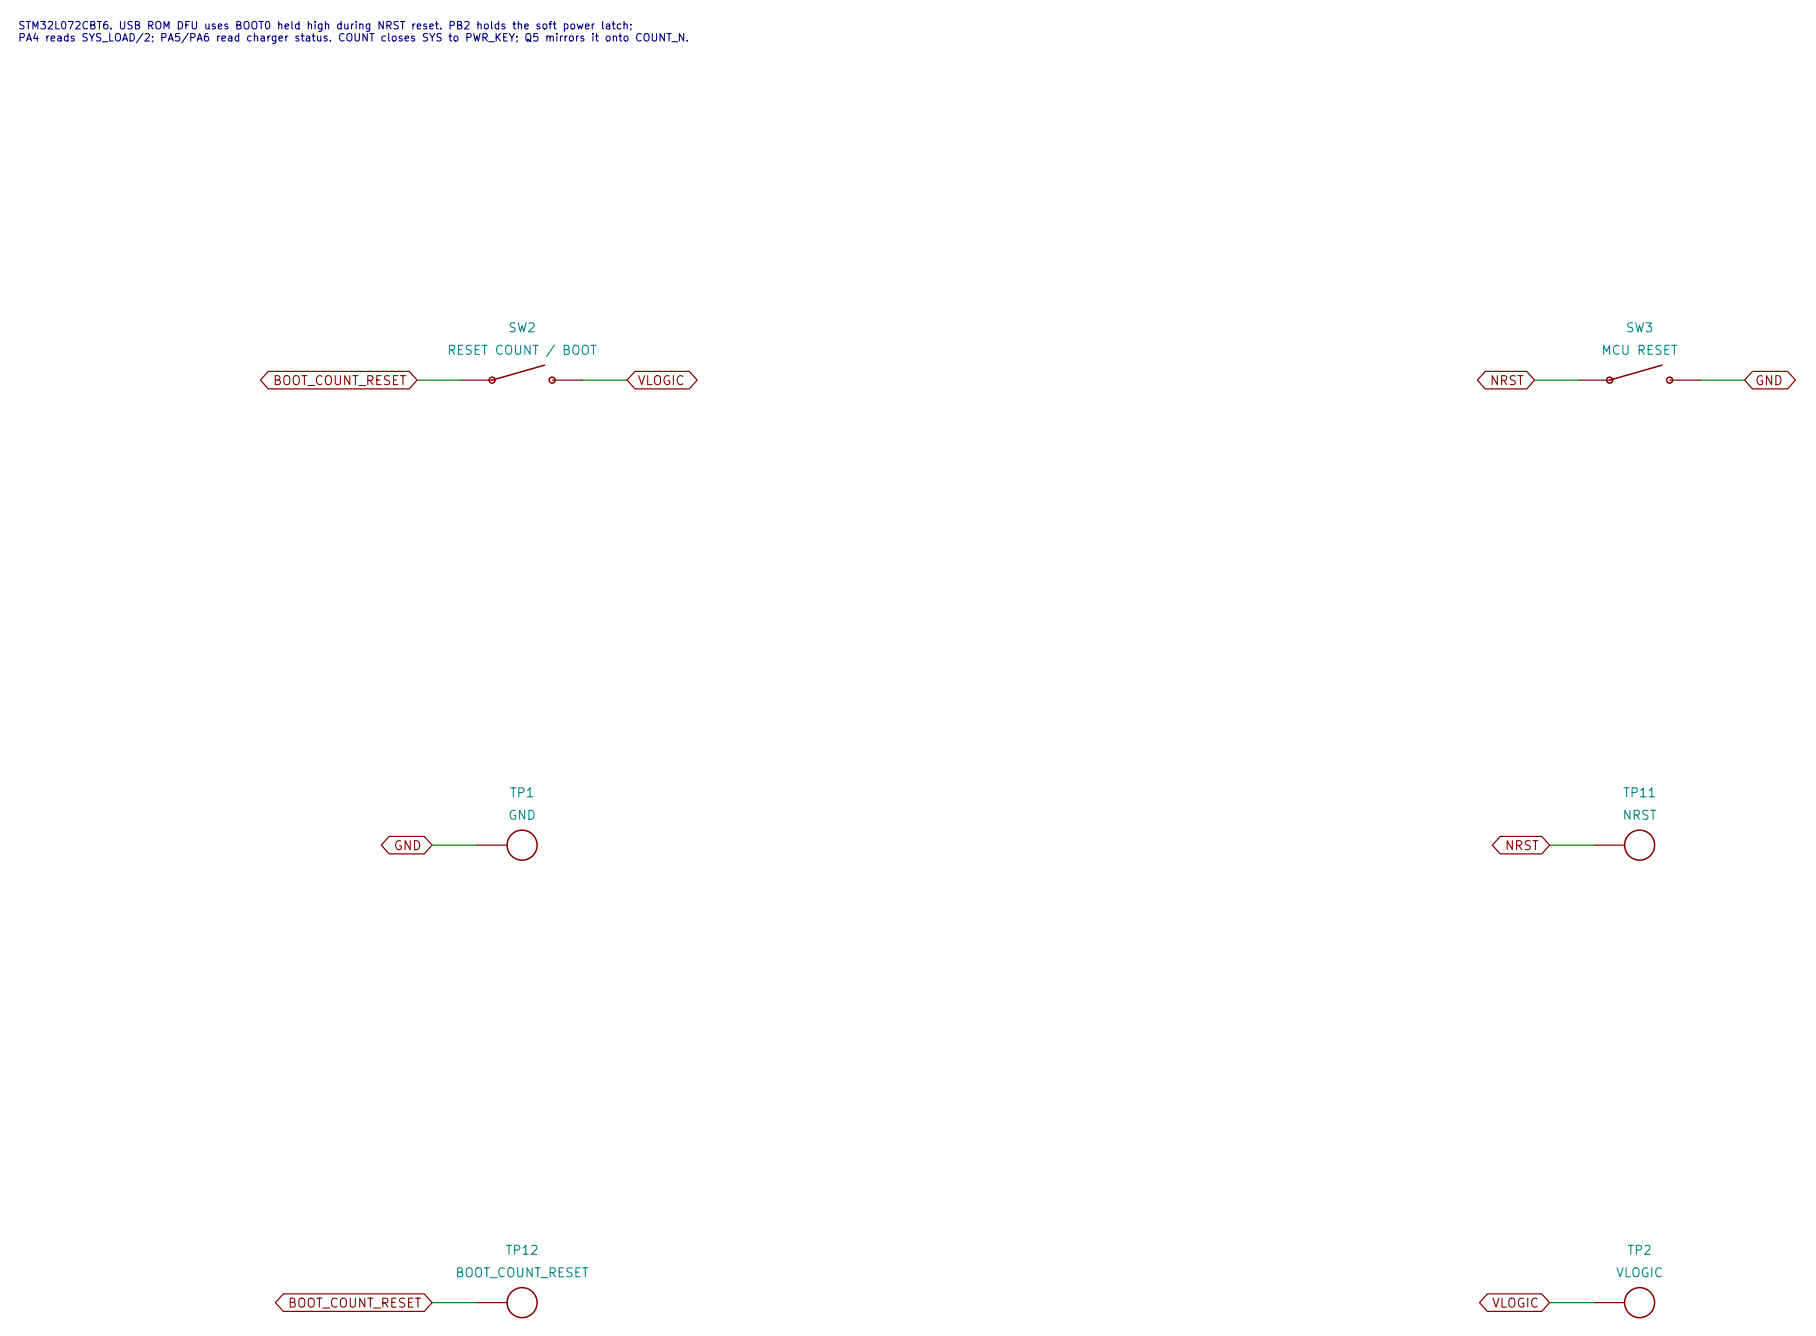
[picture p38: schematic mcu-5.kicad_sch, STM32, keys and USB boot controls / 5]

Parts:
SW2: RESET COUNT / BOOT; SW_Hotswap_Kailh_MX_CPG151101S11; MPN CPG151101S11-16
SW3: MCU RESET; XUNPU_TS-1088-AR02016_SMD; MPN TS-1088-AR02016
TP1: GND; TestPoint_TestPoint_Pad_D1.5mm; MPN PCB LAND
TP2: VLOGIC; TestPoint_TestPoint_Pad_D1.5mm; MPN PCB LAND
TP11: NRST; TestPoint_TestPoint_Pad_D1.5mm; MPN PCB LAND
TP12: BOOT_COUNT_RESET; TestPoint_TestPoint_Pad_D1.5mm; MPN PCB LAND

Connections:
BOOT_COUNT_RESET: SW2.1, TP12.1 (1_1); also elsewhere on the board
GND: SW3.2, TP1.1 (1_1); also elsewhere on the board
NRST: SW3.1, TP11.1 (1_1); also elsewhere on the board
VLOGIC: SW2.2, TP2.1 (1_1); also elsewhere on the board

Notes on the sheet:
STM32L072CBT6. USB ROM DFU uses BOOT0 held high during NRST reset. PB2 holds the soft power latch; PA4 reads SYS_LOAD/2; PA5/PA6 read charger status. COUNT closes SYS to PWR_KEY; Q5 mirrors it onto COUNT_N.

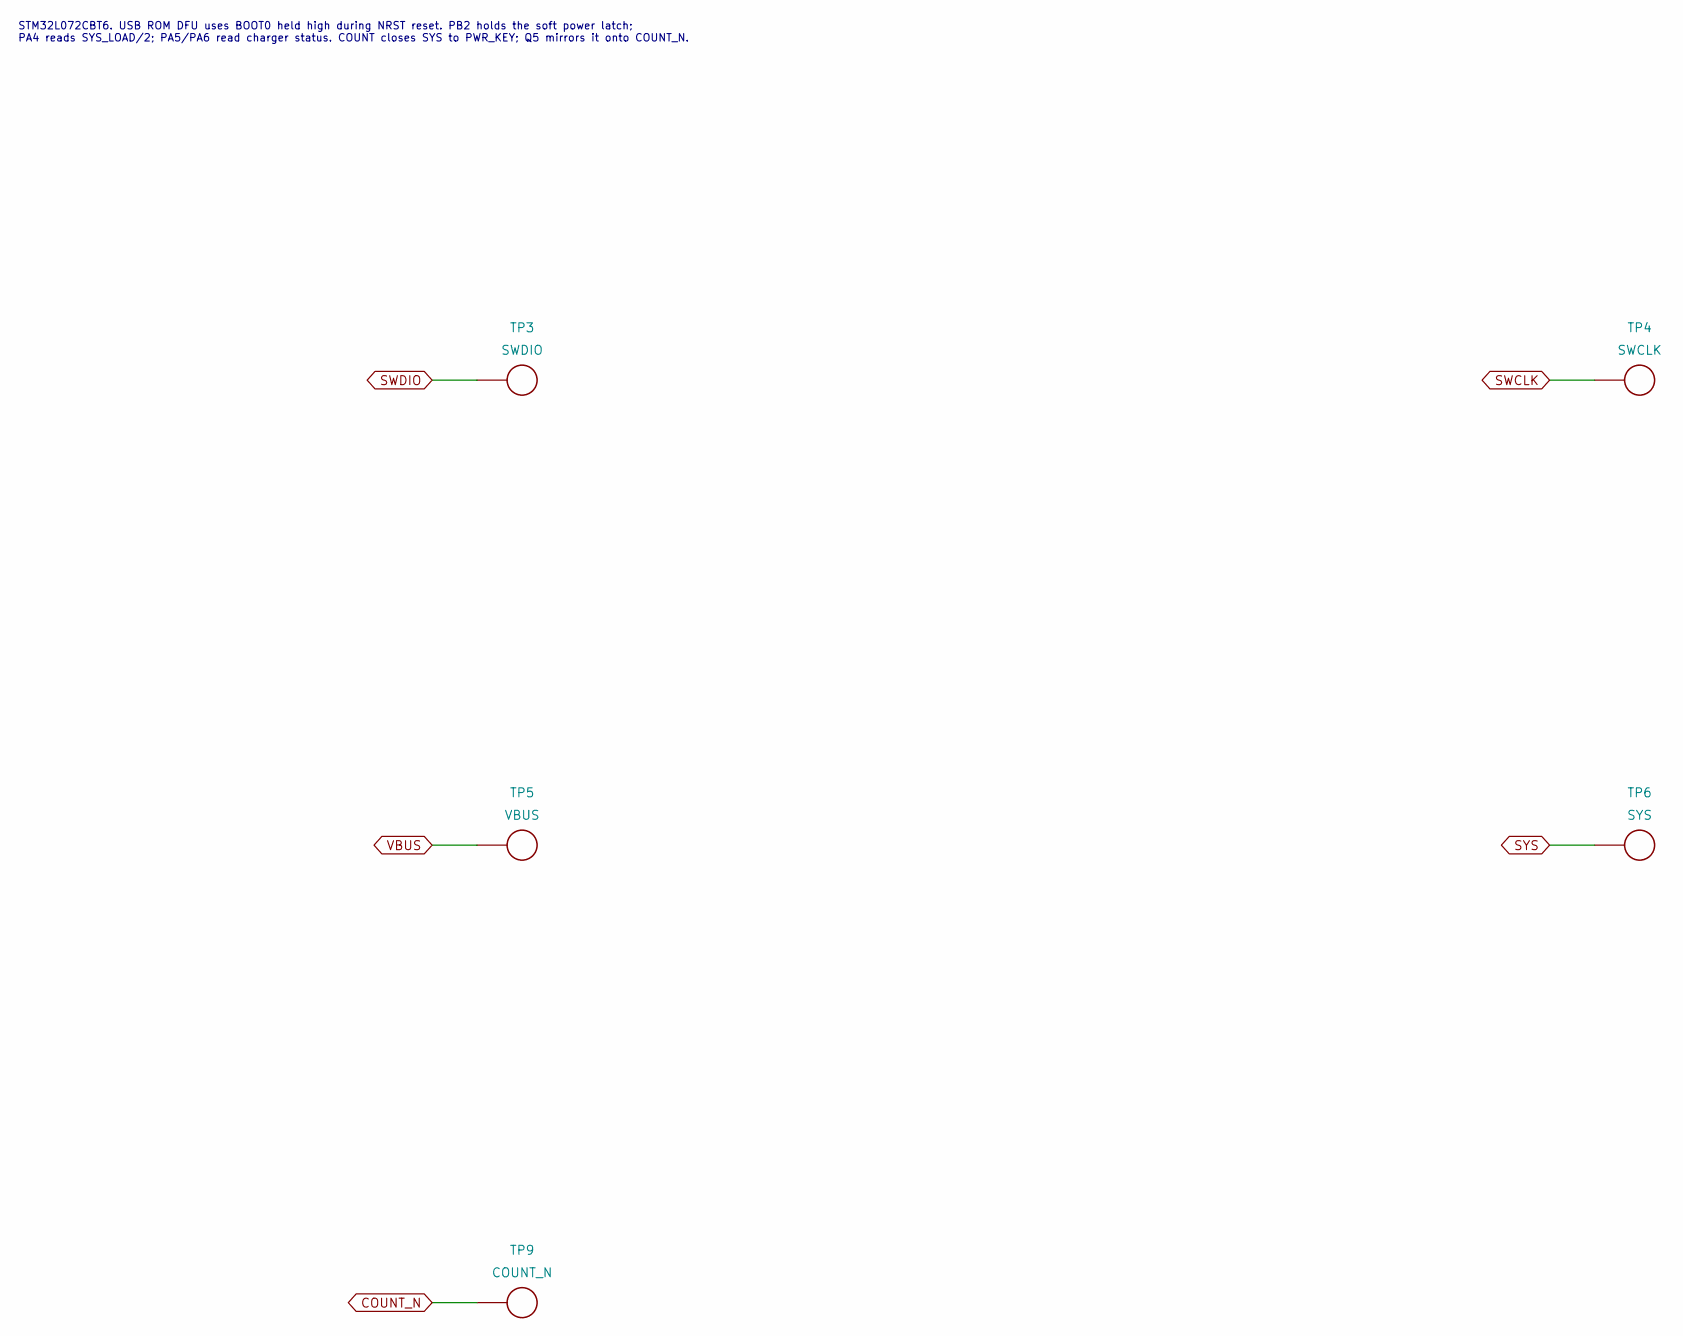
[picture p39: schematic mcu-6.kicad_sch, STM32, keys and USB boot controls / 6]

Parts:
TP3: SWDIO; TestPoint_TestPoint_Pad_D1.5mm; MPN PCB LAND
TP4: SWCLK; TestPoint_TestPoint_Pad_D1.5mm; MPN PCB LAND
TP5: VBUS; TestPoint_TestPoint_Pad_D1.5mm; MPN PCB LAND
TP6: SYS; TestPoint_TestPoint_Pad_D1.5mm; MPN PCB LAND
TP9: COUNT_N; TestPoint_TestPoint_Pad_D1.5mm; MPN PCB LAND

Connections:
COUNT_N: TP9.1 (1_1); also elsewhere on the board
SWCLK: TP4.1 (1_1); also elsewhere on the board
SWDIO: TP3.1 (1_1); also elsewhere on the board
SYS: TP6.1 (1_1); also elsewhere on the board
VBUS: TP5.1 (1_1); also elsewhere on the board

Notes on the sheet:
STM32L072CBT6. USB ROM DFU uses BOOT0 held high during NRST reset. PB2 holds the soft power latch; PA4 reads SYS_LOAD/2; PA5/PA6 read charger status. COUNT closes SYS to PWR_KEY; Q5 mirrors it onto COUNT_N.

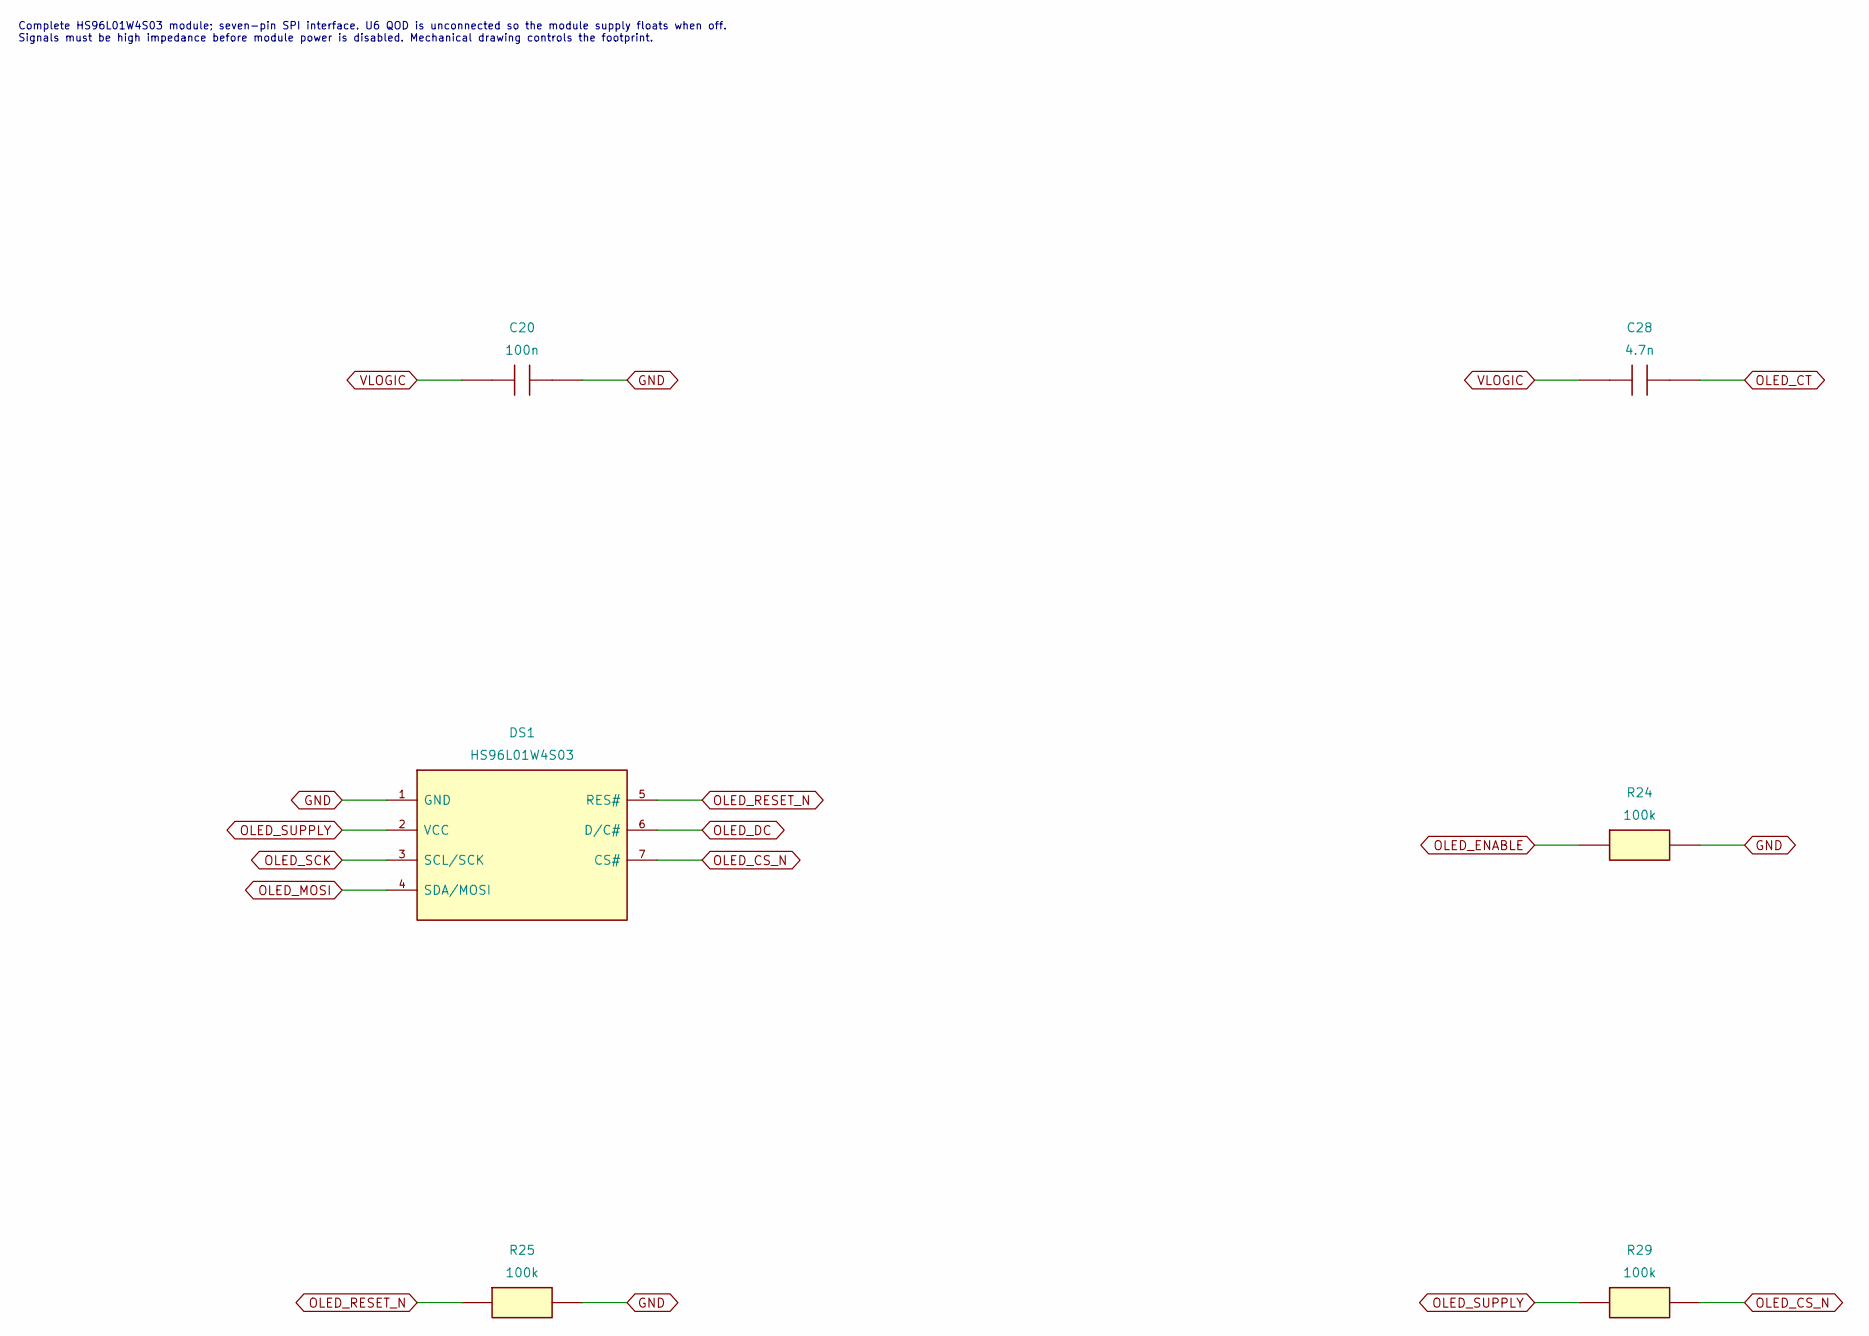
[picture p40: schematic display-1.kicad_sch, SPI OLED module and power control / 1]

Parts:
C20: 100n; Capacitor_SMD_C_0603_1608Metric; MPN CC0603KRX7R9BB104
C28: 4.7n; Capacitor_SMD_C_0603_1608Metric; MPN 0603B472K500NT
DS1: SPI OLED module 128x64; HS96L01W4S03_Module_7Pin; MPN HS96L01W4S03
R24, R25, R29: 100k; Resistor_SMD_R_0603_1608Metric; MPN 0603WAF1003T5E

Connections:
GND: C20.2, DS1.1 (GND), R24.2, R25.2; also elsewhere on the board
OLED_CS_N: DS1.7 (CS#), R29.2; also elsewhere on the board
OLED_CT: C28.2; also elsewhere on the board
OLED_DC: DS1.6 (D/C#); also elsewhere on the board
OLED_ENABLE: R24.1; also elsewhere on the board
OLED_MOSI: DS1.4 (SDA/MOSI); also elsewhere on the board
OLED_RESET_N: DS1.5 (RES#), R25.1; also elsewhere on the board
OLED_SCK: DS1.3 (SCL/SCK); also elsewhere on the board
OLED_SUPPLY: DS1.2 (VCC), R29.1; also elsewhere on the board
VLOGIC: C20.1, C28.1; also elsewhere on the board

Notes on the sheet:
Complete HS96L01W4S03 module; seven-pin SPI interface. U6 QOD is unconnected so the module supply floats when off. Signals must be high impedance before module power is disabled. Mechanical drawing controls the footprint.

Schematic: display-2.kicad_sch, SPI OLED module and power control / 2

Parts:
U6: OLED power slew switch; Package_TO_SOT_SMD_SOT-23-6; MPN TPS22917DBVR

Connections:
GND: U6.2 (GND); also elsewhere on the board
OLED_CT: U6.4 (CT); also elsewhere on the board
OLED_ENABLE: U6.3 (ON); also elsewhere on the board
OLED_SUPPLY: U6.6 (VOUT); also elsewhere on the board
VLOGIC: U6.1 (VIN); also elsewhere on the board

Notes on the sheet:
Complete HS96L01W4S03 module; seven-pin SPI interface. U6 QOD is unconnected so the module supply floats when off. Signals must be high impedance before module power is disabled. Mechanical drawing controls the footprint.

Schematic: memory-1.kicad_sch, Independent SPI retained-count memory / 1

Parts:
C30: 10u; Capacitor_SMD_C_0805_2012Metric; MPN GRM21BR61H106KE43L
C36: 100n; Capacitor_SMD_C_0603_1608Metric; MPN CC0603KRX7R9BB104
R32: 75; Resistor_SMD_R_0603_1608Metric; MPN 0603WAF750JT5E
R33: 100k; Resistor_SMD_R_0603_1608Metric; MPN 0603WAF1003T5E
U8: SPI F-RAM 32KiB; Package_SO_SOIC-8_3.9x4.9mm_P1.27mm; MPN FM25V02A-GTR

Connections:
FRAM_CS_N: R33.2, U8.1 (CS#); also elsewhere on the board
FRAM_MISO: U8.2 (SO); also elsewhere on the board
FRAM_MOSI: U8.5 (SI); also elsewhere on the board
FRAM_SCK: U8.6 (SCK); also elsewhere on the board
GND: C30.2, C36.2, U8.4 (VSS); also elsewhere on the board
VFRAM: C30.1, C36.1, R32.2, R33.1, U8.3 (WP#), U8.7 (HOLD#), U8.8 (VDD)
VLOGIC: R32.1; also elsewhere on the board

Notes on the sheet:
FM25V02A F-RAM on an isolated RC supply; dedicated SPI1. Power-ramp, chip-select and interrupted-write behavior require separate analysis and physical qualification.

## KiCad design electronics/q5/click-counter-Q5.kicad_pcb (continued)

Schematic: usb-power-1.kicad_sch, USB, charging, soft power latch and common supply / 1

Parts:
C1, C3: 2.2u; Capacitor_SMD_C_0805_2012Metric; MPN CL21A225KBQNNNE
C2: 10u; Capacitor_SMD_C_0805_2012Metric; MPN GRM21BR61H106KE43L
C13, C29: 4.7n; Capacitor_SMD_C_0603_1608Metric; MPN 0603B472K500NT
C38: 100n; Capacitor_SMD_C_0603_1608Metric; MPN CC0603KRX7R9BB104

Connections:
CELL_P: C3.1; also elsewhere on the board
GND: C1.2, C2.2, C3.2, C13.2, C38.2; also elsewhere on the board
RC_COMP: C13.1; also elsewhere on the board
SYS: C2.1, C29.1; also elsewhere on the board
SYS_CT: C29.2; also elsewhere on the board
VBUS: C1.1, C38.1; also elsewhere on the board

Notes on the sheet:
U7 ON = VBUS (D4) OR COUNT key (D3 A1) OR PWR_HOLD (D3 A2), pulled down by R35. Off: only BQ29700 and BQ25185 battery quiescent current remain. Cold cell insertion is not proven by the slew switch.

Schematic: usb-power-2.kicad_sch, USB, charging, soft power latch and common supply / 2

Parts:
C5: 2.2u; Capacitor_SMD_C_0805_2012Metric; MPN CL21A225KBQNNNE
C39: 100n; Capacitor_SMD_C_0603_1608Metric; MPN CC0603KRX7R9BB104
C40: 10n; Capacitor_SMD_C_0603_1608Metric; MPN 0603B103K500NT
D1, D2: USB ESD; Package_TO_SOT_SMD_SOT-23-6; MPN USBLC6-2SC6
D3: BAT54C; Package_TO_SOT_SMD_SOT-23; MPN BAT54C,215

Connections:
CC1: D1.1 (I/O1), D1.6 (I/O1); also elsewhere on the board
CC2: D1.3 (I/O2), D1.4 (I/O2); also elsewhere on the board
GND: C5.2, C39.2, C40.2, D1.2 (GND), D2.2 (GND); also elsewhere on the board
PWR_HOLD: D3.2 (A2); also elsewhere on the board
PWR_KEY: D3.1 (A1); also elsewhere on the board
SYS_LOAD: C5.1; also elsewhere on the board
SYS_ON: C40.1, D3.3 (K); also elsewhere on the board
USB_DM: D2.1 (I/O1), D2.6 (I/O1); also elsewhere on the board
USB_DP: D2.3 (I/O2), D2.4 (I/O2); also elsewhere on the board
VBUS: C39.1, D1.5 (VBUS), D2.5 (VBUS); also elsewhere on the board

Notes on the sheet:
U7 ON = VBUS (D4) OR COUNT key (D3 A1) OR PWR_HOLD (D3 A2), pulled down by R35. Off: only BQ29700 and BQ25185 battery quiescent current remain. Cold cell insertion is not proven by the slew switch.

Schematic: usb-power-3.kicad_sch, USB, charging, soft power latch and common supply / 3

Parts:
D4: 1N4148WS; Diode_SMD_D_SOD-323; MPN 1N4148WS
J1: USB-C power and DFU; Connector_USB_USB_C_Receptacle_GCT_USB4105-xx-A_16P_TopMnt_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; MPN USB4105-GF-A-120
R1, R2: 5.1k; Resistor_SMD_R_0603_1608Metric; MPN 0603WAF5101T5E
R3: 24k; Resistor_SMD_R_0603_1608Metric; MPN 0603WAF2402T5E
R19: 2k; Resistor_SMD_R_0603_1608Metric; MPN 0603WAF2001T5E

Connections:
CC1: J1.A5 (CCA), R1.1; also elsewhere on the board
CC2: J1.B5 (CCB), R2.1; also elsewhere on the board
GND: J1.A1 (GND), J1.A12 (GND), J1.B1 (GND), J1.B12 (GND), J1.SH (SHIELD), R1.2, R2.2, R3.2; also elsewhere on the board
ISET: R19.1; also elsewhere on the board
RC_COMP: R19.2; also elsewhere on the board
USB_DM: J1.A7 (D-), J1.B7 (D-); also elsewhere on the board
USB_DP: J1.A6 (D+), J1.B6 (D+); also elsewhere on the board
VBUS: D4.2 (A), J1.A4 (VBUS), J1.A9 (VBUS), J1.B4 (VBUS), J1.B9 (VBUS); also elsewhere on the board
VBUS_WAKE: D4.1 (K); also elsewhere on the board
VSET: R3.1; also elsewhere on the board

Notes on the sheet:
U7 ON = VBUS (D4) OR COUNT key (D3 A1) OR PWR_HOLD (D3 A2), pulled down by R35. Off: only BQ29700 and BQ25185 battery quiescent current remain. Cold cell insertion is not proven by the slew switch.

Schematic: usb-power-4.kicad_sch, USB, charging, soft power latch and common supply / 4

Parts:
R4: 18k; Resistor_SMD_R_0603_1608Metric; MPN 0603WAF1802T5E
R30: 150k; Resistor_SMD_R_0603_1608Metric; MPN RT0603BRD07150KL
R31: 49.9k; Resistor_SMD_R_0603_1608Metric; MPN RT0603BRD0749K9L
R34, R38: 100k; Resistor_SMD_R_0603_1608Metric; MPN 0603WAF1003T5E
R35: 1M; Resistor_SMD_R_0603_1608Metric; MPN 0603WAF1004T5E

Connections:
GND: R4.2, R31.2, R34.2, R35.2; also elsewhere on the board
ISET: R4.1; also elsewhere on the board
PWR_KEY: R34.1; also elsewhere on the board
SYS_ON: R35.1, R38.2; also elsewhere on the board
VBUS_WAKE: R38.1; also elsewhere on the board
VLOGIC: R30.1; also elsewhere on the board
VLOGIC_FB: R30.2, R31.1; also elsewhere on the board

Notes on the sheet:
U7 ON = VBUS (D4) OR COUNT key (D3 A1) OR PWR_HOLD (D3 A2), pulled down by R35. Off: only BQ29700 and BQ25185 battery quiescent current remain. Cold cell insertion is not proven by the slew switch.

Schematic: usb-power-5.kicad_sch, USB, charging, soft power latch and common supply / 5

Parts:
R5: 10k; Resistor_SMD_R_0603_1608Metric; MPN 0603WAF1002T5E
R6: 100k; Resistor_SMD_R_0603_1608Metric; MPN 0603WAF1003T5E
TP13: SYS_ON; TestPoint_TestPoint_Pad_D1.5mm; MPN PCB LAND
U2: Li-ion charger; Package_DFN_QFN_Texas_DLH0010A_WSON-10-1EP_2.2x2mm_P0.4mm_E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; MPN BQ25185DLHR
U3: 3.20481V adjustable LDO; Package_SON_WSON-6-1EP_2x2mm_P0.65mm_EP1x1.6mm; MPN TLV76701DRVR
U7: System soft-power latch switch; Package_TO_SOT_SMD_SOT-23-6; MPN TPS22917DBVR

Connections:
CELL_P: U2.2 (BAT); also elsewhere on the board
CE_N: R6.2, U2.4 (~CE); also elsewhere on the board
CHG_STAT1: U2.9 (STAT1); also elsewhere on the board
CHG_STAT2: U2.3 (STAT2); also elsewhere on the board
GND: R5.2, U2.5 (GND), U2.11 (EP/GND), U3.3 (GND), U3.5 (GND), U3.7 (EP), U7.2 (GND); also elsewhere on the board
ISET: U2.8 (ISET); also elsewhere on the board
SYS: U2.1 (SYS), U7.1 (VIN); also elsewhere on the board
SYS_CT: U7.4 (CT); also elsewhere on the board
SYS_LOAD: U3.4 (EN), U3.6 (IN), U7.6 (VOUT); also elsewhere on the board
SYS_ON: TP13.1 (1_1), U7.3 (ON); also elsewhere on the board
TS_FIXED: R5.1, U2.6 (TS/MR)
VBUS: R6.1, U2.10 (IN); also elsewhere on the board
VLOGIC: U3.1 (OUT); also elsewhere on the board
VLOGIC_FB: U3.2 (FB); also elsewhere on the board
VSET: U2.7 (ILIM/VSET); also elsewhere on the board

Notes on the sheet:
U7 ON = VBUS (D4) OR COUNT key (D3 A1) OR PWR_HOLD (D3 A2), pulled down by R35. Off: only BQ29700 and BQ25185 battery quiescent current remain. Cold cell insertion is not proven by the slew switch.

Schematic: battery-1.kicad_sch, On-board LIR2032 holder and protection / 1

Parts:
BT1: LIR2032 holder; BatteryHolder_QJ_CR2032-BS-6-1; MPN CR2032-BS-6-1
C4: 100n; Capacitor_SMD_C_0603_1608Metric; MPN CC0603KRX7R9BB104
Q1: Discharge FET; Package_TO_SOT_SMD_SOT-23; MPN AO3400A
Q2: Charge FET; Package_TO_SOT_SMD_SOT-23; MPN AO3400A
R7: 330; Resistor_SMD_R_0603_1608Metric; MPN 0603WAF3300T5E
R8: 2.2k; Resistor_SMD_R_0603_1608Metric; MPN 0603WAF2201T5E

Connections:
BAT_SENSE: C4.1, R7.2; also elsewhere on the board
CELL_N_RAW: BT1.2 (-), C4.2, Q1.2 (S); also elsewhere on the board
CELL_P: BT1.1 (+), R7.1; also elsewhere on the board
COUT: Q2.1 (G); also elsewhere on the board
DOUT: Q1.1 (G); also elsewhere on the board
FET_DRAIN: Q1.3 (D), Q2.3 (D)
GND: R8.1; also elsewhere on the board
SENSE_FET: Q2.2 (S); also elsewhere on the board
VMINUS: R8.2; also elsewhere on the board

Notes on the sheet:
CELL_N_RAW is isolated from system ground by the protection path. BT1 accepts the rechargeable LIR2032 only. Cell compatibility, protection, USB rearm and cold insertion remain qualification gates.

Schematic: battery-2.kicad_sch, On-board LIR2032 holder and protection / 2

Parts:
R9: 3.3; Resistor_SMD_R_0603_1608Metric; MPN 0603WAF330KT5E
U4: Cell protector; Package_SON_WSON-6_1.5x1.5mm_P0.5mm; MPN BQ29700DSER

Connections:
BAT_SENSE: U4.5 (BAT); also elsewhere on the board
CELL_N_RAW: U4.4 (VSS); also elsewhere on the board
COUT: U4.2 (COUT); also elsewhere on the board
DOUT: U4.3 (DOUT); also elsewhere on the board
GND: R9.2; also elsewhere on the board
SENSE_FET: R9.1; also elsewhere on the board
VMINUS: U4.6 (V-); also elsewhere on the board

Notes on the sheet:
CELL_N_RAW is isolated from system ground by the protection path. BT1 accepts the rechargeable LIR2032 only. Cell compatibility, protection, USB rearm and cold insertion remain qualification gates.

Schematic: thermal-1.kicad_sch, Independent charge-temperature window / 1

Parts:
C9: 100n; Capacitor_SMD_C_0603_1608Metric; MPN CC0603KRX7R9BB104
Q3: Charge enable; Package_TO_SOT_SMD_SOT-23; MPN 2N7002
Q4: Charge enable hot gate; Package_TO_SOT_SMD_SOT-23; MPN 2N7002
R10: 56k; Resistor_SMD_R_0603_1608Metric; MPN 0603WAF5602T5E
R11: 82k; Resistor_SMD_R_0603_1608Metric; MPN 0603WAF8202T5E
R12: 18k; Resistor_SMD_R_0603_1608Metric; MPN 0603WAF1802T5E

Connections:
CE_MID: Q3.2 (S), Q4.3 (D)
CE_N: Q3.3 (D); also elsewhere on the board
GND: C9.2, Q4.2 (S); also elsewhere on the board
TEMP_COLD: R11.2, R12.1; also elsewhere on the board
TEMP_COLD_OK: Q3.1 (G); also elsewhere on the board
TEMP_HOT: R12.2; also elsewhere on the board
TEMP_HOT_OK: Q4.1 (G); also elsewhere on the board
TEMP_SENSE: R10.2; also elsewhere on the board
U5_VCC: C9.1; also elsewhere on the board
VBUS: R10.1, R11.1; also elsewhere on the board

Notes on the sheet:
TH1 on the board beside BT1; both window outputs must enable their series FETs for charging. Gate pulldowns disable charging when comparator power is absent; threshold and fault tests remain required.

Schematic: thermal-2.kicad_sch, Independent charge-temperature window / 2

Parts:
R13: 12k; Resistor_SMD_R_0603_1608Metric; MPN 0603WAF1202T5E
R14, R15: 100k; Resistor_SMD_R_0603_1608Metric; MPN 0603WAF1003T5E
R39: 1k; Resistor_SMD_R_0603_1608Metric; MPN 0603WAF1001T5E
TH1: 10k NTC B3380; Resistor_SMD_R_0603_1608Metric; MPN NCP18XH103F03RB
U5: Push-pull temperature window; Package_TO_SOT_SMD_SOT-23-8; MPN TLV7012DDFR

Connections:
GND: R13.2, R14.2, R15.2, TH1.2, U5.4 (VEE); also elsewhere on the board
TEMP_COLD: U5.3 (INA+); also elsewhere on the board
TEMP_COLD_OK: R14.1, U5.1 (OUTA); also elsewhere on the board
TEMP_HOT: R13.1, U5.6 (INB-); also elsewhere on the board
TEMP_HOT_OK: R15.1, U5.7 (OUTB); also elsewhere on the board
TEMP_SENSE: TH1.1, U5.2 (INA-), U5.5 (INB+); also elsewhere on the board
U5_VCC: R39.2, U5.8 (VCC); also elsewhere on the board
VBUS: R39.1; also elsewhere on the board

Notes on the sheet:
TH1 on the board beside BT1; both window outputs must enable their series FETs for charging. Gate pulldowns disable charging when comparator power is absent; threshold and fault tests remain required.

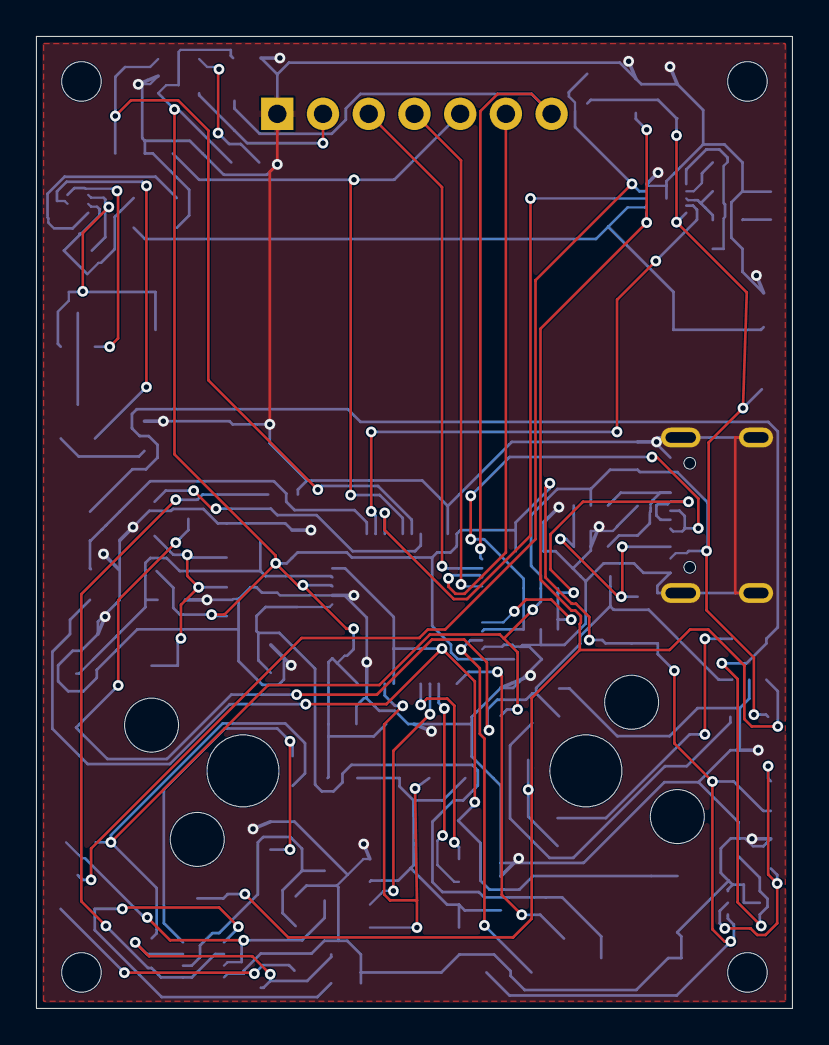
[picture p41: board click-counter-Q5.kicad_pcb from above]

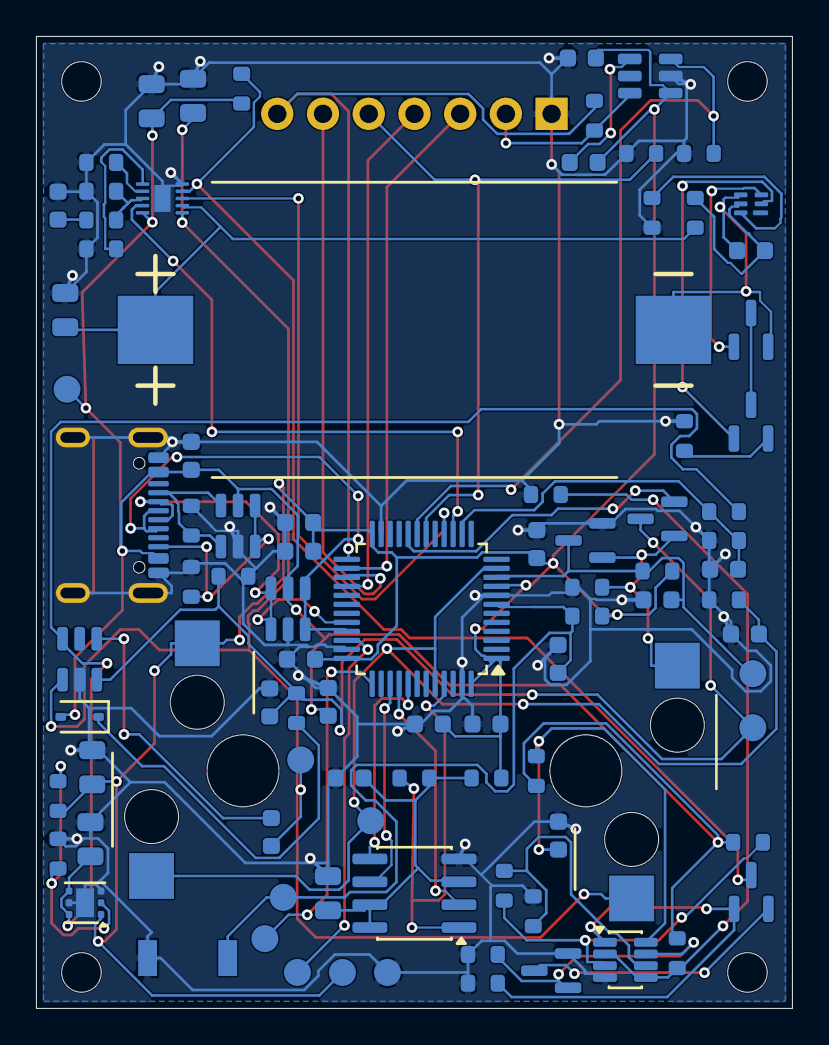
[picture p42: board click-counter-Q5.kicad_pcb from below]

Board: 2 copper layers, 42.0 x 54.0 mm, 96 parts (91 on the bottom side), 56 nets.

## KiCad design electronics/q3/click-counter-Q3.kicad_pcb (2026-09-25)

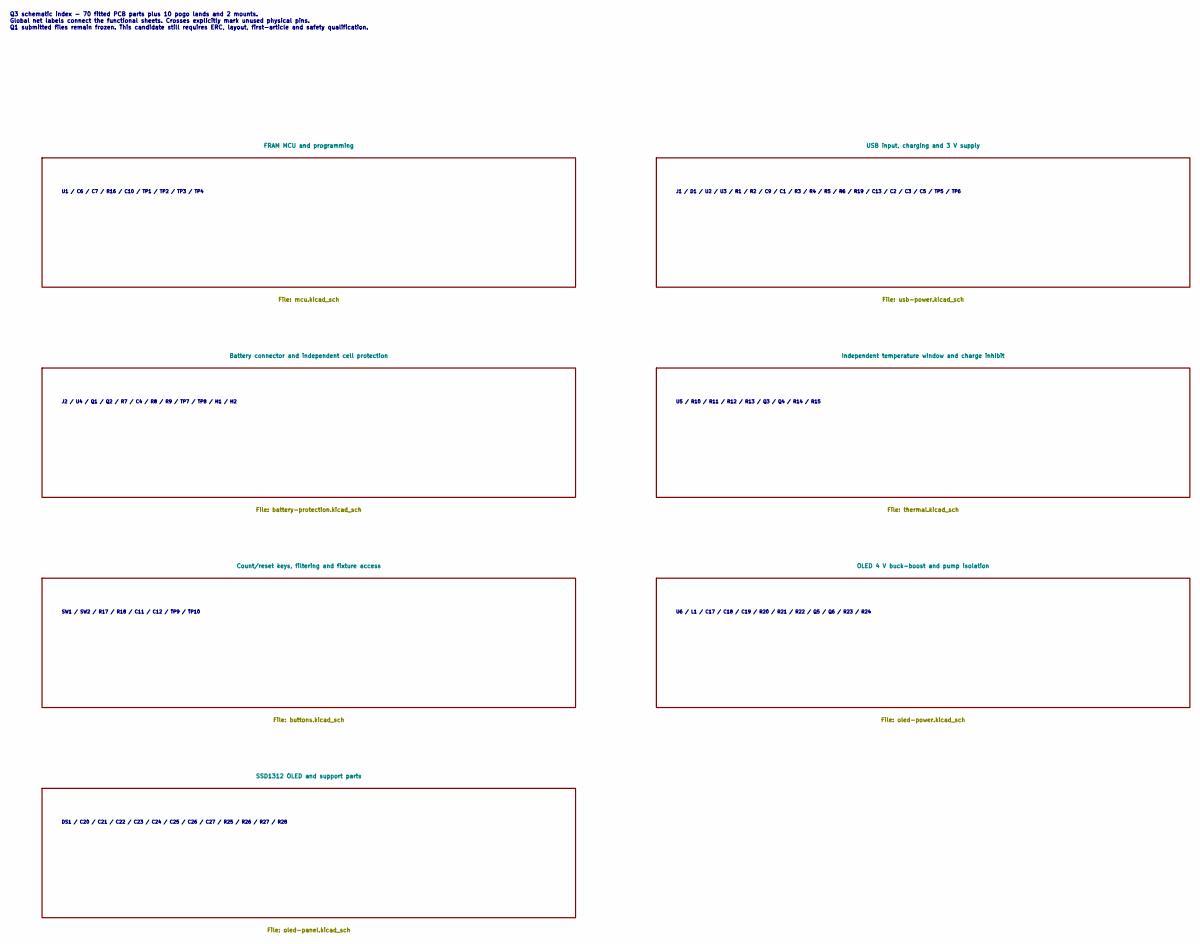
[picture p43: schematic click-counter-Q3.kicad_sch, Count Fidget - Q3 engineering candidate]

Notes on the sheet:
Q3 schematic index - 70 fitted PCB parts plus 10 pogo lands and 2 mounts. Global net labels connect the functional sheets. Crosses explicitly mark unused physical pins. Q1 submitted files remain frozen. This candidate still requires ERC, layout, first-article and safety qualification.
U1 / C6 / C7 / R16 / C10 / TP1 / TP2 / TP3 / TP4
J1 / D1 / U2 / U3 / R1 / R2 / C9 / C1 / R3 / R4 / R5 / R6 / R19 / C13 / C2 / C3 / C5 / TP5 / TP6
J2 / U4 / Q1 / Q2 / R7 / C4 / R8 / R9 / TP7 / TP8 / H1 / H2
U5 / R10 / R11 / R12 / R13 / Q3 / Q4 / R14 / R15
SW1 / SW2 / R17 / R18 / C11 / C12 / TP9 / TP10
U6 / L1 / C17 / C18 / C19 / R20 / R21 / R22 / Q5 / Q6 / R23 / R24
DS1 / C20 / C21 / C22 / C23 / C24 / C25 / C26 / C27 / R25 / R26 / R27 / R28

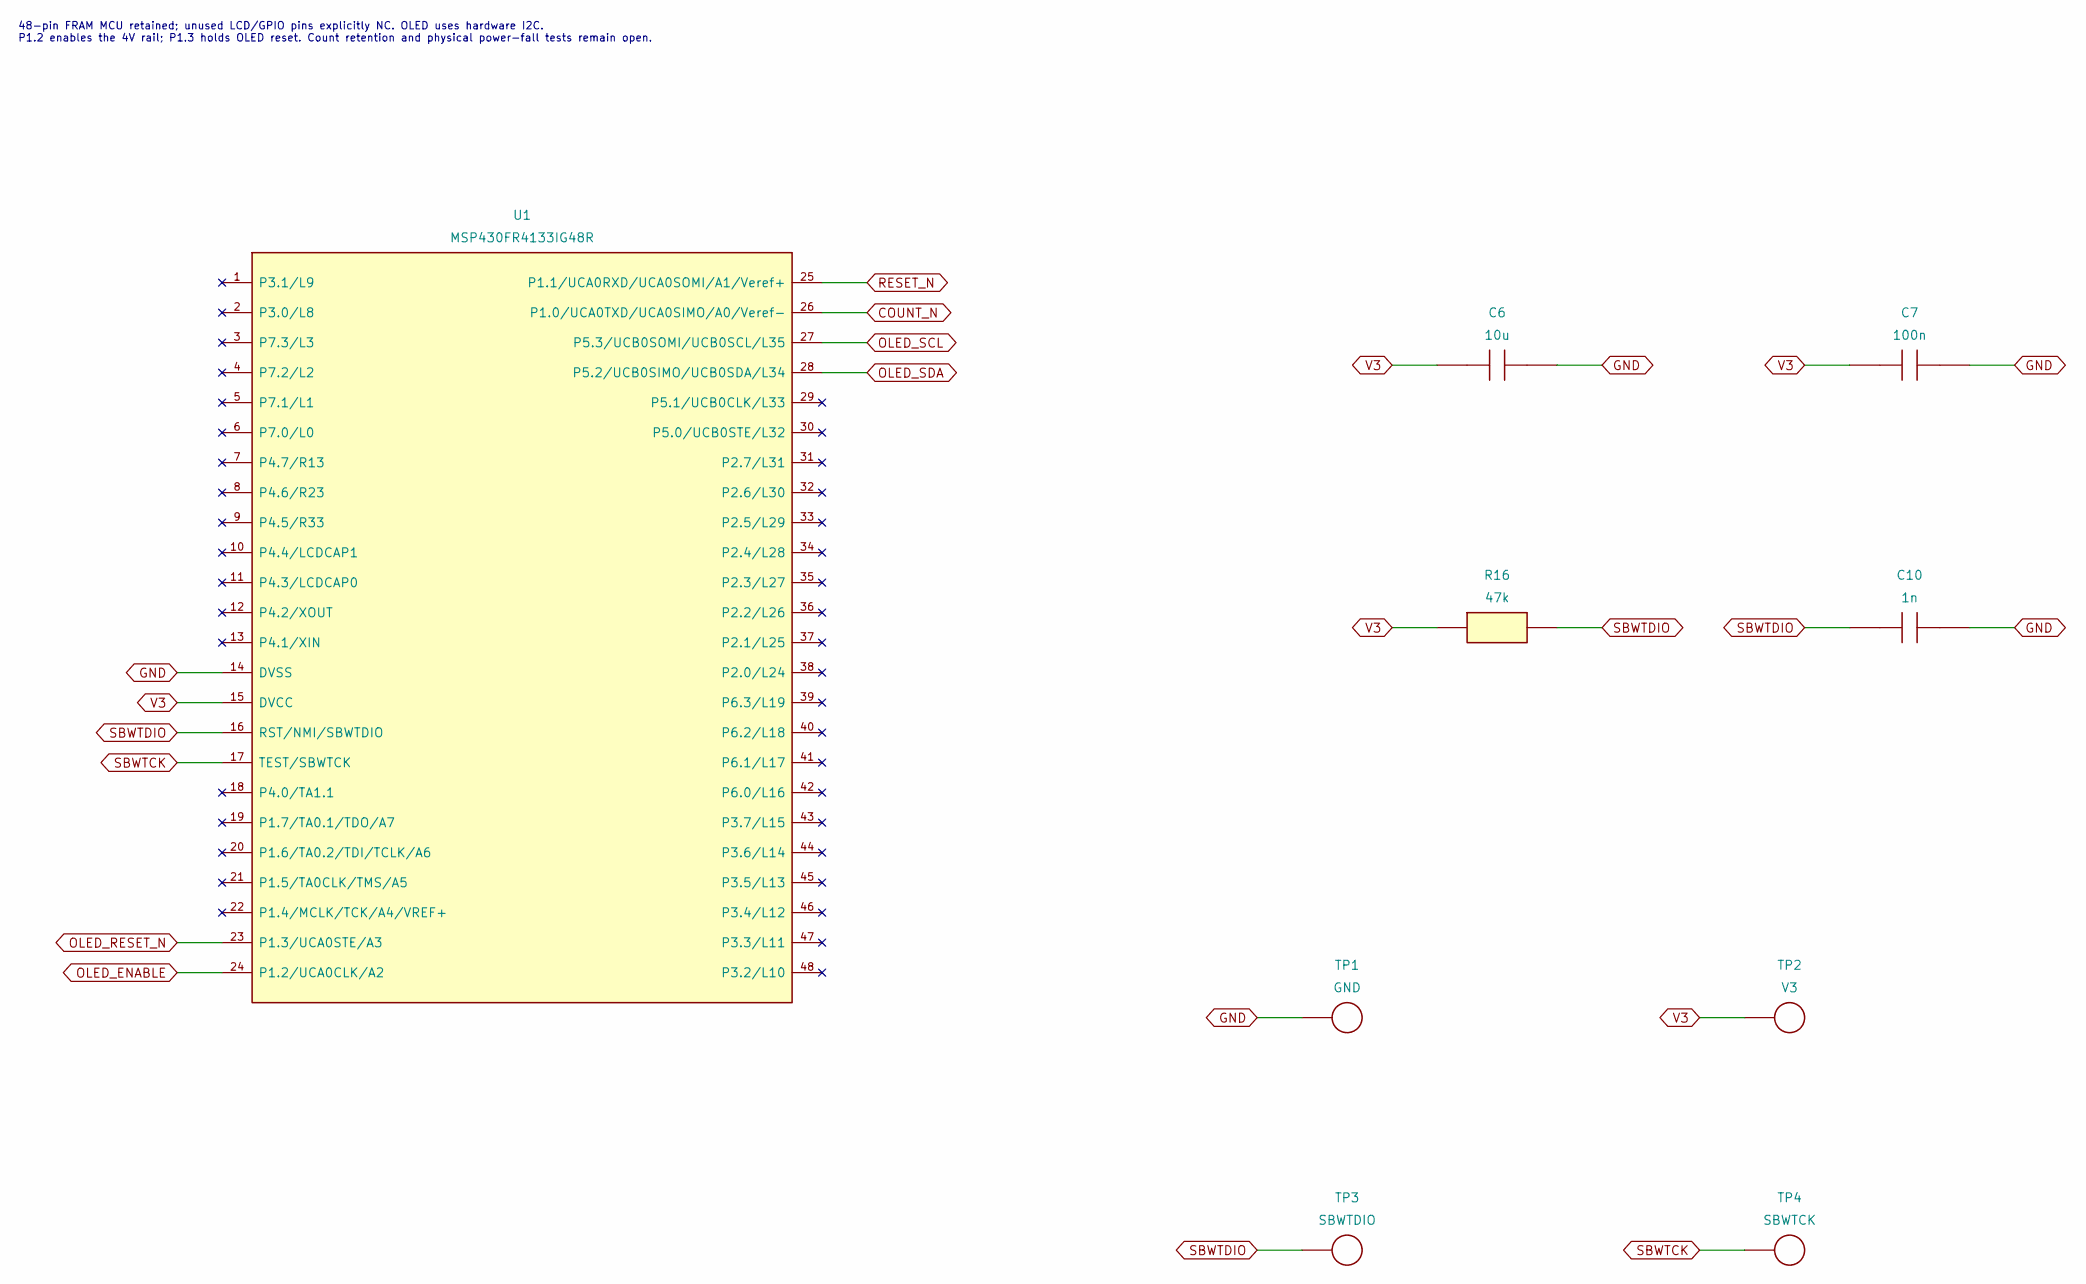
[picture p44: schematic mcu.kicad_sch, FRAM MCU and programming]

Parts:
C6: 10u; Capacitor_SMD_C_0805_2012Metric; MPN GRM21BR61E106KA73L
C7: 100n; Capacitor_SMD_C_0603_1608Metric; MPN GRM188R71H104KA93D
C10: 1n; Capacitor_SMD_C_0603_1608Metric; MPN GRM1885C1H102JA01D
R16: 47k; Resistor_SMD_R_0603_1608Metric; MPN 0603WAF4702T5E
TP1: GND; TestPoint_TestPoint_Pad_D1.5mm; MPN PCB LAND
TP2: V3; TestPoint_TestPoint_Pad_D1.5mm; MPN PCB LAND
TP3: SBWTDIO; TestPoint_TestPoint_Pad_D1.5mm; MPN PCB LAND
TP4: SBWTCK; TestPoint_TestPoint_Pad_D1.5mm; MPN PCB LAND
U1: MSP430FR4133; Package_SO_TSSOP-48_6.1x12.5mm_P0.5mm; MPN MSP430FR4133IG48R

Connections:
COUNT_N: U1.26 (P1.0/UCA0TXD/UCA0SIMO/A0/Veref-); also elsewhere on the board
GND: C6.2, C7.2, C10.2, TP1.1 (1_1), U1.14 (DVSS); also elsewhere on the board
OLED_ENABLE: U1.24 (P1.2/UCA0CLK/A2); also elsewhere on the board
OLED_RESET_N: U1.23 (P1.3/UCA0STE/A3); also elsewhere on the board
OLED_SCL: U1.27 (P5.3/UCB0SOMI/UCB0SCL/L35); also elsewhere on the board
OLED_SDA: U1.28 (P5.2/UCB0SIMO/UCB0SDA/L34); also elsewhere on the board
RESET_N: U1.25 (P1.1/UCA0RXD/UCA0SOMI/A1/Veref+); also elsewhere on the board
SBWTCK: TP4.1 (1_1), U1.17 (TEST/SBWTCK)
SBWTDIO: C10.1, R16.2, TP3.1 (1_1), U1.16 (RST/NMI/SBWTDIO)
V3: C6.1, C7.1, R16.1, TP2.1 (1_1), U1.15 (DVCC); also elsewhere on the board

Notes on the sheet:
48-pin FRAM MCU retained; unused LCD/GPIO pins explicitly NC. OLED uses hardware I2C. P1.2 enables the 4V rail; P1.3 holds OLED reset. Count retention and physical power-fall tests remain open.


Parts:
C1, C3, C5: 2.2u; Capacitor_SMD_C_0805_2012Metric; MPN GRM21BR71E225KE11L
C2: 10u; Capacitor_SMD_C_0805_2012Metric; MPN GRM21BR61E106KA73L
C9: 100n; Capacitor_SMD_C_0603_1608Metric; MPN GRM188R71H104KA93D
C13: 4.7n; Capacitor_SMD_C_0603_1608Metric; MPN GRM1885C1H472JA01D
D1: USB ESD; Package_TO_SOT_SMD_SOT-23-6; MPN USBLC6-2SC6
J1: USB-C charge; Connector_USB_USB_C_Receptacle_GCT_USB4105-xx-A_16P_TopMnt_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; MPN USB4105-GF-A
R1, R2: 5.1k; Resistor_SMD_R_0603_1608Metric; MPN RC0603FR-075K1L
R3: 24k; Resistor_SMD_R_0603_1608Metric; MPN 0603WAF2402T5E
R4: 16.5k; Resistor_SMD_R_0603_1608Metric; MPN RC0603FR-0716K5L
R5: 10k; Resistor_SMD_R_0603_1608Metric; MPN RC0603FR-0710KL
R6: 100k; Resistor_SMD_R_0603_1608Metric; MPN RC0603FR-07100KL
R19: 2k; Resistor_SMD_R_0603_1608Metric; MPN RC0603FR-072KL
TP5: VBUS; TestPoint_TestPoint_Pad_D1.5mm; MPN PCB LAND
TP6: SYS; TestPoint_TestPoint_Pad_D1.5mm; MPN PCB LAND
U2: Li-ion charger; Package_DFN_QFN_Texas_DLH0010A_WSON-10-1EP_2.2x2mm_P0.4mm_E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; MPN BQ25185DLHR
U3: 3.0 V LDO; Package_TO_SOT_SMD_SOT-23-5; MPN TPS7A0230PDBVR

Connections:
CC1: D1.1 (I/O1), D1.6 (I/O1), J1.A5 (CCA), R1.1
CC2: D1.3 (I/O2), D1.4 (I/O2), J1.B5 (CCB), R2.1
CELL_P: C3.1, U2.2 (BAT); also elsewhere on the board
CE_N: R6.2, U2.4 (~CE); also elsewhere on the board
GND: C1.2, C2.2, C3.2, C5.2, C9.2, C13.2, D1.2 (GND), J1.A1 (GND), J1.A12 (GND), J1.B1 (GND), J1.B12 (GND), J1.SH (SHIELD), R1.2, R2.2, R3.2, R4.2, R5.2, U2.5 (GND), U2.11 (EP/GND), U3.2 (GND), U3.4 (NC/GND-permitted); also elsewhere on the board
ISET: R4.1, R19.1, U2.8 (ISET)
RC_COMP: C13.1, R19.2
SYS: C2.1, C5.1, TP6.1 (1_1), U2.1 (SYS), U3.1 (IN), U3.3 (EN); also elsewhere on the board
TS_FIXED: R5.1, U2.6 (TS/MR)
V3: U3.5 (OUT); also elsewhere on the board
VBUS: C1.1, C9.1, D1.5 (VBUS), J1.A4 (VBUS), J1.A9 (VBUS), J1.B4 (VBUS), J1.B9 (VBUS), R6.1, TP5.1 (1_1), U2.10 (IN); also elsewhere on the board
VSET: R3.1, U2.7 (ILIM/VSET)

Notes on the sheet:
USB is charge-only: D+/D-/SBU pins explicitly NC. STAT1/STAT2 unused open-drain outputs are NC. TPS7A0230PDBVR includes active output discharge. Pin 4 may be grounded. No manufacture release.


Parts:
C4: 100n; Capacitor_SMD_C_0603_1608Metric; MPN GRM188R71H104KA93D
H1, H2: M2 clearance; MountingHole_MountingHole_2.2mm_M2; MPN NPTH
J2: Battery + NTC; Connector_JST_JST_SH_SM04B-SRSS-TB_1x04-1MP_P1.00mm_Horizon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; MPN SM04B-SRSS-TB(LF)(SN)
Q1: Discharge FET; Package_TO_SOT_SMD_SOT-23; MPN DMN2056U-7
Q2: Charge FET; Package_TO_SOT_SMD_SOT-23; MPN DMN2056U-7
R7: 330; Resistor_SMD_R_0603_1608Metric; MPN RC0603FR-07330RL
R8: 2.2k; Resistor_SMD_R_0603_1608Metric; MPN RC0603FR-072K2L
R9: 3.3; Resistor_SMD_R_0603_1608Metric; MPN 0603WAF330KT5E
TP7: CELL_P; TestPoint_TestPoint_Pad_D1.5mm; MPN PCB LAND
TP8: CELL_N_RAW; TestPoint_TestPoint_Pad_D1.5mm; MPN PCB LAND
U4: Cell protector; Package_SON_WSON-6_1.5x1.5mm_P0.5mm; MPN BQ29700DSER

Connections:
BAT_SENSE: C4.1, R7.2, U4.5 (BAT)
CELL_N_RAW: C4.2, J2.2 (CELL-RAW), Q1.2 (S), TP8.1 (1_1), U4.4 (VSS)
CELL_P: J2.1 (CELL+), R7.1, TP7.1 (1_1); also elsewhere on the board
COUT: Q2.1 (G), U4.2 (COUT)
DOUT: Q1.1 (G), U4.3 (DOUT)
FET_DRAIN: Q1.3 (D), Q2.3 (D)
GND: J2.4 (NTC-RETURN), R8.1, R9.2; also elsewhere on the board
SENSE_FET: Q2.2 (S), R9.1
TEMP_SENSE: J2.3 (NTC); also elsewhere on the board
VMINUS: R8.2, U4.6 (V-)

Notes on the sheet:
J2 mates the offboard CC-BAT-001 cell/NTC harness. CELL_N_RAW must remain isolated from system GND. BQ29700 undervoltage tolerance, protection bypass/recovery and final pack remain release gates.

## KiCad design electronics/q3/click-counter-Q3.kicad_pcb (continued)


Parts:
Q3: Charge enable; Package_TO_SOT_SMD_SOT-23; MPN 2N7002,215
Q4: Charge enable hot gate; Package_TO_SOT_SMD_SOT-23; MPN 2N7002,215
R10: 57.6k; Resistor_SMD_R_0603_1608Metric; MPN RC0603FR-0757K6L
R11: 115k; Resistor_SMD_R_0603_1608Metric; MPN 0603WAF1153T5E
R12: 24.3k; Resistor_SMD_R_0603_1608Metric; MPN RC0603FR-0724K3L
R13: 16.2k; Resistor_SMD_R_0603_1608Metric; MPN RC0603FR-0716K2L
R14, R15: 100k; Resistor_SMD_R_0603_1608Metric; MPN RC0603FR-07100KL
U5: Push-pull temperature window; TLV7032_DGK0008A_TI; MPN TLV7012DGKR

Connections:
CE_MID: Q3.2 (S), Q4.3 (D)
CE_N: Q3.3 (D); also elsewhere on the board
GND: Q4.2 (S), R13.2, R14.2, R15.2, U5.4 (VEE); also elsewhere on the board
TEMP_COLD: R11.2, R12.1, U5.3 (INA+)
TEMP_COLD_OK: Q3.1 (G), R14.1, U5.1 (OUTA)
TEMP_HOT: R12.2, R13.1, U5.6 (INB-)
TEMP_HOT_OK: Q4.1 (G), R15.1, U5.7 (OUTB)
TEMP_SENSE: R10.2, U5.2 (INA-), U5.5 (INB+); also elsewhere on the board
VBUS: R10.1, R11.1, U5.8 (VCC); also elsewhere on the board

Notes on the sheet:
TLV7012 push-pull outputs remain separate. Both series FETs must conduct to pull CE_N low. Gate pulldowns hold charging disabled after comparator power loss. POR, threshold and fail-safe tests remain open.


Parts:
C11, C12: 1n; Capacitor_SMD_C_0603_1608Metric; MPN GRM1885C1H102JA01D
R17, R18: 220k; Resistor_SMD_R_0603_1608Metric; MPN 0603WAF2203T5E
SW1: COUNT; HanElectricity_CPG151101D13_MX_Plate; MPN CPG151101D13
SW2: RESET; HanElectricity_CPG151101D13_MX_Plate; MPN CPG151101D13
TP9: COUNT_N; TestPoint_TestPoint_Pad_D1.5mm; MPN PCB LAND
TP10: RESET_N; TestPoint_TestPoint_Pad_D1.5mm; MPN PCB LAND

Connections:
COUNT_N: C11.1, R17.2, SW1.1, TP9.1 (1_1); also elsewhere on the board
GND: C11.2, C12.2, SW1.2, SW2.2; also elsewhere on the board
RESET_N: C12.1, R18.2, SW2.1, TP10.1 (1_1); also elsewhere on the board
V3: R17.1, R18.1; also elsewhere on the board

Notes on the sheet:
HanElectricity CPG151101D13, 19.05 mm stem spacing; active-low keys with 220k pull-ups. Firmware captures one count per accepted press; physical switch/clip/plate support remains unqualified.


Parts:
C17, C18, C19: 22u; Capacitor_SMD_C_0805_2012Metric; MPN CL21A226MAYNNNE
L1: 2.2u; Inductor_SMD_L_Murata_DFE201612E_2.0x1.6mm; MPN DFE201612E-2R2M=P2
Q5: OLED VBAT disconnect; Package_TO_SOT_SMD_SOT-23; MPN DMP2035U-7
Q6: OLED switch gate; Package_TO_SOT_SMD_SOT-23; MPN DMN2056U-7
R20: 5.11k; Resistor_SMD_R_0603_1608Metric; MPN RC0603FR-075K11L
R21: 20.5k; Resistor_SMD_R_0603_1608Metric; MPN RC0603FR-0720K5L
R22: 24.9k; Resistor_SMD_R_0603_1608Metric; MPN RC0603FR-0724K9L
R23: 47k; Resistor_SMD_R_0603_1608Metric; MPN 0603WAF4702T5E
R24: 100k; Resistor_SMD_R_0603_1608Metric; MPN RC0603FR-07100KL
U6: 4.0V OLED buck-boost; TPS63900_DSK0010A_TI; MPN TPS63900DSKR

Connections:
GND: C17.2, C18.2, C19.2, Q6.2 (S), R20.2, R21.2, R22.2, R24.2, U6.8 (GND), U6.11 (EP/GND); also elsewhere on the board
OLED_4V: C18.1, C19.1, Q5.2 (S), R23.1, U6.6 (VOUT)
OLED_CFG1: R20.1, U6.3 (CFG1)
OLED_CFG2: R21.1, U6.4 (CFG2)
OLED_CFG3: R22.1, U6.5 (CFG3)
OLED_ENABLE: Q6.1 (G), R24.1, U6.1 (EN); also elsewhere on the board
OLED_LX1: L1.1, U6.9 (LX1)
OLED_LX2: L1.2, U6.7 (LX2)
OLED_SWITCH_GATE: Q5.1 (G), Q6.3 (D), R23.2
OLED_VBAT: Q5.3 (D); also elsewhere on the board
SYS: C17.1, U6.2 (SEL), U6.10 (VIN); also elsewhere on the board

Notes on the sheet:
TPS63900DSKR:4.0V,10mA AVERAGE input setting; not a guaranteed peak clamp. Q5/Q6 disconnect pump input during sleep; GPIO defaults low. Existing battery protection unchanged.


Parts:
C20, C24, C27: 100n; Capacitor_SMD_C_0603_1608Metric; MPN GRM188R71H104KA93D
C21: 10u; Capacitor_SMD_C_0805_2012Metric; MPN GRM21BR61E106KA73L
C22: 2.2u; Capacitor_SMD_C_0805_2012Metric; MPN GRM21BR71E225KE11L
C23: 4.7u; Capacitor_SMD_C_0805_2012Metric; MPN GRM21BZ71H475KE15L
C25, C26: 1u; Capacitor_SMD_C_0603_1608Metric; MPN CL10B105KA8NNNC
DS1: X087-2832TSWIG02-H14; MPN X087-2832TSWIG02-H14
R25: 100k; Resistor_SMD_R_0603_1608Metric; MPN RC0603FR-07100KL
R26, R27: 4.7k; Resistor_SMD_R_0603_1608Metric; MPN RC0603FR-074K7L
R28: 750k; Resistor_SMD_R_0603_1608Metric; MPN RC0603FR-07750KL

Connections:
GND: C20.2, C21.2, C22.2, C23.2, C24.2, C27.2, DS1.7 (VSS), R25.2, R28.2; also elsewhere on the board
OLED_C1N: C26.2, DS1.4 (C1N)
OLED_C1P: C26.1, DS1.3 (C1P)
OLED_C2N: C25.2, DS1.2 (C2N)
OLED_C2P: C25.1, DS1.1 (C2P)
OLED_IREF: DS1.12 (IREF), R28.1
OLED_RESET_N: DS1.9 (RES#), R25.1; also elsewhere on the board
OLED_SCL: DS1.10 (SCL), R26.2; also elsewhere on the board
OLED_SDA: DS1.11 (SDA), R27.2; also elsewhere on the board
OLED_VBAT: C27.1, DS1.5 (VBAT); also elsewhere on the board
OLED_VCC: C23.1, C24.1, DS1.14 (VCC)
OLED_VCOMH: C22.1, DS1.13 (VCOMH)
V3: C20.1, C21.1, DS1.8 (VDD), R26.1, R27.1; also elsewhere on the board

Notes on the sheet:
Exact X087-2832TSWIG02-H14;1C2P,2C2N,3C1P,4C1N,5VBAT,6NC,7GND,8VDD. External750k IREF;9V internal pump. FPC process, sequencing, current and readability require qualification.



Board: 2 copper layers, 42.0 x 40.0 mm, 82 parts (77 on the bottom side), 48 nets.

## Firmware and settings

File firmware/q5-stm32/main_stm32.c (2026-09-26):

#include "stm32l072xx.h"
#include "board.h"
#include "app.h"
#include "oled.h"
#include "fram.h"
#include "rail.h"
#include "battery.h"
#define BIT(n) (1UL<<(n))
#define BUTTONS (BIT(BOARD_INC_PIN)|BIT(BOARD_COUNT_RESET_PIN))
#define FLASH_ERRORS (FLASH_SR_WRPERR|FLASH_SR_PGAERR|FLASH_SR_SIZERR|FLASH_SR_OPTVERR|FLASH_SR_RDERR|FLASH_SR_NOTZEROERR|FLASH_SR_FWWERR)
/* >=512 core cycles (128us at 4MHz) after every FRAM CS release: about five
 * cycles per iteration on Cortex-M0+ with zero flash wait states. */
#define FRAM_CS_GUARD_LOOPS 110U
/* A battery power-off that has not removed the supply within this time means
 * USB or a held COUNT key is keeping U7 on: fall back to Stop. */
#define POWER_RELEASE_MS 200U
/* LO is shown this long before a low-battery power-off. */
#define CUTOFF_NOTICE_MS 2000U
uint32_t SystemCoreClock=CORE_HZ;
static App app;
static InputQueue inputs;
static Oled display;
static Rail rail;
static Battery battery;
static uint8_t adc_state,adc_channel;
static uint16_t vref_raw;
static uint32_t adc_deadline;
static volatile uint32_t milliseconds;
static volatile bool tick_running;
/* Button capture starts only once the foreground loop can drain the queue:
 * the boot-time journal scan can exceed the queue's 255 ms of samples. */
static volatile bool capture_enabled;
/* During the boot journal scan only level changes (plus one settle sample per
 * change) are queued, so presses made while storage loads are kept without
 * filling the queue with identical samples. */
static volatile bool early_capture,early_pending;
static volatile uint8_t early_raw;
static volatile uint32_t early_settle;
static volatile uint8_t tx[OLED_TX_MAX],tx_length,tx_position,bus_status;
static uint32_t bus_started;
static bool configuration_ok,wake_key;
static uint32_t reset_flags;
static bool shutdown_latched;
static uint32_t shutdown_at;
static NvHal nv;
static Fram memory;
static bool storage_idle_attempted,release_tried;
static uint32_t now(void){return milliseconds;}
static uint8_t raw_buttons(void){uint32_t pins=GPIOA->IDR;return (uint8_t)((~pins&BIT(BOARD_INC_PIN))|(pins&BIT(BOARD_COUNT_RESET_PIN)));}
static void mode(GPIO_TypeDef *p,unsigned pin,unsigned value){p->MODER=(p->MODER&~(3UL<<(pin*2)))|(value<<(pin*2));}
static void pull(GPIO_TypeDef *p,unsigned pin,unsigned value){p->PUPDR=(p->PUPDR&~(3UL<<(pin*2)))|(value<<(pin*2));}
static void alternate(GPIO_TypeDef *p,unsigned pin,unsigned af){unsigned i=pin/8U,shift=(pin%8U)*4U;p->AFR[i]=(p->AFR[i]&~(15UL<<shift))|(af<<shift);mode(p,pin,2);}
static void hold_power(bool on){GPIOB->BSRR=BIT(BOARD_PWR_HOLD_PIN+(on?0:16));}
static void power(bool on){
    if(!on){SPI2->CR2=0;SPI2->CR1=0;mode(GPIOB,0,3);mode(GPIOB,12,3);mode(GPIOB,13,3);mode(GPIOB,14,3);mode(GPIOB,15,3);}
    GPIOB->BSRR=BIT(BOARD_OLED_ENABLE_PIN+(on?0:16));
}
static void reset(bool asserted){mode(GPIOB,BOARD_OLED_RESET_PIN,1);GPIOB->BSRR=BIT(BOARD_OLED_RESET_PIN+(asserted?16:0));}
void panic(void) {
    __disable_irq();RCC->IOPENR|=RCC_IOPENR_GPIOBEN;(void)RCC->IOPENR;
    reset(true);mode(GPIOB,BOARD_OLED_RESET_PIN,1);
    /* No FRAM writes on an unrecoverable core fault. Conservative discharge
     * delay does not depend on interrupts; then release the power latch so a
     * battery-only board switches itself off. Hardware boot remains available. */
    for(volatile uint32_t i=0;i<2000000UL;i++)__NOP();
    power(false);mode(GPIOB,BOARD_OLED_ENABLE_PIN,1);hold_power(false);
    for(;;)__WFI();
}
static bool supply_good(void){return !(PWR->CSR&PWR_CSR_PVDO);}
static bool power_good(void){return configuration_ok && supply_good();}
static bool spi1_wait(uint32_t flag,bool set){
    for(unsigned budget=0;budget<1000;budget++){
        if(SPI1->SR&(SPI_SR_MODF|SPI_SR_OVR))return false;
        if(((SPI1->SR&flag)!=0)==set)return true;
    }
    return false;
}
static bool fram_exchange(void*ctx,const uint8_t*tx_data,uint8_t*rx_data,unsigned length){
    (void)ctx;if(!length||length>35||!power_good())return false;
    GPIOB->BSRR=BIT(8); /* CS is OD with external pull-up to isolated VFRAM. */
    unsigned budget=1000;while(!(GPIOB->IDR&BIT(8))&&--budget){}if(!budget)return false;
    GPIOB->BSRR=BIT(8+16);
    bool okay=true;
    for(unsigned i=0;i<length;i++){
        if(!spi1_wait(SPI_SR_TXE,true)){okay=false;break;}
        *((volatile uint8_t*)&SPI1->DR)=tx_data[i];
        if(!spi1_wait(SPI_SR_RXNE,true)){okay=false;break;}
        rx_data[i]=*((volatile uint8_t*)&SPI1->DR);
    }
    if(okay)okay=spi1_wait(SPI_SR_TXE,true)&&spi1_wait(SPI_SR_BSY,false);
    GPIOB->BSRR=BIT(8);
    for(unsigned delay=0;delay<FRAM_CS_GUARD_LOOPS;delay++)__NOP(); /* >100us CS rise guard including clock tolerance */
    if(!okay){SPI1->CR1=0;mode(GPIOB,3,3);mode(GPIOB,4,3);mode(GPIOB,5,3);}
    return okay;
}
static void storage_isolate(void){
    GPIOB->BSRR=BIT(8); /* external VFRAM pull-up, never drive high */
    SPI1->CR1=0;SPI1->CR2=0;mode(GPIOB,3,3);mode(GPIOB,4,3);mode(GPIOB,5,3);
}
static void storage_init(void){
    RCC->APB2RSTR|=RCC_APB2RSTR_SPI1RST;RCC->APB2RSTR&=~RCC_APB2RSTR_SPI1RST;
    /*20ms exceeds the specified isolated-rail RC settle + memory power-up
     * interval. No FRAM pin is actively high while its rail is settling. */
    uint32_t begin=now();while((uint32_t)(now()-begin)<20U)__WFI();
    GPIOB->BSRR=BIT(8);GPIOB->OTYPER|=BIT(8);mode(GPIOB,8,1);
    alternate(GPIOB,3,0);alternate(GPIOB,4,0);alternate(GPIOB,5,0);
    SPI1->CR1=SPI_CR1_MSTR|SPI_CR1_SSM|SPI_CR1_SSI|SPI_CR1_BR_1|SPI_CR1_SPE; /*500kHz, below1MHz with oscillator tolerance*/
    /* NRST may reset only MCU while FRAM remains asleep. Wake first and
     * wait independently of POR before identification/status probing. */
    uint8_t wake_tx[4]={3,0,0,0},wake_rx[4];(void)fram_exchange(0,wake_tx,wake_rx,4);
    begin=now();while((uint32_t)(now()-begin)<2U)__WFI();
    const FramBus bus={fram_exchange,0};(void)fram_init(&memory,&bus);nv=fram_storage(&memory);
}
static void charger_inputs(bool enabled){
    /* BQ25185 STAT1/STAT2 are open drain; internal pull-ups only while awake. */
    for(unsigned pin=BOARD_STAT1_PIN;pin<=BOARD_STAT2_PIN;pin++){
        if(enabled){pull(GPIOA,pin,1);mode(GPIOA,pin,0);}else{mode(GPIOA,pin,3);pull(GPIOA,pin,0);}
    }
}
/* ADC is polled without waiting. HCLK/2=2MHz (LFMEN set: RM0376 requires it
 * below 3.5MHz), 160.5-cycle acquisition exceeds
 * VREFINT 10us and settles the 75k-source SYS divider held by its 100nF
 * capacitor. Conversions alternate VREFINT (rail) and IN4 (SYS_LOAD/2). */
static void adc_service(bool awake,uint32_t t){
    if(!awake || adc_state==8){
        if(adc_state!=8)adc_deadline=t+5;
        adc_state=8;rail_invalid(&rail);
        if((ADC1->CR&(ADC_CR_ADSTART|ADC_CR_ADEN)) && (int32_t)(t-adc_deadline)>=0){
            /* A peripheral that never acknowledges stop/disable cannot hold
             * the application awake indefinitely. Reset only the ADC. */
            RCC->APB2RSTR|=RCC_APB2RSTR_ADC1RST;RCC->APB2RSTR&=~RCC_APB2RSTR_ADC1RST;
        }
        if(ADC1->CR&ADC_CR_ADSTART){ADC1->CR|=ADC_CR_ADSTP;return;}
        if(ADC1->CR&ADC_CR_ADEN){ADC1->CR|=ADC_CR_ADDIS;return;}
        ADC1->CR&=~ADC_CR_ADVREGEN;ADC->CCR&=~ADC_CCR_VREFEN;SYSCFG->CFGR3&=~SYSCFG_CFGR3_ENBUF_VREFINT_ADC;
        adc_state=0;charger_inputs(false);return;
    }
    if(!adc_state){
        rail_invalid(&rail);ADC1->CFGR1=0;ADC1->CFGR2=ADC_CFGR2_CKMODE_0;
        ADC1->SMPR=ADC_SMPR_SMP;adc_channel=17;vref_raw=0;ADC1->CHSELR=ADC_CHSELR_CHSEL17;
        SYSCFG->CFGR3|=SYSCFG_CFGR3_ENBUF_VREFINT_ADC;
        ADC->CCR|=ADC_CCR_VREFEN|ADC_CCR_LFMEN;ADC1->CR|=ADC_CR_ADVREGEN;charger_inputs(true);
        adc_deadline=t+5;adc_state=1;return;
    }
    if(adc_state==1){
        if((int32_t)(t-adc_deadline)<0)return;
        if(!(SYSCFG->CFGR3&SYSCFG_CFGR3_VREFINT_RDYF)){if((int32_t)(t-adc_deadline)>=10){rail_invalid(&rail);adc_state=7;}return;}
        ADC1->CR|=ADC_CR_ADCAL;adc_deadline=t+5;adc_state=2;return;
    }
    if(adc_state==2){
        if(!(ADC1->CR&ADC_CR_ADCAL)){adc_deadline=t+1;adc_state=3;return;}
    }else if(adc_state==3){
        if((int32_t)(t-adc_deadline)>=0){ADC1->ISR=ADC_ISR_ADRDY;ADC1->CR|=ADC_CR_ADEN;adc_deadline=t+5;adc_state=4;}return;
    }else if(adc_state==4){
        if(ADC1->ISR&ADC_ISR_ADRDY){adc_deadline=t;adc_state=5;return;}
    }else if(adc_state==5){
        if((int32_t)(t-adc_deadline)>=0){
            ADC1->CHSELR=adc_channel==17?ADC_CHSELR_CHSEL17:(1UL<<BOARD_VBAT_ADC_CHANNEL);
            ADC1->ISR=ADC_ISR_EOC|ADC_ISR_OVR;ADC1->CR|=ADC_CR_ADSTART;adc_deadline=t+5;adc_state=6;
        }
        return;
    }else if(adc_state==6){
        if(ADC1->ISR&ADC_ISR_OVR){rail_invalid(&rail);adc_state=7;return;}
        if(ADC1->ISR&ADC_ISR_EOC){
            uint16_t raw=(uint16_t)ADC1->DR;
            if(adc_channel==17){
                uint16_t cal=*(volatile const uint16_t*)0x1ff80078UL;
                rail_sample(&rail,cal,raw,t);vref_raw=rail.valid?raw:0;adc_channel=BOARD_VBAT_ADC_CHANNEL;adc_deadline=t+1;
            }else{
                if(vref_raw){
                    /* SYS_LOAD = 2 x IN4 x VDDA/4095, VDDA = 3000mV x VREFINT_CAL/VREFINT.
                     * Two steps keep every product below 2^32. */
                    uint32_t cal=*(volatile const uint16_t*)0x1ff80078UL;
                    uint32_t vdda=(3000UL*cal)/vref_raw;
                    uint32_t mv=(2UL*raw*vdda)/4095UL;
                    battery_sample(&battery,(uint16_t)(mv>65535U?65535U:mv),(GPIOA->IDR&BIT(BOARD_STAT1_PIN))!=0,(GPIOA->IDR&BIT(BOARD_STAT2_PIN))!=0);
                }
                adc_channel=17;adc_deadline=t+7;
            }
            adc_state=5;return;
        }
    }else return; /* Latched ADC fault: display staysOFF untilsleep/restart. */
    if((int32_t)(t-adc_deadline)>=0){rail_invalid(&rail);adc_state=7;}
}
static void bus_abort(void) {
    SPI2->CR2=0;SPI2->CR1=0;
    GPIOB->BSRR=BIT(BOARD_SPI_CS_PIN);
    RCC->APB1RSTR|=RCC_APB1RSTR_SPI2RST;RCC->APB1RSTR&=~RCC_APB1RSTR_SPI2RST;
    bus_status=0;
}
static bool bus_start(const uint8_t *bytes,uint8_t length,uint32_t t) {
    if(!length || length>OLED_TX_MAX || bus_status==1)return false;
    bus_abort();tx_length=length;tx_position=0;
    for(unsigned i=0;i<length;i++)tx[i]=bytes[i];
    bus_started=t;bus_status=1;
    /* Common renderer's first byte is command/data classification; SPI uses
     * the D/C pin and never transmits it. */
    tx_position=1;
    GPIOB->BSRR=BIT(BOARD_SPI_CS_PIN);mode(GPIOB,BOARD_SPI_CS_PIN,1);mode(GPIOB,BOARD_SPI_DC_PIN,1);
    alternate(GPIOB,BOARD_SPI_SCK_PIN,0);alternate(GPIOB,BOARD_SPI_MOSI_PIN,0);
    GPIOB->BSRR=BIT(BOARD_SPI_DC_PIN+((bytes[0]&0x40U)?0:16));
    GPIOB->BSRR=BIT(BOARD_SPI_CS_PIN+16);
    SPI2->CR1=SPI_CR1_MSTR|SPI_CR1_SSM|SPI_CR1_SSI|SPI_CR1_BIDIMODE|SPI_CR1_BIDIOE;
    SPI2->CR2=SPI_CR2_TXEIE|SPI_CR2_ERRIE;
    SPI2->CR1|=SPI_CR1_SPE;
    return true;
}
void SPI2_IRQHandler(void) {
    if(SPI2->SR&(SPI_SR_MODF|SPI_SR_OVR)){SPI2->CR2=0;bus_status=3;return;}
    if(SPI2->SR&SPI_SR_TXE) {
        if(tx_position<tx_length)*((volatile uint8_t *)&SPI2->DR)=tx[tx_position++];
        else SPI2->CR2&=~SPI_CR2_TXEIE;
    }
}
static OledBusResult bus_poll(uint32_t t) {
    if(bus_status==1 && tx_position==tx_length && (SPI2->SR&SPI_SR_TXE) && !(SPI2->SR&SPI_SR_BSY))bus_status=2;
    if(bus_status==2){bus_abort();return OLED_BUS_OK;}
    if(bus_status!=1 || (uint32_t)(t-bus_started)>=OLED_BUS_TIMEOUT_MS){bus_abort();return OLED_BUS_ERROR;}
    return OLED_BUS_BUSY;
}
static const OledHal oled_hal={power,reset,bus_start,bus_poll,bus_abort,now};
static void tick_start(void){SysTick->LOAD=CORE_HZ/1000UL-1U;SysTick->VAL=0;tick_running=true;SysTick->CTRL=SysTick_CTRL_CLKSOURCE_Msk|SysTick_CTRL_TICKINT_Msk|SysTick_CTRL_ENABLE_Msk;}
void SysTick_Handler(void){
    ++milliseconds;
    if(capture_enabled){input_push(&inputs,raw_buttons(),milliseconds);return;}
    if(!early_capture)return;
    uint8_t raw=raw_buttons();
    if(raw!=early_raw){early_raw=raw;early_settle=milliseconds+DEBOUNCE_MS+1U;early_pending=true;input_push(&inputs,raw,milliseconds);}
    else if(early_pending && (int32_t)(milliseconds-early_settle)>=0){early_pending=false;input_push(&inputs,raw,milliseconds);}
}
void EXTI0_1_IRQHandler(void) {
    /* A press re-latches the supply; a bare release (e.g. a key that was held
     * through the power-off) must not, or the board would stay on. */
    if(raw_buttons())hold_power(true);
    EXTI->PR=BUTTONS;if(capture_enabled)input_push(&inputs,raw_buttons(),milliseconds);
    if(!tick_running){tick_start();shutdown_latched=false;}
}
/* Option bytes left at the RM0376 factory value (BOR off) would disable all
 * storage. Program the reviewed USER half-word once, then reload. RDP is
 * never written. A second failure after the reload leaves OPT on screen. */
static bool options_ok(uint32_t optr){
    return ((optr&FLASH_OPTR_BOR_LEV)>>16)==BOARD_BOR_REQUIRED &&
           (optr&0xffU)==0xaaU && (optr&BIT(31)) && !(optr&BIT(23));
}
static void provision_options(void){
    uint32_t optr=FLASH->OPTR;
    if(options_ok(optr) || (optr&0xffU)!=0xaaU || (reset_flags&RCC_CSR_OBLRSTF))return;
    /* PVDO is meaningful only once VREFINT is ready and the PVD has settled. */
    uint32_t begin=now();
    while(!(PWR->CSR&PWR_CSR_VREFINTRDYF) && (uint32_t)(now()-begin)<5U){}
    begin=now();while((uint32_t)(now()-begin)<2U)__WFI();
    if(!(PWR->CSR&PWR_CSR_VREFINTRDYF) || !supply_good())return;
    uint32_t user=(optr>>16)&0xffffU;
    user=(user&~0x008fU&0xffffU)|BIT(15)|BOARD_BOR_REQUIRED; /* BOR_LEV=0xC, BFB2=0, nBOOT1=1 */
    if(user!=BOARD_OPTR_USER)return; /* unexpected WDG/STOP/STDBY choices: do not guess */
    uint32_t word=((~user&0xffffU)<<16)|user;
    /* Already stored but still not loaded as expected: show OPT rather than
     * rewriting the option word on every power-on. */
    if(*(volatile const uint32_t*)(OB_BASE+4U)==word)return;
    FLASH->SR=FLASH_ERRORS|FLASH_SR_EOP;
    if(FLASH->PECR&FLASH_PECR_PELOCK){FLASH->PEKEYR=0x89abcdefUL;FLASH->PEKEYR=0x02030405UL;}
    if(FLASH->PECR&FLASH_PECR_OPTLOCK){FLASH->OPTKEYR=0xfbead9c8UL;FLASH->OPTKEYR=0x24252627UL;}
    if(FLASH->PECR&(FLASH_PECR_PELOCK|FLASH_PECR_OPTLOCK))return;
    *(volatile uint32_t*)(OB_BASE+4U)=word;
    for(unsigned t=0;t<200000U && (FLASH->SR&FLASH_SR_BSY);t++){}
    if((FLASH->SR&(FLASH_SR_BSY|FLASH_ERRORS))){FLASH->PECR|=FLASH_PECR_OPTLOCK|FLASH_PECR_PELOCK;return;}
    FLASH->PECR|=FLASH_PECR_OBL_LAUNCH; /* system reset reloading option bytes */
    for(;;){}
}
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
int main(void) {
    __disable_irq();setup();tick_start();__enable_irq();
    provision_options();
    battery_reset(&battery);
    /* Power the module (held in reset) before the journal scan so its supply
     * settling overlaps boot; nothing is sent until the rail is measured. */
    OledView view={0,OLED_LABEL_NONE,OLED_BARS_HIDDEN,true};
    oled_init(&display,&oled_hal);
    oled_service(&display,&oled_hal,supply_good(),false,&view,now());
    __disable_irq();uint8_t boot_keys=raw_buttons();uint32_t boot_ms=milliseconds;
    early_raw=boot_keys;early_capture=true;__enable_irq();
    storage_init();app_init(&app,&nv,boot_ms,boot_keys);
    if(wake_key)app_wake_press(&app,boot_ms);
    if(!configuration_ok)app_storage_error(&app);
    __disable_irq();early_capture=false;input_push(&inputs,raw_buttons(),milliseconds);capture_enabled=true;__enable_irq();
    for(;;) {
        for(unsigned n=0;n<8;n++) {
            InputSample sample;uint32_t mask=__get_PRIMASK();__disable_irq();
            InputResult r=input_take(&inputs,&sample);__set_PRIMASK(mask);
            if(r==INPUT_EMPTY)break;
            app_input(&app,r,&sample);
        }
        /* Storage-protecting power-off below the battery cut-off, after LO
         * has been visible; never from a USB-regulated SYS reading. */
        if(battery.cutoff && !battery.usb && !shutdown_latched){shutdown_latched=true;shutdown_at=now()+CUTOFF_NOTICE_MS;}
        if(battery.usb)shutdown_latched=false; /* USB arrived during the LO notice: keep running and charge */
        bool shutdown=shutdown_latched && (int32_t)(now()-shutdown_at)>=0;
        bool run=app.counter.awake && !shutdown;
        if(run)hold_power(true);
        OledState prior_display=display.state;bool prior_bus=display.pending;
        unsigned prior_step=app.journal.step;bool prior_pending=app.journal.pending,prior_nv=app.journal.busy;
        uint8_t prior_adc=adc_state;
        bool storage_good=power_good();
        if(run) {
            storage_idle_attempted=false;
            /* A newly committed count reset grants one bounded recovery
             * attempt. No timer/held-key loop retries a failed peripheral. */
            if(!app.storage_failed && app.input.reset_requested && !memory.ready && power_good())storage_init();
            if(!app.storage_failed)(void)fram_wake(&memory,now());
        }
        if(!memory.ready && configuration_ok)app_storage_error(&app);
        storage_good=storage_good&&fram_available(&memory);
        app_service(&app,&nv,now(),storage_good);
        adc_service(run,now());
        view_of(&view);
        oled_service(&display,&oled_hal,run && supply_good(),rail_display_allowed(&rail,now()),&view,now());
        bool made_progress=display.state!=prior_display || display.pending!=prior_bus || app.journal.step!=prior_step || app.journal.pending!=prior_pending || app.journal.busy!=prior_nv || adc_state!=prior_adc;
        bool settled=app.counter.increment.stable==app.counter.increment.candidate && app.counter.reset.stable==app.counter.reset.candidate;
        bool quiet=!run && app_can_idle(&app) && settled && oled_is_off(&display) && adc_state==0;
        if(quiet && !storage_idle_attempted){
            storage_idle_attempted=true;
            if(memory.ready && !fram_sleep(&memory)){app_storage_error(&app);storage_isolate();}
            continue;
        }
        bool backend_idle=!memory.pending;
        if(run)release_tried=false;
        if(quiet && backend_idle && !battery.usb && !release_tried) {
            /* Battery only: release the latch. Supply collapse ends execution.
             * Still running afterwards means USB or a held COUNT key keeps U7
             * on: leave the latch released, drain the queued samples, then use
             * the Stop path, so letting go of the key switches the board off. */
            release_tried=true;hold_power(false);
            uint32_t begin=now();
            while((uint32_t)(now()-begin)<POWER_RELEASE_MS && !raw_buttons())__WFI();
            continue;
        }
        __disable_irq();
        if(inputs.gap || inputs.head!=inputs.tail || (EXTI->PR&BUTTONS)){__enable_irq();continue;}
        if(quiet && backend_idle) {
            /* USB-held (or key-held) fallback: Stop with the latch released, so
             * unplugging USB then switches the board off cleanly. */
            hold_power(false);
            SysTick->CTRL=0;tick_running=false;
            SCB->ICSR=SCB_ICSR_PENDSTCLR_Msk;
            PWR->CR&=~(PWR_CR_PDDS|PWR_CR_DSEEKOFF);PWR->CR|=PWR_CR_LPSDSR;
            SCB->SCR|=SCB_SCR_SLEEPDEEP_Msk;
            /* WFI with PRIMASK set closes the test/sleep race: a newly pending
             * EXTI wakes the core, then is serviced when interrupts unmask. */
            stop_from_ram();SCB->SCR&=~SCB_SCR_SLEEPDEEP_Msk;if(raw_buttons())hold_power(true);__enable_irq();
            battery_reset(&battery);
        } else {if(!made_progress && !display.pending){__DSB();__WFI();}__enable_irq();}
    }
}

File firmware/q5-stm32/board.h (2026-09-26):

#ifndef Q5_BOARD_H
#define Q5_BOARD_H
/* Q5 pin contract, separate from every Q3/Q4 assignment.
 * Firmware/build manifest and native model must agree before release. */
#define CORE_HZ 4000000UL
#define BOARD_INC_PIN 0U         /* PA0, active LOW: Q5 NMOS mirrors the SYS-referenced COUNT/power key */
#define BOARD_COUNT_RESET_PIN 1U /* PA1, active HIGH; shared key drives BOOT0. */
#define BOARD_VBAT_ADC_PIN 4U    /* PA4 / ADC_IN4: SYS_LOAD through 150k/150k 0.1% divider */
#define BOARD_VBAT_ADC_CHANNEL 4U
#define BOARD_STAT1_PIN 5U       /* PA5: BQ25185 STAT1 open drain, internal pull-up while awake */
#define BOARD_STAT2_PIN 6U       /* PA6: BQ25185 STAT2 open drain, internal pull-up while awake */
#define BOARD_PWR_HOLD_PIN 2U    /* PB2: HIGH keeps U7 (system load switch) on through D3 */
#define BOARD_OLED_RESET_PIN 0U  /* PB0, push-pull only while module powered; external pull-down */
#define BOARD_OLED_ENABLE_PIN 1U /* PB1, active high, external pull-down */
#define BOARD_SPI_CS_PIN 12U     /* PB12 GPIO */
#define BOARD_SPI_SCK_PIN 13U    /* PB13 AF0 */
#define BOARD_SPI_DC_PIN 14U     /* PB14 GPIO */
#define BOARD_SPI_MOSI_PIN 15U   /* PB15 AF0 */
#define BOARD_BOR_REQUIRED 0xCU  /* raw BOR_LEV 0xC = RM0376 "BOR LEVEL 5" = VBOR4, falling 2.68..2.85V */
/* Option-byte USER half-word (FLASH_OPTR[31:16]) the application provisions:
 * nBOOT1=1, BFB2=0, nRST_STDBY=1, nRST_STOP=1, WDG_SW=1, BOR_LEV=0xC. */
#define BOARD_OPTR_USER 0x807CU
#endif

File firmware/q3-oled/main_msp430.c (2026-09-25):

/* Unreleased Q3 OLED candidate. MSP430FR4133IG48R; never flash onto Q1/Q2.
 * Power and display parameters require the coordinated Q3 hardware. */
#include <msp430.h>
#include <stdbool.h>
#include <stdint.h>
#include "counter.h"
#include "oled.h"
#include "input.h"

#define BUTTONS (BIT0|BIT1)
#define OLED_ENABLE BIT2 /* P1.2, physical pin24, active HIGH */
#define OLED_RESET BIT3  /* P1.3, physical pin23, active LOW */
#define OLED_BUS_PINS (BIT2|BIT3) /* P5.2 pin28 SDA, P5.3 pin27 SCL */
#define JOURNAL ((volatile uint16_t *)0x1800U)
#define INPUT_FAULT_WORD ((volatile uint16_t *)0x1820U)
#define FRAM_PASSWORD 0xa500U
static Counter counter;
static Record shadow[2];
static Oled display;
static InputQueue inputs;
static InputState input_state;
static volatile uint32_t milliseconds;
static volatile uint16_t fraction;
static volatile uint8_t tick_running;
static volatile uint8_t tx[OLED_TX_MAX], tx_length, tx_position;
static volatile uint8_t bus_status; /* 0 idle, 1 transmitting, 2 success, 3 error */
static uint32_t bus_started;

static void load_journal(void) {
    for(unsigned s=0;s<2;s++)for(unsigned w=0;w<JOURNAL_WORDS;w++)
        shadow[s].words[w]=JOURNAL[s*JOURNAL_WORDS+w];
}
static uint16_t read_fault_word(void *unused) { (void)unused;return *INPUT_FAULT_WORD; }
static bool write_fault_word(void *unused,uint16_t value) {
    (void)unused;
    SYSCFG0=FRAM_PASSWORD|PFWP;
    __asm__ volatile ("" ::: "memory");
    *INPUT_FAULT_WORD=value;
    __asm__ volatile ("" ::: "memory");
    SYSCFG0=FRAM_PASSWORD|PFWP|DFWP;
    return *INPUT_FAULT_WORD==value;
}
static bool write_word(void *unused,unsigned slot,unsigned word,uint16_t value) {
    (void)unused;unsigned index=slot*JOURNAL_WORDS+word;
    SYSCFG0=FRAM_PASSWORD|PFWP;
    __asm__ volatile ("" ::: "memory");
    JOURNAL[index]=value;
    __asm__ volatile ("" ::: "memory");
    SYSCFG0=FRAM_PASSWORD|PFWP|DFWP;
    if(JOURNAL[index]!=value)return false;
    shadow[slot].words[word]=value;return true;
}
static void power(bool enabled) {
    if(enabled)P1OUT|=OLED_ENABLE;else P1OUT&=~OLED_ENABLE;
}
static void reset(bool asserted) {
    if(asserted)P1OUT&=~OLED_RESET;else P1OUT|=OLED_RESET;
}
static void bus_abort(void) {
    UCB0IE=0;UCB0CTLW0|=UCSWRST;bus_status=0;
    /* A reset or physical short may hold SDA low. No polling loop here:
     * the state machine backs off and counter/journal operation continues. */
}
static bool bus_start(const uint8_t *data,uint8_t length,uint32_t now) {
    if(!length || length>OLED_TX_MAX || bus_status==1)return false;
    UCB0IE=0;
    UCB0CTLW0=UCSWRST|UCMST|UCMODE_3|UCSYNC|UCSSEL__SMCLK|UCTR;
    UCB0CTLW1=UCASTP_2; /* Hardware STOP after the exact transmitted byte count. */
    UCB0BRW=16; /* Nominal 1.048576 MHz / 16 = 65.536 kHz, below 400 kHz max. */
    UCB0I2CSA=OLED_ADDRESS;UCB0TBCNT=length;
    tx_length=length;tx_position=0;
    for(unsigned i=0;i<length;i++)tx[i]=data[i];
    P5SEL0|=OLED_BUS_PINS;
    UCB0CTLW0&=~UCSWRST;
    if((P5IN&OLED_BUS_PINS)!=OLED_BUS_PINS || (UCB0STATW&UCBBUSY)) {
        bus_abort();return false;
    }
    UCB0IFG=0;bus_started=now;bus_status=1;
    UCB0IE=UCTXIE0|UCSTPIE|UCNACKIE|UCALIE;
    UCB0CTLW0|=UCTXSTT;
    return true;
}
static OledBusResult bus_poll(uint32_t now) {
    uint8_t status=bus_status;
    if(status==2){bus_abort();return OLED_BUS_OK;}
    if(status==3 || status==0 || (uint32_t)(now-bus_started)>=OLED_BUS_TIMEOUT_MS) {
        bus_abort();return OLED_BUS_ERROR;
    }
    return OLED_BUS_BUSY;
}
static uint32_t now(void);
static const OledHal hal={power,reset,bus_start,bus_poll,bus_abort,now};
void __attribute__((interrupt(USCI_B0_VECTOR))) i2c_isr(void) {
    switch(UCB0IV) {
    case USCI_I2C_UCALIFG:
    case USCI_I2C_UCNACKIFG:
        UCB0IE=0;UCB0CTLW0|=UCSWRST;bus_status=3;
        __bic_SR_register_on_exit(LPM4_bits);break;
    case USCI_I2C_UCSTPIFG:
        UCB0IE=0;bus_status=(tx_position==tx_length)?2:3;
        __bic_SR_register_on_exit(LPM4_bits);break;
    case USCI_I2C_UCTXIFG0:
        if(tx_position<tx_length)UCB0TXBUF=tx[tx_position++];
        else UCB0IE&=~UCTXIE0;
        break;
    default: break;
    }
}
static void tick_start(void) {
    TA0CCR0=32;TA0CCTL0=CCIE;
    TA0CTL=TASSEL__ACLK|MC__UP|TACLR;tick_running=1;
}
static uint32_t now(void) {
    __disable_interrupt();uint32_t t=milliseconds;__enable_interrupt();return t;
}
static void arm_edges(void) {
    P1IES=(P1IES&~BUTTONS)|(P1IN&BUTTONS);
}
void __attribute__((interrupt(PORT1_VECTOR))) port1_isr(void) {
    P1IFG&=~BUTTONS;arm_edges();
    /* Edge samples close the race between an awake timer tick and LPM4 entry;
     * repeated timer samples still establish the full debounce interval. */
    input_push(&inputs,(uint8_t)(~P1IN&BUTTONS),milliseconds);
    if(!tick_running)tick_start();
    __bic_SR_register_on_exit(LPM4_bits);
}
void __attribute__((interrupt(TIMER0_A0_VECTOR))) timer0_isr(void) {
    ++milliseconds;fraction+=232U;
    if(fraction>=32768U){fraction-=32768U;++milliseconds;}
    input_push(&inputs,(uint8_t)(~P1IN&BUTTONS),milliseconds);
    __bic_SR_register_on_exit(LPM4_bits);
}
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

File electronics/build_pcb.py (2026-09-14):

"""Generate the Rev Q1 quote prototype. Run with KiCad 10's pcbnew Python.
Not a release to fabricate; qualification requirements accompany the RFQ.
Coordinates: board top view, mm, origin at upper-left of 42 x 40 outline.
"""
import pcbnew as p
from pathlib import Path
import json, csv, os

ROOT=Path(__file__).resolve().parents[1]
OUT=ROOT/'electronics'
LIB=Path(os.environ.get('KICAD_FP_ROOT',str(ROOT.parent/'tooling/squashfs-root/share/kicad/footprints')))
b=p.BOARD(); b.SetCopperLayerCount(4)
ds=b.GetDesignSettings(); ds.SetBoardThickness(p.FromMM(1.0))
ds.m_MinClearance=p.FromMM(.127); ds.m_TrackMinWidth=p.FromMM(.127)
ds.m_ViasMinSize=p.FromMM(.55); ds.m_MinThroughDrill=p.FromMM(.30)
ds.m_CopperEdgeClearance=p.FromMM(.30)
ds.m_HoleClearance=p.FromMM(.15)
nc=b.GetDesignSettings().m_NetSettings.GetDefaultNetclass()
nc.SetClearance(p.FromMM(.15));nc.SetTrackWidth(p.FromMM(.15));nc.SetViaDiameter(p.FromMM(.6));nc.SetViaDrill(p.FromMM(.3))
nets={}; parts=[]; keepers=[]
def v(x,y):return p.VECTOR2I(p.FromMM(x),p.FromMM(y))
def net(n):
    if n not in nets:
        ni=p.NETINFO_ITEM(b,n);b.Add(ni);nets[n]=ni
    return nets[n]
def add(ref,value,mpn,mfr,fp,x,y,rot=0,side='top',pins=None,notes=''):
    adjust={'R1':(29.5,18.5,0),'R2':(31.5,20.2,0),'D1':(37.3,20.7,0),'R4':(39,6.5,0),'R19':(39,12.5,0),'C13':(39,15,0),'R6':(26.5,18.5,0),
      'R9':(12.3,12,90),'R10':(12.6,5.2,90),'R11':(11.5,18.5,0),
      'R12':(14.8,18.5,0),'R13':(18.1,18.5,0),'R14':(21,5.3,90),
      'R15':(21,9.7,90),'Q3':(22,19,0),'C1':(33,4.3,0),'C2':(29,4.3,0),
      'C7':(25,4.3,0),'C9':(17,4.3,0),'C5':(29.5,10.2,90),'C8':(15.5,11.3,0),
      'R17':(5.5,33.5,90),'C11':(8,34.5,90),'R18':(36.5,33.5,90),'C12':(34,33.5,90)}
    if ref in adjust:x,y,rot=adjust[ref]
    lib,name=fp.split(':'); f=p.FootprintLoad(str(LIB/(lib+'.pretty')),name)
    if not f:raise ValueError(fp)
    keepers.append(f)
    f.SetReference(ref);f.SetValue(value);b.Add(f)
    if side=='bottom': f.Flip(v(0,0),False)
    f.SetPosition(v(x,y)); f.SetOrientationDegrees(rot)
    f.Reference().SetVisible(False);f.Value().SetVisible(False)
    for g in list(f.GraphicalItems()):
        # Manufacturing reference drawing is supplied separately; avoid unreadable
        # sub-millimeter silk under the glass and on the dense reverse side.
        if g.GetLayer() in (p.F_SilkS,p.B_SilkS):
            f.Remove(g); keepers.append(g)
    pins={str(k):n for k,n in (pins or {}).items()}
    for pad in f.Pads():
        if pad.GetNumber() in pins:pad.SetNet(net(pins[pad.GetNumber()]))
    present={z.GetNumber() for z in f.Pads()}
    assert set(pins)<=present,(ref,set(pins)-present)
    parts.append(dict(ref=ref,value=value,mpn=mpn,manufacturer=mfr,footprint=fp,x=x,y=y,rotation=rot,side=side,pins=pins,notes=notes))
    return f
def line(x1,y1,x2,y2,layer=p.Edge_Cuts,width=.05):
    a=p.PCB_SHAPE();a.SetShape(p.SHAPE_T_SEGMENT);a.SetStart(v(x1,y1));a.SetEnd(v(x2,y2));a.SetLayer(layer);a.SetWidth(p.FromMM(width));b.Add(a)
def arc(x1,y1,xm,ym,x2,y2):
    a=p.PCB_SHAPE();a.SetShape(p.SHAPE_T_ARC);a.SetArcGeometry(v(x1,y1),v(xm,ym),v(x2,y2));a.SetLayer(p.Edge_Cuts);a.SetWidth(p.FromMM(.05));b.Add(a)
line(2,0,40,0);arc(40,0,41.414214,.585786,42,2)
line(42,2,42,38);arc(42,38,41.414214,39.414214,40,40)
line(40,40,2,40);arc(2,40,.585786,39.414214,0,38)
line(0,38,0,2);arc(0,2,.585786,.585786,2,0)

# User interface. Manufacturer DE188 Rev4 pin numbering viewed from display front.
f=p.FOOTPRINT(b);f.SetReference('DS1');f.SetFPID(p.LIB_ID('ClickCounter','DE188_20P_34.9x13mm'));f.SetValue('DE188-RU-30/7,5/V(3V)');f.SetAttributes(p.FP_THROUGH_HOLE);b.Add(f);f.SetPosition(v(21,8.75))
f.Reference().SetVisible(False);f.Value().SetVisible(False)
lcdpins={20:'COM0',1:'COM1',11:'COM2',10:'COM3'}
lcdpins.update({pin:'SEG'+str(i) for i,pin in enumerate(list(range(2,10))+list(range(12,20)))})
for i in range(10):
    for num,yy in [(i+1,6.75),(20-i,-6.75)]:
        pad=p.PAD(f);pad.SetNumber(str(num));pad.SetAttribute(p.PAD_ATTRIB_PTH);pad.SetShape(p.PAD_SHAPE_CIRCLE)
        pad.SetSize(v(2.2,2.2));pad.SetDrillSize(v(1.7,1.7));pad.SetLayerSet(p.LSET.AllCuMask());pad.SetLayerSet(p.PAD.PTHMask())
        pad.SetPosition(v(21-11.43+i*2.54,8.75+yy));pad.SetNet(net(lcdpins[num]));f.Add(pad)
parts.append(dict(ref='DS1',value=f.GetValue(),mpn='DE188-RU-30/7,5/V(3V)',manufacturer='Display Elektronik',footprint='ClickCounter:DE188_20P_34.9x13mm',x=21,y=8.75,rotation=0,side='top',pins={str(k):n for k,n in lcdpins.items()},notes='THT hand solder; glass rear 4.0 mm above PCB top; 260 C / 5 s maximum; quote-only display, sample qualification required'))
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

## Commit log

2026-09-14 Import full Count Fidget Q1 design, specifications, vendor findings and local-session handoff
    [BOM-PCBA-Q1.csv, BOM-Q1.csv, OFFBOARD-items-Q1.csv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]
2026-09-15 Allow cleanup of previous-project PCBWay cart entries
2026-09-15 Record PCBWay submission and JLCPCB sourcing results
    [BOM-JLCPCB-Q1.csv]
2026-09-15 Audit Q1 hardware and add reproducible 32 Hz LCD candidate
2026-09-15 Build and verify the coordinated Q2 engineering quote candidate
    [BOM-JLCPCB-Q2.csv, BOM-PCBA-Q2.csv, BOM-Q2.csv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]
2026-09-23 Add two-layer Q3 OLED candidate and adversarial review evidence
    [BOM-JLCPCB-Q3-minimal.csv, BOM-JLCPCB-Q3.csv, BOM-PCBA-Q3.csv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]
2026-09-23 Compare stocked USB-programmable MCU options and record circuit-model limits
2026-09-25 Implement Q4 USB-programmable STM32 counter and reviewed two-layer design
    [BOM-JLCPCB-Q4.csv, BOM-PCBA-Q4.csv, BOM-Q4.csv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]
2026-09-25 Add Q4 firmware emulation, energy model and dated simulation review
    Adds an instruction-level emulator that runs the committed Q4 ELF on a
    Cortex-M0+ core with modelled RCC/PWR/FLASH/GPIO/EXTI/SysTick/NVIC/SPI/ADC
    and board devices (FM25V02A, SSD1315 module behind TPS22917, keys, NRST,
    BOOT0). A scenario suite asserts the documented product behaviour and an
    energy model combines emulated state timelines with datasheet currents.
    Findings are recorded in docs/REVIEW-Q4-simulation-2026-09-25.md and
    filed as issues #2-#9. The committed image fails 9 scenario expectations,
    all from one defect (#2): the boot-time journal scan overflows the
    255-sample input queue, so every reset latches ERR. Nothi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
    [energy.py, q4emu.py, scenarios.py]
2026-09-25 Model key-controlled power-off and record power/BOM follow-up
    Extend energy.py with three idle options (as built, 3.3 V nano-IQ LDO,
    key-latched U7 power-off per #12), regulator current during awake
    windows, boot-from-off overhead and worst-case LIR2032 self-discharge.
    Record the owner's power-switch, battery-life and JLC-inventory questions
    in the dated review with links to #5, #12 and #13.
    Claude-Session: https://claude.ai/code/session_01UrkzLMrBi6iLPSL5SbMCA7
2026-09-25 Add Q5 revision: soft power key, coin-cell holder, battery gauge, hold-to-reset
    Q5 is a coordinated revision of the frozen Q4 candidate that resolves
    issues #2-#9, #12 and #13 from the Q4 simulation review. Q1-Q4 files are
    unchanged.
    Electronics (electronics/q5):
    - COUNT key doubles as a soft power key: U7 ON is driven by the key (D3),
    PB2 PWR_HOLD (D3) or VBUS (D4). Everything below SYS is off when idle
    (~8 uA). C28/C29 reduced to 4.7 nF.
    - LIR2032 in a vendor-soldered BT1 holder with an onboard TH1 NTC
    replaces the J2 pack harness. U5 moves to TLV7012DDFR (stock).
    - SYS_LOAD/2 battery sense on PA4 and BQ25185 STAT1/STAT2 on PA5/PA6.
    - U6 QOD left unconnected (SSD1315 power-down rule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
    [BOM-JLCPCB-Q5.csv, BOM-PCBA-Q5.csv, BOM-Q5.csv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]
2026-09-25 Add macOS DFU flasher, flash-clickers skill and Q5 first-article test plan
    tools/clicker-flash/clicker_flash.py (stdlib Python + dfu-util) verifies
    the Q5 image against the build manifest, flashes over the STM32 ROM DFU,
    verifies by read-back, starts the application and logs each unit.
    It has been tested against a mock DfuSe device (15 cases) and checked
    against the real dfu-util 0.11 argument syntax. It has not been run
    against physical hardware.
    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
2026-09-25 Fix review findings in Q5 firmware and extend the emulator to catch them
    Firmware (independent adversarial review):
    - ADC: set LFMEN (RM0376, mandatory below 3.5 MHz ADC clock), enable the
    VREFINT ADC buffer and wait for VREFINT_RDYF before calibrating.
    - Latch: PB2 is held while the app is awake and re-latched on wake only if a
    key is pressed, so releasing a COUNT key held through the power-off timeout
    switches the board off instead of re-latching; key releases are no longer
    activity.
    - Boot: key edges are captured sparsely during the journal scan and the
    counter is seeded with the setup-time key level, so presses made while
    storage loads are counted (previously silently lost).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
    [main_stm32.c, q5emu.py, scenarios.py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]
2026-09-25 WIP design lock: hot-swap sockets, latch R38/C40, BT1 polarity marks, 1.6 mm board, enclosure/export/stock updates
    Work in progress. The model, footprints and scripts are updated. The board is
    not rebuilt, routed or re-verified yet, so the saved native evidence and
    exports are stale until the design-lock rebuild lands.
    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
2026-09-25 Correct Q5 power bounds per review: OCD over temperature, tOCDD duration argument, R38/C40 ON-node levels and timing
    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
2026-09-25 WIP: Q5 design-lock routing iteration snapshot (not verified)
    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
    [click-counter-Q5.kicad_pcb, click-counter-Q5.kicad_sch, mcu-4.kicad_sch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]
2026-09-25 Q5 design lock (electronics): hot-swap sockets, latch filter, 1.6 mm, clean native verification
    Independent hardware/DFM and mechanical review follow-up:
    - SW1/SW2 are now vendor-SMT Kailh-type MX hot-swap sockets (CPG151101S11-16,
    C41430893, rotated outward). The clicky switches clip into the printed
    plate and press in, so JLC can solder every part (variant B) and no switch
    soldering is needed in either variant. The board is 1.6 mm (MX pin length).
    - R38 100k series + C40 4.7nF on U7 ON: VBUS hot-plug filter below the 6 V
    abs max and a contact-bounce bridge.
    - BT1: +/- polarity silkscreen outside the holder body and paste kept off
    the inboard land; J1 slot rings 0.25 mm; silkscree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
    [BOM-JLCPCB-Q5-FULL-ASSEMBLY.csv, BOM-PCBA-Q5.csv, BOM-Q5.csv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]
2026-09-25 WIP: enclosure outputs in progress
    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
2026-09-25 Q5 design lock (mechanics): 1.6 mm stack, hot-swap plate, M2x6 self-tapping screws, drawing-based keycaps
    Five valid manifold printed parts, zero static or assembly-path collisions
    (162 poses). The keycap datum comes from the switch drawing (pressed skirt
    0.6 mm above the plate, roof 0.65 mm above the housing). Lid bosses clamp
    the PCB with the heads seated low, and base bosses are 4.4 mm with 1.7 mm
    pilots (3.4 mm thread engagement). USB rib is clear of J1's joints; pinhole
    guide tube; 23.6 x 12.8 mm aperture; debossed LIR2032 warning.
    Body 47.2 x 59.2 x 16.8 mm.
    Claude-Session: https://claude.ai/code/session_01UrkzLMrBi6iLPSL5SbMCA7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
    [BOM-Q5.csv, LOOSE-PARTS-Q5.csv, base-Q5.stl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]
2026-09-25 Q5 design lock: JLC Basic substitutions, re-verified board, cost estimator
    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
    [BOM-JLCPCB-Q5-FULL-ASSEMBLY.csv, BOM-JLCPCB-Q5.csv, BOM-PCBA-Q5.csv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]
2026-09-25 Record JLCPCB quote and A/B estimate, tolerance coupon, design-lock docs
    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
    [tolerance-coupon-Q5.stl]
2026-09-25 Rebuild Q5 enclosure and rerun corruption tests and power checks on the locked design
    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
2026-09-25 Add observed 5-board JLC PCB price and 5-board A/B estimate
    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
2026-09-26 Add Q5 footprint check against JLC/EasyEDA footprints and predicted preview corrections
    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
    [corrections.csv, results.csv]
2026-09-26 Estimate 2-board order; record the variant B decision rule
    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
2026-09-26 First-order de-risking: U5 supply filter, 10 nF latch cap, JLC-corrected CPLs, DFU unplug rule
    Three independent checks (datasheet pinouts, JLC EasyEDA footprints, dead-on-arrival
    review) found no pinout, footprint or DOA defect. Changes from their findings:
    R39 1k + C9 filter U5's 6 V abs-max supply from VBUS hot-plug ringing; C40 10 nF
    (min latch press 10.5 ms typ); JLC-corrected CPL files and a preview checklist;
    flasher warns to reset a unit left in DFU before unplugging. Board re-routed:
    DRC/ERC/parity zero, no via-to-land gaps; emulator 0 failures; stock 43/43.
    Claude-Session: https://claude.ai/code/session_01UrkzLMrBi6iLPSL5SbMC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
    [BOM-JLCPCB-Q5-FULL-ASSEMBLY.csv, BOM-JLCPCB-Q5.csv, BOM-PCBA-Q5.csv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]
2026-09-26 Move nine part types to JLC Basic; 16 Extended types remain, each justified
    R4 18k (16.7 mA charge), temperature window 56k/82k/18k/12k (7.26-35.83 C),
    R32 75 ohm, Q1/Q2 AO3400A, 2.2 uF and 10 uF 50 V 0805 capacitors. Fresh
    ERC/DRC/parity on unchanged routing, stock 42/42, exports, JLC footprint
    fit and pin names, power/latch checks re-run. About $28 less per order.
    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
    [BOM-JLCPCB-Q5-FULL-ASSEMBLY.csv, BOM-JLCPCB-Q5.csv, BOM-PCBA-Q5.csv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]
2026-09-26 Rebuild Q5 enclosure against the final first-order board
    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
2026-09-26 Re-run verifier corruption tests on the final board: 42/42 rejected
    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
